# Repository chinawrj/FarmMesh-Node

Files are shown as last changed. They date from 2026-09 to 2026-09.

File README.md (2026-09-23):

# FarmMesh Node

**An integrated hardware and software solution for farm-wide Mesh networking**

English | [简体中文](README.zh-CN.md)

[Overview](#overview) · [Solution scope](#solution-scope-and-current-progress) · [A1 hardware](#a1-hardware-prototype) · [Features & targets](#key-features-and-performance-targets) · [Architecture](#architecture) · [Internal interface](#candidate-internal-interface) · [Wireless research](#wireless-research-status) · [Open decisions](#open-decisions) · [Roadmap](#roadmap) · [Contact](#contact-and-participation) · [References](#references)

## Overview

**FarmMesh Node is a hardware and software project for a complete farm wireless networking solution.** Its scope includes node electronics, embedded firmware, communication protocols, Mesh networking, client and sensor access, and system integration and field validation. Hardware and software are developed together toward the same farm-wide service goals; the A1 PCB is the current hardware milestone within that larger project.

FarmMesh Node aims to provide **farm-wide coverage using solar-powered infrastructure nodes that need no pre-installed power or network cabling**, combining on-demand high-speed client access with distributed access for hundreds to approximately 1,000 low-traffic sensors. Inter-node links are intended to be entirely wireless. Solar supply, storage and node power budgets remain to be designed; this is not a claim of all-weather energy autonomy, and a gateway/uplink may still be needed.

The client-access design target is **50 Mbps of effective throughput after connecting to a Mesh node**, available on demand wherever needed in the farm. The initial capacity assumption is **1–2 concurrent high-speed clients across the whole farm**, not per infrastructure node and not a limit on the number of Mesh nodes or total clients. This does not require every location to receive 50 Mbps simultaneously. Measurement endpoints, direction and test conditions remain TBD; there is no guarantee of 50 Mbps across multiple Mesh hops or to the Internet.

Infrastructure nodes are intended to provide **concurrent BLE or Wi-Fi access for several hundred to approximately 1,000 low-traffic, low-power sensors across the whole farm**, distributed among multiple Mesh nodes. This is an aggregate planning target requiring capacity validation, not 1,000 direct BLE connections per node or simultaneous packet transmission by every sensor. End-device energy requirements and the infrastructure's solar-power budget are separate concerns; neither implies that the forwarding infrastructure must sleep. Low Wi-Fi traffic alone does not establish low power consumption, and BLE/Wi-Fi coexistence requires validation.

Each infrastructure node contains **one RP2350B and three ESP32-C5 chips**, implemented in A1 with three official **ESP32-C5-WROOM-1U-N8R8 modules**. The RP2350B is intended to aggregate and forward data inside the node, with an independent internal link to each C5. The separate preliminary **50 Mbps per internal link** target is a hardware design input, not a demonstrated user throughput figure or proof that the access-service target can be met. Its directional and raw-rate/payload-rate definitions remain TBD.

Development is staged from the node hardware foundation through firmware and network software to full-system validation. The **A1 prototype has eight schematic sheets, a four-layer PCB and a manufacturing package released for controlled engineering prototypes**; its release record is [RELEASE.md](hardware/rev-a/RELEASE.md). Firmware and network software implementation remain pending. Coverage, user throughput, terminal capacity, power consumption and sustained internal-link performance have not been measured.

## Solution scope and current progress

| Area | Role in the complete solution | Current progress |
| --- | --- | --- |
| Node hardware | RP2350B and three ESP32-C5 modules, power, PCB, antennas and physical interfaces | A1 design and reviewed manufacturing package available; assembly and bring-up pending; deployment solar power remains to be designed |
| Embedded firmware | RP2350 PIO/DMA and C5 PARLIO drivers, framing, buffering, flow control and coordination across the three links | Hardware pin assignments frozen for A1; firmware and interface timing validation pending |
| Network software | Inter-node wireless transport, Mesh protocol and routing, Wi-Fi/BLE client and sensor access, configuration and diagnostics | Requirements and wireless research recorded; protocol selection and implementation pending |
| System integration | Hardware/firmware/network integration, power and RF coexistence, throughput, sensor capacity and farm deployment | Staged first-board test plan available; multi-node and field validation planned |

This repository currently contains the hardware release, system requirements and wireless research. Software will be developed as part of the same project; the table distinguishes the intended solution from what is already implemented.

## A1 hardware prototype

A1 contains a 100 × 100 mm four-layer PCB, protected single-cell nominal 3.7 V Li-ion input, 3.3 V buck-boost supply, RP2350B, three C5 modules, independent parallel interfaces, UART download headers and RP USB/SWD. USB data disconnects in hardware when VBUS is absent, including ROM BOOTSEL operation. USB does not power or charge the board. Solar charging and storage sizing remain separate design work.

| Artifact | Use and status |
| --- | --- |
| [Release status](hardware/rev-a/RELEASE.md) | Authoritative prototype fabrication gate and validation boundaries |
| [Manufacturing ZIP](hardware/rev-a/FarmMesh-Node-A1-manufacturing.zip) / [SHA-256](hardware/rev-a/FarmMesh-Node-A1-manufacturing.zip.sha256) | Released for controlled A1 prototypes: Gerber, drills, BOM, placements, drawings, editable source and review evidence |
| [KiCad project](hardware/rev-a/FarmMesh-Node.kicad_pro) / [PCB](hardware/rev-a/FarmMesh-Node.kicad_pcb) | Editable native sources; download the repository together with project-local libraries |
| [Eight-page schematic PDF](hardware/rev-a/review/FarmMesh-Node-A1.pdf) | A1 circuit review copy |
| [Manufacturing instructions](hardware/rev-a/FABRICATION.md) / [parts selection](hardware/rev-a/parts-selection.json) | Stackup, assembly requirements, 153 selected assembly parts and accessories |
| [First-board test plan](hardware/rev-a/FIRST-BOARD-TEST.md) | Staged power, debug, USB, thermal, load and RF checks; results are not yet measured |
| [Design notes](hardware/rev-a/DESIGN-NOTES.md) | Circuit and layout choices, sources and reproducibility |
| [Power review](hardware/rev-a/reports/a1-power-review.md) / [RF and digital review](hardware/rev-a/reports/a1-rf-digital-review.md) / [DFM and BOM review](hardware/rev-a/reports/a1-dfm-bom-review.md) | Independent engineering review records, with remaining bench-validation boundaries |

The C5 modules use external dual-band antennas. Their native USB pins are allocated to PARLIO; each C5 retains UART download and logging. **No wireless transport or Mesh protocol is selected by the hardware.** A fabrication-ready package does not establish RF, power or throughput performance.

## Key features and performance targets

**Targets below are planned requirements, not measured results.** TBD means to be determined. Chip resource facts and candidate allocations are identified separately.

| Item | Target or configuration | Status and boundaries |
| --- | --- | --- |
| Solar power and deployment | Solar-capable infrastructure nodes; no pre-installed power or network cables; wireless inter-node links | Design goal; solar sizing, storage and node power budget TBD; energy autonomy unverified; gateway/uplink architecture open |
| Farm-wide coverage | Wireless access throughout the farm | Product goal; area, terrain, range, node count and placement TBD |
| On-demand high-speed access | 50 Mbps effective client-access throughput after connecting to a Mesh node | Design goal; measurement endpoints, direction and conditions TBD; no multi-hop or Internet throughput guarantee |
| High-speed client concurrency | Initially 1–2 across the whole farm | Capacity assumption, unverified; not per Mesh node, a Mesh-node count limit or a total-client limit |
| Concurrent low-traffic access | Several hundred to approximately 1,000 sensors across the farm via BLE or Wi-Fi | Aggregate planning target, distributed across nodes; capacity has an upper bound and needs validation; not per-node BLE sessions or simultaneous packets from all sensors |
| Per-node BLE capacity | Bounded by C5 controller, host stack/configuration and radio scheduling | Connection-based versus advertising/scanning mode TBD; role and per-node limits unconfirmed; three C5 capacities cannot simply be added into a guarantee |
| End-device energy use | Support low-power terminal operation | Product goal; activity duty cycle, power budget and battery-life target TBD; solar infrastructure budget separately TBD |
| Node composition | 1 × RP2350B + 3 × ESP32-C5-WROOM-1U-N8R8 | Selected A1 architecture; physical validation pending |
| A1 hardware artifacts | Eight-sheet KiCad schematic, four-layer PCB and selected BOM; nominal 3.7 V single-cell Li-ion input | Fabrication gate in RELEASE.md; solar charging, firmware and physical validation remain separate |
| Independent internal links | Preliminary target: 50 Mbps per C5–RP2350 link, not shared across three links | Internal-interface target; direction, raw versus payload rate and required margin for the user-service target TBD; unverified |
| Internal interface | PARLIO ↔ PIO, separate 4-bit TX/RX buses; both clocks supplied by C5 | Candidate; 12 signals per link; A1 pin assignment drawn and reviewed; programs and timing unverified |
| RP2350B resources | 48 Bank0 GPIOs; 3 PIO blocks / 12 state machines; 32 shared instructions per block; 16 system DMA channels | Chip resource facts; preliminary interface allocation below is not implementation proof |
| Wireless roles and interconnection | Three C5 chips per node; Mesh protocol, radio roles/channels and gateway/uplink TBD | Architecture decisions pending; no guaranteed BLE/Wi-Fi coexistence performance or Internet throughput |

## Architecture

### Network concept

The diagram separates end-device access from the Mesh infrastructure. Dotted lines show intended service relationships and node membership, not physical radio links or packet paths. The service box is a logical grouping, not a central device. Inter-node topology, radio roles and Mesh protocol remain open; the measurement endpoint and gateway/uplink boundary are also TBD.

```mermaid
flowchart TB
    fast["High-speed clients / 高速客户端<br/>50 Mbps access target / 接入目标<br/>1–2 concurrent farm-wide / 全网并发目标"]
    low["Low-traffic sensors / 低流量传感器<br/>Hundreds to approx. 1,000 farm-wide / 全网数百至约千个<br/>Concurrent access goal / 并发接入目标"]
    mesh["FarmMesh infrastructure services / 基础设施服务层<br/>Logical grouping / 逻辑分组"]
    fast -.- mesh
    low -.-|"BLE or Wi-Fi / 计划接入"| mesh
    subgraph infra["Solar-capable Mesh nodes / 太阳能 Mesh 节点目标"]
        a["FarmMesh Node A"]
        b["FarmMesh Node B"]
        c["FarmMesh Node C"]
    end
    mesh -.- a
    mesh -.- b
    mesh -.- c
    deployment["No pre-installed power or network cables / 免预布电源线或网线<br/>Wireless inter-node links / 节点间纯无线目标"]
    deployment -.- mesh
    boundary["Measurement endpoint and gateway/uplink / 测速端点与网关或上联<br/>TBD / 待定"]
    mesh -.- boundary
```

### Inside one node

Each line represents an independent internal data link. Clock and VALID directions are defined separately in the interface table below; the arrows here do not specify clock sources.

```mermaid
flowchart LR
    subgraph node["One FarmMesh Node / 单个节点"]
        rp["RP2350B · PIO + system DMA<br/>Data aggregation and forwarding / 数据汇聚与转发"]
        ca["ESP32-C5 A · PARLIO"]
        cb["ESP32-C5 B · PARLIO"]
        cc["ESP32-C5 C · PARLIO"]
        rp <-->|"Link A / 链路 A"| ca
        rp <-->|"Link B / 链路 B"| cb
        rp <-->|"Link C / 链路 C"| cc
    end
```

The three ESP32-C5 chips' wireless roles, channels and connections to other nodes are not assigned by this diagram.

### Wireless coexistence boundary

Espressif documents shared RF resources with time-division and priority arbitration. Its current C5 coexistence table marks Wi-Fi SoftAP Connecting/Connected combined with BLE Scan/Advertising/Connected as C1 (supported, with unstable performance). This is a constraint to validate if a C5 is assigned both Wi-Fi AP and BLE roles; it does not establish that the three-chip node cannot meet its goals. Radio-role allocation and coexistence must be checked against the selected SDK and operating scenarios. Concurrent terminal service does not imply independent, simultaneous full-load radios on a single C5. See the [official RF coexistence guide](https://docs.espressif.com/projects/esp-idf/en/stable/esp32c5/api-guides/coexist.html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).

Per-node BLE capacity has an implementation-dependent limit, not one universal fixed connection count imposed by the BLE specification. The C5 controller and NimBLE host expose separate connection-limit settings in the [official configuration reference](https://docs.espressif.com/projects/esp-idf/en/stable/esp32c5/api-reference/kconfig-reference.html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). Connection-based access and connectionless advertising/scanning are different [BLE roles and topologies](https://docs.espressif.com/projects/esp-idf/en/stable/esp32c5/api-guides/ble/get-started/ble-introduction.html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); scanning advertisements must not be counted as persistent connections. Advertising/scanning terminal capacity needs its own validation. Select the access mode and three C5 roles before confirming per-node capacity; simply adding three chip-level limits does not establish node capacity.

## Candidate internal interface

The selected hardware interface is **ESP32-C5 PARLIO ↔ RP2350 PIO**, using separate 4-bit TX and RX data buses. A1 freezes the physical connections; firmware and timing for concurrent bidirectional operation remain unvalidated.

**Each C5 supplies both clocks. The RP2350 PIO follows an external clock in both directions**, including when the RP2350 sends data to the C5.

| Transfer direction | DATA | Clock | VALID |
| --- | --- | --- | --- |
| C5 → RP2350 | 4 signals, C5 → RP | C5 TX CLK → RP | C5 TX VALID → RP |
| RP2350 → C5 | 4 signals, RP → C5 | C5 RX CLK → RP | RP VALID → C5 |

This uses **12 signals per link**: 8 DATA, 2 CLK and 2 VALID. Three links use **36 signals**, plus a common ground reference. A1 freezes the prototype pin assignment in the schematics and [C5 pinmap](hardware/rev-a/c5-pinmap.json); firmware and hardware timing validation remain open.

PARLIO has separate TX and RX units. A shared-data, half-duplex alternative would require explicit output-enable, tri-state and direction-change handling. PARLIO must not be treated as an automatically reversing shared bus, and disabling TX does not by itself establish a high-impedance output.

### Preliminary resource budget

| RP2350B resource | Available | Initial three-link estimate |
| --- | --- | --- |
| Bank0 GPIO, QFN80 package | 48 | 36 interface signals; 12 remain before other allocations |
| PIO state machines | 12 across 3 PIO blocks | 6: one RX and one TX per link |
| System DMA channels | 16 | 6: one per direction per link |
| PIO instruction memory | 32 shared instructions per PIO block | Program size not yet established |

These estimates do not constitute an implemented PIO program or validated timing design. A1 assigns the three interfaces to RP2350B GPIO0–35. Each PIO has a 32-GPIO window selected by GPIOBASE 0 or 16; the PIO configuration and instruction use still need implementation checks. Dedicated QSPI storage pins, USB and SWD do not consume the 48 Bank0 GPIOs. Other board functions use part of the remaining GPIO budget. The 30-GPIO RP2350A cannot accommodate this 36-signal candidate.

### Processing responsibilities and timing boundary

- **CPU:** initialization, buffer preparation, transaction coordination and exception handling.
- **PIO:** beat-level sampling and output timing under the C5-provided clocks.
- **System DMA:** block transfers between PIO FIFOs and RP2350 SRAM, intended to avoid CPU byte-by-byte copying.

The C5 PARLIO RX documentation describes receive-clock output and VALID-based reception gating. C5 RX/GDMA transactions must be prepared before data arrives; VALID alone does not create a receive transaction. The RP must prepare the first beat and drive VALID correctly. Start/end behavior, sampling edges and gating timing still require a concrete design and validation.

Frame boundaries, DMA rearming and sustained operation also remain to be designed. A ring-address setting alone is not a guarantee of indefinite operation, and this draft does not claim CPU-free transfer management.

## Wireless research status

The [wireless link research notes](docs/wireless-link-research.md) record the **2026-09-22** review, official sources, version-specific binary observations and MTU/MSS constraints. **No wireless transport has been selected.** The client-access targets and internal hardware candidate above remain unchanged.

| Topic | Current finding | Status and boundary |
| --- | --- | --- |
| WDS / four-address bridge | Direct public C5 support not confirmed in the reviewed documentation/API | Does not establish a hardware impossibility |
| ESP-NOW and public raw TX | Different frame/payload limits; neither establishes this project's 50 Mbps effective throughput | Research candidates; no sustained-throughput validation |
| Rate and power controls | Public per-peer ESP-NOW rate configuration and per-C5 Wi-Fi maximum-power ceiling | Documented controls; no confirmed ready-to-enable ESP-NOW automatic-rate tool; custom adaptation remains future work |
| AP+STA + proxy ARP | Currently not pursued | Project direction, not a technical impossibility finding |

## Open decisions

1. Define the client-to-Mesh-node 50 Mbps access test: measurement endpoints, uplink/downlink direction and conditions. Start with 1–2 concurrent high-speed clients farm-wide; multi-hop and Internet throughput remain outside any established guarantee.
2. Define each internal link's 50 Mbps target separately: one direction, both directions combined, or each direction; raw rate versus effective payload rate; and the capacity margin needed to support the user-service goal.
3. Establish three-link PIO feasibility, clock/timing constraints, GPIO mapping, instruction budget and required CPU participation. Define first-beat readiness, VALID behavior, receive-transaction preparation, frame boundaries and DMA rearming.
4. Validate the farm-wide planning target of several hundred to approximately 1,000 low-traffic sensors. Select connection-based BLE versus advertising/scanning roles, establish per-node limits and define activity duty cycles, traffic, latency and end-device energy targets. Radio roles/channels and BLE/Wi-Fi coexistence remain to be validated.
5. Design the solar supply, storage and infrastructure power budget for deployment without pre-installed power or network cabling. Later, decide Mesh protocol and routing, antennas, coverage area/terrain and deployment, gateway/uplink, environmental protection and the full BOM.

These decisions guide the complete hardware and software solution. The current repository establishes the A1 hardware foundation and records the software design inputs; firmware, network protocols, routing and system optimization are the next development stages.

## Roadmap

| Phase | Scope | Status |
| --- | --- | --- |
| 1 | System requirements and hardware/software architecture | Service targets and A1 hardware allocation recorded; software architecture and protocols remain open |
| 2 | A1 schematics, PCB and manufacturing package | Released for controlled engineering prototypes; see RELEASE.md |
| 3 | Board bring-up, drivers and internal-link firmware | Awaiting assembled boards; firmware and timing validation pending |
| 4 | Network software, Mesh routing and client/sensor services | Planned; integrate with validated node hardware and firmware |
| 5 | Multi-node integration and farm deployment | Planned; validate coverage, throughput, sensor capacity, power and reliability |

## Contact and participation

Interested in FarmMesh Node? Use [GitHub Issues](https://github.com/chinawrj/FarmMesh-Node/issues) to discuss requirements, hardware, firmware, network software, system testing or ways to participate. You can also visit the project owner's [GitHub profile](https://github.com/chinawrj).

## References

Official sources for subsequent design checks:

- [RP2350 datasheet](https://datasheets.raspberrypi.com/rp2350/rp2350-datasheet.pdf) — GPIO, PIO and system DMA resources.
- [ESP32-C5 datasheet](https://documentation.espressif.com/esp32-c5_datasheet_en.html) and [technical reference manual](https://documentation.espressif.com/esp32-c5_technical_reference_manual_en.pdf) — device and peripheral details.
- [ESP32-C5 PARLIO RX driver](https://docs.espressif.com/projects/esp-idf/en/stable/esp32c5/api-reference/peripherals/parlio/parlio_rx.html) — receive clock, VALID and transaction setup.
- [ESP32-C5 PARLIO TX driver](https://docs.espressif.com/projects/esp-idf/en/stable/esp32c5/api-reference/peripherals/parlio/parlio_tx.html) — transmit configuration and operation.
- [ESP32-C5 RF coexistence](https://docs.espressif.com/projects/esp-idf/en/stable/esp32c5/api-guides/coexist.html) — supported role combinations and shared RF scheduling constraints.

Differences in maximum full-duplex width descriptions across C5 documentation still need reconciliation. This draft considers only the 4-bit-per-direction candidate and makes no claim about wider full-duplex configurations. The ESP-IDF `stable` links can change; record the selected SDK and document versions when the implementation baseline is set.

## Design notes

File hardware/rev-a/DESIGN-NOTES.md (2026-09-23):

# FarmMesh Node A1 硬件设计说明

日期：2026-09-23。A1 投样放行状态以 [RELEASE.md](RELEASE.md) 为准；尚无实物或性能验证。

The A1 eight-sheet KiCad 10 design and 100 × 100 mm four-layer PCB contain one RP2350B, three official ESP32-C5-WROOM-1U-N8R8 modules, a protected 1S Li-ion input and a 3.3 V buck-boost supply. ERC and static connectivity/pad checks do not establish power, RF or interface performance. The prototype release status is recorded in RELEASE.md. Charging/solar power and application firmware remain future work.

## 打开与文件

使用 KiCad **10.0.5 或兼容的 KiCad 10** 打开 [FarmMesh-Node.kicad_pro](FarmMesh-Node.kicad_pro)，再进入原理图编辑器。需安装 KiCad 标准符号及封装库；项目表使用 `KICAD10_SYMBOL_DIR` / `KICAD10_FOOTPRINT_DIR`，项目自建库通过 `${KIPRJMOD}` 引用。无需插件即可编辑。

| 文件 | 用途 |
| --- | --- |
| [八页 PDF](review/FarmMesh-Node-A1.pdf) | 索引、电源、RP2350B、三页 C5、USB、测试及机械 |
| [BOM.csv](BOM.csv) | 153 个已定料装配元件与 11 个 PCB 特征；下单用 manufacturing/assembly/BOM-assembly.csv |
| [gpio-pinmap.csv](gpio-pinmap.csv) | 全部 36 条链路信号，C5 GPIO/模组焊盘与 RP GPIO/封装焊盘 |
| [ERC](reports/erc.json) | KiCad 原始检查结果 |
| [网表及焊盘核对](reports/connectivity-and-footprints.json) | 实际导出网表与已加载封装的结构检查 |
| [电源审阅](reports/power-review.md)、[RP 审阅](reports/rp2350-review.md)、[C5 审阅](reports/c5-review.md) | 独立检查、官方依据及待验证边界 |

索引页的子图框使用全局网络标签连接，框本身没有层次端口。`TX` / `RX` 始终从 C5 视角命名。五个 PWR_FLAG 只是 ERC 驱动声明，不是物料；164 个板上对象之外另有这五个标记。

## 硬件决策

### 电池与 3.3 V 电源

- J1 接常规 **1S、标称 3.7 V、满充 4.20 V** 的锂离子电池包，pin1 正极、pin2 负极。必须使用带过充/过放/过流保护的电池包，连接器、导线与保护板需支持至少 5 A 峰值。不能接 2S、LiFePO4 或高压锂电池。
- F1 为 5 A Littelfuse 0451005.MRL；Q1 DMP2008UFG-7 实现反接保护，D 面向电池、S 面向负载。KiCad PowerDI3333-8 把物理 D 脚 5–8 及底部铜区合并为 pad5，符号因此也只用 D pad5。保险丝和本板 UVLO 不代替电芯保护。
- LTC3119IFE#PBF 使用官方 TA06 3.3 V / 500 kHz 电路为起点。4.7 µH XAL7070-472MEC，反馈 316 kΩ / 100 kΩ，输出标称 3.307 V。78.7 kΩ + 820 pF 补偿是起始值，附加模组电容后的环路稳定性尚未测量。
- MPPC 接 VCC 关闭该功能，本稿不是 MPPT；PWM/SYNC 接地允许 Burst。VCC 是内部辅助电源，不得直接短接到 3V3；D1 阳极 3V3、阴极 VCC。PGOOD 仅给 RP 检测，不直接拉三颗 C5 的 EN。
- RUN 174 kΩ / 100 kΩ：标称启动约 3.30 V、停止约 3.01 V，受器差和负载压降影响。电压低于启动点的电池可能不能冷启动。J2 短接将 RUN 拉低用于关机；仅触发 UVLO 不能等同于数据表的完整关断电流。
- C7 6SVPE220M 为 Panasonic C6 外形，使用 `CP_Elec_6.3x5.9`。C6 输入选 10SVPC120M（120 µF / 10 V）；各 C5 选 6SVPC100M（100 µF / 6.3 V），封装分别为 6.3 × 5.9 mm 和 5 × 5.9 mm。输出共有 520 µF 聚合物电容，分布电容对启动和环路的影响仍须实测。22 µF MLCC 的官方 25°C 直流偏压典型数据和重放记录见 parts-selection.json，不将典型值当全温最小保证。

| 预算项目 | 当前设计输入 |
| --- | --- |
| 三颗 C5 | 每颗供电能力至少 0.6 A，共 1.8 A；不是宣称连续耗电 0.6 A |
| RP、Flash、外围和余量 | 0.4 A 暂定预算 |
| 3V3 总预算 | 2.2 A；3 A 作为瞬态验证目标，不能当成全输入/温度范围连续额定值 |
| 电池端估计 | 在输入 3.0 V、假设效率 80% 时，2.2 A 输出约需 3.03 A；3 A 输出约需 4.13 A |

效率 80% 是预算假设，尚未测得；此计算未保证低温电池、保险丝、线缆及 Q1 压降后的性能。LTC3119 的开关/电感电流限制不是输出电流保证。电源和电池容量不能据此直接换算太阳能板尺寸或续航。

本版**没有充电器、太阳能输入、电池电量监测或 USB 供电路径**。电池 ADC 原方案已移除，避免 3V3 关闭时仍将电池分压施加到非 FT 的 ADC 脚；后续需要带关断隔离的采样电路。

### RP2350B 最小系统

RP2350B 的 QFN80 + EP81、外置 16 MB W25Q128JVSIQ、12 MHz ABM8-272-T3、USB、SWD、BOOTSEL 与 RESET 均已连接。IOVDD / USB_OTP_VDD / QSPI_IOVDD 等接 3.3 V，DVDD 接核心 1.1 V。

核心使用 **RP 内部 buck**，不是 LDO：VREG_LX 经 3.3 µH 到 CORE_1V1，再接 VREG_FB / DVDD。L101 使用官方 R4-S1 的带方向 Abracon 封装，**pad2=LX，pad1=1V1**；换电感时不能只比较电感量。VREG_AVDD 经 33 Ω、4.7 µF 滤波；核心输出及远端 pad32 各有 4.7 µF，并给各电源脚单独 100 nF。

GPIO0–35 分配三组接口，GPIO36 为 PGOOD，GPIO37（FT pad46）检测 USB VBUS，GPIO38–47 保留。A3/A4 硅片优先；为兼顾 A2 E9 漏电问题，VALID 接收端下拉用 4.7 kΩ，USB 检测下臂用 7.5 kΩ，均小于官方 8.2 kΩ 规避阈值。仍需在选定硅片上实测。

### 三个 ESP32-C5 模组

U201/U301/U401 均选官方 **ESP32-C5-WROOM-1U-N8R8**：8 MB Flash、8 MB PSRAM、外置天线接口。每颗需独立的 2.4/5 GHz 天线及适配 ANT1 的线缆，已选配套 MPN 见 parts-selection.json 的 accessories；默认不用模组 ANT2 pad31。此 1U 型号没有 PCB 天线，不应机械套用 PCB 天线版的 15 mm 天线区规则；仍须规划连接器空间、天线摆放及三射频之间隔离。

每模组 22 µF + 100 nF 近 pad2，100 µF 聚合物电容提供本地储能。EN 采用 10 kΩ / 1 µF，GPIO27 和 GPIO28 各 10 kΩ 上拉；BOOT 将 GPIO28 拉低，RESET 拉低 EN。按住 BOOT、脉冲 RESET 进入 UART 下载。

J201/J301/J401：1 GND，2 C5 TX，3 C5 RX，4 EN，5 BOOT，6 3V3 参考。使用 3.3 V 逻辑的 UART 适配器；pin6 是参考输出，不是另一电源入口。RP SWD J101：1 3V3 参考，2 SWDIO，3 GND，4 SWCLK，5 RUN。

### 候选 PARLIO ↔ PIO

| C5 侧信号 | C5 GPIO（模组 pad） | RP A / B / C GPIO | 驱动端 |
| --- | --- | --- | --- |
| TX_D0..3 | 0(6), 1(7), 13(13), 14(14) | 0–3 / 12–15 / 24–27 | C5 |
| TX_CLK | 4(17) | 4 / 16 / 28 | C5 |
| TX_VALID | 5(16) | 5 / 17 / 29 | C5 |
| RX_D0..3 | 6(8), 8(10), 9(11), 10(12) | 6–9 / 18–21 / 30–33 | RP |
| RX_CLK | 23(21) | 10 / 22 / 34 | **C5** |
| RX_VALID | 24(23) | 11 / 23 / 35 | RP |

所有接口避开启动绑带脚和内部 Flash/PSRAM 脚；C5 GPIO13/14 的 USB 功能被让给数据线，因此三颗 C5 通过 UART 下载。GPIO13/14 启动时可能出现 USB 状态变化，RP 必须保持输入，直到 C5 配置完成且 VALID 生效。

每条信号有初始 22 Ω 串联电阻，布板时放在**驱动端**，不能因它画在 C5 页就一律放在 C5 旁。TX_VALID 的 4.7 kΩ 下拉在 RP 端，RX_VALID 的下拉在 C5 端；任一芯片复位后均需重建收发状态、清理 FIFO / 事务。

PIO0 GPIOBASE=0 负责 A；PIO1 GPIOBASE=0 负责 B；PIO2 GPIOBASE=16 负责 C。C 路 GPIO28/34 在相应窗口中的 WAIT GPIO 索引为 12/18，不能把 34 直接塞入 5 位立即数。每路双向各一个状态机、DMA 共约六路仅是资源估算。PARLIO RX 要预先挂好接收事务，RX clock 输出不代表接收已准备好。实际 PIO 程序、指令预算、采样边沿、首拍时序、DMA 重装、持续全双工以及 50 Mbps 均未验证。

### USB 边界

J102 USB4105-GF-A 只用于 RP 数据；VBUS 不给板供电，也不充电，使用时仍需电池。CC1/CC2 各 5.1 kΩ，D± 经 USBLC6-2SC6、TS3USB30EDGSR 数据开关及靠 RP 的 27 Ω 串联电阻。USBLC6 的 I/O 是 1↔6 与 3↔4 直通对，VBUS 有 100 nF。

VBUS 通过 5.1 kΩ / 7.5 kΩ 接 GPIO37。按 1% 电阻及 4.4–5.5 V VBUS，检测电压约 2.598–3.300 V，低于 FT 脚 IOVDD=0 时的 3.63 V 上限；程序检测前应关闭 GPIO37 内部上下拉。A1 增加 TLV3011BIDBVR（必须 B 版本）与 237 kΩ / 100 kΩ 比较网络，在 VBUS 低于标称约 4.19 V 时将开关 /OE 拉高；10 kΩ 默认上拉使 USB 物理断开，不依赖应用程序或 ROM 读取 GPIO37。容差、失电、欠压及电源先后顺序仍须按首板指南测量；Ioff 规格不代表任意欠压条件。

## 布局与校验

A1 使用 100 × 100 mm、四层 1.6 mm 板；F.Cu / In1.GND / In2.GND / B.Cu。JLC04161H-3313 叠层、USB 90 Ω 主干几何和制造公差见 [FABRICATION.md](FABRICATION.md)。两内层保留为参考地，RP buck 的 LX 下方仅在相邻 In1.Cu 局部避空。三路 C5 电源主干为 1.5 mm，RP 支路为 1.0 mm；局部电源回路、QSPI、晶振和 USB 先行布线，再完成普通信号。

153 个装配元件均有明确 MPN，7 个裸铜测试点及 4 个安装孔为 PCB 特征。三颗 C5、RP 和 LTC 的接地过孔均置于实际 EP 锡膏窗口之外，采用普通 tenting；这不等同于树脂填孔或保证封孔。M3 螺钉头部区域禁布外层铜。

最终 ERC、DRC、未连接、原理图一致性以及逐焊盘几何校验以 reports 中绑定最终文件 SHA 的报告为准。三份 A1 独立审阅分别覆盖电源、RF/数字接口和定料/制造；原 A0 审阅记录仅保留为历史。

[首板验收指南](FIRST-BOARD-TEST.md) 给出分阶段限流上电、3V3/1V1、UVLO、UART/SWD/USB、环路/负载/温升及射频测试。2.2 A 总输出和 3 A 脉冲是验证目标，50 Mbps 板内链路、用户吞吐与无线共存尚未测得。投样文件通过静态检查不能代替这些实测。

## 重生成与来源

原理图可直接在 KiCad 编辑。`scripts/build_design.py` 是本稿生成源，**重新运行会覆盖全部原理图与项目自建符号库**；先保存手工改图，或将变更回写生成器。依赖 Python 3 和 `sexpdata`，通过环境变量 `KICAD_SHARE` 指向 KiCad `SharedSupport`；未设置时脚本使用本次 macOS 安装位置。验证器需要 KiCad 自带 `pcbnew` Python。

```sh
python3 scripts/build_design.py
for sheet in *.kicad_sch; do kicad-cli sch upgrade "$sheet"; done
kicad-cli sch export netlist --format kicadxml -o reports/netlist.xml FarmMesh-Node.kicad_sch
kicad-cli sch erc --format json --severity-all -o reports/erc.json FarmMesh-Node.kicad_sch
kicad-cli sch export pdf -o review/FarmMesh-Node-A1.pdf FarmMesh-Node.kicad_sch
# 用能 import pcbnew 的 Python 运行：
python3 scripts/verify_design.py
```

关键引用见三份审阅记录：[Espressif C5 模组 v1.3](https://www.espressif.com/sites/default/files/documentation/esp32-c5-wroom-1_wroom-1u_datasheet_en.pdf)、[RP2350 datasheet](https://datasheets.raspberrypi.com/rp2350/rp2350-datasheet.pdf)、[RP 硬件设计指南](https://pip-assets.raspberrypi.com/categories/1214-rp2350/documents/RP-008280-DS-2-hardware-design-with-rp2350.pdf)、[LTC3119 Rev B](https://www.analog.com/media/en/technical-documentation/data-sheets/3119fb.pdf)。链接内容可能更新，选型重新冻结时需复核版本。

L101 footprint 的几何和方向标记提取自 Raspberry Pi 官方 RP2350B Minimal R4-S1，去掉了原工程专属元数据和不可独立解析的内嵌 3D 引用；保留其 [MIT 许可](third-party/raspberry-pi-reference-LICENSE.txt)。[参考设计下载](https://pip-assets.raspberrypi.com/categories/1214-rp2350/documents/RP-010329-CA-1-RP2350B%20Minimal%20KiCAD.zip)。其余标准符号/封装依赖 KiCad 库，自建 C5 焊盘按官方尺寸绘制。本文件不为整个项目额外指定许可证。

`build_pcb.py` 只重建放置与关键走线底稿，**不会重现最终普通信号布线，不能覆盖发布板后直接下单**。最终原生 PCB 是完整布线的权威源；`verify_pcb.py` 为只读核查。`export_manufacturing.py` 与封包脚本在冻结源上生成并核验制造输出。

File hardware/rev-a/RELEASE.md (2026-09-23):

# FarmMesh Node A1 prototype release

**Status: GO FOR CONTROLLED A1 PROTOTYPE FABRICATION / 可受控工程原型投样。**

Release date: **2026-09-23**. KiCad **10.0.5**. The 100 × 100 mm, four-layer A1 board is fully routed and filled. This engineering release is bound to the following native PCB SHA-256:

```text
94b96a96ef75f9561a9c2552ea9e2db2f6d1eb0fe6a99cec8e6313b0ac1b4ab9
```

布线、铺铜、静态电气/制造检查、三项独立 AI 辅助工程会审及最终图纸目视核验已完成，未留有未处置的静态投样阻断。此状态只适用于所列哈希及一致的制造包；任何源文件、BOM 或几何修改都须重新核验和导出。

## Completed release gates / 已完成门槛

| Gate | Final evidence |
| --- | --- |
| Electrical rules | ERC **0** violations; `reports/erc.json` (package: `audit/erc.json`) |
| PCB rules and connectivity | DRC **0** violations, **0** unconnected items, **0** schematic-parity findings; `reports/drc.json` (package: `audit/drc.json`) |
| Independent geometry/connectivity checks | All **11** checks pass against the frozen PCB/netlist/library hashes; `reports/pcb-verification.json` (package: `audit/pcb-verification.json`) |
| Selected parts | **153** fitted components, including **147 SMD + 6 through-hole**; **11** bare-board test/mounting features excluded from assembly |
| Manufacturing outputs | **11 Gerber layers**, separate Excellon files containing **427 PTH holes/slots + 6 NPTH holes**, assembly BOM, accessory BOM, all/SMD placements and five review PDFs |
| Power review | [PASS on final native and actual Gerber/drill output](reports/a1-power-review.md) |
| RF/digital review | [GO for controlled engineering prototypes, with documented routing dispositions](reports/a1-rf-digital-review.md) |
| BOM/DFM review | [PASS on final native, actual fabrication data and source-hash closure](reports/a1-dfm-bom-review.md) |
| Visual review | Eight schematic pages, eleven layer pages, assembly drawing, two drill maps and actual Gerber/drill renderings inspected; `reports/a1-visual-review.md` (package: `review/evidence/reports/a1-visual-review.md`) |

The sealed archive is `FarmMesh-Node-A1-manufacturing.zip`, with external checksum `FarmMesh-Node-A1-manufacturing.zip.sha256`. Inside it, `manifest.json` records frozen-source and payload hashes; `SHA256SUMS` also hashes that manifest. `scripts/finalize_release.py --check-only` verifies the complete file set, individual bytes, ZIP CRC and external ZIP SHA-256. The archive hash is kept outside this document to avoid a circular hash dependency.

## Accepted prototype dispositions / 已接受的原型处置

- A_RX_D0 and A_RX_VALID have source-to-resistor detours; C_RX_D1 exceeds the review's placement attention threshold. Nine signal transitions have a nearest GND return farther than the 2 mm review heuristic. These are accepted for controlled bring-up with the specific waveform, clock-ramp and concurrent QSPI/radio tests in [FIRST-BOARD-TEST.md](FIRST-BOARD-TEST.md). They do not establish 50 Mbps timing.
- The ordinary double-sided via tenting process has three small positive hole-to-mask/paste margins of approximately 0.025, 0.028 and 0.040 mm. They have no nominal overlap but require targeted CAM and first-piece inspection. This release does not require or promise VIPPO, ink plugging or completely sealed holes. See [FABRICATION.md](FABRICATION.md) and the DFM review.
- Fabrication must preserve the specified JLC04161H-3313 construction, 1.6 mm thickness, ENIG, separate PTH/NPTH and USB 90 Ω differential ±10% requirement. Factory confirmation of actual stack-up, impedance, stencil and ordinary tenting is part of manufacturing execution. Unreviewed automatic CAM geometry changes are not covered by this release.

## Prototype boundary / 原型边界

Prototype-ready manufacturing means the design package is internally consistent and reviewed for first-board fabrication. It does not mean a physical board has been built or measured. Converter stability, thermal headroom, voltage droop, USB enumeration, PARLIO/PIO timing, RF isolation and sustained throughput require first-board testing. There is no on-board charger, PV input, USB power mode or battery ADC. No purchasing or manufacturing order is performed by this task.

可投样仅表示文件与设计审核完成；它不等于实物已验证。电源稳定性、温升、动态压降、USB、并行接口时序、射频隔离和持续吞吐量仍以首板实测为准。不包含充电、光伏输入、USB供电或电池ADC；本任务不采购、不下单。

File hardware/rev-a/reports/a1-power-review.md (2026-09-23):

# A1 independent power review

Date: 2026-09-23. **Final static prototype power review: PASS.** This review is bound to the actual frozen `hardware/rev-a/FarmMesh-Node.kicad_pcb`, SHA-256 **`94b96a96ef75f9561a9c2552ea9e2db2f6d1eb0fe6a99cec8e6313b0ac1b4ab9`**. Its bytes were checked before and after the read-only review. No identified power-related issue remains open that blocks prototype fabrication. This conclusion supersedes the earlier placement-only and temporary-board snapshots; it does not establish measured electrical stability, thermal performance or a production operating envelope. No simulation or hardware measurements have been performed.

## Final disposition and hardware validation

1. **USB hardware isolation is present and its static connectivity is closed; sample testing remains open.** In A0, battery-powered RP2350 can present its USB pull-up while D101's upper steering diode connects that data line to dead USB_VBUS. GPIO37 sensing only helps application firmware; it does not control ROM BOOTSEL. A rail-independent ESD replacement removes the D101 rail path but does not disconnect the RP PHY from an unpowered host. A1's U103/U104 pad-to-net assignments match the VBUS-qualified isolation circuit below, with ESD on the connector side. The actual 3V3/GND chains are connected, and the frozen board has zero unconnected items and zero schematic-parity issues. Physical USB power-sequence tests remain first-board work. See [ST USBLC6-2 circuit, p. 1](https://www.st.com/resource/en/datasheet/usblc6-2.pdf).
2. **Power capacitor MPN/footprint selections are now present; operating-envelope validation remains open.** A1 uses the exact Murata 22 µF MPN, 10SVPC120M input bulk, 6SVPC100M radio reservoirs and 6SVPE220M output bulk. Manufacturer bias data were retrieved for the 22 µF part, as detailed in the later integrated review. Do not equate its label with its capacitance in circuit or treat the retrieved typical curve as a guaranteed minimum.
3. **Final power copper and paste corrections are closed at the SHA above.** The converter loops, peripheral exposed-pad cooling, continuous inner GND, wide supply branches and both corrected via positions were rechecked on the frozen board. All four supply paths match the recorded geometry; the full-board actual pad-shape/drill test finds no paste/drill intersection. An ERC/DRC pass cannot establish current capacity, stability or junction temperature.

No wrong power pin, reversed PMOS, reversed bootstrap connection, feedback polarity error or charger connection remains identified in the reviewed A1 power implementation.

## USB correction implemented in the A1 generator

The USB block in `build_design.py` was edited under the implementation owner's explicit delegation. Its regenerated U103/U104 PCB pad numbers and named nets were subsequently checked on the routed candidate and agree with the connections below. This closes the earlier generator-only uncertainty; it does not replace final package verification or USB measurements.

U103 is **TS3USB30EDGSR**, DGS/VSSOP-10, powered from board 3V3, with C128 100 nF bypass. The selected stock `Package_SO:TSSOP-10_3x3mm_P0.5mm` has the required 3 × 3 mm body, 0.5 mm pitch and no exposed pad; its 1.45 × 0.30 mm pads at ±2.15 mm are compatible with the DGS lead envelope. The DGS pin mapping is:

| Pin | A1 connection |
| --- | --- |
| 1 S | GND; select port 1 |
| 2 D1+ / 8 D1− | RP side, through the existing 27 Ω resistors near RP2350 |
| 3 D2+ / 7 D2− | NC |
| 4 D+ / 6 D− | Connector-side ESD paths |
| 5 GND / 10 VCC | GND / 3V3 |
| 9 OE, active low | 10 kΩ pull-up to 3V3; comparator output below |

OE high disconnects both lines; S low and OE low select D1. The data sheet specifies power-off leakage with VCC = 0. Its recommended operating table requires VCC ≥ 3.0 V, despite the front-page 2.7 V wording; use the stricter table. Source: [TI TS3USB30E, Rev. G, pp. 3–5 and table 7-1](https://www.ti.com/lit/ds/symlink/ts3usb30e.pdf).

U104 is **TLV3011BIDBVR**, `Package_TO_SOT_SMD:SOT-23-6`, as a VBUS comparator: pin 6 to 3V3 with C129 100 nF bypass; pin 2 to GND; pin 5 REF to pin 3 IN+ with C130 1 nF REF-to-GND; pin 4 IN− to R114/R115, a 237 kΩ / 100 kΩ VBUS divider, both 0.1%; pin 1 open-drain OUT to switch OE, with R116 10 kΩ pull-up. The GPIO37 divider remains independent. VBUS above approximately `1.242 × (1 + 237/100) = 4.186 V` pulls OE low; absent VBUS leaves OE pulled high. The **B** suffix is required for fail-safe inputs and the high-impedance power-on-reset state. The non-B device is not an approved substitution. Source: [TI TLV3011B, pin table, section 6.9 and sections 9.4.4–9.4.5](https://www.ti.com/lit/ds/symlink/tlv3011.pdf).

A conservative engineering estimate combining reference spread, temperature drift, offset, full hysteresis and resistor tolerance gives roughly 4.02–4.36 V trip limits; this is not a characterized board limit. Avoid a large divider capacitor that delays disconnect. Check slow VBUS ramps, cable removal, battery removal, rail brownout, normal enumeration and ROM BOOTSEL. The switch adds series resistance/capacitance, so retain waveform/USB functional validation. This circuit does not establish USB compliance by itself.

## Converter implementation requirements

The [LTC3119 data sheet](https://www.analog.com/media/en/technical-documentation/data-sheets/3119fb.pdf) provides the FE layout in Figure 11, pp. 25–26, the TA06 starting circuit on p. 28, and compensation guidance on pp. 22–25. It requires short/wide high-current paths, close bypass capacitors, an uninterrupted ground plane, exposed-pad vias, and Kelvin small-signal returns. TA06 is a reference circuit, not a guarantee for the FarmMesh board.

The following are engineering placement/route requirements for this design:

- Place C3/C4 directly beside PVIN pins 22/23 and PGND20; place C8/C9 beside PVOUT6/7 and PGND9. Give each local capacitor a direct short ground connection. C6/C7 bulk capacitors must not displace these local ceramics. Route the battery and load trunks from the capacitor regions, avoiding a shared narrow neck in the bypass loops.
- Place L1 adjacent to SW1 pins 21/24 and SW2 pins 5/8. Keep SW copper compact but wide; do not route FB, RT, RUN, crystal, USB or radio signals beneath/through those switching-node regions. C1 joins BST1/26 to SW1 and C2 joins BST2/3 to SW2 with very short loops.
- Place C11 at VCC16 and keep D1 nearby. Group R2/R3 at FB12, R4/C10 at VC13 and R5 at RT17. Route their quiet ground back to SGND14/exposed-pad ground without sharing the input/output capacitor current path. Sense 3V3 separately from the local output-capacitor positive copper: A1 uses C9 at the C7 output-distribution region. A common GND net name alone does not create this geometry.
- Use an uninterrupted inner GND reference across the whole converter and preserve it beneath the bypass loops. Connect the entire exposed pad to ground copper with multiple thermal vias. Choose via drill, paste openings and tenting/plugging with the fabricator's assembly rules; avoid unfilled large holes that drain the solder joint. Extend heat-spreading copper beyond the IC and keep it connected through multiple vias.
- Route J1–F1–Q1–input capacitors and the common output trunk as pours/wide tracks sized for the low-battery current. Do not funnel these through one signal-width track, one ordinary via, or thin thermal spokes. If changing layers, use multiple vias and account for their aggregate resistance. Branch the three module supplies from the output distribution region and place each reservoir/ceramic pair at its module supply pins.
- Keep test access to VBAT_PROTECTED, 3V3, GND and PGOOD; provide a short-ground probing location at both the converter and farthest module. Leave R4/C10 accessible for compensation tuning. Do not add a large test stub to SW or FB.

The PMOS orientation is correct: fused battery to Q1 drain, converter to source, 100 kΩ gate pull-down. It protects reverse battery polarity, not reverse current from an externally driven 3V3 rail. Its low-voltage RDS(on) supports this application, subject to heating and copper. See [DMP2008UFG](https://www.diodes.com/datasheet/download/DMP2008UFG.pdf).

## Current, thermal and compensation assessment

The three C5 modules require supply capability of at least 0.6 A each, totaling 1.8 A before RP2350 and other circuitry. The **2.2 A output figure is a design budget**, not a measured load or guaranteed converter rating. The additional 0.4 A remains an allocation to confirm with the actual RP workload. The **3 A figure is a transient test target**, requiring a defined pulse duration/duty cycle. Source: [ESP32-C5-WROOM-1/1U data sheet, table 6-2](https://www.espressif.com/sites/default/files/documentation/esp32-c5-wroom-1_wroom-1u_datasheet_en.pdf).

Calculated using an explicitly assumed 80% efficiency and 3.3 V output:

| Operating point | Output power | Input current at 3.0 V | Total converter-stage loss |
| --- | ---: | ---: | ---: |
| 2.2 A budget | 7.26 W | 3.03 A | 1.82 W |
| 3.0 A transient target | 9.90 W | 4.13 A | 2.48 W |

`Iin = Vout × Iout / (Vin × efficiency)`; loss is `Pout × (1/efficiency − 1)`. These are estimates, not efficiency measurements. Loss is distributed between IC, inductor, MOSFET and other resistances; do not put all of it into an IC junction calculation. The selected cell/BMS, connector, fuse, wiring and copper must support the input current including cold-cell and contact resistance. Normal full-load operation stops near the UVLO threshold; 2.8 V is not a promised full-load condition.

L1's [XAL7070-472MEC data](https://www.coilcraft.com/getmedia/1ba55433-bcc8-4838-9b21-382f497e12e0/xal7070.pdf) gives 4.7 µH ±20%, about 14.3 mΩ maximum DCR and 15.2 A typical saturation current at 25°C, defined by 30% inductance loss. That is not a guaranteed hot saturation threshold. The converter's inductor-current limit must not be read as an output-current rating. With the 80% estimate, Q1 conduction loss at the 4.13 A input pulse is approximately 0.17 W using its 25°C 9.8 mΩ maximum figure; hot resistance is higher.

The existing 78.7 kΩ / 820 pF network has a calculated compensation zero near 2.47 kHz. Its output load includes C7's 220 µF, three 100 µF reservoirs and ceramics; nominal bulk alone totals 520 µF. This differs from TA06 and includes trace resistance/inductance. A1 selects C6 = Panasonic 10SVPC120M (120 µF input) and C203/C303/C403 = 6SVPC100M (100 µF each, 30 mΩ specified ESR). These polymer selections must be included in the model; lower ESR is not by itself evidence of stable operation. For illustration, the simplified boost RHP-zero equation gives about 41.9 kHz at 3.0 V / 2.2 A and 30.7 kHz at 3.0 V / 3 A with 4.7 µH. These calculations identify validation cases; they do not prove phase margin. Retain the TA06 compensation as the prototype starting point, model the selected capacitor network, and confirm with load-step tests before asserting the operating envelope.

C7 is correctly polarized and dimensioned. [Panasonic 6SVPE220M](https://industrial.panasonic.com/sa/products/pt/os-con/models/6SVPE220M) uses the 6.3 mm diameter, 5.9 mm case; [case dimensions](https://industrial.panasonic.com/cdbs/www-data/pdf/AAB8000/AAB8000C179.pdf) and [recommended lands](https://industrial.panasonic.com/cdbs/www-data/pdf/AAB8000/AAB8000COL10.pdf) support the chosen footprint. Its 220 µF is nominal with tolerance, not minimum capacitance.

## Required sample measurements and release boundary

- Sweep converter input from 4.2 V down to just above actual UVLO, then through shutdown/restart. Include startup with the full capacitor bank and realistic protected-cell/cable resistance. UVLO stopping switching is not zero battery drain; use the specified external protected pack and measure standby/off current.
- At 2.2 A and simultaneous radio operation, measure converter and all three module supply pins, ripple/overshoot, efficiency and component temperature after thermal equilibrium. Test the defined 3 A pulse separately. Stay within each module's 3.0–3.6 V supply range, including transients. Do not use thermal shutdown as the normal junction-temperature limit.
- Check light-load/Burst behavior, repeated load steps and buck/boost transition near 3.3 V. Investigate sustained ringing or supply dips before radio/RF testing. A voltage probe with a long ground lead is insufficient evidence for switching ripple.
- Verify reversed battery, pack protection behavior and fuse coordination with a current-limited test setup. No board charger, raw PV input, battery ADC or USB-powered board operation is introduced by this review.
- The USB hardware change is statically closed against the final PCB/netlist. Test every power-order combination on the sample, including ROM BOOTSEL; that functional validation remains unperformed.

## Power placement implementation and local audit

Under the implementation owner's later delegation, this reviewer added `scripts/power_placement.py`. It loads no project board and saves none: `placements()` supplies the component coordinates, and `route(board, footprints, nets)` draws the converter cell after the caller loads the real footprints and assigns nets. The script rejects moved component coordinates rather than drawing stale routes. L1 is rotated 180 degrees so SW1 and SW2 face their matching U1 sides. C3/C4/C8 bridge the lower switch branch through the gap between their pads, following the FE reference arrangement. High-current trunks use 1.0–1.5 mm copper, with narrower local pin escapes and 0.6 mm sections beneath those ceramic bodies.

An isolated four-layer test board was built in `/tmp` using the actual final power footprints and net assignments, including C6 = 10SVPC120M. With continuous inner GND planes and the project's 0.15 mm clearance / 0.45 mm via / 0.20 mm drill constraints, its KiCad DRC reported **zero copper/clearance/courtyard/hole conflicts and zero unconnected power items**. Remaining scratch-board findings were 20 default-reference/value silkscreen overlaps; the full-board build manages these labels. This local result does not replace full-board DRC or final copper inspection.

The script returns the B.Cu 3V3 distribution anchor `(68.0, 28.7)` and three 0.6 mm / 0.3 mm output-bulk vias. The feedback sense is routed separately from C9's positive pad at this output-distribution region. The builder must preserve both continuous inner ground planes and join the system supply branches at the specified distribution copper.

For ordinary prototype assembly, **no thermal drill remains inside U1's exposed-pad solder-mask/paste area**. Nine 0.6 mm / 0.3 mm GND vias lie beyond the exposed pad, at x = 79/80/81 mm and y = 22.1/31.9/32.7 mm. Three 0.8 mm copper strips at each end join these vias to the exposed-pad copper. This avoids relying on filled/capped via-in-pad assembly; it increases thermal-path resistance compared with the data-sheet board using vias beneath the exposed pad. Therefore data-sheet thermal resistance cannot be assigned to A1, and 2.2 A operation remains subject to actual temperature measurement. Ordinary tented capacitor-adjacent vias are separate from their pads; the 0.35 mm spacing advice for reliable solder-mask **filling** was not treated as a universal tenting rule.

## Integrated power-distribution review

Actual routed-candidate inspection: 2026-09-23. The loaded power footprint positions match `power_placement.placements()`. Every segment of all four paths in `reports/power-distribution.json` exists on B.Cu and 3V3: A/B/C are 1.5 mm, and the RP feed is 1.0 mm. The earlier C7/R104 and TP2/R6 courtyard conflicts are closed: R104 is at `(63,13)` and TP2 at `(66,26)`, and the candidate DRC reports no courtyard violations. The actual LTC3119 board uses the nine **peripheral** EP vias described above; the superseded in-pad EP arrangement is absent. These findings replace the initial integration snapshot.

Using nominal 35 µm outer copper and copper resistivity at 20°C, the branch estimates are internally consistent:

| Branch | Actual route length | Width | Estimated copper resistance | Calculated drop at 0.6 A |
| --- | ---: | ---: | ---: | ---: |
| A | 65.409 mm | 1.5 mm | 21.43 mΩ | 12.86 mV |
| B | 80.982 mm | 1.5 mm | 26.53 mΩ | 15.92 mV |
| C | 50.229 mm | 1.5 mm | 16.46 mΩ | 9.88 mV |

The RP feed is 13.853 mm long and 1.0 mm wide, approximately 6.81 mΩ by the same model. Its 0.4 A allocation would give about 2.72 mV of copper drop; this is an allocation calculation, not a measured RP current.

These are conductor estimates, excluding vias, pads, the common feed, ground return, copper-thickness tolerance and temperature rise. At 0.6 A the longest branch dissipates about 9.6 mW. The common 1.0 mm-wide, 6.7 mm-long copper segment before the star point is approximately 3.29 mΩ under the same assumptions, or 7.24 mV at 2.2 A. Those values support the prototype layout choice; they are not measured current or temperature ratings. The 0.6 A number is a module supply-capability requirement, not a cap on each module's instantaneous draw.

The specified stackup places In2 GND about 0.0994 mm from B.Cu. On the frozen board, both In1 and In2 contain one connected filled GND outline; all 1,540 routed tracks are on F.Cu/B.Cu, so signal traces have not divided the inner reference planes. Sampling each actual branch centerline at intervals no larger than 0.25 mm gives 298/341/280/65 sample positions for A/B/C/RP. GND is present beneath the trunks; the only misses are local positive-supply-via antipads at module/RP entry. The RP LX keepout is confined to its intended In1 region, away from the LTC3119 cell. Thus the inspected board provides nearby plane returns without a long reference-plane split beneath these supply paths. Further routing/zone changes require repeating this check. Local reservoirs and their ground vias handle high-frequency pulse current; a long 3V3 trace alone is not the decoupling network.

### Copper corrections and final frozen-board closure

The Specctra session import had omitted all fixed seed tracks/vias. `merge_seed_routing.py` restores their 825 unique geometries with destination-board net mapping; the source seed contained 827 objects including two duplicate geometries. Before the two deliberate paste fixes below, every unique seed copper geometry was present in this candidate. The high-current battery paths, PVIN/PVOUT bypass connections, bootstrap loops, FB/VC/RT routes and power footprints consequently retained the independently reviewed local arrangement. The nine EP ground vias are actually present at x = 79/80/81 mm and y = 22.1/31.9/32.7 mm, with 0.6 mm copper/0.3 mm drills and the 0.8 mm copper bridges. Their external placement avoids EP solder drain, but the thermal penalty relative to an in-pad reference board still requires measurement.

`finish_power_access.py` closes nine disconnected GND chains and three low-current 3V3 tails with 12 added tracks and nine ordinary tented 0.6/0.3 mm vias. It checks connection to a filled inner GND zone rather than assuming that an existing track reaches ground. The added vias are outside all pad/paste windows. USB control/switch supply and the debug/reference branches join existing distribution copper through 0.3 mm B.Cu tails; those tails do not carry the three-radio load. Repeated invocation adds no further copper.

An actual paste-shape/drill intersection check found two defects that ordinary electrical DRC did not report: the original C5.2 GND via at `(88.0,30.6)` and R7.2 REG_RUN via at `(88.3,35.5)` each intruded about 0.025 mm into its adjacent paste opening. `fix_power_paste_clearance.patch(board)` moves them to `(88.0,30.85)` and `(88.3,35.75)`. The REG_RUN B.Cu diagonals retain their former meeting point, with one 0.25 mm stub to the new via, preserving clearance to C11's GND via. The same coordinates/stub are now in `power_placement.py` to prevent regeneration of the defect. The patched temporary candidate has **zero actual drill/paste intersections**. A C5.1 bounding-box overlap with another via was checked against its rounded pad shape and is not a physical intersection.

The intermediate temporary board had three remaining connections outside the power-tail work. Those are now closed on the frozen main PCB. The final read-only review confirmed:

| Static check | Result at the frozen PCB SHA-256 |
| --- | --- |
| Final DRC / unconnected / schematic parity | 0 / 0 / 0 in `reports/drc.json` |
| ERC | 0 sheet violations in `reports/erc.json` |
| Actual board via count | 396, including the final ground-access fallback vias |
| Converter component positions and rotations | Match `power_placement.placements()` |
| Reviewed local converter copper | Preserved after final unrelated reroutes |
| A/B/C/RP distribution paths | Every recorded segment, net and width present |
| LTC3119 exposed-pad ground vias | All nine peripheral vias and copper bridges present |
| C5 and R7 paste corrections | New via positions present; old positions absent |
| J2 ground-via mask clearance | Via at (98.25, 26.54); 0.25 mm nominal hole-edge to pad-mask-opening gap |
| Full-board actual paste-shape/drill collision check | 0 intersections |
| In1/In2 GND continuity and branch return sampling | Rechecked and unchanged, as described above |

**No unclosed power-related prototype-fabrication blocker was identified for PCB SHA-256 `94b96a96ef75f9561a9c2552ea9e2db2f6d1eb0fe6a99cec8e6313b0ac1b4ab9`.** This is static power-review sign-off for making and testing the prototype. It does not authorize substitutions or apply to later copper changes. Electrical stability, sustained 2.2 A temperature, the defined 3 A transient test and USB power-order behavior remain first-board measurements; the stated current figures are design/test targets, not demonstrated ratings.

### Actual manufacturing-layer review

The final exported manufacturing files were independently inspected through `review/gerber/F_Cu.png`, `B_Cu.png`, `In1_Cu.png`, `In2_Cu.png` and `paste-drill-overlay.png`, rendered directly from Gerber/Excellon bytes with gerbonara 1.6.3. Local converter enlargements were also inspected. This review uses the manufacturing layers themselves, not only KiCad's native display. All 11 Gerber and two Excellon input hashes, plus the inspected image hashes, match `review/gerber/render-manifest.json`, SHA-256 **`321257ff7851ca2e0f5fdc9abaaaf83bd13e512c23543d28fce0b9004fea47b3`**. The export manifest binds these outputs to the final PCB SHA above.

Parsed Gerber coordinates/apertures confirm every A/B/C 1.5 mm and RP 1.0 mm supply segment. U1's exported GND heatsink pad is 3.05 × 7.56 mm, with all six 0.8 mm copper bridges and nine 0.3 mm peripheral drill hits present. The two corrected C5/R7 holes occur at their new positions only. The final DFM improvement moves the J2 GND via from `(98.0,26.54)` to `(98.25,26.54)`; the actual F.Mask circle is 1.7 mm diameter at `(97.0,26.54)` and Excellon drill diameter is 0.3 mm, giving **0.25 mm nominal hole-edge-to-mask-opening clearance**. The original tangent hole is absent.

Both inner Gerbers have one continuous main filled region. Visual inspection and polygon point checks confirm ground around the LTC3119 cell; the RP LX body and neck are cleared on In1 while In2 retains ground there. No missing supply copper, severed EP bridge, unexpected ground-plane split, or power-related export discrepancy was identified. **Final manufacturing-layer power review: PASS for prototype fabrication**, with the unmeasured operating limits and first-board tests below unchanged.

### Capacitor model and first-board tests

The official [Murata SimSurfing](https://ds.murata.com/simsurfing/mlcc.html?lcid=en-us) response for GRM21BZ71A226ME15 is preserved in `parts-selection.json` under `capacitor_validation.GRM21BZ71A226ME15L`, including request parameters, the full 201-point response and SHA-256 `662e4209ee2470dc889907910592f94f6a3ba756e7fa337bd67166ccd6e7feca`. The curve gives 14.288852 µF at 3.3 V and 11.788160 µF at 4.2 V per part. Its conditions are 25°C, 0.5 Vrms, 120 Hz, consistent with [Murata's measurement conditions, pp. 7–8](https://ds.murata.com/simsurfing_data/pdf/en-us/mlcc/sim_mlcc_measuringcond_e.pdf).

Accordingly, a nominal model at 4.2 V uses about **23.5763 µF for C3+C4**, plus the 120 µF input polymer, rather than 44 µF of input ceramic. On the output, the 220 µF central polymer and three 100 µF polymers total **520 µF nominal**; C8 and the three radio 22 µF ceramics add about **57.1554 µF** under the retrieved 3.3 V curve. This gives approximately 577.2 µF before the other decouplers and device-internal capacitance. It is a distributed network with branch resistance/inductance and distinct ESRs, not a single ideal capacitor at U1. C7's specified ESR is 10 mΩ; the radio polymers are 30 mΩ each and the input polymer is 27 mΩ.

No verified full-temperature or low-ripple bias curve was obtained. Do not convert these typical points into guaranteed capacitance minima or derive them from the X7R label. Model component tolerances and distributed impedance, then measure startup/inrush, no-load-to-load and reverse load steps, three-radio simultaneous bursts, 3.3 V buck/boost transition, UVLO recovery and output overshoot. Record voltage at U1 and at every module; measure ripple with short-ground probing. Sweep input and relevant ambient temperatures and allow thermal equilibrium at 2.2 A. Define the 3 A pulse width/duty cycle before testing it. **Electrical stability, sustained-load temperature and actual radio-load performance remain unmeasured; this is prototype review evidence, not a production operating guarantee.**

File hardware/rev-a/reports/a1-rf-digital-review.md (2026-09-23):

# A1 RF / digital review — final routed prototype

Review date: **2026-09-23**. Independent AI-assisted engineering review of the actual routed, filled A1 PCB, manifest/netlist, library pads and official device/reference-board documents. Reviewed PCB SHA-256:

`94b96a96ef75f9561a9c2552ea9e2db2f6d1eb0fe6a99cec8e6313b0ac1b4ab9`

This final snapshot includes the J2 GND via move from (98.00,26.54) to (98.25,26.54) mm to separate its drill from the adjacent connector's mask opening. Signal routing and the reviewed inner-plane return topology are unchanged. Fresh DRC and all 11 automatic checks pass for the hash above.

**Disposition: GO for controlled A1 engineering prototypes.** No unresolved RF/digital layout blocker is identified for this snapshot. The source-route and return-via deviations below are explicitly accepted for prototype investigation. This is not approval of 50 Mbps timing, RF throughput, production yield or regulatory compliance. Firmware, SI measurements, reset behavior, RF coexistence and thermal performance remain unvalidated. Manufacturing/assembly acceptance is also governed by [FABRICATION.md](../FABRICATION.md), [the DFM review](a1-dfm-bom-review.md) and [the power review](a1-power-review.md).

This report supersedes the earlier pre-layout recommendations: **In1.Cu and In2.Cu are both GND; the C5 EP gap vias were removed; the complete routed PCB is now reviewed.** The former In2 power/signal proposal and internal EP gap-via proposal are historical, not manufacturing instructions.

## Evidence and automatic checks

`pcb-verification.json` (package: `audit/pcb-verification.json`) records the exact PCB/manifest/XML/library hashes and passes all 11 automated checks. The verifier does not alter or refill its input board. `drc.json` (package: `audit/drc.json`) reports 0 violations, 0 unconnected items and 0 schematic-parity findings; `erc.json` (package: `audit/erc.json`) reports 0 violations. These are design-tool results, not assembled-board tests.

| Check on final copper | Result and interpretation |
| --- | --- |
| Inventory, electrical assignments and library geometry | 164 front-side footprints; 640 pad regions across 27 library types. Local position, angle, size, shape, drill, layers and pad overrides match the assigned libraries, including PowerDI3333 custom-pad geometry. All 566 unique numbered pads / 609 numbered physical lands match the XML and manifest topology; 44 no-connect nodes remain isolated. |
| Paste / exposed pads | All **396 via drills** checked against **597 F/B paste apertures**: no collision. The RP, LTC3119 and three C5 EP bounding envelopes also contain no holes. Component PTH/NPTH drills are excluded from the global via-in-paste check. |
| Ground reference layers | No tracks/arcs on In1.Cu or In2.Cu. Each saved GND fill has one connected polygon; areas are 9664.725 and 9672.906 mm², respectively (97.8175% / 97.9003% of their 9880.36 mm² outline). Local clearance holes and the intentional LX cutout remain. Polygon connectivity alone does not prove every return-path neck or RF behavior. |
| RP LX exception | Full F.Cu LX copper, including U101 pad 63 and its neck, projects **0 mm²** onto actual In1 copper. This uses Boolean geometry of zones, tracks, vias and pads, not only keepout bounds. |
| USB straight coupled trunk | F.Cu x=50.000 / 50.358 mm, common y=25.950–40.048 mm: **W=0.158 mm, edge gap=0.200 mm, common length=14.098 mm**. Its complete rectangular projection has no missing GND below it on either inner layer. Connector, ESD, switch, crossover and resistor escapes are not claimed to have that same impedance. |
| Link source resistors | All 36 × 22 Ω resistors are on their intended driver side. All C5-driven source tails have 0 signal vias; C5 clock/control tails are approximately 2.03–2.12 mm of copper. The longer RP-driven tails are listed below. |

## RP core, flash and crystal

The core buck uses the RP internal regulator, the selected direction-marked Abracon inductor and 0402 R101/C101–C103. The local input, output, LX and high-current ground copper is adapted from the official **RP2350B Minimal R4 / schematic S1** reference. The source front-layer central 1V1 distribution was changed to a small B.Cu distribution region so the target EP retains solid top GND; this is an adaptation, not a claim of an identical reference PCB.

The high-current ground has adjacent 0.60/0.25 mm vias at (54.1,43.25) and (54.1,43.85). CFILT/C101 has its own short ground return. The RP EP connects to top GND and eight perimeter vias outside its paste/EP envelope; the reference's nine internal plated pads are not treated as a mandatory via count. The final In1 LX cutout includes the neck through y=45.65 mm. Its predecessor stopped at y=43.2 and left 0.427187 mm² of GND under LX; that finding is closed in the reviewed board.

These choices follow [RP2350 datasheet §6.3.8, printed pp.454–455 / Fig.24](https://datasheets.raspberrypi.com/rp2350/rp2350-datasheet.pdf#page=456): compact switching loops, adjacent high-current ground vias, a separate filtered-supply return and clearance immediately below LX on multilayer boards. The [RP hardware guide, pp.5–8](https://pip-assets.raspberrypi.com/categories/1214-rp2350/documents/RP-008280-DS-2-hardware-design-with-rp2350.pdf) explains the component/orientation sensitivity. Actual regulator transient/thermal behavior is still a first-board gate.

**QSPI:** all six nets use F.Cu and zero vias. There are no optional bottom-flash branches, and CS is connected across the absent reference 0 Ω selection position. Total copper lengths are IO0 7.158, CLK 8.920, IO3 10.432, IO2 13.186 and IO1 17.338 mm. CS totals 30.295 mm including its pull-up/BOOTSEL branches, so that figure is not a single end-to-end flight length. The broader flash/escape corridor contains unrelated A-link routing, including a short passage under U102's body; it does not cross the QSPI copper electrically. This is accepted for the prototype with concurrent flash/link stress tests, not as crosstalk qualification.

**Crystal:** XIN, XOUT and XTAL_OUT remain F.Cu-only, with no signal vias (total copper 11.324 / 2.928 / 5.449 mm). Actual ordinary-routing inspection found no unrelated signal crossing beneath the Y101 resonator body. C_TX_D2 passes the upper/right edge of the broader local crystal-ground area and B_RX_VALID_C5 its upper/left edge. C_TX_D0/1/2 run partly on B.Cu near the load-capacitor/escape area; the two internal GND planes separate them from the top crystal circuit. This is a prototype compromise, not an assertion of an entirely empty crystal region. Verify startup/restart and USB operation while all links and radios are active. In a subsequent revision, reserve this wider quiet region before global autorouting.

The [official RP2350B Minimal KiCad reference](https://pip-assets.raspberrypi.com/categories/1214-rp2350/documents/RP-010329-CA-1-RP2350B%20Minimal%20KiCAD.zip) and [hardware guide pp.10–15](https://pip-assets.raspberrypi.com/categories/1214-rp2350/documents/RP-008280-DS-2-hardware-design-with-rp2350.pdf) are the source for the flash, crystal and USB layout intent. Reusing geometry does not replace timing, oscillator or USB measurements.

## Accepted source-route deviations and measurement gates

Lengths below are total track lengths on the source-to-resistor net; vias are counted separately. Straight placement distance alone hid the A-link routing detours.

| Signal | Source → series source pad → receiver | Source copper / signal vias | Disposition |
| --- | --- | ---: | --- |
| A_RX_D0 | U101.3 → R216.2; R216.1 → U201.8 | **17.185 mm / 4**; direct pad distance 5.044 mm | Accepted for A1 bring-up. Highest-priority source/receiver ringing and setup/hold capture; reroute this source tail first in the next PCB revision. |
| A_RX_VALID | U101.9 → R221.2; R221.1 → U201.23 | **12.302 mm / 2**; direct 5.671 mm | Capture both resistor sides and the receiving C5 VALID input; reject false/late VALID transitions. |
| C_RX_D1 | U101.39 → R417.2; R417.1 → U401.10 | **11.778 mm / 0**; direct **10.338 mm** | Exceeds this review's 10 mm RP placement attention threshold. Validate timing against C_RX_CLK; move the termination closer to the RP in the next revision. |

These are not presently open fabrication blockers. They remain functional acceptance gates. Start with one link and a low clock, then increase rate only after receiver timing and waveforms pass; reduced clock frequency does not itself slow edges or eliminate ringing. Record driver settings, probe loading, source and receiver levels, overshoot/undershoot, settling and setup/hold. Repeat with all links/radios active while stressing QSPI/XIP and checking CRC/readback. Do not infer a validated 50 Mbps operating point from DRC or raw `4×fCLK` arithmetic. Concrete probe points are in [FIRST-BOARD-TEST.md](../FIRST-BOARD-TEST.md).

## Return transitions: nine accepted heuristic exceptions

The final board contains 396 vias. The stitching audit `ground-stitching.json` (package: `review/evidence/reports/ground-stitching.json`) checks 141 signal through-vias; 132 have a GND plated via/pad within 2 mm centre distance. Two fabrication-compatible 0.45/0.20 mm GND vias were added for SWDIO and B_TX_VALID after the 0.60/0.30 mm search. All new holes remain outside pads, paste and EP envelopes and passed final DRC. The remaining nine positions could not fit another candidate without violating the conservative geometry constraints:

| Signal | Signal-via position, mm | Nearest plated GND centre distance, mm | A1 disposition |
| --- | --- | ---: | --- |
| A_RX_D0 | (46.0030,43.5463) | 3.424662 | Accepted; highest-priority source-tail/data waveform and A-link timing test. |
| A_RX_D3 | (43.1146,48.5897) | 2.629674 | Accepted; include in A-link receiver timing captures. |
| B_RX_D0 | (45.8286,52.7901) | 2.673413 | Accepted; include in B-link data/clock margin sweep. |
| B_RX_D1 | (45.5199,54.3042) | 2.827745 | Accepted; include in B-link data/clock margin sweep. |
| B_RX_D3 | (45.4390,55.5881) | 2.154122 | Accepted; include in B-link data/clock margin sweep. |
| B_RX_VALID | (47.8951,56.5079) | 3.195144 | Accepted; capture C5 VALID threshold and timing during startup and steady traffic. |
| B_TX_CLK | (45.8325,52.1474) | 2.317672 | Accepted; priority clock-edge capture at RP U101.16 against the source at U301.17/R314. |
| C_RX_D2 | (54.5296,54.9281) | 2.541838 | Accepted; include in C-link receiver timing captures. |
| C_TX_D2 | (48.6210,55.9071) | 2.583730 | Accepted; include in C-link and crystal/concurrent-traffic stress. |

**2 mm is this project's review heuristic, not a manufacturer-mandated limit.** The two inner GND planes remain connected, and the nearest physical return connection is 2.154–3.425 mm away for these exceptions. This supports accepting a controlled prototype; it does not establish transition impedance or timing margin. For the next layout, reserve ground-transition space and fix RP source-to-series routes before autorouting the remaining nets. First-board failures require correcting routing/termination/drive settings before increasing the claimed operating rate.

## C5 module land pattern and RF assembly

U201/U301/U401 remain ESP32-C5-WROOM-1U-N8R8 at (20,20)/90°, (20,80)/180° and (80,80)/270°. UART, EN and BOOT support is retained; GPIO13/14 are parallel-interface pins, so native C5 USB is intentionally unavailable. Both link clocks are C5 outputs. All six receiver VALID pull-downs remain 4.7 kΩ; verify actual reset/high-impedance/startup behavior in firmware and on hardware.

The [C5 module datasheet v1.3, Fig.11-2 / inspected PDF p.55](https://www.espressif.com/sites/default/files/documentation/esp32-c5-wroom-1_wroom-1u_datasheet_en.pdf) supports 32 pad numbers / 40 copper lands, including nine 1.3 × 1.3 mm EP29 lands with 0.4 mm gaps. Each module has 15.21 mm² paste over a 4.7 × 4.7 mm envelope (68.9%). The **complete envelope is hole-free**. Local solid top GND joins these lands to eight perimeter EP vias and peripheral ground-pad accesses. The four former internal gap vias are absent. Ordinary double-sided tenting is used; no filled/capped via process or reliable ink-plugging capability is assumed. Tenting, solder-mask webs, voiding and thermal performance remain manufacturing/assembly verification items.

ANT1 is the on-module connector. Approximate board centres are A (11.78,14.00), B (14.00,88.22), C (88.22,86.00) mm. ANT2/pad31 has no host RF trace. The [module datasheet Figs.10-2/10-3, inspected PDF pp.51–52](https://www.espressif.com/sites/default/files/documentation/esp32-c5-wroom-1_wroom-1u_datasheet_en.pdf) gives module/connector dimensions and the compatible U.FL / MHF I / AMC families. This external-connector variant does not require the PCB-antenna 15 mm carrier void, but the plug/coax/enclosure assembly must be checked physically.

The provisional 8 × 8 mm connector-access square, 3 mm cable corridor and 7 mm unobstructed height are planning allowances, not vendor-certified minimums. Verify the selected dual-band 50 Ω antenna, exact mating plug, coax bend radius, strain relief and final enclosure. Keep cables clear of switching inductors and exposed headers; measure isolation/coexistence with one, two and three radios active. Follow the module's handling/reflow requirements (inspected PDF p.56). The [Espressif C5 PCB guidance](https://docs.espressif.com/projects/esp-hardware-design-guidelines/en/latest/esp32c5/pcb-layout-design.html) informs return/decoupling practice; its bare-chip via-count rules are not misrepresented as a mandatory WROOM carrier count.

The review approves the stated **prototype** snapshot with the documented deviations and test gates. It supplies no fabricated-board result and no certification of link speed, three-radio performance, antenna placement or production readiness.

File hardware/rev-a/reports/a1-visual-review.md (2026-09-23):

# A1 final visual and artifact review

Date: **2026-09-23**. **PASS for controlled A1 prototype fabrication.** This record covers the frozen native PCB and the final export batch, after the last J2 GND via correction. It is an AI-assisted drawing review supported by independent numeric comparison, not a claim of manufactured-board inspection.

PCB SHA-256: `94b96a96ef75f9561a9c2552ea9e2db2f6d1eb0fe6a99cec8e6313b0ac1b4ab9`.

## Inspected drawings and actual fabrication layers

- **Eight schematic pages:** hierarchy, power, RP2350, radios A/B/C, USB and test/mechanical. Reviewed full pages and dense circuit crops. USB C126/title-block interference and U104 field/body interference were corrected before the frozen export. A1 revision, page borders, pin/net labels and component fields remain legible; no clipping or new overlap was identified in the final drawings.
- **Eleven native-layer PDF pages:** F.Cu, In1.Cu, In2.Cu, B.Cu, F.Mask, B.Mask, F.Silkscreen, B.Silkscreen, F.Paste, B.Paste and Edge.Cuts. The two internal GND planes, intentional LX void, supply branches, signal routing, module ground, EP apertures and mechanical outline agree with the reviewed PCB. The layer PDF uses 1:1 placement on A4 landscape; surrounding white space is intentional.
- **Assembly top PDF:** black-on-white F.Fab, F.CrtYd and outline at 2:1. Reference text, pin-1 chamfers, capacitor polarity and connector outlines were inspected. Pad-number overlays and black drill marks that obscured references were removed from this drawing. Use the placement CSV for machine coordinates; this drawing is not a placement-coordinate conversion.
- **Separate PTH and NPTH map PDFs:** map legends, tool diameters, hole symbols, USB shell slots and four mounting holes inspected. PTH map records 155×0.20, 8×0.25, 233×0.30, 25×1.00, 2×1.70 mm circular holes plus four 0.60 mm slots (427 objects). NPTH map records two 0.65 mm USB locating holes and four 3.20 mm mounting holes (6 objects). Map/table layout is unclipped and readable.
- **Actual fabrication data:** all 11 Gerbers and both Excellon files parsed and rendered independently using gerbonara 1.6.3 / PyMuPDF 1.28.2. Individual layers, a whole-board paste/drill overlay and power/USB/EP crops were inspected. B.Paste and B.Silkscreen Gerbers are intentionally empty because all components and legend are on top; native-layer PDFs may still show hole marks. Edge.Cuts centre lines form 100.00×100.00 mm; the 100.05 mm plotted stroke bounding box is not a change of board size.

The power reviewer independently checked final copper, EP bridges, peripheral holes and both GND planes in actual Gerbers. The BOM/DFM reviewer compared every drill/slot and all placement rows against native geometry and checked actual aperture-to-hole distances. Their signed reports bind the same PCB SHA. The J2 corrected hole has 0.25 mm clearance from its adjacent mask opening; no old hole remains. The small positive C9/C5/J1 mask/paste margins remain documented process inspection points, not unreported nominal collisions.

## Byte-level binding

`a1-visual-review.json` records the five PDF hashes and their **22 pages**. The following PDF files are relative to the manufacturing directory:

| PDF | Pages | SHA-256 |
| --- | ---: | --- |
| `assembly/assembly-top.pdf` | 1 | `c04a042f8e78a04d16a9fdb229817e2fee73d63460d02b508e442c02c7551f56` |
| `drill/FarmMesh-Node-NPTH-drl_map.pdf` | 1 | `84eeb3dbee1d99c60d84002b8f43f89835599fa3b3fe27506ed15eb28a09816a` |
| `drill/FarmMesh-Node-PTH-drl_map.pdf` | 1 | `eeb676f8588073c070e1b07bb4f59805782da8d83d67bdb93ceb01ecc86a312c` |
| `review/FarmMesh-Node-A1-layers.pdf` | 11 | `bd471e7db77bc61a662f03485c131455b3cad9d35ada366ee70ad5fe4c25d258` |
| `review/FarmMesh-Node-A1.pdf` | 8 | `bcd6535ca11eea474bb898c9616155a8a5e4b6c48af0084b56e28cb095b480f8` |

`review/gerber/render-manifest.json` SHA-256: `321257ff7851ca2e0f5fdc9abaaaf83bd13e512c23543d28fce0b9004fea47b3`. Every listed input Gerber/drill hash and every generated PNG/SVG hash was rechecked against the final files. The manifest's renderer-only status means images require inspection; this signed review records that inspection without changing the renderer's original output. The package includes the render manifest and rendered evidence under `review/evidence/`.

## Rule-check scope

The zero ERC/DRC counts apply to the recorded project rule severities. The exported JSON retains the disabled categories: ERC `single_global_label`, `four_way_junction`, `simulation_model_issue`, `footprint_filter`; DRC `missing_courtyard`, `track_not_centered_on_via`, `tuning_profile_track_geometries`, `footprint_filters_mismatch`, `footprint_type_mismatch`. There are no per-item DRC exclusions. Electrical connectivity, copper/holes/clearances, courtyard overlap and silkscreen checks remain active; pad geometry, selected package identity and assembly type are additionally covered by the independent verifier and DFM review. A zero count is not a claim that disabled advisory categories were run.

## Disposition and limits

No unresolved visual/artifact mismatch blocks this controlled prototype. Final sealing must preserve the frozen native sources, refresh the final release/review documents, and pass `finalize_release.py --check-only` before distribution. The authoritative status is RELEASE.md; archive hashes remain external to avoid self-reference. Converter loop/thermal behavior, USB power sequencing, signal timing, RF operation and assembly yield remain first-board work. No purchase or manufacturing order was placed.

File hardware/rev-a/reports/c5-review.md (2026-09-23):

# Rev A — ESP32-C5 module review

**Review date: 2026-09-23 · schematic and footprint review · no hardware measurements**

Scope: [`design-manifest.json`](../design-manifest.json), [`c5-pinmap.json`](../c5-pinmap.json) and [`ESP32-C5-WROOM-1U.kicad_mod`](../FarmMesh.pretty/ESP32-C5-WROOM-1U.kicad_mod). This review covers the three radio modules and their connections to RP2350B. It does not replace the project ERC report, power-converter review or PCB review.

## Result

No unresolved C5 pin-mapping or module-footprint error was found in the inspected design. The previously identified missing VALID idle bias has been corrected and verified below. This is a review of the design data, not confirmation that the interfaces operate on hardware.

This record covers the final reviewed connection set, including the six 4.7 kΩ VALID pull-downs. Later changes require checking the affected connections again.

## Interface and support-circuit checks

- Exactly three `ESP32-C5-WROOM-1U-N8R8` modules are present: U201, U301 and U401. Each uses the reviewed 32-pad footprint.
- All 36 interface signals pass through their own 22 Ω series resistor to the intended RP2350B GPIO0–35, with no cross-connection between modules. Signal names use the C5 perspective. C5 supplies **both** TX_CLK and RX_CLK; RP drives only RX_D0–D3 and RX_VALID.
- The 12 interface GPIOs match the pinmap: TX data GPIO0/1/13/14, TX clock GPIO4, TX VALID GPIO5; RX data GPIO6/8/9/10, RX clock GPIO23, RX VALID GPIO24. No boot strap or internal flash/PSRAM pin is used for PARLIO.
- C5 USB GPIO13/14 are assigned to the C5-to-RP data direction. They are not connected to a USB connector. UART0 remains on module pad24/GPIO12 (RX) and pad25/GPIO11 (TX). Each UART header has GND, TX, RX, EN, BOOT and a 3.3 V reference; that reference is labelled as **not a power input**.
- Each module has its EN pull-up/RC and RESET button, GPIO28 pull-up/BOOT button, and GPIO27 pull-up. GPIO26 is unused. The documented download sequence holds GPIO28 low with GPIO27 high while resetting.
- Every module 3V3 pad is on `+3V3`; ground pads 1/28/29/30/32 are on GND. Local 22 µF, 100 nF and 100 µF capacitors are present for each module. Pad19, NC pads20/22 and the default-disabled ANT2 pad31 are unconnected.

The physical pad mapping, reset/download conditions and reference supply/EN circuits were checked against the [official module datasheet v1.3](https://www.espressif.com/sites/default/files/documentation/esp32-c5-wroom-1_wroom-1u_datasheet_en.pdf), tables 3-2 and 4-3, and figure 9-2 (PDF pages 14–15, 18 and 50 in the inspected 62-page document).

## Corrected finding: VALID idle bias

The initial design did not explicitly hold either direction's VALID signal inactive when its driving pin was released. In particular, GPIO5/MTDO does not have a default pull-up or pull-down in the [C5 SoC datasheet, table 2-1](https://documentation.espressif.com/esp32-c5_datasheet_en.html). Relying on software alone would leave reset and reconfiguration behavior dependent on initialization order and configured internal pulls.

The following six **4.7 kΩ pull-downs to GND** are now present on the receiving side of the corresponding series resistor:

| Radio | C5 → RP VALID, RP receiver | RP → C5 VALID, C5 receiver |
| --- | --- | --- |
| A | R204: `A_TX_VALID` | R205: `A_RX_VALID_C5` |
| B | R304: `B_TX_VALID` | R305: `B_RX_VALID_C5` |
| C | R404: `C_TX_VALID` | R405: `C_RX_VALID_C5` |

The initial 47 kΩ choice was reduced to 4.7 kΩ to accommodate RP2350 A2 silicon: [RP2350 erratum E9](https://datasheets.raspberrypi.com/rp2350/rp2350-datasheet.pdf) documents Bank 0 input leakage and an external pull-down workaround of 8.2 kΩ or less (printed pages 1366–1368; fixed in A3). This requirement applies to the RP receiver side; the C5 receiver side uses the same 4.7 kΩ value for consistency. At a nominal 3.3 V high level, each pull-down draws approximately 0.70 mA.

All six values and net endpoints were checked directly in the final manifest. This closes the hardware-bias finding; it does not implement reset recovery or transaction resynchronization.

## Footprint checks

The footprint has 32 unique pad numbers and 40 copper lands: 31 peripheral lands plus nine lands sharing EPAD number29. Pad numbering matches the module pin table. Checks against the official module datasheet figure 11-2 (PDF page55) confirmed the 18 × 21.2 mm body, 1.27 mm side pitch, 17.5 mm side-pad center spacing, 1.5 × 0.9 mm side lands, 0.9 × 1.5 mm top lands and 3 × 3 EPAD array of 1.3 mm squares with 0.4 mm gaps. All pads fit inside the footprint courtyard.

ANT1 is the module-mounted external-antenna connector; it is not another host-board solder pad. The footprint identifies ANT1 and the need for an external 2.4/5 GHz antenna. ANT2 remains disabled for the selected standard module. A PCB-antenna keepout has not been incorrectly applied beneath this external-connector module; cable clearance and actual antenna placement remain PCB/enclosure work. See module datasheet figures 10-2/10-3 and the [official module-layout guidance](https://docs.espressif.com/projects/esp-hardware-design-guidelines/en/latest/esp32c5/pcb-layout-design.html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).

## Boundaries and required validation

1. **Driver and timing:** No PIO/PARLIO driver has been implemented or tested. The reviewed [ESP-IDF v5.5 C5 capability definitions](https://github.com/espressif/esp-idf/blob/v5.5/components/soc/esp32c5/include/soc/soc_caps.h) support independent TX/RX units and RX-clock output. The [RX driver](https://github.com/espressif/esp-idf/blob/v5.5/components/esp_driver_parlio/src/parlio_rx.c) maps VALID through the GPIO matrix; `valid_sig_line_id = 4` denotes an internal RX lane for the 4-bit bus, not physical GPIO4. RX buffers/transactions must be prepared before accepting VALID. First-beat setup, sampling edges, frame end and restart behavior remain to be designed and measured.
2. **Reset and USB multiplexing:** RP must keep C5 TX-data and both clock nets as inputs. C5 firmware must reconfigure GPIO13/14 from USB before starting PARLIO; the [official hardware guidance](https://docs.espressif.com/projects/esp-hardware-design-guidelines/en/latest/esp32c5/schematic-checklist.html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) notes USB D+ startup transitions. Test power-up, each C5's independent reset, RP reset and UART download while the other devices remain powered. Receivers must discard startup data and recover partial transactions.
3. **Signal integrity:** The 22 Ω values are initial damping choices. Place each series resistor at its actual driver, including the C5 source for RX_CLK. Validate interconnect delay, ringing and setup/hold margins after PCB routing. No 50 Mbps interface or client-access performance has been demonstrated by this review.
4. **Power:** The [official supply guidance](https://docs.espressif.com/projects/esp-hardware-design-guidelines/en/latest/esp32c5/schematic-checklist.html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) calls for 3.3 V with at least 600 mA supply capability per C5. This is not a measured continuous load. Board-level regulation, simultaneous radio transients, capacitor DC-bias derating and local placement still require validation; the source is a regulated rail, not a direct 3.7 V cell connection.
5. **External antennas:** Three external antennas and their cable/enclosure arrangement remain to be selected and validated. The connector footprint alone does not establish coverage, antenna isolation, coexistence or throughput. No RF measurements or finished PCB layout are included in this review.

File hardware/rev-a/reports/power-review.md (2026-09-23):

# Independent power review — A0 draft

Date: 2026-09-23. Scope: `design-manifest.json`, the power section and power-related connections in `scripts/build_design.py`, and the assigned KiCad footprints. This is a static schematic review; no PCB, simulation, or hardware measurements were performed.

The corrections below are present in both the generator and regenerated manifest. No remaining static connection errors were found within this review scope. Component selection and bench validation remain open as listed below.

## Verified connections and corrections

- **LTC3119IFE#PBF:** FE pin mapping, all power/ground pins, exposed pad, 4.7 µH SW1–SW2 inductor, and both 100 nF bootstrap capacitors match the official reference. The assigned TSSOP-28 footprint has the required 3.05 × 7.56 mm exposed pad. See the [LTC3119 datasheet](https://www.analog.com/media/en/technical-documentation/data-sheets/3119fb.pdf), pp. 2, 12, 28 and 34.
- **Control network:** 316 kΩ/100 kΩ feedback gives 3.307 V nominal; 162 kΩ RT gives approximately 500 kHz; VC has 78.7 kΩ and 820 pF in series to ground. MPPC/SVCC connect to VCC, VCC has 4.7 µF bypass, and PWM/SYNC is grounded. These use TA06 as the starting circuit. PGOOD has a 100 kΩ pull-up and connects only to RP2350 GPIO36. The [PMEG2010EA](https://assets.nexperia.com/documents/data-sheet/PMEG2010EA.pdf) has pin 2/anode at 3V3 and pin 1/cathode at VCC.
- **Reverse battery protection:** the fused battery connects to Q1 drain; source connects to the converter; gate has 100 kΩ to ground. The Q1 symbol now uses pad 5 for physical drain pins 5–8 and exposed drain, matching the stock footprint's merged copper pad. See [DMP2008UFG](https://www.diodes.com/datasheet/download/DMP2008UFG.pdf). This circuit does not provide reverse-current isolation from an externally powered 3V3 rail.
- **UVLO:** 174 kΩ/100 kΩ and 470 pF give nominal 3.30 V start and 3.01 V stop thresholds; tolerance and input sag apply. The OFF jumper grounds RUN. UVLO stopping switching does not guarantee full shutdown: the LTC3119 requires RUN below 0.3 V for its minimum shutdown-current state. An external protected cell/pack remains necessary; no charger or raw PV input is implemented.
- **C7 footprint and polarity corrected:** 6SVPE220M is Panasonic case C6, diameter 6.3 mm and nominal height 5.9 mm. `CP_Elec_6.3x5.9` matches the manufacturer's land pattern: 2.1 mm inner gap, 9.1 mm overall length, 1.6 mm pad width. C6/C7/C203/C303/C403 now use polarized symbols with pin 1 positive and pin 2 grounded. Sources: [6SVPE220M specifications](https://industrial.panasonic.com/sa/products/pt/os-con/models/6SVPE220M), [SVPE dimensions](https://industrial.panasonic.com/cdbs/www-data/pdf/AAB8000/AAB8000C179.pdf), [recommended lands](https://industrial.panasonic.com/cdbs/www-data/pdf/AAB8000/AAB8000COL10.pdf).
- **Unpowered ADC backfeed paths removed:** R106/R107/C125 battery monitoring is deferred and GPIO40 is NC. USB VBUS sensing was moved from ADC GPIO41 to fault-tolerant GPIO37, retaining the divider. The divided USB voltage stays below the FT pin's 3.63 V unpowered limit for normal USB VBUS. ADC-capable pins are not covered by that FT allowance. See [RP2350 datasheet](https://datasheets.raspberrypi.com/rp2350/rp2350-datasheet.pdf), sections 12.4, 14.8.2 and 14.9.1.

## Budget and remaining validation

The 2.2 A rail budget includes the three modules' combined minimum 1.8 A supply capability plus RP2350 and margin; it is not a measured consumption figure. The module requirement is in [ESP32-C5-WROOM-1/1U datasheet](https://www.espressif.com/sites/default/files/documentation/esp32-c5-wroom-1_wroom-1u_datasheet_en.pdf), v1.3, table 6-2. The 3 A figure is a transient validation target, not a guaranteed continuous rating.

Using an explicitly assumed 80% efficiency, `Iin ≈ 3.3 × Iout / (Vin × 0.80)` gives about 3.03 A input for 2.2 A output, or 4.13 A for 3 A output, at 3.0 V at the converter. Cell/BMS, fuse, connector and wiring drops must be included. Converter loss under this assumption is about 1.82 W at 2.2 A output; this is a thermal budget, not an efficiency measurement.

- Confirm 2.2 A operation and the intended 3 A pulse profile across 3.0–4.2 V, temperature, startup and simultaneous radio activity. Measure module-pin voltage, ripple, overshoot, input sag, fuse behavior, and IC/inductor/MOSFET temperature.
- Verify compensation and transient response with the actual output capacitors, including all three local 100 µF reservoirs. TA06 compensation alone does not validate the larger distributed capacitance. C7 is 220 µF nominal ±20%, not a guaranteed 220 µF minimum.
- Complete exact MPN, capacitance under DC bias, ESR/ripple-current and footprint selection for the provisional bulk and ceramic capacitors. Only C7's specific polymer MPN/footprint was closed by this review.
- [XAL7070-472MEC](https://www.coilcraft.com/getmedia/1ba55433-bcc8-4838-9b21-382f497e12e0/xal7070.pdf) is 4.7 µH ±20%, DCR about 14.3 mΩ maximum, with 15.2 A saturation current defined at 25°C and a typical 30% inductance drop. Check hot inductance and temperature rise. LTC3119 average-inductor and peak current limits are not output-current ratings.
- Validate UVLO threshold spread, restart hysteresis and residual battery drain. Verify the selected protected pack's cutoff, current capability and fault behavior. Keep externally powered debugger/UART supply outputs disconnected from the reference-only 3V3 headers.
- PCB hot loops, ground returns, exposed-pad cooling, RF interference and production assembly are outside this schematic-only review.

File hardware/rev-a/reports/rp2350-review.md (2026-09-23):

# RP2350B / USB 独立电气审阅

审阅日期：2026-09-23。范围为 `scripts/build_design.py`、`design-manifest.json`、RP2350B 官方符号及本地 AOTA 电感封装。结论限于原理图连接、器件选择依据和封装引脚对应；没有进行实物上电、USB 枚举、ESD、时序或 PCB 电源完整性验证。本文件不是投板放行记录。

## 已处理的真实问题

初稿将电池分压和 USB VBUS 分压接到 GPIO40/41 的标准 ADC 引脚。RP 掉电时，这些外部电压会高于标准 IO 的 `IOVDD + 0.5V` 绝对最大值；串联大电阻不能单独证明符合电压规格。本版已移除电池采样 R106/R107/C125，GPIO40/41 留空；USB 检测移至 GPIO37（QFN80 pad 46，FT 类型）。电池 ADC 延至下一版，届时需重新设计并验证关断隔离采样。[RP2350 datasheet，Table 1427、1433](https://datasheets.raspberrypi.com/rp2350/rp2350-datasheet.pdf#page=1337)

### USB VBUS 检测的最终值

`USB_VBUS → R112 5.1kΩ ±1% → USB_VBUS_SENSE → R113 7.5kΩ ±1% → GND`，C126 为 10nF，检测点接 GPIO37。

按本版 VBUS 4.4–5.5V 的设计范围，`Vsense = VBUS × R113 / (R112 + R113)`：

| 检查项 | 计算结果 |
| --- | --- |
| 4.4V、上臂 +1%、下臂 −1% | 2.5978V |
| 5.5V、上臂 −1%、下臂 +1% | 3.3003V |
| 标称 Thevenin 电阻 / RC 时间常数 | 3.036kΩ / 30.36µs |
| 5.5V 标称分压电流 | 0.437mA |
| 下臂最大电阻 | 7.575kΩ |

Table 1436 在 IOVDD=3.3V 时给 FT 的 VIH 最小值为 **2.0V**；不应将 2.31V 写成该表规定值。按表中的 1µA 输入漏电估算，电压偏差约 3.1mV，仍有裕量。Table 1433 给 FT 在 IOVDD=0V 时的电压上限为 **3.63V**，上述掉电输入电压低于该值；这不是直接输入 5V 在掉电时也安全的依据。[RP2350 datasheet，§14.9.1、§14.9.4](https://datasheets.raspberrypi.com/rp2350/rp2350-datasheet.pdf#page=1340)

固件必须先将 GPIO37 配置为输入并**关闭内部上拉和下拉**，再判断 VBUS；不得将其设为输出。需要考虑 C126 稳定时间及连接/断开去抖，具体时序尚未验证。VBUS 检测是存在性判断，不是精确的电压监测。

RP2350 A2 的 E9 会在输入经过不确定区时产生额外源电流，导致高阻下拉读低失败。最终 7.5kΩ 下臂（含容差）满足官方外部下拉 ≤8.2kΩ 的规避条件；六个 VALID 接收端下拉也已改为 4.7kΩ。仍建议优先采购 A3/A4；这项硬件规避不代表全部硅片勘误均已审阅。[RP2350 datasheet，RP2350-E9，pp.1366–1368](https://datasheets.raspberrypi.com/rp2350/rp2350-datasheet.pdf#page=1367)

## 最小系统连接核对

| 项目 | 本版实现及核对结果 |
| --- | --- |
| MCU 符号 | 使用 `MCU_RaspberryPi:RP2350B`；81 个引脚（80 个外引脚及 EP81）与官方 QFN80 参考一致，EP 接 GND。 |
| 电源域 | IOVDD、QSPI_IOVDD、ADC_AVDD、USB_OTP_VDD、VREG_VIN 接 3.3V；三个 DVDD 接 CORE_1V1。VREG_PGND 接 GND，VREG_FB 接 CORE_1V1。 |
| 内置 buck | R101 33Ω 与 C101 4.7µF 滤波 VREG_AVDD；C102 为输入旁路，L101 3.3µH，C103 为输出电容；C124 为远端 DVDD 补充 4.7µF。拓扑符合参考。 |
| 去耦 | 电源引脚有对应 100nF；本版还将 USB_OTP_VDD 和 QSPI_IOVDD 分别去耦。位置、回流与选定电容的有效容量尚待 PCB/BOM 核验。 |
| Flash | W25Q128JVSIQ，16MB，`W25Q128JVS` 符号与 5.3×5.3mm SOIC-8 封装；pin 1/2/3/4/5/6/7/8 对应 CS/IO1/IO2/GND/IO0/CLK/IO3/3V3。C104 100nF。 |
| BOOTSEL | QSPI CS 上拉 10kΩ，按钮经 1kΩ 接地。与官方参考方式一致。 |
| 晶振 | ABM8-272-T3 12MHz，XOUT 串 1kΩ，两侧各 15pF C0G，外壳 pads 2/4 接地。实际负载电容包含走线寄生，需短线布局。 |
| RUN / SWD | RUN 使用内部上拉，按钮经 1kΩ 拉低；J101 提供 3V3 参考、SWDIO、GND、SWCLK、RUN。该 5 针顺序为项目自定义接口，调试线须按原理图配接。 |

依据：[Hardware design with RP2350，§2–5](https://pip-assets.raspberrypi.com/categories/1214-rp2350/documents/RP-008280-DS-2-hardware-design-with-rp2350.pdf)，[官方 RP2350B Minimal R4-S1 KiCad 设计](https://pip-assets.raspberrypi.com/categories/1214-rp2350/documents/RP-010329-CA-1-RP2350B%20Minimal%20KiCAD.zip)。Flash、晶振、BOOTSEL 和 RUN 均按该参考核对；这不等于固件启动配置已测试。

### AOTA 本地封装方向

`FarmMesh.pretty/AOTA-B201610S3R3-101-T.kicad_mod` 与官方 R4-S1 PCB 的 L1 逐项比较：

| 几何项 | 两者相同的局部坐标 / 尺寸（mm） |
| --- | --- |
| pad 1 | 中心 (−0.7, 0)，尺寸 0.7×1.7 |
| pad 2 | 中心 (+0.7, 0)，尺寸 0.7×1.7 |
| 丝印方向点 | 中心 (−1.4, +0.7)，半径 0.15 |
| Fab 方向点 | 中心 (−0.7, +0.55)，半径 0.10 |

焊盘层均为 F.Cu/F.Mask/F.Paste；除板级 net/UUID 属性外，相关焊盘几何一致。官方 L1 和本版 L101 均为 **pad 1 → 1V1，pad 2 → VREG_LX**，没有反向。电感无电气正负极，但此指定器件的绕组方向会影响紧凑 buck 布局；必须保留方向点，并继续遵循官方输出电容相对位置与回流布局。仅复制封装方向不足以证明整个 buck 稳定。[官方参考 KiCad](https://pip-assets.raspberrypi.com/categories/1214-rp2350/documents/RP-010329-CA-1-RP2350B%20Minimal%20KiCAD.zip)，[硬件指南 §2.1](https://pip-assets.raspberrypi.com/categories/1214-rp2350/documents/RP-008280-DS-2-hardware-design-with-rp2350.pdf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)

## USB 接口核对与边界

D101 `USBLC6-2SC6` 的 1↔6 为同一 I/O1 通路，3↔4 为同一 I/O2 通路；本版分别连接 D+ 与 D−，pin 2 接 GND，pin 5 接 USB_VBUS，方向和通道没有交叉错误。C127 100nF/16V 应放在 D101 的 VBUS 与 GND 附近，参考 ST Figure 17；这颗电容不应被当作板上任意位置的公共旁路。[ST USBLC6-2 datasheet Rev 7，功能图及 Figure 17](https://www.st.com/resource/en/datasheet/usblc6-2.pdf)

R110/R111 为 RP 侧 27Ω 串联电阻；A6/B6 同接 D+、A7/B7 同接 D−；CC1、CC2 各自使用 5.1kΩ 下拉，SBU 留空。USB4105-GF-A 对应 KiCad 的 `USB_C_Receptacle_GCT_USB4105-xx-A_16P_TopMnt_Horizontal`，库内适用型号标注明确包含该 MPN；信号 pad 名与 16 接点连接器一致。此轮核对了型号、接点与安装类型，未完成制造图机械公差逐项复核，应在 PCB 放行前核验板边、定位孔及壳体焊脚。[GCT USB4105 官方页面](https://gct.co/connector/usb4105)

本板必须由电池供电，USB VBUS 只用于检测和 ESD 保护，不能单独给系统供电或给电池充电。应用固件需要随 VBUS 控制 USB attach；**不能据此推定 ROM BOOTSEL 也会读取自定义 GPIO37**。带电 BOOTSEL、拔线、主机掉电时的数据线状态及 USBLC6 向 VBUS 的钳位电流仍需验证。当前没有硬件数据线隔离，因此不能宣称已经完成自供电 USB 合规验证。

后续 PCB 必须核验 buck 回路、选定 4.7µF 电容的 ESR/ESL/有效容量、晶振寄生、USB 90Ω 差分与 ESD 回流路径；当前原理图与封装审阅不能覆盖这些布局结果。电池 ADC 本版无采样功能，USB/PIO/PARLIO 的实测结果也尚不存在。

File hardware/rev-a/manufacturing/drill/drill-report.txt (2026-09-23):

Drill report for FarmMesh-Node.kicad_pcb
Created on 2026-09-23T15:55:58

Copper Layer Stackup:
    =============================================================
    L1 :  F.Cu                      front
    L2 :  In1.Cu                    in1
    L3 :  In2.Cu                    in2
    L4 :  B.Cu                      back

Drill file 'FarmMesh-Node-PTH.drl' contains
    plated through holes:
    =============================================================
    T1  0.200mm  0.0079"  (155 holes))
    T2  0.250mm  0.0098"  (8 holes))
    T3  0.300mm  0.0118"  (233 holes))
    T4  0.600mm  0.0236"  (4 holes)  (with 4 slots)
    T5  1.000mm  0.0394"  (25 holes))
    T6  1.700mm  0.0669"  (2 holes))

    Total plated holes count 427

Drill file 'FarmMesh-Node-NPTH.drl' contains
    unplated through holes:
    =============================================================
    T1  0.650mm  0.0256"  (2 holes))
    T2  3.200mm  0.1260"  (4 holes))

    Total unplated holes count 6

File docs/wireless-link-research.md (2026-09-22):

# Wireless link research

**Draft research notes · 2026-09-22 · no wireless route selected**

English | [简体中文](wireless-link-research.zh-CN.md) | [Project overview](../README.md)

These notes record the public interfaces and implementation evidence reviewed for the RP2350B + three ESP32-C5 architecture. ESP-NOW remains a candidate for investigation, not the selected Mesh transport. AP+STA with proxy ARP is not being pursued at present. The project's solar deployment, client-access and sensor-capacity goals remain as stated in the README; this research adds no measured performance claims or firmware implementation.

## Evidence and version scope

| Evidence | Scope | Interpretation |
| --- | --- | --- |
| Official API documentation and headers | ESP-IDF `v5.5`; C5 `stable` documentation and Espressif FAQ accessed for this review | Documented interfaces, not FarmMesh measurements; `stable` and `latest` can change |
| Current header snapshot | ESP-IDF `master` at `422c4f5925d9a2408d5ddcc5bb1a95cc46da1e3d` | Source declarations only; not a selected or tested release |
| C5 binary inspection | `esp32-wifi-lib` commit `8a1b7bbc00e895d040c5c9a6fb9d1db2bbfc7958`, referenced by the ESP-IDF `v5.5` gitlink | Static symbol/relocation evidence for this archive only |
| MTU calculations and future adaptation | Derived constraints and possible future software work | Neither implemented nor validated on this project |

The [v5.5 C5 ESP-NOW page](https://docs.espressif.com/projects/esp-idf/en/v5.5/esp32c5/api-reference/network/esp_now.html) warns that some content has not yet been updated for C5. Packet-format statements are cross-checked with the [official FAQ](https://docs.espressif.com/projects/esp-faq/en/latest/application-solution/esp-now.html) and [v5.5 ESP-NOW header](https://github.com/espressif/esp-idf/blob/v5.5/components/esp_wifi/include/esp_now.h). Freeze the actual SDK and verify target-specific behavior before implementation.

## Capability and constraint summary

| Topic | Finding | Evidence / status |
| --- | --- | --- |
| WDS / four-address transparent bridging | No directly enabled public C5 mode confirmed in the reviewed ESP-IDF documentation/API | Public support unconfirmed; not proof of silicon impossibility |
| ESP-NOW transport | Vendor-specific 802.11 Action frames; no IP/UDP envelope required | Officially documented; candidate only |
| ESP-NOW application payload | v1: up to 250 B; v2: up to 1470 B | Officially documented; receiver must support the transmitted version and payload size |
| Public raw transmission | `esp_wifi_80211_tx()` accepts a 24–1500 B raw buffer, including the 802.11 MAC header | API limit, not application payload or IP MTU |
| Rate configuration | `esp_now_set_peer_rate_config()` exposes per-peer PHY/rate configuration | Public interface; configured PHY rate is not effective throughput |
| Automatic rate adaptation | No ready-to-enable public ESP-NOW switch or official ready-made tool confirmed in this review | A custom adaptation policy would be future software work |
| Transmit power | `esp_wifi_set_max_tx_power()` sets a Wi-Fi power ceiling on each C5 | Device-wide limit, not independent per-peer/per-packet power |
| Sustained ESP-NOW / public raw throughput on C5 | Maximum effective throughput has not been established here | No project benchmark; no evidence of this route meeting the 50 Mbps access goal |
| AP+STA + proxy ARP | Considered briefly; currently not pursued | Project preference, not a finding of technical impossibility |

## Transparent bridging and public raw transmission

The [C5 Wi-Fi driver guide](https://docs.espressif.com/projects/esp-idf/en/v5.5/esp32c5/api-guides/wifi.html) and reviewed public headers do not establish a supported, directly enabled WDS/four-address transparent bridge. Ordinary AP+STA operation does not automatically preserve downstream clients' MAC addresses through a transparent Layer 2 bridge. Raw frame injection alone does not provide a complete four-address encrypted bridging implementation.

The [v5.5 raw-send API contract](https://github.com/espressif/esp-idf/blob/v5.5/components/esp_wifi/include/esp_wifi.h#L1178-L1203) specifies a buffer length of 24–1500 B. That buffer includes the 802.11 MAC header; it is not a 1500 B application payload or IP MTU. The [C5 packet-send documentation](https://docs.espressif.com/projects/esp-idf/en/stable/esp32c5/api-guides/wifi-driver/wifi-vendor-features.html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) lists beacon, probe request/response, Action and non-QoS data frames, and excludes encrypted and QoS frames on this public raw path. These limits do not describe every internal driver transmission path.

AP+STA with proxy ARP remains outside the current route. For completeness, IPv4 proxy ARP would still need actual IP forwarding and return-path routing; ARP replies alone do not create transparent Layer 2 forwarding. DHCP, broadcast handling and IPv6 would require separate treatment. [RFC 1027](https://datatracker.ietf.org/doc/html/rfc1027) is background, not an adopted FarmMesh design.

## ESP-NOW framing and versioned implementation evidence

ESP-NOW carries application data in vendor-specific 802.11 Action frames without requiring IP or UDP. Its v2 format chains multiple vendor-specific information elements within an Action frame to carry up to 1470 B; this is not fragmentation into independent v1 packets. v1 supports up to 250 B. Mixed-version reception is conditional, so both endpoints' version and payload-receive capabilities must be checked. See the [official ESP-NOW FAQ](https://docs.espressif.com/projects/esp-faq/en/latest/application-solution/esp-now.html).

The 1470 B ESP-NOW v2 application limit and 1500 B public raw-buffer limit measure different layers. Comparing them directly does not compare usable application payloads or throughput.

Static inspection of the [C5 `libespnow.a` archive](https://github.com/espressif/esp32-wifi-lib/blob/8a1b7bbc00e895d040c5c9a6fb9d1db2bbfc7958/esp32c5/libespnow.a), selected by the [ESP-IDF v5.5 Wi-Fi library gitlink](https://github.com/espressif/esp-idf/tree/v5.5/components/esp_wifi), found this direct call chain:

```text
esp_now_send -> mt_send -> ieee80211_send_action_vendor_spec
```

| Object / section | Relocation offset | Call target |
| --- | --- | --- |
| `espnow.o` / `.text.esp_now_send` | `0xe8`, `0x15e` | `mt_send` |
| `manatick.o` / `.text.mt_send` | `0xf8` | `ieee80211_send_action_vendor_spec` |

The inspected archive is 63,178 B, Git blob SHA `1bf0d49f4b910475577058a291c50ac83cb86392`. Its symbol table has no reference to `esp_wifi_80211_tx`. Thus the observed call segment does not go through that public API. These internal symbols are not stable interfaces, and this observation does not rule out shared code deeper in the driver or in other versions. It is not a runtime or throughput test.

With this exact archive and an ESP RISC-V toolchain, the relevant inspection can be repeated with:

```sh
git hash-object libespnow.a
riscv32-esp-elf-objdump -r -j .text.esp_now_send -j .text.mt_send libespnow.a
riscv32-esp-elf-nm -A libespnow.a | rg 'esp_now_send|mt_send|ieee80211_send_action_vendor_spec|esp_wifi_80211_tx'
```

## MTU, TCP MSS and UDP boundaries

If a custom link puts one IP packet in one ESP-NOW v2 payload without link fragmentation/reassembly, its maximum IP MTU is **M = 1470 − H bytes**. Here **H** is all custom encapsulation outside the IP packet, including any retained Ethernet header or tags. A chosen operating MTU can be smaller, and the rest of the path may impose a smaller limit. This is a size budget, not a selected encapsulation or throughput prediction.

| Quantity | Budget from effective MTU M | Assumptions |
| --- | --- | --- |
| IPv4 TCP MSS | M − 40 | Fixed 20 B IPv4 and 20 B TCP headers |
| IPv6 TCP MSS | M − 60 | Fixed 40 B IPv6 and 20 B TCP headers |
| IPv4 UDP application payload | M − 28 | No IPv4 options; 8 B UDP header |
| IPv6 UDP application payload | M − 48 | No IPv6 extension headers; 8 B UDP header |

TCP's advertised MSS calculation uses fixed headers; the sender must further reduce actual TCP data to accommodate options or extension headers. [RFC 6691](https://www.rfc-editor.org/rfc/rfc6691.html) explains this distinction. UDP has no MSS: clamping TCP MSS does not solve oversized UDP datagrams, and changing an intermediate node's MTU alone does not ensure that a terminal reduces its UDP messages. Packet sizing/path-MTU handling still matters. [RFC 8085, section 3.2](https://www.rfc-editor.org/rfc/rfc8085.html#section-3.2)

A custom link fragmentation/reassembly layer could preserve a larger upper-layer MTU, but no such scheme is selected or implemented. Any eventual IPv6 link design must also respect the 1280 B minimum link MTU and provide adaptation below IPv6 if necessary. [RFC 8200, section 5](https://www.rfc-editor.org/rfc/rfc8200.html#section-5)

## Rate, power and possible future adaptation

The reviewed [`esp_now_set_peer_rate_config()` declaration](https://github.com/espressif/esp-idf/blob/422c4f5925d9a2408d5ddcc5bb1a95cc46da1e3d/components/esp_wifi/include/esp_now.h) accepts per-peer rate settings. Its [`wifi_tx_rate_config_t` definition](https://github.com/espressif/esp-idf/blob/422c4f5925d9a2408d5ddcc5bb1a95cc46da1e3d/components/esp_wifi/include/esp_wifi_types_generic.h) contains `phymode`, `rate`, `ersu` and `dcm`. Target, peer and SDK support must be checked; configuring a PHY rate is not a guarantee of payload throughput. Neither advertised chip PHY rates nor ordinary Wi-Fi TCP benchmarks establish sustained ESP-NOW or public raw-path performance.

The [Wi-Fi power API](https://github.com/espressif/esp-idf/blob/v5.5/components/esp_wifi/include/esp_wifi.h) sets a maximum transmit-power ceiling per C5, not per peer or per packet. Each of the three C5 chips can have its own ceiling. Its 0.25 dBm argument unit does not imply continuously available 0.25 dB hardware steps, nor that every transmitted frame uses that power. This review does not infer exact C5 maxima across bands from a generic header.

In the reviewed official documentation, FAQ and public headers, no ready-to-enable ESP-NOW automatic rate-adaptation switch or ready-made official tool was confirmed. The per-peer setter supplies control, not an automatic selection algorithm. This does not prove that all internal adaptation logic is absent. If the project later needs custom adaptation, a possible software policy would track per-peer success and transmission time, probe higher rates and reduce rates after failures, using RSSI as supporting information. This is unimplemented, unvalidated future work, not a chosen algorithm or a current capability.

## Hardware continuity and remaining decisions

The internal interface candidate remains unchanged: three independent PARLIO ↔ PIO links, separate 4-bit TX/RX buses, and both clocks supplied by each corresponding C5. Each direction uses 4 DATA + CLK + VALID: 12 signals per link, 36 total against RP2350B's 48 Bank0 GPIOs. That is a resource estimate, not firmware or timing validation. Sharing a half-duplex data bus would require explicit output-enable, tri-state and direction-change control. See the [internal-interface draft](../README.md#candidate-internal-interface).

Wireless route selection, the SDK baseline, encapsulation/fragmentation choices, required rate-control behavior and actual effective throughput remain open. This record supports hardware discussion; it does not start firmware implementation or alter the existing product targets.

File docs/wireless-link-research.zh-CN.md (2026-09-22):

# 无线链路研究

**研究草案 · 2026-09-22 · 尚未选定无线技术路线**

[English](wireless-link-research.md) | 简体中文 | [项目概览](../README.zh-CN.md)

本文记录针对 RP2350B + 三颗 ESP32-C5 架构所核查的公开接口及实现证据。ESP-NOW 仍是待研究的候选，并非已选定的 Mesh 传输方案。当前不推进 AP+STA 配合 proxy ARP 的路线。项目的太阳能部署、客户端接入和传感器容量目标仍以 README 为准；本次研究不新增实测性能结论或固件实现。

## 证据与版本范围

| 证据 | 范围 | 解读边界 |
| --- | --- | --- |
| 官方 API 文档与头文件 | ESP-IDF `v5.5`；本次核查访问的 C5 `stable` 文档及 Espressif FAQ | 已文档化接口，不是 FarmMesh 实测结果；`stable` 与 `latest` 内容可能变化 |
| 当前头文件快照 | ESP-IDF `master`，提交 `422c4f5925d9a2408d5ddcc5bb1a95cc46da1e3d` | 仅为源码声明；不是项目已选定或测试过的发布版本 |
| C5 二进制检查 | ESP-IDF `v5.5` gitlink 引用的 `esp32-wifi-lib` 提交 `8a1b7bbc00e895d040c5c9a6fb9d1db2bbfc7958` | 仅针对该静态库的符号与重定位证据 |
| MTU 计算与后续自适应 | 推导约束及可能的后续软件工作 | 本项目均尚未实现或验证 |

[v5.5 C5 ESP-NOW 页面](https://docs.espressif.com/projects/esp-idf/en/v5.5/esp32c5/api-reference/network/esp_now.html)提示，部分内容尚未针对 C5 更新。帧格式结论已与[官方 FAQ](https://docs.espressif.com/projects/esp-faq/en/latest/application-solution/esp-now.html)和 [v5.5 ESP-NOW 头文件](https://github.com/espressif/esp-idf/blob/v5.5/components/esp_wifi/include/esp_now.h)交叉核对。实施前仍需冻结实际 SDK 版本并确认目标芯片的具体行为。

## 能力与约束概览

| 项目 | 核查结果 | 证据 / 状态 |
| --- | --- | --- |
| WDS / 四地址透明桥接 | 在已核查的 ESP-IDF 文档/API 中，未确认 C5 有可直接启用的公开模式 | 公开支持尚未确认；不能据此断言芯片不可能实现 |
| ESP-NOW 传输 | 使用厂商特定的 802.11 Action 帧；无需 IP/UDP 封装 | 官方已文档化；仅为候选 |
| ESP-NOW 应用载荷 | v1：最多 250 B；v2：最多 1470 B | 官方已文档化；接收端需支持所发送的版本与载荷长度 |
| 公开 raw 发送接口 | `esp_wifi_80211_tx()` 接受 24–1500 B 的原始缓冲区，包含 802.11 MAC 头 | API 长度限制，不是应用载荷或 IP MTU |
| 速率配置 | `esp_now_set_peer_rate_config()` 提供按 peer 配置 PHY/速率的接口 | 公开接口；配置的 PHY 速率不等于有效吞吐 |
| 自动速率自适应 | 本次核查未确认 ESP-NOW 有可直接启用的公开开关或现成官方工具 | 自定义自适应策略属于后续软件工作 |
| 发射功率 | `esp_wifi_set_max_tx_power()` 设置每颗 C5 的 Wi-Fi 功率上限 | 设备级上限，不是按 peer/按包独立设置功率 |
| C5 的 ESP-NOW / 公开 raw 路径持续吞吐 | 本次尚未确定其最大有效吞吐 | 本项目无基准测试；没有证据表明该路线已达到 50 Mbps 接入目标 |
| AP+STA + proxy ARP | 曾短暂考虑；当前不推进 | 项目路线偏好，并非认定技术上不可行 |

## 透明桥接与公开 raw 发送接口

[C5 Wi-Fi 驱动指南](https://docs.espressif.com/projects/esp-idf/en/v5.5/esp32c5/api-guides/wifi.html)及已核查的公开头文件，尚不能确认存在受支持、可直接启用的 WDS/四地址透明桥接模式。普通 AP+STA 运行方式不会自动通过透明二层桥接保留下游客户端的 MAC 地址。仅有原始帧注入能力，也不等于具备完整的四地址加密桥接实现。

[v5.5 raw 发送 API 约定](https://github.com/espressif/esp-idf/blob/v5.5/components/esp_wifi/include/esp_wifi.h#L1178-L1203)规定缓冲区长度为 24–1500 B。该缓冲区包含 802.11 MAC 头，并非 1500 B 的应用载荷或 IP MTU。[C5 帧发送文档](https://docs.espressif.com/projects/esp-idf/en/stable/esp32c5/api-guides/wifi-driver/wifi-vendor-features.html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)列出 beacon、probe request/response、Action 和非 QoS data 帧，并说明这条公开 raw 路径不支持加密帧及 QoS 帧。这些限制不代表驱动内部所有发送路径的能力。

AP+STA 配合 proxy ARP 不属于当前推进的路线。为完整记录，IPv4 proxy ARP 仍需配合实际 IP 转发和回程路由；仅回复 ARP 并不能形成透明二层转发。DHCP、广播处理及 IPv6 还需分别处理。[RFC 1027](https://datatracker.ietf.org/doc/html/rfc1027)仅作为背景资料，并非已采用的 FarmMesh 设计。

## ESP-NOW 帧格式与特定版本实现证据

ESP-NOW 通过厂商特定的 802.11 Action 帧承载应用数据，无需 IP 或 UDP。v2 格式在一个 Action 帧内串联多个厂商特定信息元素，承载最多 1470 B；这不等同于分片为多个独立的 v1 包。v1 最多支持 250 B。混合版本的接收存在条件限制，因此需核对两端版本和载荷接收能力。参见[官方 ESP-NOW FAQ](https://docs.espressif.com/projects/esp-faq/en/latest/application-solution/esp-now.html)。

ESP-NOW v2 的 1470 B 应用载荷上限与公开 raw 接口的 1500 B 缓冲区上限，计量的是不同层级。直接比较两者不能得出可用应用载荷或吞吐的比较结果。

对 [ESP-IDF v5.5 Wi-Fi 库 gitlink](https://github.com/espressif/esp-idf/tree/v5.5/components/esp_wifi)所选定的 [C5 `libespnow.a` 静态库](https://github.com/espressif/esp32-wifi-lib/blob/8a1b7bbc00e895d040c5c9a6fb9d1db2bbfc7958/esp32c5/libespnow.a)进行静态检查，发现以下直接调用链：

```text
esp_now_send -> mt_send -> ieee80211_send_action_vendor_spec
```

| 目标文件 / 节 | 重定位偏移 | 调用目标 |
| --- | --- | --- |
| `espnow.o` / `.text.esp_now_send` | `0xe8`、`0x15e` | `mt_send` |
| `manatick.o` / `.text.mt_send` | `0xf8` | `ieee80211_send_action_vendor_spec` |

被检查静态库的大小为 63,178 B，Git blob SHA 为 `1bf0d49f4b910475577058a291c50ac83cb86392`。其符号表没有对 `esp_wifi_80211_tx` 的引用，因此观察到的这一段调用路径不经过该公开 API。这些内部符号不是稳定接口；该观察也不排除驱动更深层或其他版本共用代码的可能性。这不是运行时测试或吞吐测试。

使用上述确切版本的静态库及 ESP RISC-V 工具链，可通过以下命令复核相关证据：

```sh
git hash-object libespnow.a
riscv32-esp-elf-objdump -r -j .text.esp_now_send -j .text.mt_send libespnow.a
riscv32-esp-elf-nm -A libespnow.a | rg 'esp_now_send|mt_send|ieee80211_send_action_vendor_spec|esp_wifi_80211_tx'
```

## MTU、TCP MSS 与 UDP 边界

若自定义链路将一个 IP 包放入一个 ESP-NOW v2 载荷，且不进行链路分片/重组，则其最大 IP MTU 为 **M = 1470 − H 字节**。其中 **H** 是 IP 包之外的全部自定义封装开销，包括任何保留的 Ethernet 头或标签。实际选用的 MTU 可以更小，路径上其他环节也可能施加更小的限制。这是长度预算，并非已选定的封装方案或吞吐预测。

| 项目 | 基于有效 MTU M 的预算 | 前提 |
| --- | --- | --- |
| IPv4 TCP MSS | M − 40 | 固定 20 B IPv4 头和 20 B TCP 头 |
| IPv6 TCP MSS | M − 60 | 固定 40 B IPv6 头和 20 B TCP 头 |
| IPv4 UDP 应用载荷 | M − 28 | 无 IPv4 options；UDP 头为 8 B |
| IPv6 UDP 应用载荷 | M − 48 | 无 IPv6 扩展头；UDP 头为 8 B |

TCP 通告的 MSS 按固定头部计算；发送方仍需进一步减少实际 TCP 数据长度，为 options 或扩展头留出空间。[RFC 6691](https://www.rfc-editor.org/rfc/rfc6691.html)说明了这一区别。UDP 没有 MSS：限制 TCP MSS 不能解决过大的 UDP 数据报，而仅修改中间节点的 MTU，也不能保证终端自动减小其 UDP 报文。仍需处理报文长度及路径 MTU。[RFC 8085 第 3.2 节](https://www.rfc-editor.org/rfc/rfc8085.html#section-3.2)

自定义链路分片/重组层可以保留较大的上层 MTU，但目前尚未选定或实现此类方案。未来若设计 IPv6 链路，还必须满足 1280 B 的最小链路 MTU 要求，并在必要时于 IPv6 之下提供适配。[RFC 8200 第 5 节](https://www.rfc-editor.org/rfc/rfc8200.html#section-5)

## 速率、功率与可能的后续自适应

已核查的 [`esp_now_set_peer_rate_config()` 声明](https://github.com/espressif/esp-idf/blob/422c4f5925d9a2408d5ddcc5bb1a95cc46da1e3d/components/esp_wifi/include/esp_now.h)接受按 peer 设置的速率配置，其 [`wifi_tx_rate_config_t` 定义](https://github.com/espressif/esp-idf/blob/422c4f5925d9a2408d5ddcc5bb1a95cc46da1e3d/components/esp_wifi/include/esp_wifi_types_generic.h)包含 `phymode`、`rate`、`ersu` 和 `dcm`。仍需确认目标芯片、对端和 SDK 的支持情况；设置 PHY 速率不保证应用载荷吞吐。芯片标称 PHY 速率和普通 Wi-Fi TCP 基准测试，都不能证明 ESP-NOW 或公开 raw 路径的持续性能。

[Wi-Fi 功率 API](https://github.com/espressif/esp-idf/blob/v5.5/components/esp_wifi/include/esp_wifi.h)设置每颗 C5 的最大发射功率上限，并非按 peer 或按包设置。三颗 C5 可以各自设置上限。参数单位为 0.25 dBm，并不意味着硬件具有连续可用的 0.25 dB 档位，也不意味着每帧都以该功率发射。本次核查不根据通用头文件推断 C5 在各频段的精确最大功率。

在已核查的官方文档、FAQ 和公开头文件中，尚未确认存在可直接启用的 ESP-NOW 自动速率自适应开关或现成官方工具。按 peer 的设置接口提供控制能力，并不等于自动选择算法。这也不能证明所有内部自适应逻辑均不存在。若项目后续需要自定义自适应，一种可能的软件策略是跟踪每个 peer 的发送成功率与耗时、探测更高速率并在失败后降速，同时以 RSSI 作为辅助信息。这属于尚未实现、尚未验证的后续工作，并非已选算法或当前能力。

## 硬件方案延续与待决事项

内部接口候选保持不变：三条独立的 PARLIO ↔ PIO 链路，TX/RX 各使用独立的 4 位数据总线，两个方向的时钟均由对应 C5 提供。每个方向使用 4 DATA + CLK + VALID，即每条链路 12 根信号、三条共 36 根，对照 RP2350B 的 48 个 Bank0 GPIO。这只是资源估算，并非固件或时序验证。共享半双工数据总线需要明确的输出使能、三态及换向控制。参见[内部接口草案](../README.zh-CN.md#候选内部接口)。

无线技术路线、SDK 基线、封装/分片选择、所需速率控制行为及实际有效吞吐仍待确定。本记录用于支持硬件讨论，不启动固件实现，也不改变已有产品目标。

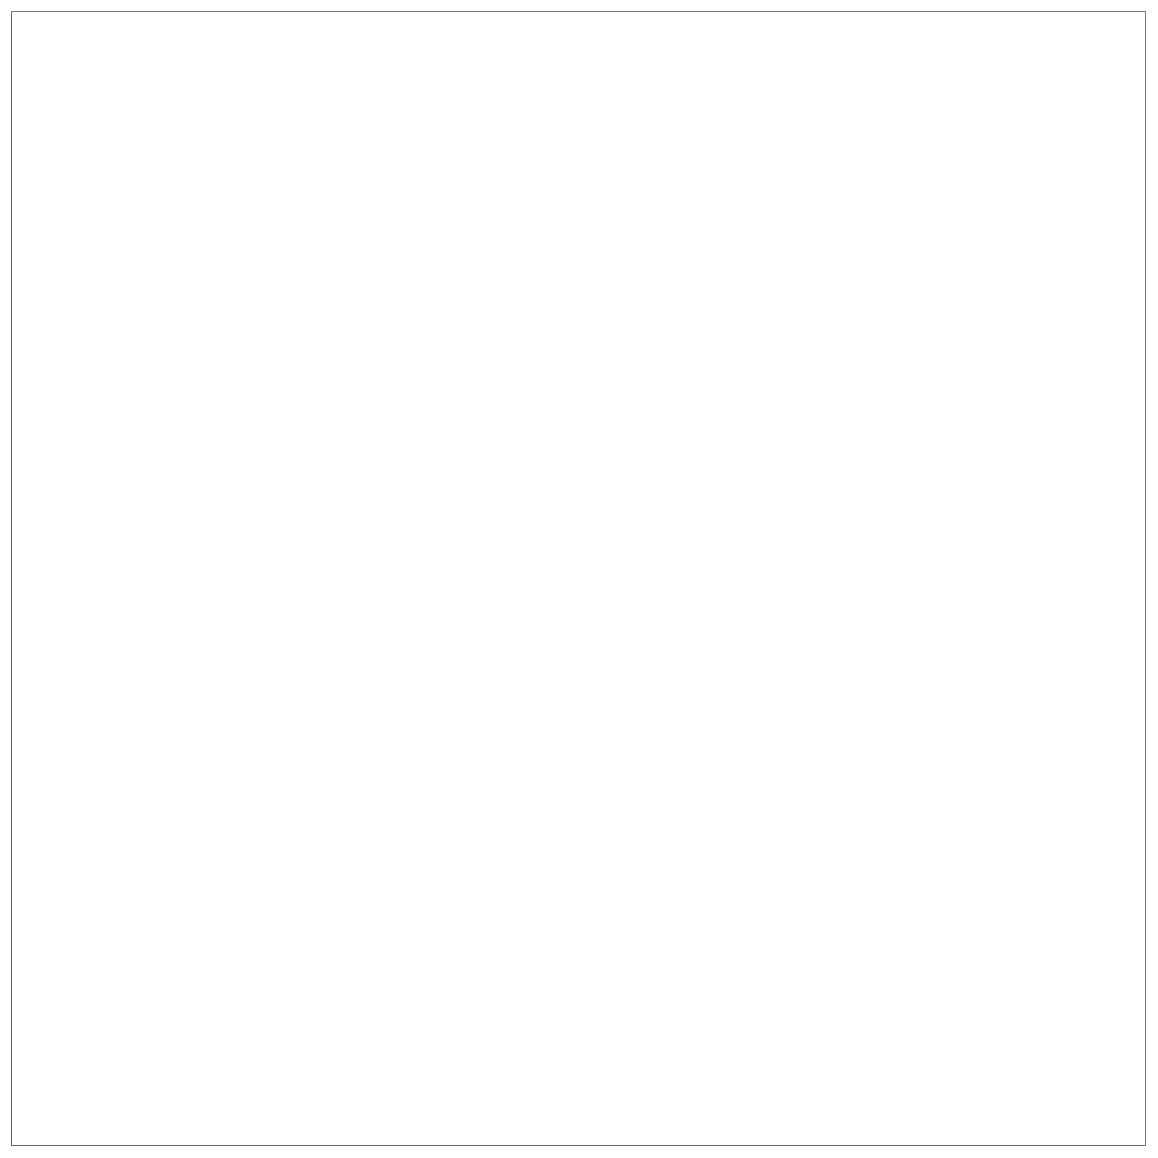
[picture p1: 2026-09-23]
hardware/rev-a/review/gerber/Edge_Cuts.png

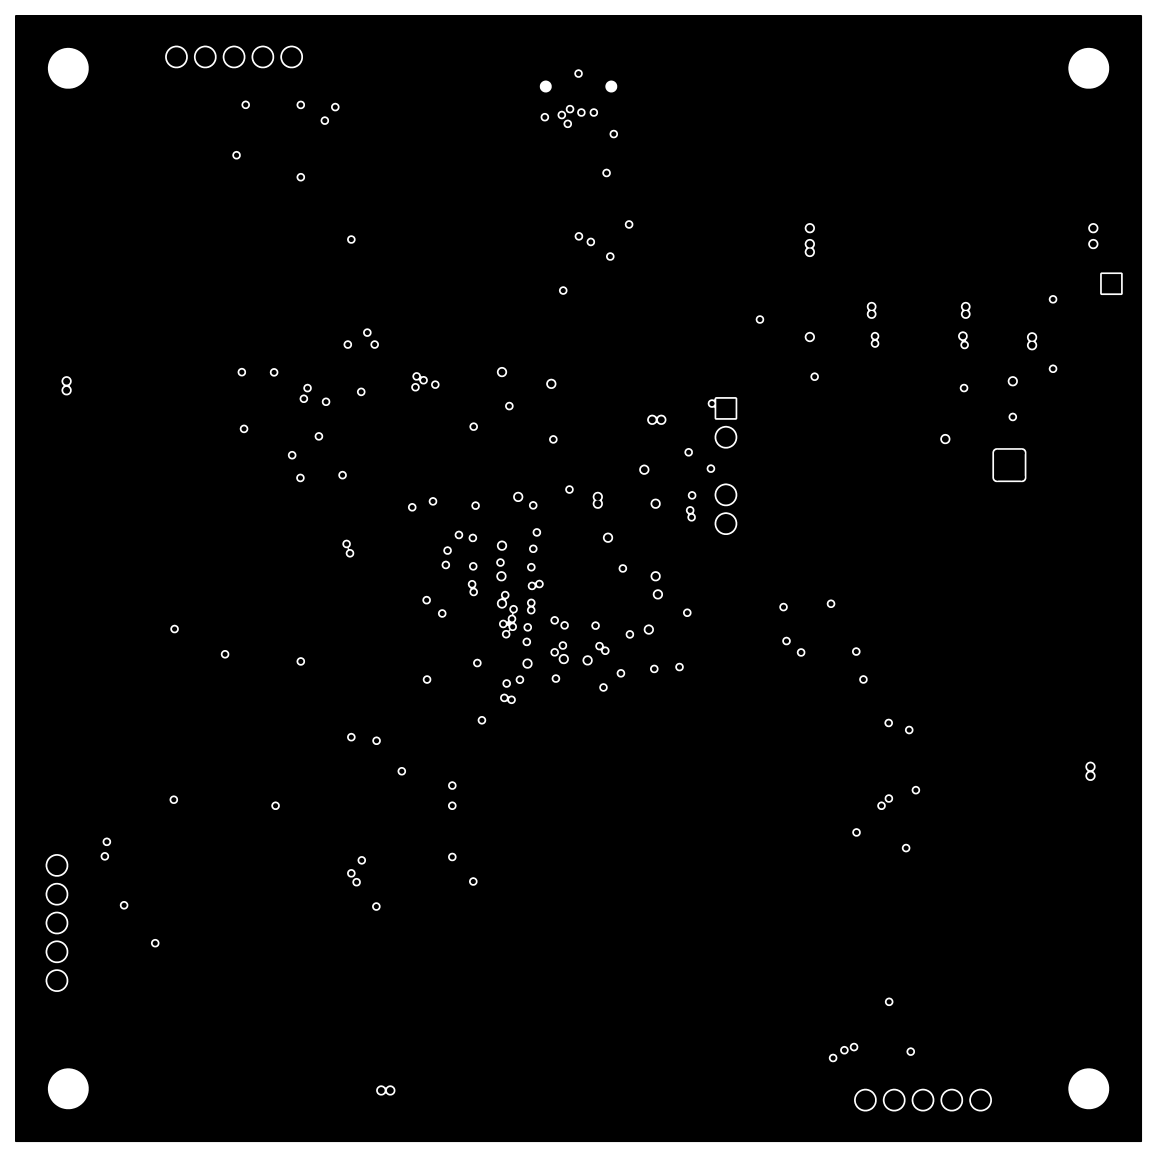
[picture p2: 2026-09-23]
hardware/rev-a/review/gerber/In2_Cu.png

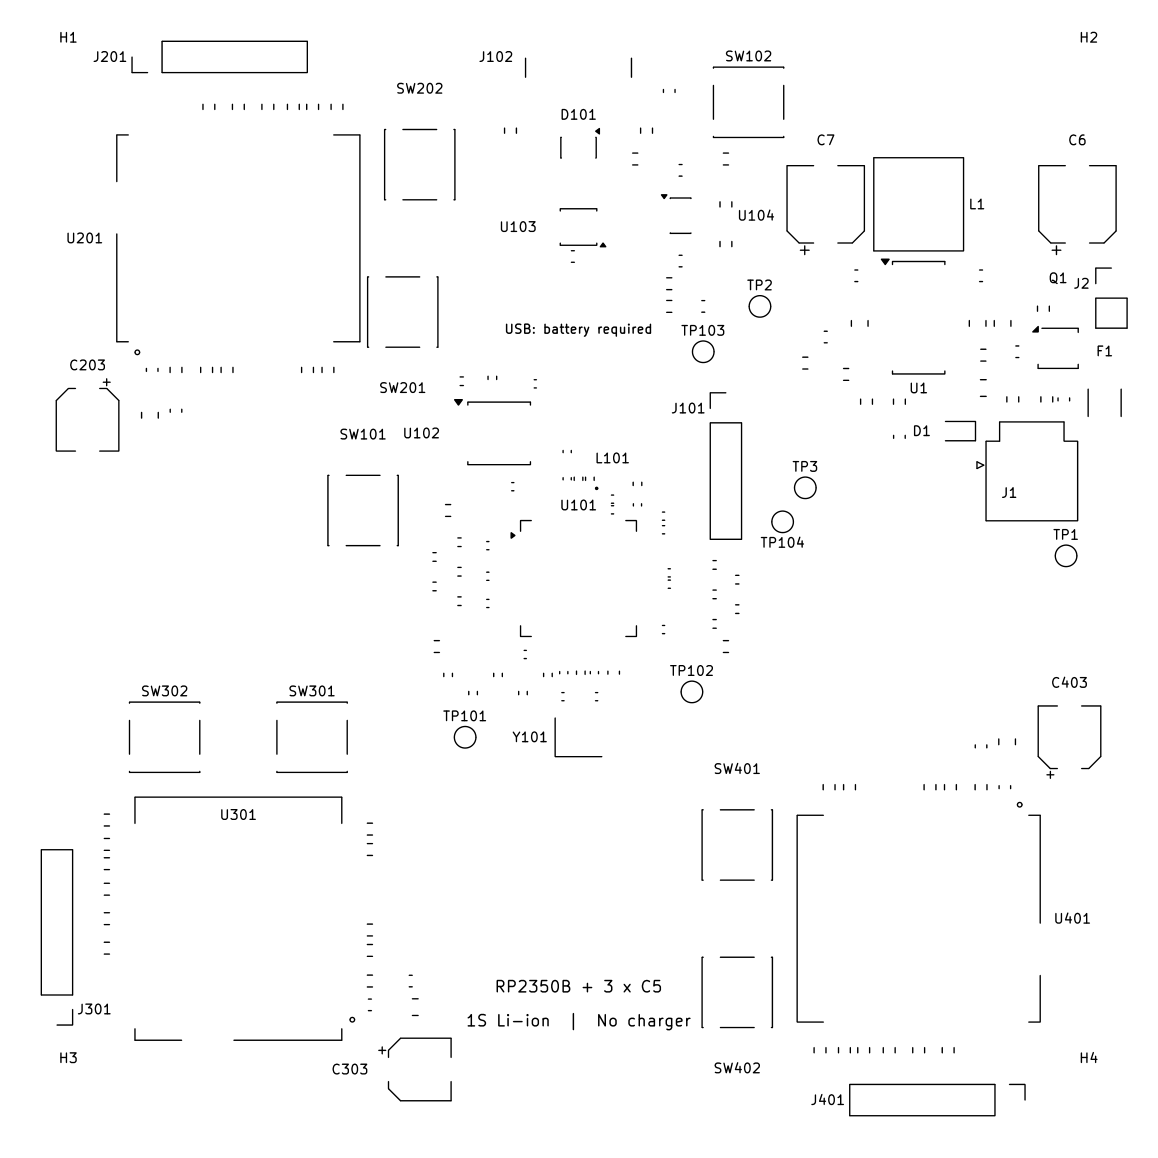
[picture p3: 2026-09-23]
hardware/rev-a/review/gerber/F_Silkscreen.png

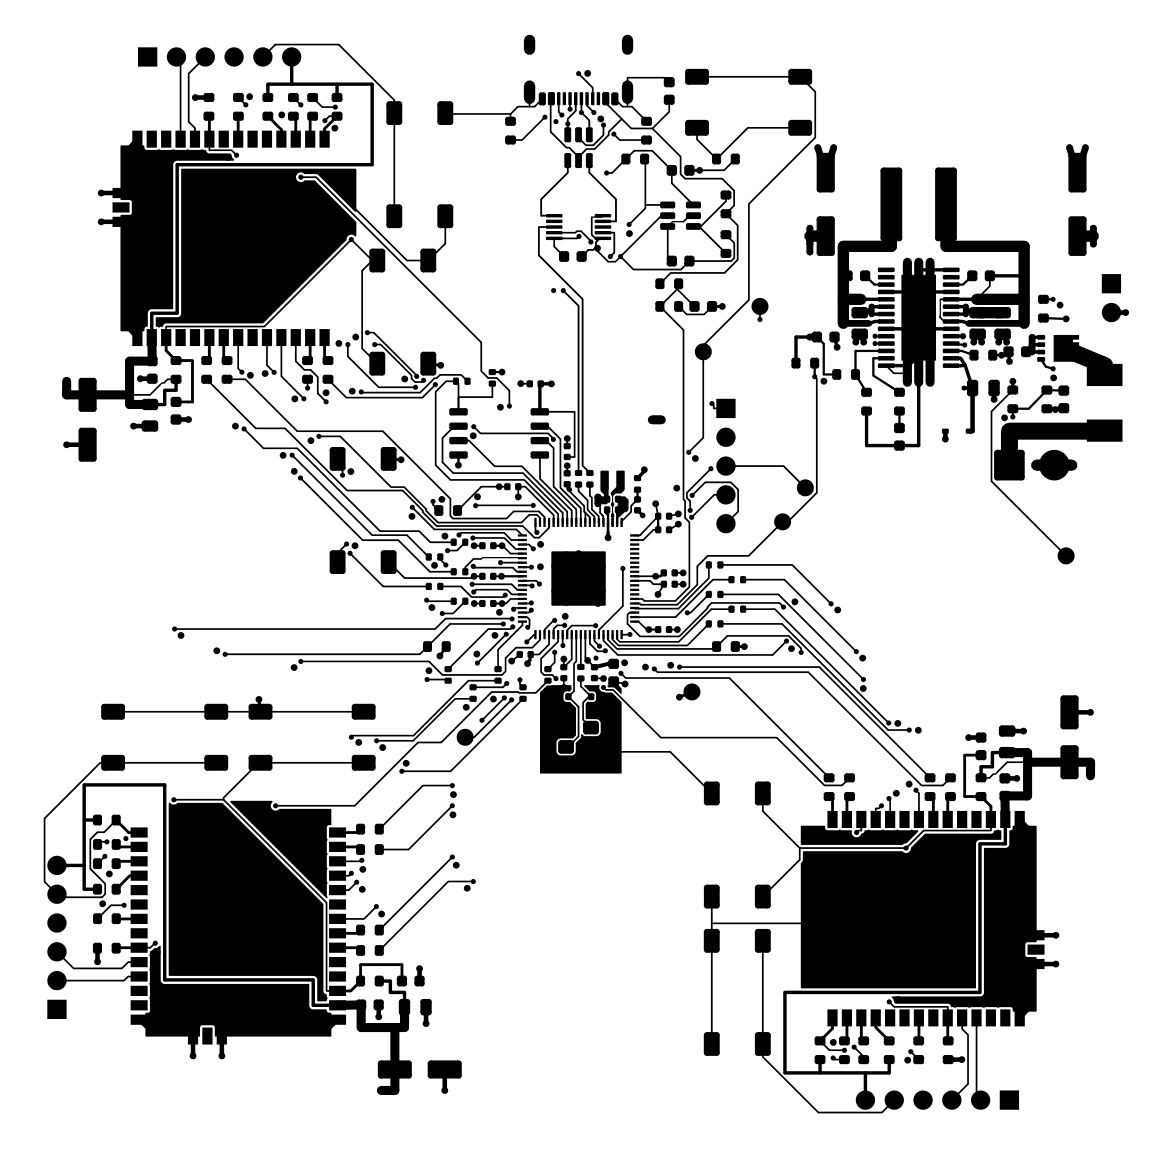
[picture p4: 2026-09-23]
hardware/rev-a/review/gerber/F_Cu.png

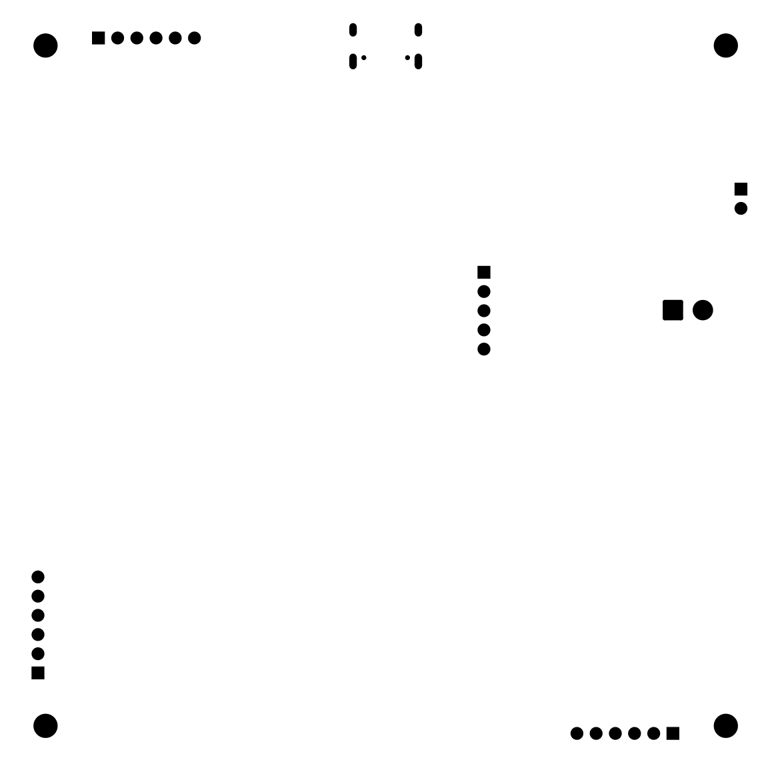
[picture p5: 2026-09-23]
hardware/rev-a/review/gerber/B_Mask.png

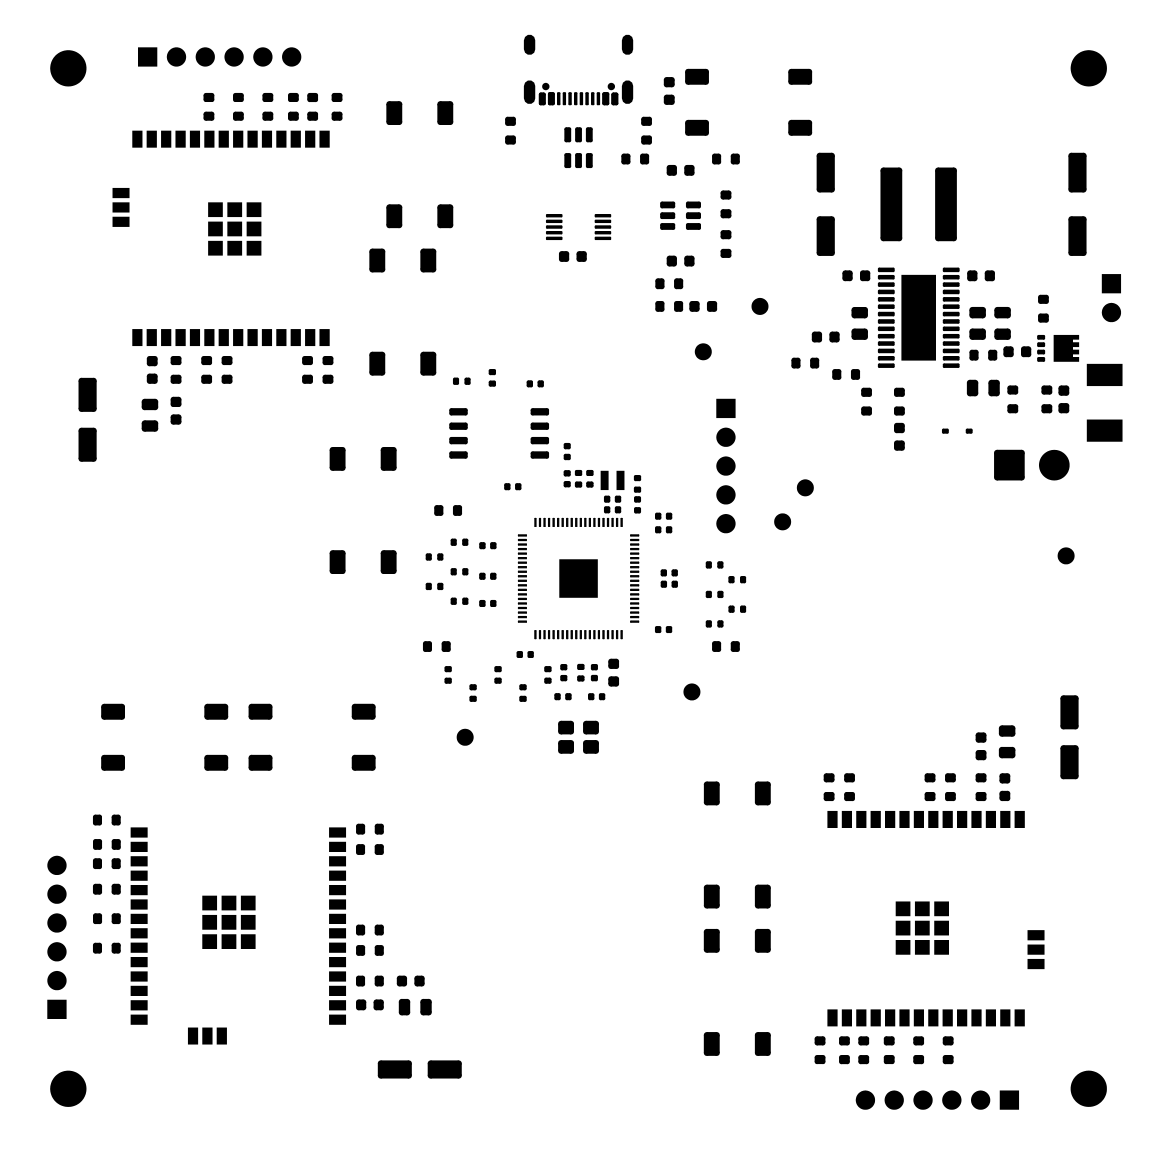
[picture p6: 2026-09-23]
hardware/rev-a/review/gerber/F_Mask.png

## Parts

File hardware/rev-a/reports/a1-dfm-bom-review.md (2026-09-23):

# A1 BOM 与 DFM 独立审阅

日期：2026-09-23。**最终 BOM / DFM 静态审阅：PASS，可受控工程原型投样。** 范围包括确切选料、官方器件资料、JLCPCB 工艺基线、最终原生板和实际导出的 Gerber、钻孔、BOM、坐标及源文件哈希闭包。结论绑定 PCB SHA256 `94b96a96ef75f9561a9c2552ea9e2db2f6d1eb0fe6a99cec8e6313b0ac1b4ab9`；后续原生源或制造几何变化须重新核验。本报告不把静态审阅或 ERC/DRC 通过等同于电源、USB、无线性能或装配良率实测。

## 已落实的选料

`parts-selection.json` 覆盖 **153 个装配器件**（原 145 个加 USB 隔离电路 8 个）以及 **11 个裸板制造特征**；每个位号都有 MPN、厂商、封装、来源和说明。5 个电源标志不属于实物。TP1/2/3/101/102/103/104 和 H1–H4 使用 `PCB_FEATURE_NOT_PURCHASED`、`purchasable=false`，不是待定采购件。所有指定封装都在本地 KiCad 库或 FarmMesh.pretty 中存在。

RP2350 buck 的 C101/102/103、R101，晶振 C105/106，以及 100 nF 的 C104/C110–C123 采用 [Raspberry Pi RP2350B R4-S1 官方参考 BOM](https://pip-assets.raspberrypi.com/categories/1214-rp2350/documents/RP-010329-CA-1-RP2350B%20Minimal%20KiCAD.zip) 的具体 0402 料号。R102/103/105、两只 USB 27 Ω 和 RP2350 源端的 15 只 22 Ω 也改为 0402；各 C5 源端 7 只串阻仍为 0603。这是布线尺寸变化，不改变电阻值。

新增 U103=`TS3USB30EDGSR`、U104=`TLV3011BIDBVR`，以及 C128/129/130、R114/115/116 已定料；两只阈值分压电阻为 Yageo RT 0.1%、25 ppm/°C。U104 的 **B** 版本不可换为老 TLV3011。普通 0603 100 nF/10 nF 改用有当前官方单件规格页的 KEMET `C0603C104K5RACTU` / `C0603C103K5RACTU`；RP 官方 0402 电容保持 Murata 原选型。[TI comparator datasheet](https://www.ti.com/lit/ds/symlink/tlv3011.pdf)、[Yageo 100 kΩ 单件规格](https://www.yageogroup.com/component-documentation/download/specsheet/RT0603BRD07100KL)、[KEMET 100 nF](https://search.kemet.com/component-documentation/download/specsheet/C0603C104K5RACTU)。

## 电容选型与有效容量边界

| 位号 | 确切选型 | 关键额定值与封装 | 结论 |
| --- | --- | --- | --- |
| C6 | Panasonic 10SVPC120M | 120 µF ±20%，10 V，聚合物；27 mΩ；2.32 Arms；φ6.3 × 5.9 mm | 原 100 µF 改为 120 µF，值及 footprint 必须同步 |
| C7 | Panasonic 6SVPE220M | 220 µF ±20%，6.3 V，聚合物；10 mΩ；3.90 Arms；φ6.3 × 5.9 mm | 保留；注意不能套用其他 SVP/SVPC 系列 ESR |
| C203/303/403 | Panasonic 6SVPC100M | 100 µF ±20%，6.3 V，聚合物；30 mΩ；1.97 Arms；φ5.0 × 5.9 mm | 原泛用 φ6.3 footprint 改为 CP_Elec_5x5.9 |
| C3/4/8/201/301/401 | Murata GRM21BZ71A226ME15L | 22 µF ±20%，10 V，X7R(MURATA) Z7，0805 | 官方典型：3.3 V 时 14.29 µF、4.2 V 时 11.79 µF；条件和边界见下 |
| C11 | Murata GRM21BR71A475KA73L | 4.7 µF ±10%，10 V，X7R，0805 | LTC3119 VCC 陶瓷旁路；须短回路 |
| C101/102/103 | Murata GRM155R60J475ME47D | 4.7 µF ±20%，6.3 V，X5R，0402 | 精确复用 RP 官方 buck 选型和局部布局 |
| C124 | Murata GRM188R60J475KE19D | 4.7 µF ±10%，6.3 V，X5R，0603 | CORE 额外局部储能，不替代 C103 |
| C204/304/404 | Murata GRM188R71C105KA12D | 1 µF ±10%，16 V，X7R，0603 | EN 延时名义 10 ms，启动波形仍须测量 |
| C10/C12/C130 | KEMET C0603C821/471/102J5GACTU | 分别 820 pF/470 pF/1 nF，±5%，50 V，C0G，0603 | 补偿及参考旁路使用稳定介质 |

聚合物 ESR 表中数值为厂家 100 kHz 指标，纹波电流为 100 kHz、105°C 额定条件，不能直接视为任意频率、任何 PCB 散热条件下的能力。来源：[10SVPC120M](https://industrial.panasonic.com/ww/products/pt/os-con/models/10SVPC120M)、[6SVPE220M](https://industrial.panasonic.com/ww/products/pt/os-con/models/6SVPE220M)、[6SVPC100M](https://industrial.panasonic.com/ww/products/pt/os-con/models/6SVPC100M)。初始名义容量仅计 −20% 公差时，C6 为 96 µF，C7 为 176 µF，每只无线储能为 80 µF；这些数字不是全温、寿命后的系统有效电容保证。

已取得 [Murata 官方 SimSurfing](https://ds.murata.com/simsurfing/mlcc.html?lcid=en-us) 对精确电气料号 `GRM21BZ71A226ME15`（末尾 L 为包装代码）的典型曲线。条件为 **25°C、0.5 Vrms、120 Hz**，偏压施加 60 s；频率和施加时间依据 [厂家测量条件 pp.7–8](https://ds.murata.com/simsurfing_data/pdf/en-us/mlcc/sim_mlcc_measuringcond_e.pdf) 及该料号官方数据行 `Condition=120Hz / 0.5Vrms`。

| DC bias | 典型 C / µF | 数据处理 |
| ---: | ---: | --- |
| 0 V | 21.481700 | 原始数据点 |
| 3.3 V | 14.288852 | 原始 0.05 V 网格点，无插值 |
| 4.2 V | 11.788160 | 原始 0.05 V 网格点，无插值 |
| 5.0 V | 9.963983 | 原始数据点 |

完整官方 HTTP 请求、原始响应、SHA256 和摘要位于 JSON 的 `capacitor_validation.GRM21BZ71A226ME15L`。可以直接复核：

```sh
python3 - <<'PYCODE'
import json, urllib.parse, urllib.request
p = json.load(open('hardware/rev-a/parts-selection.json'))['capacitor_validation']['GRM21BZ71A226ME15L']
u = p['request_endpoint'] + '?' + urllib.parse.urlencode(p['request_params'])
r = json.load(urllib.request.urlopen(u))
c = r['JsonCharaData'][0]['charadata'][0]
assert not c['error'] and c['tc'] == '25' and c['ac'] == '0.5'
for x, y in c['data']:
    if any(abs(x[0]-v) < 1e-9 for v in (3.3, 4.2)):
        print(x[0], 'V:', y[0], c['y_subunit'] + c['y_unit'])
PYCODE
```

**这些是典型曲线值，不是全温、负公差和老化后的保证最小值。** 官方 API `GetAcChoices4Cdcb` 只返回 0.5 Vrms；10 mVrms 请求明确报条件不支持。请求 −20°C / 85°C 时，`WorkInfo` 会回显请求温度，但实际 `charadata.tc` 仍为 25，不能将它当成三温验证。[22 µF 规格书](https://search.murata.co.jp/Ceramy/image/img/A01X/G101/ENG/GRM21BZ71A226ME15-01A.pdf) 中 Z7 的“50% 额定电压下温度变化 ±15%”也不是“5 V 偏压后保留 85% 标称电容”。

建议保留该确切 22 µF/10 V/0805 料号：现在有可追溯曲线，无须仅为获得数据而换料或改封装。C3/C4 两只在 4.2 V 下的典型合计约 23.576 µF；3.3 V 各支路的陶瓷按约 14.29 µF 典型值纳入电源评估。小纹波工作条件、初始公差、全温、寿命和动态负载仍须在模型/首件验证中留余量，不能由这张曲线直接宣布已满足全部供电边界。

[LTC3119 数据手册 pp.12、18–20、22–25](https://www.analog.com/media/en/technical-documentation/data-sheets/3119fb.pdf) 要求低阻抗输入旁路，并给出 4.7 µF VCC 旁路及输出电容/补偿指导。所选聚合物总输出标称储能为 520 µF，分布电阻、电感及上述实际 ESR 都应纳入环路。选料可用于限流供电的工程样板；满负载、冷启动和无线突发负载的电压包络不能先行宣称通过。详见同目录 `a1-power-review.md`。

## USB 新增器件封装、脚位及失电复核

**U103 的 stock footprint 可用于 TS3USB30EDGSR，但不是 TI 示例坐标的逐字复制。** [TI DGS0010A 图 4221984/A，pp.1–3](https://www.ti.com/lit/pdf/mpds035) 规定无 EP 的 10-pin VSSOP、3.0 × 3.0 mm body、0.5 mm pitch、4.75–5.05 mm 总焊尾跨度。KiCad `Package_SO:TSSOP-10_3x3mm_P0.5mm` 自身 tags 明确包含 `Texas_DGS0010A` 和 `Texas_VSSOP-10`；名称 TSSOP 不表示这里选成另一种脚距。

| DGS land 几何 | TI example | 当前 KiCad stock |
| --- | ---: | ---: |
| pad 长 × 宽 | 1.45 × 0.30 mm | 1.45 × 0.30 mm |
| 同排 pitch | 0.50 mm | 0.50 mm |
| 两排中心距 | 4.40 mm | 4.30 mm |
| 单侧 pad 外缘 | 2.925 mm | 2.875 mm |
| 最大 lead-tip 半跨度 | 2.525 mm | 同一实际器件 |

KiCad 每排向内移 0.05 mm，外缘仍较最大 lead tip 多 0.35 mm，pin 1 与逆时针编号正确；这是一种几何兼容的替代 land pattern，不能声称 TI 已批准其钢网或焊接工艺。保留当前封装，首件看焊趾/焊跟润湿和桥连。

按 [TS3USB30E Rev. G，pp.3–5、12](https://www.ti.com/lit/ds/symlink/ts3usb30e.pdf) 再核对当前 manifest：1=S→GND，2=D1+→USB_DP_SW，3=D2+→NC，4=D+→USB_DP_ESD，5=GND，6=D−→USB_DM_ESD，7=D2−→NC，8=D1−→USB_DM_SW，9=OE→USB_DISCONNECT，10=VCC→3V3。S=0/OE=0 选 D1，OE=1 断开。使用 DGS pin map，不能误套 RSW/UQFN pin map。VCC=0、VO=0–4.3 V 等规定条件下 Ioff 最大 ±2 µA；推荐工作 VCC=3.0–4.3 V。失电漏电规格不是数学零，也不保证 0–3.0 V 欠压区间的完整行为。

U104=`TLV3011BIDBVR` 的 DBV 是 SOT-23-6、0.95 mm pitch，无 EP；当前 stock `SOT-23-6` 编号正确。TI DBV0006A 的示例焊盘为 1.10×0.60 mm、两排距 2.60 mm，KiCad 为 1.325×0.60 mm、两排距 2.275 mm；stock 外缘 ±1.80 mm，覆盖该器件最大总焊尾跨度 3.00 mm（±1.50），属于兼容的通用 land，亦非 TI 逐点复制。[TLV3011 Rev. C，pp.37–39](https://www.ti.com/lit/ds/symlink/tlv3011.pdf)。

实际脚位再核：1=OUT→USB_DISCONNECT，2=V−→GND，3=IN+→USB_REF，4=IN−→USB_VBUS_CMP，5=REF→USB_REF，6=V+→3V3。该 **B** 版本输入在 V+=0 或上下电时对 0–5.5 V 保持 fail-safe 高阻；本分压在 VBUS=5.5 V 时名义仅 1.632 V。POR 时 TLV3011B 开漏输出为 Hi-Z，R116 在 3V3 存在时把 OE 拉高；完全断电时不能说 R116 仍输出高电平，隔离依靠开关 Ioff。非 B 的 TLV3011 及推挽 TLV3012B 均不接受替代。保持 C130=1 nF，未超过参考输出 10 nF 条件。[TI sections 9.4.1、9.4.3–9.4.5](https://www.ti.com/lit/ds/symlink/tlv3011.pdf)。

静态脚位/几何没有新增阻断项；慢电源坡、VBUS 门限、欠压、ROM BOOTSEL 和线缆拔除仍须按 `FIRST-BOARD-TEST.md` 验证。本次未修改 PCB 或原理图，未执行硬件测量。

## USB4105 本地派生封装

原 KiCad 10 库 `USB_C_Receptacle_GCT_USB4105-xx-A_16P_TopMnt_Horizontal` 的外侧 GND 焊盘至定位 NPTH 约 0.1944 mm。JLC 官方 NPTH 至走线要求 0.2 mm；不能靠降低 DRC 规则忽略。

新 `FarmMesh:USB_C_GCT_USB4105_A1` **仅修改 A1/A12/B1/B12 四个同位地焊盘**：原 0.60 × 1.15 mm、Y=−3.68，改为 0.60 × 1.11 mm、Y=−3.70。只切去靠孔侧 0.04 mm，远孔端不变；所有 NPTH/PTH 的孔径、坐标、槽孔及其余焊盘均经文本比较确认原样保留。按圆角几何算得最近铜距约 **0.233308 mm**，最终以主板 DRC 复核为准。

[GCT USB4105 官方 B4 图（2023-12-18），p.1](https://gct.co/files/drawings/usb4105.pdf) 的推荐焊盘长度为 1.15 mm、PCB 图公差 ±0.05 mm；1.11 mm 位于该区间内。横向仍为 0.60 mm，覆盖图示 0.45 mm GND 焊尾。焊尾覆盖关系和连接器机械孔位保持，仍需首件焊接检查。铜、阻焊和钢网采用同一个缩短后的圆角图形，开口面积较 stock 约减少 3.58%；重复 A/B 编号的同位图形应在 Gerber 中合并为同一开口。

来源和修改 SHA256 存于 JSON 的 `dfm.usb_connector_footprint`，随附 `FarmMesh.pretty/LICENSE-KiCad.txt`。派生数据保留 KiCad 社区归属及 [CC-BY-SA-4.0 + KiCad exception](https://gitlab.com/kicad/libraries/kicad-footprints/-/blob/master/LICENSE.md)。这不是 GCT 对自定义钢网或装配工艺的批准。

## 四层 1.6 mm 制造基线与 USB 阻抗

选用 **JLC04161H-3313**，外层 1 oz、内层 0.5 oz；由上至下名义铜/介质厚度为 `0.035 / 0.0994 / 0.0152 / 1.265 / 0.0152 / 0.0994 / 0.035 mm`。L2 作连续地参考，3313 的计算 Dk=4.1；核心 Dk 在静态表与当前计算接口有差异（4.6/4.42），此处外层 USB 模型只使用邻近 3313。来源：[JLC 层叠](https://jlcpcb.com/impedance)、[官方计算器](https://jlcpcb.com/pcb-impedance-calculator)。订单须指定该层叠，不接受任意“4 层 1.6 mm”等效替换。

常规信号采用 0.15/0.15 mm，RP2350 局部采用 0.10 mm 线距；过孔 0.45/0.20 mm。NPTH 至铜至少 0.20 mm，机械通孔焊盘和内层孔距另按规则检查；选择 1 oz 外铜、绿色阻焊和 ENIG。上述基线留有常规制造余量，仍需 CAM 检查细间距阻焊、通孔环宽、钢网和板边。来源：[JLCPCB 当前能力表](https://jlcpcb.com/capabilities/Capab)。不因连接器库数据存在而自动豁免孔铜间距。

USB 采用 **0.158 mm 线宽、0.200 mm 线间隙**。官方公开计算接口于审阅日期返回 **89.9522758704 Ω differential**，有效状态 `dResultValid=1`。JSON 中保存完整请求和响应，模型为 `DiffEdgeCoupledCoatedMicrostrip1B`，`dCalculateMode=3`，L1 对 L2 coated microstrip。

| 计算参数 | 数值 |
| --- | --- |
| H1 / Er1 | 0.0994 mm / 4.1 |
| W1（底宽） / W2（顶宽） | 0.158 / 0.1453 mm，即 W2=W1−0.5 mil |
| S1 | 0.200 mm |
| T1 | 1.6 mil，计算器成品导体模型 |
| C1/C2/C3 / CEr | 1.0/0.6/1.0 mil，3.8 |

模型不含近旁同层地铜；相邻其他顶层铜至少退让 0.5 mm。保持 L2 连续地，避免分割、跨电源岛或信号参考层空洞。芯片/ESD/mux 焊盘局部展宽和连接器引脚不由这一均匀传输线值代表。下单应要求 **90 Ω differential ±10%** 受控阻抗及厂家确认；该值是模型结果，不是已制造板的测试结果。

重算路径：打开 JLC 计算器，选该层叠及 L1/L2，选 coated differential microstrip，填上表；其接口 POST `https://jlcpcb.com/api/jlcTools/impedance/calc`，结果通过同一 UUID 的 `wss://tools.jlc.com/jlcTools/webSocket/<uuid>` 返回。JSON 保存了完整参数而非只留下截图。`dCalculateMode=1` 给的是奇模约 44.976 Ω，不能误报为差分值。

## 外购附件和采购边界

完整附件 MPN/数量/来源位于 JSON `accessories`。每板三条 Taoglas **FXP830.07.0100C**，每条包含 100 mm 同轴及 MHF I/U.FL 插头，不另买 MHF4 尾线；与 [C5 模组规定的第一代外接天线接口](https://documentation.espressif.com/esp32-c5-wroom-1_wroom-1u_datasheet_en.html) 对应。该 [Taoglas 天线](https://www.taoglas.com/product/freedom-fxp830-2-44-9-6-0ghz-flex-pcb-antenna-ipex-mhfi-2/) 用于样板 RF 试验，安装环境、三天线隔离和增益差异仍须评价；没有宣称复用模组原有认证的天线测试结果。

USB 线为 StarTech **USB2AC1M**；电池插头采用 JST **VHR-2N + 2×SVH-21T-P1.1**，18 AWG 短线按项目极性制作；J2 配 Samtec **SNT-100-BK-G**。SWD/UART 线束板端采用 Harwin **M20-1060500 / M20-1060600 + M20-1180042**，与 0.64 mm 方针匹配。它们是定料的线束元件，不是声称现成通用线缆能直接匹配本板针序；按实际原理图逐针制作，3V3 仅作参考，禁止调试器电源反供。[JST VH](https://www.jst-mfg.com/product/pdf/eng/eVH.pdf)、[Harwin 5-pin](https://www.harwin.com/products/M20-1060500)、[Harwin 6-pin](https://www.harwin.com/products/M20-1060600)、[StarTech](https://www.startech.com/en-at/cables/usb2ac1m)。

关键 IC 均有精确订货型号和官方/分销商目录证据；JSON `procurement_check` 保留来源。RP2350B、C5-N8R8、LTC3119IFE、W25Q128JVSIQ、TS3USB30EDGSR 与 TLV3011BIDBVR 检索到产品/库存指示；**没有预订库存或承诺交期**。Abracon 定向电感为 Active，官方直销仓不可用，但审阅时 [DigiKey 精确型号](https://www.digikey.com.au/en/products/detail/abracon-llc/AOTA-B201610S3R3-101-T/25621527) 有库存指示；装配前须落实原型号，不能用普通无标记 3.3 µH 电感替换。TI 两器件的匿名直销页显示不可用，不等于分销渠道不存在现货。[Abracon 定向电感](https://abracon.com/parametric/inductors/AOTA-B201610S3R3-101-T)、[USB mux 分销记录](https://www.digikey.com/en/products/detail/texas-instruments/TS3USB30EDGSR/2193086)、[B 版比较器分销记录](https://www.mouser.com/ProductDetail/Texas-Instruments/TLV3011BIDBVR?qs=3Rah4i%252BhyCEbcRLZ4CMXdw%3D%3D)。

## 最终原生设计核验

只读核验对象为 `FarmMesh-Node.kicad_pcb`，SHA256：

```text
94b96a96ef75f9561a9c2552ea9e2db2f6d1eb0fe6a99cec8e6313b0ac1b4ab9
```

加载前后原文件哈希不变。实际 164 个 footprint 与 manifest、工程 BOM 及 `parts-selection.json` 一致：153 个实装件、147 个 SMD、6 个通孔件、11 个非采购裸板特征。逐位号检查值、MPN、厂商、footprint 和装配排除属性；无缺失 MPN 或 TBD。C6=120 µF、C203/303/403 的 φ5.0 mm 罐体封装、RP 全部已指定 0402 元件及 J102 派生封装均已落实。27 种库封装、640 个 pad region 的实际板内几何核验通过；没有仅改封装名而保留旧 pad 几何的问题。USB 派生库文件 SHA256 为 `6b5a19aa0bc9462f0afe56b61d3cd2b0560e5659198d3ff32dcae09e6b7866ef`，与选料记录一致。

最终 `audit/erc.json` 为 0 个违规；`audit/drc.json` 为 **0 违规 / 0 未连接 / 0 schematic-parity**。`audit/pcb-verification.json` 的 11 项自动检查全部通过，且输入 PCB、manifest、XML netlist 和 footprint 库哈希与当前来源一致。这里引用的是最终导出树中的实际证据，不是中间候选板的结果。

### 过孔盖油与钢网

最终板有 **396 个过孔**：193 个显式双面 TENTED，203 个继承板级双面盖油；KiCad 10.0.5 的实际 `IsTented(F_Cu/B_Cu)` 对全部过孔均为真。最大过孔钻径为 0.30 mm。所有过孔均无自身 F/B.Mask 或 F/B.Paste 开口；板级/footprint 的额外 mask/paste 图形以及轨线开窗也已检查。

对实际 Gerber 开口进行另一轮独立几何解析后，全部过孔孔边与 F/B.Mask、F/B.Paste 开口均无相切或相交，采用 1 µm 保守几何容差。早期候选中 J2 地过孔 `(98.00, 26.54)` 与 J2 pad 2 的 1.70 mm 阻焊开口相切；最终孔已移至 **`(98.25, 26.54)`**，实际 PTH 文件旧孔位置不存在，双面孔边净距均为 **0.25 mm**。C5 和 R7 的两处原有 paste/drill 交叠也已经修正，最终文件没有重新带入。

下列是仍然较小、但为正值的实际工艺余量；它们不是尚未关闭的 paste/孔交叠：

| 过孔位置，KiCad 板坐标 mm | 最近开口 | 孔边至开口净距 |
| --- | --- | ---: |
| (70.40, 28.70) | C9 F.Mask / F.Paste | 0.0250 mm |
| (87.30, 30.30) | C5 F.Mask / F.Paste | 约 0.0281 mm |
| (93.50, 40.00) | J1 F.Mask / B.Mask | 0.0400 mm |

它们按本板已选的普通 tenting 基线接受，用于受控样板；不宣称在任何阻焊对位公差下均完全封闭。CAM 和首件须重点检查这些位置是否露铜、露孔或发生吸锡，必要的工艺调整不得擅自扩大钢网或阻焊开口侵入孔口。依据 [JLCPCB via finishes](https://jlcpcb.com/blog/five-via-finishes) 及 [via covering guidance](https://jlcpcb.com/help/article/pcb-via-covering)，**普通 tenting 与 solder-mask ink plugging 不同**：0.35 mm 相邻开口距离条件不能直接外推为普通 tenting 的统一最小间距；普通盖油也不是树脂填孔、铜帽/VIPPO 或密封孔保证。本版未要求这些填孔工艺。

三个 C5 模组各有 9 个 1.30×1.30 mm EP 钢网开口，实际 F.Paste 已逐模组核对，孔完全在 EP/paste 区域之外；RP 和 LTC3119 也不存在 EP 钢网区域内的孔。外围接地过孔的散热效果、阻焊成膜及焊膏转移仍需首件验证，不能沿用参考板的已测热阻。

## 实际制造输出核验

核验最终 `manufacturing/manifest.json` 所记导出批次 `2026-09-23T07:56:01.530010+00:00`，并重新检查文件集合和 SHA256 闭包。所有 `frozen_source_sha256` 项与工作区原生源及包内 `native/` 快照一致；已复制自动审阅证据的哈希一致。没有混入旧 A0 制造文件，也没有把 11 个测试点/安装孔特征变成采购或贴装件。

| 输出 | 实际检查结果 |
| --- | --- |
| Gerber | 11 层全部由 gerbonara 1.6.3 成功解析；4 铜层顺序 F.Cu / In1.Cu / In2.Cu / B.Cu，另含双面 mask、paste、silk 和 Edge.Cuts |
| 层叠和表面 | gbrjob 明确 4 层、1.6 mm、ENIG、受控阻抗；铜/介质厚度依次 0.035 / 0.0994 / 0.0152 / 1.265 / 0.0152 / 0.0994 / 0.035 mm，与 JLC04161H-3313 基线一致 |
| 板框 | 实际 Edge.Cuts 四条线中心组成 100.00×100.00 mm 闭合矩形；gbrjob 的 100.05×100.05 mm 是含 0.05 mm 画线宽度的包围盒，不是另一个成品板尺寸 |
| PTH | 共 427 个孔/槽：155×Ø0.20、8×Ø0.25、233×Ø0.30、25×Ø1.00、2×Ø1.70，另有 4 个 0.60 mm 宽 USB 壳脚槽 |
| NPTH | 共 6 个：2×Ø0.65 USB 定位孔、4×Ø3.20 M3 安装孔；与 PTH 分钻 |
| 钻孔坐标 | 全部孔中心、孔径、槽中心/宽度/长度逐项对应原生板；最大圆心差约 0.707 µm，来自 Excellon 0.001 mm 坐标量化；NPTH 中心完全相符 |
| 钢网/阻焊 | 实际 F.Paste 597 个 flash 对象、B.Paste 空；F.Mask 615、B.Mask 37 个 flash 对象。它们不是唯一几何开口数量：USB 同位 A/B pad 会产生重合 flash |
| USB 修订焊盘 | 实际 F.Paste/F.Mask 的 A1/A12/B1/B12 仍为 0.60×1.11 mm，同位图形重合，不生成额外或错位开口；所有定位孔和壳脚槽保留 |
| 装配 BOM | 74 个分组行，展开后恰为 153 个不同位号；数量、值、MPN、厂商和封装逐位号与选料/原生板一致 |
| 坐标文件 | all=153、SMD=147；全部 X/Y、旋转角（模 360°）、值、封装逐条对应原生 footprint，容差 1.1 µm / 1.1 µdeg；全部 top，USB 混合 SMD/PTH 插座 J102 保留 |
| 附件 BOM | 8 行与 `parts-selection.json.accessories` 的数量、MPN、厂商、用途、说明和来源逐字段一致 |

坐标采用 Gerber/钻孔共同的绝对原点 `(0,0)`，X 向右、Y 向上；本板位于 KiCad 原点下方，因此装配 CSV 的负 Y 正确。表中位置是 footprint 原点，不保证等于器件本体重心；装配厂仍须按 `placement-schema.json` 核对导入坐标系、极性和旋转库。该工程 CSV 没有被误标为已匹配 LCSC 物料库的一键贴片文件。

Gerbonara 对两个 Excellon 文件发出 `G90 header statement found after end of header` 警告；该 KiCad 文件仍明确使用 G90 绝对坐标和 METRIC 十进制单位。没有隐藏警告，也没有仅凭解析成功忽略它：上述 427+6 个孔/槽与原生坐标的逐项比对独立确认了解析原点、单位及数值没有偏移。

可从项目根目录只读重验当前包内闭包和冻结源：

```sh
python3 - <<'PYCODE'
from pathlib import Path
import sys
sys.path.insert(0, str(Path('hardware/rev-a/scripts').resolve()))
import export_manufacturing as e
m = e.verify_closure(e.OUT)
e.require_same_sources(m['frozen_source_sha256'])
e.verify_prior_reports()
print(m['board_sha256'], m['assembly_count'], m['smd_count'])
PYCODE
```

独立几何核验使用 KiCad `pcbnew` 只读提取孔/footprint 位置，gerbonara 解析实际文件，Shapely 合并各 Gerber aperture 的正极性图元并计算孔边距离；圆弧多边形化误差纳入 1 µm 保守容差。最终 ZIP 的文件集合、每项 SHA、CRC 及外部 ZIP SHA 由 `finalize_release.py` 封包后再以 `--check-only` 检查；本报告不把尚未运行的封包步骤冒称完成。文档状态统一由 `RELEASE.md` 记录，最终封包会同步本报告和制造要求文本。

## 受控投样结论与实物边界

**在上述精确 PCB 和制造输出范围内，BOM / 封装 / DFM 审阅通过，没有尚未关闭的静态制造阻断，可进入受控工程原型制造与装配。** 该结论不需要追加未约定的人工批准流程，也不代表已经下单、已经制造或通过量产工艺认证。成品依已指定层叠、普通盖油、独立 PTH/NPTH、ENIG 和受控阻抗要求生产；工厂 CAM 对层叠、阻抗、窄余量盖油与钢网的实际工艺确认仍是制造执行的一部分。

装配前核对连接器/电池极性、极性罐体、IC pin 1、L101 定向电感及天线 MHF I/U.FL 配套。首件按 `FIRST-BOARD-TEST.md` 分阶段限流上电，并检查盖油窄余量、EP 焊接、USB 连接器润湿及桥连。环路稳定性、持续 2.2 A 温升、已定义脉宽的 3 A 瞬态、冷启动/UVLO、ROM BOOTSEL/无 VBUS 断连、USB 枚举和三无线并发仍未实测；PIO/PARLIO 时序与吞吐仍是无固件验证的目标。电池 ADC 本版已延期。没有将这些性能边界写成已完成的试验结果。

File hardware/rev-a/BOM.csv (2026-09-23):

References | Quantity | Value | Manufacturer part number | Footprint | Selection status
R1, R6 | 2 | 100k |  | Resistor_SMD:R_0603_1608Metric | MPN TBD; footprint provisional
R3, R8 | 2 | 100k 1% |  | Resistor_SMD:R_0603_1608Metric | MPN TBD; footprint provisional
C104 | 1 | 100n |  | Capacitor_SMD:C_0603_1608Metric | MPN TBD; footprint provisional
C202, C302, C402, C5, C9 | 5 | 100n / 10V |  | Capacitor_SMD:C_0603_1608Metric | MPN TBD; footprint provisional
C1, C127, C2 | 3 | 100n / 16V |  | Capacitor_SMD:C_0603_1608Metric | MPN TBD; footprint provisional
C121 | 1 | 100n pin10 |  | Capacitor_SMD:C_0603_1608Metric | MPN TBD; footprint provisional
C111 | 1 | 100n pin15 |  | Capacitor_SMD:C_0603_1608Metric | MPN TBD; footprint provisional
C112 | 1 | 100n pin24 |  | Capacitor_SMD:C_0603_1608Metric | MPN TBD; footprint provisional
C113 | 1 | 100n pin29 |  | Capacitor_SMD:C_0603_1608Metric | MPN TBD; footprint provisional
C122 | 1 | 100n pin32 |  | Capacitor_SMD:C_0603_1608Metric | MPN TBD; footprint provisional
C114 | 1 | 100n pin41 |  | Capacitor_SMD:C_0603_1608Metric | MPN TBD; footprint provisional
C110 | 1 | 100n pin5 |  | Capacitor_SMD:C_0603_1608Metric | MPN TBD; footprint provisional
C115 | 1 | 100n pin50 |  | Capacitor_SMD:C_0603_1608Metric | MPN TBD; footprint provisional
C123 | 1 | 100n pin51 |  | Capacitor_SMD:C_0603_1608Metric | MPN TBD; footprint provisional
C118 | 1 | 100n pin59 |  | Capacitor_SMD:C_0603_1608Metric | MPN TBD; footprint provisional
C116 | 1 | 100n pin60 |  | Capacitor_SMD:C_0603_1608Metric | MPN TBD; footprint provisional
C119 | 1 | 100n pin68 |  | Capacitor_SMD:C_0603_1608Metric | MPN TBD; footprint provisional
C120 | 1 | 100n pin69 |  | Capacitor_SMD:C_0603_1608Metric | MPN TBD; footprint provisional
C117 | 1 | 100n pin76 |  | Capacitor_SMD:C_0603_1608Metric | MPN TBD; footprint provisional
C6 | 1 | 100u / 10V bulk |  | Capacitor_SMD:CP_Elec_6.3x5.8 | MPN TBD; footprint provisional
C203, C303, C403 | 3 | 100u / 6.3V bulk |  | Capacitor_SMD:CP_Elec_6.3x5.8 | MPN TBD; footprint provisional
R102, R201, R202, R203, R301, R302, R303, R401, R402, R403 | 10 | 10k |  | Resistor_SMD:R_0603_1608Metric | MPN TBD; footprint provisional
C126 | 1 | 10n |  | Capacitor_SMD:C_0603_1608Metric | MPN TBD; footprint provisional
Y101 | 1 | 12MHz ABM8-272-T3 | ABM8-272-T3 | Crystal:Crystal_SMD_3225-4Pin_3.2x2.5mm | Draft selected; no stock check
C105, C106 | 2 | 15p C0G |  | Capacitor_SMD:C_0603_1608Metric | MPN TBD; footprint provisional
R5 | 1 | 162k 1% |  | Resistor_SMD:R_0603_1608Metric | MPN TBD; footprint provisional
R7 | 1 | 174k 1% |  | Resistor_SMD:R_0603_1608Metric | MPN TBD; footprint provisional
J1 | 1 | 1S Li-ion pack | B2P-VH(LF)(SN) | Connector_JST:JST_VH_B2P-VH_1x02_P3.96mm_Vertical | Draft selected; no stock check
R103, R104, R105 | 3 | 1k |  | Resistor_SMD:R_0603_1608Metric | MPN TBD; footprint provisional
C204, C304, C404 | 3 | 1u / 10V |  | Capacitor_SMD:C_0603_1608Metric | MPN TBD; footprint provisional
C7 | 1 | 220u / 6.3V polymer | 6SVPE220M | Capacitor_SMD:CP_Elec_6.3x5.9 | Draft selected; no stock check
R210, R211, R212, R213, R214, R215, R216, R217, R218, R219, R220, R221, R310, R311, R312, R313, R314, R315, R316, R317, R318, R319, R320, R321, R410, R411, R412, R413, R414, R415, R416, R417, R418, R419, R420, R421 | 36 | 22R |  | Resistor_SMD:R_0603_1608Metric | MPN TBD; footprint provisional
C201, C3, C301, C4, C401, C8 | 6 | 22u / 10V X7R |  | Capacitor_SMD:C_0805_2012Metric | MPN TBD; footprint provisional
R110, R111 | 2 | 27R at RP |  | Resistor_SMD:R_0603_1608Metric | MPN TBD; footprint provisional
L101 | 1 | 3.3uH - oriented | AOTA-B201610S3R3-101-T | FarmMesh:AOTA-B201610S3R3-101-T | Draft selected; no stock check
R2 | 1 | 316k 1% |  | Resistor_SMD:R_0603_1608Metric | MPN TBD; footprint provisional
R101 | 1 | 33R |  | Resistor_SMD:R_0603_1608Metric | MPN TBD; footprint provisional
R204, R205, R304, R305, R404, R405 | 6 | 4.7k VALID idle low |  | Resistor_SMD:R_0603_1608Metric | MPN TBD; footprint provisional
C11 | 1 | 4.7u / 10V |  | Capacitor_SMD:C_0805_2012Metric | MPN TBD; footprint provisional
C101, C102, C103 | 3 | 4.7u X5R 20% |  | Capacitor_SMD:C_0603_1608Metric | MPN TBD; footprint provisional
C124 | 1 | 4.7u at pad32 |  | Capacitor_SMD:C_0603_1608Metric | MPN TBD; footprint provisional
L1 | 1 | 4.7uH | XAL7070-472MEC | Inductor_SMD:L_Coilcraft_XAL7070-XXX | Draft selected; no stock check
C12 | 1 | 470p C0G |  | Capacitor_SMD:C_0603_1608Metric | MPN TBD; footprint provisional
R108, R109, R112 | 3 | 5.1k 1% |  | Resistor_SMD:R_0603_1608Metric | MPN TBD; footprint provisional
F1 | 1 | 5A fuse | 0451005.MRL | Fuse:Fuse_Littelfuse-NANO2-451_453 | Draft selected; no stock check
R113 | 1 | 7.5k 1% |  | Resistor_SMD:R_0603_1608Metric | MPN TBD; footprint provisional
R4 | 1 | 78.7k 1% |  | Resistor_SMD:R_0603_1608Metric | MPN TBD; footprint provisional
C10 | 1 | 820p C0G |  | Capacitor_SMD:C_0603_1608Metric | MPN TBD; footprint provisional
SW202, SW302, SW402 | 3 | BOOT |  | Button_Switch_SMD:SW_Push_1P1T_NO_E-Switch_TL3301NxxxxxG | MPN TBD; footprint provisional
SW101 | 1 | BOOTSEL |  | Button_Switch_SMD:SW_Push_1P1T_NO_E-Switch_TL3301NxxxxxG | MPN TBD; footprint provisional
Q1 | 1 | DMP2008UFG-7 | DMP2008UFG-7 | Package_SON:Diodes_PowerDI3333-8 | Draft selected; no stock check
U201, U301, U401 | 3 | ESP32-C5-WROOM-1U-N8R8 | ESP32-C5-WROOM-1U-N8R8 | FarmMesh:ESP32-C5-WROOM-1U | Draft selected; no stock check
U1 | 1 | LTC3119IFE#PBF | LTC3119IFE#PBF | Package_SO:TSSOP-28-1EP_4.4x9.7mm_P0.65mm_EP3.05x7.56mm | Draft selected; no stock check
J2 | 1 | OFF jumper |  | Connector_PinHeader_2.54mm:PinHeader_1x02_P2.54mm_Vertical | MPN TBD; footprint provisional
D1 | 1 | PMEG2010EA | PMEG2010EA,115 | Diode_SMD:D_SOD-323 | Draft selected; no stock check
SW102, SW201, SW301, SW401 | 4 | RESET |  | Button_Switch_SMD:SW_Push_1P1T_NO_E-Switch_TL3301NxxxxxG | MPN TBD; footprint provisional
U101 | 1 | RP2350B | RP2350B | Package_DFN_QFN:QFN-80-1EP_10x10mm_P0.4mm_EP3.4x3.4mm | Draft selected; no stock check
J101 | 1 | SWD / 3V3 ref only |  | Connector_PinHeader_2.54mm:PinHeader_1x05_P2.54mm_Vertical | MPN TBD; footprint provisional
J201, J301, J401 | 3 | UART / 3V3 reference only |  | Connector_PinHeader_2.54mm:PinHeader_1x06_P2.54mm_Vertical | MPN TBD; footprint provisional
J102 | 1 | USB4105-GF-A | USB4105-GF-A | Connector_USB:USB_C_Receptacle_GCT_USB4105-xx-A_16P_TopMnt_Horizontal | Draft selected; no stock check
D101 | 1 | USBLC6-2SC6 | USBLC6-2SC6 | Package_TO_SOT_SMD:SOT-23-6 | Draft selected; no stock check
U102 | 1 | W25Q128JVSIQ | W25Q128JVSIQ | Package_SO:SOIC-8_5.3x5.3mm_P1.27mm | Draft selected; no stock check

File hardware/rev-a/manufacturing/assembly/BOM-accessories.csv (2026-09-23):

Quantity | Manufacturer | MPN | Purpose | Notes | Source
3 | Taoglas | FXP830.07.0100C | One external 50Ω dual-band antenna per ESP32-C5-WROOM-1U | MHF I/U.FL-compatible plug and 100mm 1.37mm coax are integral; no extra RF pigtail required. Prototype RF test antenna, not certified-system approval. Keep radiators outside board/battery metal and test mutual coupling; do not substitute MHF4. Antenna gain/type differ from Espressif certification antenna, so certification reuse is not established. | https://www.taoglas.com/product/freedom-fxp830-2-44-9-6-0ghz-flex-pcb-antenna-ipex-mhfi-2/
1 | StarTech.com | USB2AC1M | 1m USB-A to USB-C data cable for RP2350 USB/BOOTSEL | USB2.0 data cable; board still requires battery or regulated bench input. Not a charging path. | https://www.startech.com/en-at/cables/usb2ac1m
1 | JST | VHR-2N | J1 mating battery cable housing | Project harness pin1 BAT_PLUS, pin2 GND; verify polarity before inserting a pack. | https://www.jst-mfg.com/product/pdf/eng/eVH.pdf
2 | JST | SVH-21T-P1.1 | J1 mating crimp contacts | Use 18–22AWG wire and the specified JST crimp process; select 18AWG short battery leads for prototype high-current tests. | https://www.jst-mfg.com/product/pdf/eng/eVH.pdf
1 | Samtec | SNT-100-BK-G | J2 OFF jumper shunt | 2.54mm 2-position, 0.64mm square-post mating; populated shunt holds converter OFF. | https://www.samtec.com/products/snt-100-bk-g
1 | Harwin | M20-1060500 | J101 five-way SWD cable housing | 0.64mm square-post compatible; custom wire mapping required, not a standard keyed SWD cable. | https://www.harwin.com/products/M20-1060500
3 | Harwin | M20-1060600 | J201/J301/J401 six-way UART/debug housings | Custom wire mapping required. Only 3.3V logic; 3V3 pin is reference, not external power input. | https://www.harwin.com/products/M20-1060600
23 | Harwin | M20-1180042 | Loose female gold crimp contacts for four debug harness housings | Use 22–30AWG wire with correct crimp tooling; quantity is all 5+3×6 positions, omit a physical contact where external power injection must be prevented. | https://cdn.harwin.com/pdfs/IS-15.pdf

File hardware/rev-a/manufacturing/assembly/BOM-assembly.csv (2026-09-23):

References | Quantity | Value | Manufacturer | MPN | Footprint | Notes
F1 | 1 | 5A fuse | Littelfuse | 0451005.MRL | Fuse:Fuse_Littelfuse-NANO2-451_453 | 5A fast-acting NANO2 451; 125V rated; verify battery short-circuit protection and wiring coordination separately.
C6 | 1 | 120u / 10V polymer | Panasonic | 10SVPC120M | Capacitor_SMD:CP_Elec_6.3x5.9 | 120uF ±20%, 10V polymer, ESR max 27mΩ at 100kHz, rated ripple 2.32Arms at 100kHz/105°C. Replaces original 100u nominal; input ripple and inrush require bench verification.
C203, C303, C403 | 3 | 100u / 6.3V polymer | Panasonic | 6SVPC100M | Capacitor_SMD:CP_Elec_5x5.9 | 100uF ±20%, 6.3V polymer, ESR max 30mΩ at 100kHz, rated ripple 1.97Arms at 100kHz/105°C. B6 case 5.0mm diameter, not original 6.3mm generic can. Distributed rail capacitance changes loop response.
C7 | 1 | 220u / 6.3V polymer | Panasonic | 6SVPE220M | Capacitor_SMD:CP_Elec_6.3x5.9 | 220uF ±20%, 6.3V conductive-polymer OS-CON; maximum ESR 10mΩ at 100kHz; rated ripple 3.90Arms at 100kHz/105°C; polarity required. LTC3119 compensation/ripple must be measured with all three radio reservoirs present.
Y101 | 1 | 12MHz ABM8-272-T3 | Abracon | ABM8-272-T3 | Crystal:Crystal_SMD_3225-4Pin_3.2x2.5mm | 12MHz, CL10pF, 3.2x2.5mm four-pad crystal; official RP2350 reference with 15pF external load caps, pin2/4 GND.
L101 | 1 | 3.3uH - oriented | Abracon | AOTA-B201610S3R3-101-T | FarmMesh:AOTA-B201610S3R3-101-T | 3.3uH oriented RP2350 buck inductor, exact official reference choice. Local footprint pad1/mark=CORE_1V1; pad2=LX, matches official RP2350B layout.
J1 | 1 | 1S Li-ion pack | JST | B2P-VH(LF)(SN) | Connector_JST:JST_VH_B2P-VH_1x02_P3.96mm_Vertical | 2-position 3.96mm VH vertical board header. Mates VHR-2N housing with SVH-21T-P1.1 contacts; polarity is project-specific BAT_PLUS pin1/GND pin2.
C130 | 1 | 1n C0G REF | KEMET | C0603C102J5GACTU | Capacitor_SMD:C_0603_1608Metric | 1nF ±5%, 50V C0G/NP0 0603; stable dielectric for compensation/reference filtering.
C126 | 1 | 10n | KEMET | C0603C103K5RACTU | Capacitor_SMD:C_0603_1608Metric | 10nF ±10%, 50V X7R 0603; GPIO37 VBUS sense filter.
C5, C9, C202, C302, C402 | 5 | 100n / 10V | KEMET | C0603C104K5RACTU | Capacitor_SMD:C_0603_1608Metric | 100nF ±10%, 50V X7R 0603; voltage rating exceeds original 10/16V requirement.
C1, C2 | 2 | 100n / 16V | KEMET | C0603C104K5RACTU | Capacitor_SMD:C_0603_1608Metric | 100nF ±10%, 50V X7R 0603; voltage rating exceeds original 10/16V requirement.
C127 | 1 | 100n / 16V at D101 | KEMET | C0603C104K5RACTU | Capacitor_SMD:C_0603_1608Metric | 100nF ±10%, 50V X7R 0603; voltage rating exceeds original 10/16V requirement.
C128 | 1 | 100n / 16V at U103 | KEMET | C0603C104K5RACTU | Capacitor_SMD:C_0603_1608Metric | 100nF ±10%, 50V X7R 0603; voltage rating exceeds original 10/16V requirement.
C129 | 1 | 100n / 16V at U104 | KEMET | C0603C104K5RACTU | Capacitor_SMD:C_0603_1608Metric | 100nF ±10%, 50V X7R 0603; voltage rating exceeds original 10/16V requirement.
C12 | 1 | 470p C0G | KEMET | C0603C471J5GACTU | Capacitor_SMD:C_0603_1608Metric | 470pF ±5%, 50V C0G/NP0 0603; stable dielectric for compensation/reference filtering.
C10 | 1 | 820p C0G | KEMET | C0603C821J5GACTU | Capacitor_SMD:C_0603_1608Metric | 820pF ±5%, 50V C0G/NP0 0603; stable dielectric for compensation/reference filtering.
Q1 | 1 | DMP2008UFG-7 | Diodes Incorporated | DMP2008UFG-7 | Package_SON:Diodes_PowerDI3333-8 | P-channel -20V MOSFET in PowerDI3333-8; reverse-polarity stage, not a lithium-cell protection controller.
U201, U301, U401 | 3 | ESP32-C5-WROOM-1U-N8R8 | Espressif Systems | ESP32-C5-WROOM-1U-N8R8 | FarmMesh:ESP32-C5-WROOM-1U | External-antenna module; 8MB flash + 8MB PSRAM exact suffix. Three 50Ω external dual-band antennas required; custom footprint checked against official land pattern.
C105, C106 | 2 | 15p C0G | Murata | GRM1555C1H150JA01D | Capacitor_SMD:C_0402_1005Metric | 15pF ±5%, 50V C0G; exact reference crystal loading part.
C101, C102, C103 | 3 | 4.7u X5R 20% | Murata | GRM155R60J475ME47D | Capacitor_SMD:C_0402_1005Metric | 4.7uF ±20%, 6.3V X5R; exact RP2350B R4-S1 reference BOM C6/C7/C9. Preserve reference buck layout; not 4.7uF guaranteed after bias/tolerance.
C104 | 1 | 100n | Murata | GRM155R71E104KE14D | Capacitor_SMD:C_0402_1005Metric | 100nF ±10%, 25V X7R; reference BOM decoupler, close to assigned supply pin.
C121 | 1 | 100n pin10 | Murata | GRM155R71E104KE14D | Capacitor_SMD:C_0402_1005Metric | 100nF ±10%, 25V X7R; reference BOM decoupler, close to assigned supply pin.
C111 | 1 | 100n pin15 | Murata | GRM155R71E104KE14D | Capacitor_SMD:C_0402_1005Metric | 100nF ±10%, 25V X7R; reference BOM decoupler, close to assigned supply pin.
C112 | 1 | 100n pin24 | Murata | GRM155R71E104KE14D | Capacitor_SMD:C_0402_1005Metric | 100nF ±10%, 25V X7R; reference BOM decoupler, close to assigned supply pin.
C113 | 1 | 100n pin29 | Murata | GRM155R71E104KE14D | Capacitor_SMD:C_0402_1005Metric | 100nF ±10%, 25V X7R; reference BOM decoupler, close to assigned supply pin.
C122 | 1 | 100n pin32 | Murata | GRM155R71E104KE14D | Capacitor_SMD:C_0402_1005Metric | 100nF ±10%, 25V X7R; reference BOM decoupler, close to assigned supply pin.
C114 | 1 | 100n pin41 | Murata | GRM155R71E104KE14D | Capacitor_SMD:C_0402_1005Metric | 100nF ±10%, 25V X7R; reference BOM decoupler, close to assigned supply pin.
C110 | 1 | 100n pin5 | Murata | GRM155R71E104KE14D | Capacitor_SMD:C_0402_1005Metric | 100nF ±10%, 25V X7R; reference BOM decoupler, close to assigned supply pin.
C115 | 1 | 100n pin50 | Murata | GRM155R71E104KE14D | Capacitor_SMD:C_0402_1005Metric | 100nF ±10%, 25V X7R; reference BOM decoupler, close to assigned supply pin.
C123 | 1 | 100n pin51 | Murata | GRM155R71E104KE14D | Capacitor_SMD:C_0402_1005Metric | 100nF ±10%, 25V X7R; reference BOM decoupler, close to assigned supply pin.
C118 | 1 | 100n pin59 | Murata | GRM155R71E104KE14D | Capacitor_SMD:C_0402_1005Metric | 100nF ±10%, 25V X7R; reference BOM decoupler, close to assigned supply pin.
C116 | 1 | 100n pin60 | Murata | GRM155R71E104KE14D | Capacitor_SMD:C_0402_1005Metric | 100nF ±10%, 25V X7R; reference BOM decoupler, close to assigned supply pin.
C119 | 1 | 100n pin68 | Murata | GRM155R71E104KE14D | Capacitor_SMD:C_0402_1005Metric | 100nF ±10%, 25V X7R; reference BOM decoupler, close to assigned supply pin.
C120 | 1 | 100n pin69 | Murata | GRM155R71E104KE14D | Capacitor_SMD:C_0402_1005Metric | 100nF ±10%, 25V X7R; reference BOM decoupler, close to assigned supply pin.
C117 | 1 | 100n pin76 | Murata | GRM155R71E104KE14D | Capacitor_SMD:C_0402_1005Metric | 100nF ±10%, 25V X7R; reference BOM decoupler, close to assigned supply pin.
C124 | 1 | 4.7u at pad32 | Murata | GRM188R60J475KE19D | Capacitor_SMD:C_0603_1608Metric | 4.7uF ±10%, 6.3V X5R 0603; added local CORE_1V1 bulk, not a replacement for official buck C103.
C204, C304, C404 | 3 | 1u / 10V | Murata | GRM188R71C105KA12D | Capacitor_SMD:C_0603_1608Metric | 1uF ±10%, 16V X7R 0603; ESP32-C5 EN reset RC; nominal RC with 10k is 10ms, actual startup timing remains bias/tolerance dependent.
C11 | 1 | 4.7u / 10V | Murata | GRM21BR71A475KA73L | Capacitor_SMD:C_0805_2012Metric | 4.7uF ±10%, 10V X7R 0805; LTC3119 VCC bypass. Verify biased capacitance and VCC behavior during initial power tests.
C3, C4, C8, C201, C301, C401 | 6 | 22u / 10V X7R | Murata | GRM21BZ71A226ME15L | Capacitor_SMD:C_0805_2012Metric | 22uF ±20%, 10V, X7R(MURATA) Z7, 0805. Official SimSurfing typical at 25C/0.5Vrms/120Hz: 14.288852uF at 3.3V, 11.788160uF at 4.2V; not a guaranteed full-temperature/small-ripple minimum. See capacitor_validation. Local polymer supplements transient reservoir; retain short HF return.
U1 | 1 | LTC3119IFE#PBF | Analog Devices | LTC3119IFE#PBF | Package_SO:TSSOP-28-1EP_4.4x9.7mm_P0.65mm_EP3.05x7.56mm | Industrial-grade 28-lead FE exposed-pad TSSOP; exposed pad GND, layout/thermal and low-VIN full-load validation required.
D1 | 1 | PMEG2010EA | Nexperia | PMEG2010EA,115 | Diode_SMD:D_SOD-323 | 20V 1A Schottky in SOD323; orientation per VCC bypass network.
R102 | 1 | 10k | Yageo | RC0402FR-0710KL | Resistor_SMD:R_0402_1005Metric | 0402 ±1%, 1/16W; downsize for RP2350 reference layout/fanout.
R103, R105 | 2 | 1k | Yageo | RC0402FR-071KL | Resistor_SMD:R_0402_1005Metric | 0402 ±1%, 1/16W; downsize for RP2350 reference layout/fanout.
R216, R217, R218, R219, R221, R316, R317, R318, R319, R321, R416, R417, R418, R419, R421 | 15 | 22R | Yageo | RC0402FR-0722RL | Resistor_SMD:R_0402_1005Metric | 0402 ±1%, 1/16W; downsize for RP2350 reference layout/fanout.
R110, R111 | 2 | 27R at RP | Yageo | RC0402FR-0727RL | Resistor_SMD:R_0402_1005Metric | 0402 ±1%, 1/16W; downsize for RP2350 reference layout/fanout.
R101 | 1 | 33R | Yageo | RC0402FR-0733RL | Resistor_SMD:R_0402_1005Metric | 33Ω ±1%, 0402, 1/16W; exact reference VREG_AVDD filter resistor.
R1, R6 | 2 | 100k | Yageo | RC0603FR-07100KL | Resistor_SMD:R_0603_1608Metric | 0603 thick-film, ±1%, 0.1W.
R3, R8 | 2 | 100k 1% | Yageo | RC0603FR-07100KL | Resistor_SMD:R_0603_1608Metric | 0603 thick-film, ±1%, 0.1W.
R201, R202, R203, R301, R302, R303, R401, R402, R403 | 9 | 10k | Yageo | RC0603FR-0710KL | Resistor_SMD:R_0603_1608Metric | 0603 thick-film, ±1%, 0.1W.
R116 | 1 | 10k OE pull-up | Yageo | RC0603FR-0710KL | Resistor_SMD:R_0603_1608Metric | 0603 thick-film, ±1%, 0.1W.
R5 | 1 | 162k 1% | Yageo | RC0603FR-07162KL | Resistor_SMD:R_0603_1608Metric | 0603 thick-film, ±1%, 0.1W.
R7 | 1 | 174k 1% | Yageo | RC0603FR-07174KL | Resistor_SMD:R_0603_1608Metric | 0603 thick-film, ±1%, 0.1W.
R104 | 1 | 1k | Yageo | RC0603FR-071KL | Resistor_SMD:R_0603_1608Metric | 0603 thick-film, ±1%, 0.1W.
R210, R211, R212, R213, R214, R215, R220, R310, R311, R312, R313, R314, R315, R320, R410, R411, R412, R413, R414, R415, R420 | 21 | 22R | Yageo | RC0603FR-0722RL | Resistor_SMD:R_0603_1608Metric | 0603 thick-film, ±1%, 0.1W.
R2 | 1 | 316k 1% | Yageo | RC0603FR-07316KL | Resistor_SMD:R_0603_1608Metric | 0603 thick-film, ±1%, 0.1W.
R204, R205, R304, R305, R404, R405 | 6 | 4.7k VALID idle low | Yageo | RC0603FR-074K7L | Resistor_SMD:R_0603_1608Metric | 0603 thick-film, ±1%, 0.1W. VALID default-low pull-down selected ≤8.2kΩ for RP2350 A2 E9 compatibility.
R108, R109, R112 | 3 | 5.1k 1% | Yageo | RC0603FR-075K1L | Resistor_SMD:R_0603_1608Metric | 0603 thick-film, ±1%, 0.1W.
R4 | 1 | 78.7k 1% | Yageo | RC0603FR-0778K7L | Resistor_SMD:R_0603_1608Metric | 0603 thick-film, ±1%, 0.1W.
R113 | 1 | 7.5k 1% | Yageo | RC0603FR-077K5L | Resistor_SMD:R_0603_1608Metric | 0603 thick-film, ±1%, 0.1W.
U101 | 1 | RP2350B | Raspberry Pi | RP2350B | Package_DFN_QFN:QFN-80-1EP_10x10mm_P0.4mm_EP3.4x3.4mm | QFN80 10x10mm pitch0.4mm; exposed pad81 GND. Prefer A3/A4 silicon; design retains A2 E9-compatible external pull-downs.
R115 | 1 | 100k 0.1% | Yageo | RT0603BRD07100KL | Resistor_SMD:R_0603_1608Metric | 100kΩ ±0.1%, 25ppm/°C, 0.1W thin-film 0603; USB VBUS hardware threshold divider, do not replace by 1%.
R114 | 1 | 237k 0.1% | Yageo | RT0603BRD07237KL | Resistor_SMD:R_0603_1608Metric | 237kΩ ±0.1%, 25ppm/°C, 0.1W thin-film 0603; USB VBUS hardware threshold divider, do not replace by 1%.
SW202, SW302, SW402 | 3 | BOOT | E-Switch | TL3301NF160QG | Button_Switch_SMD:SW_Push_1P1T_NO_E-Switch_TL3301NxxxxxG | 6x6mm SMT gullwing normally-open tactile; 4.3mm actuator, 160gf, silver contacts; current P010515 drawing.
SW101 | 1 | BOOTSEL | E-Switch | TL3301NF160QG | Button_Switch_SMD:SW_Push_1P1T_NO_E-Switch_TL3301NxxxxxG | 6x6mm SMT gullwing normally-open tactile; 4.3mm actuator, 160gf, silver contacts; current P010515 drawing.
SW102, SW201, SW301, SW401 | 4 | RESET | E-Switch | TL3301NF160QG | Button_Switch_SMD:SW_Push_1P1T_NO_E-Switch_TL3301NxxxxxG | 6x6mm SMT gullwing normally-open tactile; 4.3mm actuator, 160gf, silver contacts; current P010515 drawing.
U104 | 1 | TLV3011BIDBVR | Texas Instruments | TLV3011BIDBVR | Package_TO_SOT_SMD:SOT-23-6 | B-version fail-safe input comparator with reference/POR, SOT23-6 DBV. Do not substitute legacy TLV3011. VBUS threshold ~4.19V nominal; actual tolerance/hysteresis per power review.
U103 | 1 | TS3USB30EDGSR | Texas Instruments | TS3USB30EDGSR | Package_SO:TSSOP-10_3x3mm_P0.5mm | DGS VSSOP10 3x3mm pitch0.5mm USB2.0 mux with Ioff; active-low OE hardware-gated from VBUS comparator; unselected port NC.
J2 | 1 | OFF jumper | Samtec | TSW-102-07-G-S | Connector_PinHeader_2.54mm:PinHeader_1x02_P2.54mm_Vertical | Single-row 2.54mm pitch 0.635mm square post through-hole header, -07 standard tail. J101/Jx01 3V3 is reference only, do not power externally through debugger.
J101 | 1 | SWD / 3V3 ref only | Samtec | TSW-105-07-G-S | Connector_PinHeader_2.54mm:PinHeader_1x05_P2.54mm_Vertical | Single-row 2.54mm pitch 0.635mm square post through-hole header, -07 standard tail. J101/Jx01 3V3 is reference only, do not power externally through debugger.
J201, J301, J401 | 3 | UART / 3V3 reference only | Samtec | TSW-106-07-G-S | Connector_PinHeader_2.54mm:PinHeader_1x06_P2.54mm_Vertical | Single-row 2.54mm pitch 0.635mm square post through-hole header, -07 standard tail. J101/Jx01 3V3 is reference only, do not power externally through debugger.
J102 | 1 | USB4105-GF-A | GCT | USB4105-GF-A | FarmMesh:USB_C_GCT_USB4105_A1 | USB-C USB2.0 16-signal top-mount receptacle; use exact xx-A footprint, GCT drawing and slot/drill checks; no battery charging via VBUS. A1 derived land pattern shortens only four co-located outer GND pads 0.04mm on hole-facing edge (Y length1.11mm; centerY-3.70mm), within GCT 1.15±0.05mm recommended PCB land tolerance. Geometric NPTH-to-pad clearance≈0.2333mm. Paste follows shortened copper; all holes and other pads unchanged.
D101 | 1 | USBLC6-2SC6 | STMicroelectronics | USBLC6-2SC6 | Package_TO_SOT_SMD:SOT-23-6 | SOT23-6 USB ESD array, pin5 connector VBUS bypassed by C127, pin2 GND. Kept connector-side of U103; not power-off isolation by itself.
U102 | 1 | W25Q128JVSIQ | Winbond | W25Q128JVSIQ | Package_SO:SOIC-8_5.3x5.3mm_P1.27mm | 128Mbit 2.7–3.6V QSPI NOR; SI=208mil SOIC8 5.3x5.3mm, not 150mil SOIC. Q=QE bit factory setting. Verify marking and ROM flash boot.
L1 | 1 | 4.7uH | Coilcraft | XAL7070-472MEC | Inductor_SMD:L_Coilcraft_XAL7070-XXX | 4.7uH ±20% shielded power inductor; use exact XAL7070 footprint and confirm saturation/temperature under low-battery peak input current.

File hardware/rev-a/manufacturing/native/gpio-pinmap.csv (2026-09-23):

Link | Signal (C5 perspective) | Direction | C5 GPIO | C5 module pad | RP GPIO | RP package pad | Candidate PIO | PIO GPIOBASE
A | TX_D0 | C5 -> RP | GPIO0 | 6 | 0 | 77 | 0 | 0
A | TX_D1 | C5 -> RP | GPIO1 | 7 | 1 | 78 | 0 | 0
A | TX_D2 | C5 -> RP | GPIO13 | 13 | 2 | 79 | 0 | 0
A | TX_D3 | C5 -> RP | GPIO14 | 14 | 3 | 80 | 0 | 0
A | TX_CLK | C5 -> RP | GPIO4 | 17 | 4 | 1 | 0 | 0
A | TX_VALID | C5 -> RP | GPIO5 | 16 | 5 | 2 | 0 | 0
A | RX_D0 | RP -> C5 | GPIO6 | 8 | 6 | 3 | 0 | 0
A | RX_D1 | RP -> C5 | GPIO8 | 10 | 7 | 4 | 0 | 0
A | RX_D2 | RP -> C5 | GPIO9 | 11 | 8 | 6 | 0 | 0
A | RX_D3 | RP -> C5 | GPIO10 | 12 | 9 | 7 | 0 | 0
A | RX_CLK | C5 -> RP | GPIO23 | 21 | 10 | 8 | 0 | 0
A | RX_VALID | RP -> C5 | GPIO24 | 23 | 11 | 9 | 0 | 0
B | TX_D0 | C5 -> RP | GPIO0 | 6 | 12 | 11 | 1 | 0
B | TX_D1 | C5 -> RP | GPIO1 | 7 | 13 | 12 | 1 | 0
B | TX_D2 | C5 -> RP | GPIO13 | 13 | 14 | 13 | 1 | 0
B | TX_D3 | C5 -> RP | GPIO14 | 14 | 15 | 14 | 1 | 0
B | TX_CLK | C5 -> RP | GPIO4 | 17 | 16 | 16 | 1 | 0
B | TX_VALID | C5 -> RP | GPIO5 | 16 | 17 | 17 | 1 | 0
B | RX_D0 | RP -> C5 | GPIO6 | 8 | 18 | 18 | 1 | 0
B | RX_D1 | RP -> C5 | GPIO8 | 10 | 19 | 19 | 1 | 0
B | RX_D2 | RP -> C5 | GPIO9 | 11 | 20 | 20 | 1 | 0
B | RX_D3 | RP -> C5 | GPIO10 | 12 | 21 | 21 | 1 | 0
B | RX_CLK | C5 -> RP | GPIO23 | 21 | 22 | 22 | 1 | 0
B | RX_VALID | RP -> C5 | GPIO24 | 23 | 23 | 23 | 1 | 0
C | TX_D0 | C5 -> RP | GPIO0 | 6 | 24 | 25 | 2 | 16
C | TX_D1 | C5 -> RP | GPIO1 | 7 | 25 | 26 | 2 | 16
C | TX_D2 | C5 -> RP | GPIO13 | 13 | 26 | 27 | 2 | 16
C | TX_D3 | C5 -> RP | GPIO14 | 14 | 27 | 28 | 2 | 16
C | TX_CLK | C5 -> RP | GPIO4 | 17 | 28 | 36 | 2 | 16
C | TX_VALID | C5 -> RP | GPIO5 | 16 | 29 | 37 | 2 | 16
C | RX_D0 | RP -> C5 | GPIO6 | 8 | 30 | 38 | 2 | 16
C | RX_D1 | RP -> C5 | GPIO8 | 10 | 31 | 39 | 2 | 16
C | RX_D2 | RP -> C5 | GPIO9 | 11 | 32 | 40 | 2 | 16
C | RX_D3 | RP -> C5 | GPIO10 | 12 | 33 | 42 | 2 | 16
C | RX_CLK | C5 -> RP | GPIO23 | 21 | 34 | 43 | 2 | 16
C | RX_VALID | RP -> C5 | GPIO24 | 23 | 35 | 44 | 2 | 16

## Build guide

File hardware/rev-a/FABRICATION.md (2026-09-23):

# FarmMesh Node A1 — 制造与装配要求 / Fabrication and assembly requirements

**状态 / Status: GO FOR CONTROLLED A1 PROTOTYPE FABRICATION / 可受控工程原型投样。**

日期 / Date: 2026-09-23。完整布线及铺铜、最终 ERC/DRC、独立电气/DFM 会审和实际制造文件一致性已通过；统一放行依据为 [RELEASE.md](RELEASE.md)。本文件绑定原生 PCB SHA256 `94b96a96ef75f9561a9c2552ea9e2db2f6d1eb0fe6a99cec8e6313b0ac1b4ab9`，适用于受控工程样板。实物电气性能及量产工艺尚未验证。

The frozen board and actual manufacturing outputs have passed the release gates recorded in RELEASE.md. Fabricate and assemble the exact released snapshot under the requirements below. Physical performance and production process qualification remain open; execute the first-board plan after assembly.

## PCB 配置 / PCB construction

| 项目 / Item | 要求 / Requirement |
| --- | --- |
| 层数及材料 / Layers and material | 4-layer FR-4，JLCPCB **JLC04161H-3313** |
| 板厚 / Finished thickness | 1.6 mm nominal；按下单层叠和制造公差 / per confirmed fabrication stack-up |
| 外形 / Outline | 当前设计 100 × 100 mm，连续闭合 Edge.Cuts；最终以发布 Gerber 为准 / current design 100 × 100 mm; released outline governs |
| 铜厚 / Copper | Outer 1 oz，inner 0.5 oz；不可无复核改 2 oz / no unreviewed change to 2 oz |
| 表面 / Finish | ENIG |
| 阻焊 / Solder mask | 双面绿色 / green, both sides |
| 丝印 / Legend | 元件位号、pin 1、电容正极、电池极性清晰；不压焊盘 / legible references, pin 1 and polarity marks, clear of solderable pads |
| 安装孔 / Mounting holes | H1–H4：φ3.2 mm NPTH，中心为 (5,5)、(95,5)、(5,95)、(95,95) mm；以当前 PCB 左上角为原点 / from current PCB top-left |
| 测试点 / Test pads | TP1/2/3/101/102/103/104 为裸铜焊盘，无贴装件 / exposed PCB pads, no purchased components |

层序 / Layer order: **F.Cu → In1.Cu → In2.Cu → B.Cu**。In1.Cu 和 In2.Cu 均为 GND；In1.Cu 为顶层主要参考，RP2350 buck LX 下方按设计保留局部铜禁区。保持完整发布层序；CAM 不得自行删改地平面和电源铜。

In1.Cu is the principal ground reference, with the intentional local RP2350 buck LX copper keepout. Preserve the released layer order and copper clearances. Do not modify plane connectivity during CAM processing without engineering review.

[JLC 层叠 / Stack-up](https://jlcpcb.com/impedance)：外铜/介质/内铜/core/内铜/介质/外铜名义为 `0.035 / 0.0994 / 0.0152 / 1.265 / 0.0152 / 0.0994 / 0.035 mm`。厂商必须确认该层叠，不能只按“四层 1.6 mm”换任意芯板 / Confirm this exact construction rather than substituting any four-layer 1.6 mm stack.

## 几何及钻孔 / Geometry and drilling

- 常规信号线宽/间距 0.15/0.15 mm；RP2350 QFN 逃线局部 0.10 mm 线宽/间距。大电流电源铜按发布 PCB 保留，不统一缩为信号线宽。
- Normal signals use 0.15/0.15 mm trace/space; local RP2350 fanout uses 0.10 mm rules. Preserve the released power-copper widths.
- 常规通孔 via 0.45 mm 焊盘 / 0.20 mm 钻孔；另有较大接地、散热和电源 via。PTH 与 NPTH 必须分开钻孔输出，USB 插座槽孔不得改圆孔。
- Standard through vias use 0.45 mm land / 0.20 mm drill, with larger ground, thermal and power vias where specified. Keep plated and non-plated drills separate; preserve USB shell slots.
- NPTH 至铜至少 0.20 mm；检查内部铜至孔、元件 PTH 环宽和板边间距，不能用全局降低 DRC 限值掩盖违规。
- Maintain at least 0.20 mm NPTH-to-copper clearance and verify inner-layer hole clearances, component-hole annular rings and board-edge clearance.

这些是本项目基线，制造方以 [JLC 工艺能力表](https://jlcpcb.com/capabilities/Capab) 和最终 CAM 复核确认。存在任何与本规格不一致的自动修改，应先返回工程确认 / Report any required CAM changes before fabrication.

## USB 受控阻抗和插座焊盘 / USB impedance and connector lands

USB D+/D− 主线按顶层对 In1.Cu 参考的差分微带设计：**0.158 mm 宽、0.200 mm 线间隙、90 Ω differential ±10%**。同层其他铜通常至少退让 0.5 mm，局部器件焊盘例外由工程审阅。所列宽距只适用于指定层叠；未经复核不允许换层叠或改变阻抗线宽。

The USB pair uses top-layer coated microstrip referenced to In1.Cu: **0.158 mm width, 0.200 mm edge gap, 90 Ω differential ±10%**. Keep other top copper generally 0.5 mm away. These dimensions are specific to the selected stack-up. Confirm controlled impedance with the fabricator; the nominal calculator result is 89.9523 Ω, not a measurement of a manufactured board.

J102 使用 **FarmMesh:USB_C_GCT_USB4105_A1**，不是未修订 stock footprint。仅 A1/A12/B1/B12 的同位 GND 焊盘靠定位孔边缩短 0.04 mm：0.60 × 1.11 mm、局部 Y=−3.70 mm；孔径、孔位、槽孔及其他焊盘不变。阻焊/钢网开口随该铜形状；重叠 A/B 编号不得重复叠加锡膏厚度。计算孔铜净距约 0.2333 mm，最终 Gerber 须复查。

J102 uses the local revised land pattern. Only the four coincident outer ground pads are shortened on the locating-hole side. Preserve all drill geometry and remaining lands. Coincident A/B pad definitions represent one physical aperture, not two paste deposits. The nominal revised length is within the 1.15 ±0.05 mm recommended-land dimension in the [GCT B4 drawing](https://gct.co/files/drawings/usb4105.pdf); inspect the first assembled connector for wetting and alignment.

## Via、裸露焊盘与钢网 / Vias, exposed pads and stencil

普通信号/接地 via 默认双面 tenting，不开钢网。**Tenting 不是树脂塞孔加电镀盖帽（VIPPO），也不是保证完全填满孔。** 本样板目标为普通非 VIPPO 工艺；不得在裸露焊盘钢网开口内自动添加未填充开孔。

Ordinary signal/ground vias are tented on both sides and absent from paste. Tenting is not VIPPO and does not guarantee a filled hole. This prototype targets a conventional non-VIPPO process; do not add open unfilled holes inside exposed-pad paste apertures.

C5 模组 EP29 保留 3 × 3 个 1.3 × 1.3 mm 钢网窗口，间隙 0.4 mm，包络 4.7 × 4.7 mm；窗口面积总计 15.21 mm²，约为包络 68.9%。顶层实心 GND 铜连接九块 EP 铜焊盘；**EP 包络内部无孔**，使用八个外围接地 via 和模组边缘 GND 焊盘附近的 via 接入内层。不得恢复已取消的四个内部间隙 via，不得合并钢网窗口。

The C5 EP29 retains nine 1.3 mm square paste windows within a 4.7 mm square envelope, approximately 68.9% aperture coverage. Solid top-layer ground copper joins the nine EP lands. **No holes are permitted inside the EP envelope**; eight perimeter ground vias and additional vias near the module edge ground pads connect to the internal planes. Do not restore the removed four interior gap vias or merge the paste windows.

[JLC 普通 tenting 与塞孔说明](https://jlcpcb.com/blog/five-via-finishes) 的 0.35 mm 开口距离限制属于**油墨塞孔**，不是普通 tenting 的统一规则；普通 tenting 建议孔径不超过 0.4 mm。最终 Gerber 必须检查 via 在双面 mask 上没有开窗，孔不在钢网开口内，并保留足够 mask web。RP2350 外围孔到 EP 铜边约 0.25 mm 的名义距离本身不触犯该塞孔条件，因为本板不要求塞孔；仍须根据实际 mask expansion 检查。普通 tenting 可能存在局部透光或不完全密封，不可宣称达到填孔效果。[JLC Via Covering](https://jlcpcb.com/help/article/pcb-via-covering)。

JLC's 0.35 mm exclusion from adjacent openings applies to **solder-mask ink plugging**, not a universal tenting clearance. Ordinary tenting is recommended for holes no larger than 0.4 mm. Inspect the final mask and paste data: no via mask openings, no holes in paste apertures, and adequate mask web. The RP2350 perimeter hole-to-EP copper clearance of approximately 0.25 mm is not automatically disqualified by an ink-plugging rule; review its actual mask expansion. Ordinary tenting does not promise fully sealed holes.

最终实际 Gerber/钻孔中 396 个 via 的最大孔径为 0.30 mm，全部有效双面 tenting；没有孔与钢网或阻焊开口的名义相交。以下位置余量较小，**CAM 及首件重点检查**：KiCad 坐标 (70.40,28.70) 的 C9 邻孔净距 0.0250 mm，(87.30,30.30) 的 C5 邻孔约 0.0281 mm，(93.50,40.00) 的 J1 邻孔 0.0400 mm。避免对位偏差造成露孔或吸锡；工艺无法满足时返回工程处理，不自行扩大开窗。J2 地孔现为 (98.25,26.54)，孔边到其相邻双面 mask 开口 0.25 mm，旧相切位置已移除。详见 [最终 DFM 审阅](reports/a1-dfm-bom-review.md)。

All 396 vias are effectively tented on both sides with drills no larger than 0.30 mm. The three small positive margins above are accepted for prototype CAM/first-piece inspection, not a guarantee of sealed holes under all process tolerances. Verify mask registration and solder wicking at these locations before accepting assembled samples.

U101、U1 和三个模组的 EP 必须焊接到 GND，不能作为“可不焊”处理。RP2350 EP 外围散热孔不应被钢网开窗覆盖。钢网厚度以装配方兼顾 0402、0.4 mm QFN 和模组窗口的工艺审查为准；0.10 mm 可作为试制讨论起点，不是已验证参数。

Solder the exposed pads of U101, U1 and all three modules to ground. Keep the RP2350 perimeter thermal vias outside paste openings. The assembler must select stencil thickness and paste process for 0402 parts, 0.4 mm QFN and the module windows; 0.10 mm is an engineering starting point, not a qualified process.

建议整板受控回流焊并检查隐藏 EP 焊点；返修 C5 时使用底部预热、适配风嘴和热电偶，按 [Espressif 模组回流/处理规定](https://www.espressif.com/sites/default/files/documentation/esp32-c5-wroom-1_wroom-1u_datasheet_en.pdf) 设定实际温度曲线。不要仅凭热风枪设定温度判断焊点峰温，也不要在同轴插头连接时强行移动模组。

Prefer controlled whole-board reflow and inspection of hidden EP joints. For module rework, use bottom preheat, a suitable nozzle and thermocouple monitoring against the module manufacturer's processing profile. Hot-air station setpoint alone is not solder-joint temperature. Disconnect coax cables before rework.

## BOM、方向和附件 / BOM, orientation and accessories

装配依据最终发布 BOM 与 `parts-selection.json`，共 153 个实装件；11 个 TP/H 裸板特征不采购、不贴装。不得静默用“同容量/同封装”替代关键电容、定向电感或 USB B 版比较器。C6 实际为 **120 µF/10 V**；C203/303/403 为 **φ5 × 5.9 mm**。C7 的厂家极性标记须与 PCB 正极匹配。

Use the released BOM and parts-selection mapping: 153 fitted components; 11 bare-board TP/H features are not purchased or placed. Substitutions require engineering review. C6 is 120 µF/10 V, and the three radio bulk capacitors use 5 mm diameter cans. Verify all polymer-capacitor polarity marks.

L101=`AOTA-B201610S3R3-101-T` 的厂家定位标记须对应本地 footprint pad1 / CORE_1V1，pad2 / LX；它是定向电感，不能按普通对称 3.3 µH 件任意旋转。核查 RP2350、Flash、LTC3119、USB mux/comparator、各 C5 的 pin 1。[Abracon 图纸](https://abracon.com/datasheets/AOTA-B201610S3R3-101-T.pdf)。

Place the marked inductor in its specified orientation: pad 1 to CORE_1V1, pad 2 to LX. Verify pin 1 orientation for every IC and module.

| 附件 / Accessory | 数量 / Qty | 料号 / MPN | 接线与使用 / Wiring and use |
| --- | ---: | --- | --- |
| 双频天线含同轴 / Dual-band antenna with coax | 3 | Taoglas FXP830.07.0100C | 100 mm cable, MHF I/U.FL；每模组一条 / one per module; not MHF4 |
| USB 数据线 / USB data cable | 1 | StarTech USB2AC1M | USB-A ↔ USB-C；不为电池充电 / no battery charging path |
| 电池插头壳 / Battery housing | 1 | JST VHR-2N | J1 pin1 BAT_PLUS，pin2 GND |
| 电池端子 / Battery contacts | 2 | JST SVH-21T-P1.1 | 建议 18 AWG 短线，极性逐线检查 / short 18 AWG leads; verify polarity |
| OFF 短路帽 / OFF shunt | 1 | Samtec SNT-100-BK-G | 装到 J2 则 OFF / fitted on J2 disables converter |
| SWD 线壳 / SWD housing | 1 | Harwin M20-1060500 | 按板上针序制作 / custom pin mapping |
| UART 线壳 / UART housings | 3 | Harwin M20-1060600 | 按板上针序制作 / custom pin mapping |
| 调试线端子 / Debug contacts | 23 | Harwin M20-1180042 | 5+3×6 positions；3V3 为参考，不外部供电 / 3V3 reference only |

天线保持远离板铜、电池和金属外壳，留同轴弯曲余量与插拔空间。该天线组合用于样板验证，三无线互扰和装入外壳后的效率需实测。电池需为合适的受保护 1S 锂电源；本板无充电器，首件先使用限流台式电源验证。USB 或调试口不得用来反向给 3V3 母线供电。

Keep antenna radiators clear of board copper, battery and enclosure metal, with cable strain relief and mating access. Validate three-radio coexistence and enclosure effects on the samples. The board requires a suitable protected 1S source and contains no charger. Use a current-limited bench supply for first power-up; never back-power 3V3 through a debugger or USB connection.

## 发布前交付核对 / Pre-release deliverable review

最终包包含一致版本的四层铜、双面阻焊/丝印/钢网、板框、PTH/NPTH 钻孔、BOM、坐标及装配图，均由冻结源统一导出并记录 SHA256。导入装配系统时核对极性、单位、原点、顶/底视图和重复同位焊盘。位号以 F.Fab 装配图及坐标为完整依据；密集 0402 区域未把所有位号强行挤入丝印。

The release package contains matching copper, mask, legend, outline, separate plated/non-plated drills, stencil, BOM, placement and assembly views, exported from the frozen source with SHA256 records. Verify units, origins, polarity and coincident pads when importing it. Use the complete F.Fab assembly drawing and placement references in dense areas where all 0402 references cannot fit on silkscreen.

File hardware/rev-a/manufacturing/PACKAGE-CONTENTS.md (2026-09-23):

# FarmMesh Node A1 package

Release authority/status: `documentation/RELEASE.md`. Sealing hashes does not approve fabrication.

- `gerber/`: 11 copper/mask/legend/paste/outline layers, with Gerber job file when emitted.
- `drill/`: separate PTH/NPTH Excellon files, drill report and two PDF drill maps.
- `assembly/BOM-assembly.csv`: 153 fitted components only. `placements-all.csv` has the same 153 references; `placements-smd.csv` contains 147 SMD components, including the hybrid USB connector. Read `placement-schema.json` before machine import.
- `assembly/BOM-accessories.csv`: eight separately selected antenna, cable and mating-harness part types with per-board quantities; these are not PCB placement rows.
- `review/`: PDFs generated from the frozen sources; explicit review evidence may be added during final sealing.
- `native/`: editable KiCad project, all eight schematics, local symbols/footprints/licenses, selected parts, engineering BOM, scripts and verification inputs. The engineering `native/BOM.csv` also lists 11 bare-board features; do not use it as the fitted assembly BOM.
- `audit/`: fresh ERC/DRC, prior independent verification bound to native hashes, and exact export commands.
- `documentation/`: manufacturing/first-board instructions and final review/status documents, mirrored into the native workspace for reproducibility.
- `manifest.json`: every payload SHA256 plus frozen source hashes. `SHA256SUMS` additionally hashes the manifest. The final ZIP checksum is external, avoiding self-referential hashes.

Reproduce with KiCad 10.0.5 (or re-review tool changes), the same library geometry and Python. In `native/`, regenerate `reports/netlist.xml`, run `scripts/verify_design.py` and `scripts/verify_pcb.py` using KiCad Python, then run `python3 scripts/export_manufacturing.py`. Review the new outputs, document authorized status separately, then run `python3 scripts/finalize_release.py` and `python3 scripts/finalize_release.py --check-only`. A changed native/BOM/parts/script hash requires a new export. CAD-generated timestamps can change a fresh export; sealing an unchanged payload produces a deterministic ZIP.

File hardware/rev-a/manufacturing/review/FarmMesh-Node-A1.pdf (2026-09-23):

1 | 2 | 3 | 4 | 5 | 6 | 7 | 8

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
Size: A3 | Rev: A1 | F Date: 2026-09-23
KiCad E.D.A. 10.0.5 | Id: 1/8

# Title: FarmMesh Node - schematic review index

# File: FarmMesh-Node.kicad_sch

# Sheet: /

# FarmMesh Node

# Prototype engineering - release status in RELEASE.md

# 1S Li-ion battery input; no on-board charger

1S battery input and 3.3V buck-boost File: 01-power.kicad_sch RP2350B aggregation, memory and debug

File: 02-rp2350.kicad_sch | C5-C module and independent link C

File: 05-radio-c.kicad_sch

## Test access and mechanical features

File: 07-test-mechanical.kicad_sch | C5-A module and independent link A

# File: 03-radio-a.kicad_sch RP USB boot / self-powered USB-C

File: 06-usb.kicad_sch

## C5-B module and independent link B

File: 04-radio-b.kicad_sch

# INTERFACE CONVENTION

TX / RX are named from the C5 perspective.
Both TX_CLK and RX_CLK originate at that C5.
RP drives only RX_D[0..3] and RX_VALID.
Global net labels make the electrical sheet connections. No wireless protocol is selected by this schematic.

# 1 x RP2350B + 3 x ESP32-C5-WROOM-1U-N8R8 1S protected Li-ion input; 3.3V regulated rail Native KiCad 10 schematic + four-layer prototype PCB

# FarmMesh Node / Revision A1 - PROTOTYPE

Battery: conventional 4.20V-max Li-ion, NOT LiFePO4 or HV Li-ion. Normal loaded operation about 3.0-4.2V; cold start about 3.3V. External protected pack required. No on-board charger or PV input. PCB release status: see RELEASE.md and final review reports. RF isolation, converter stability and throughput require first-board validation. REVIEW BOUNDARIES

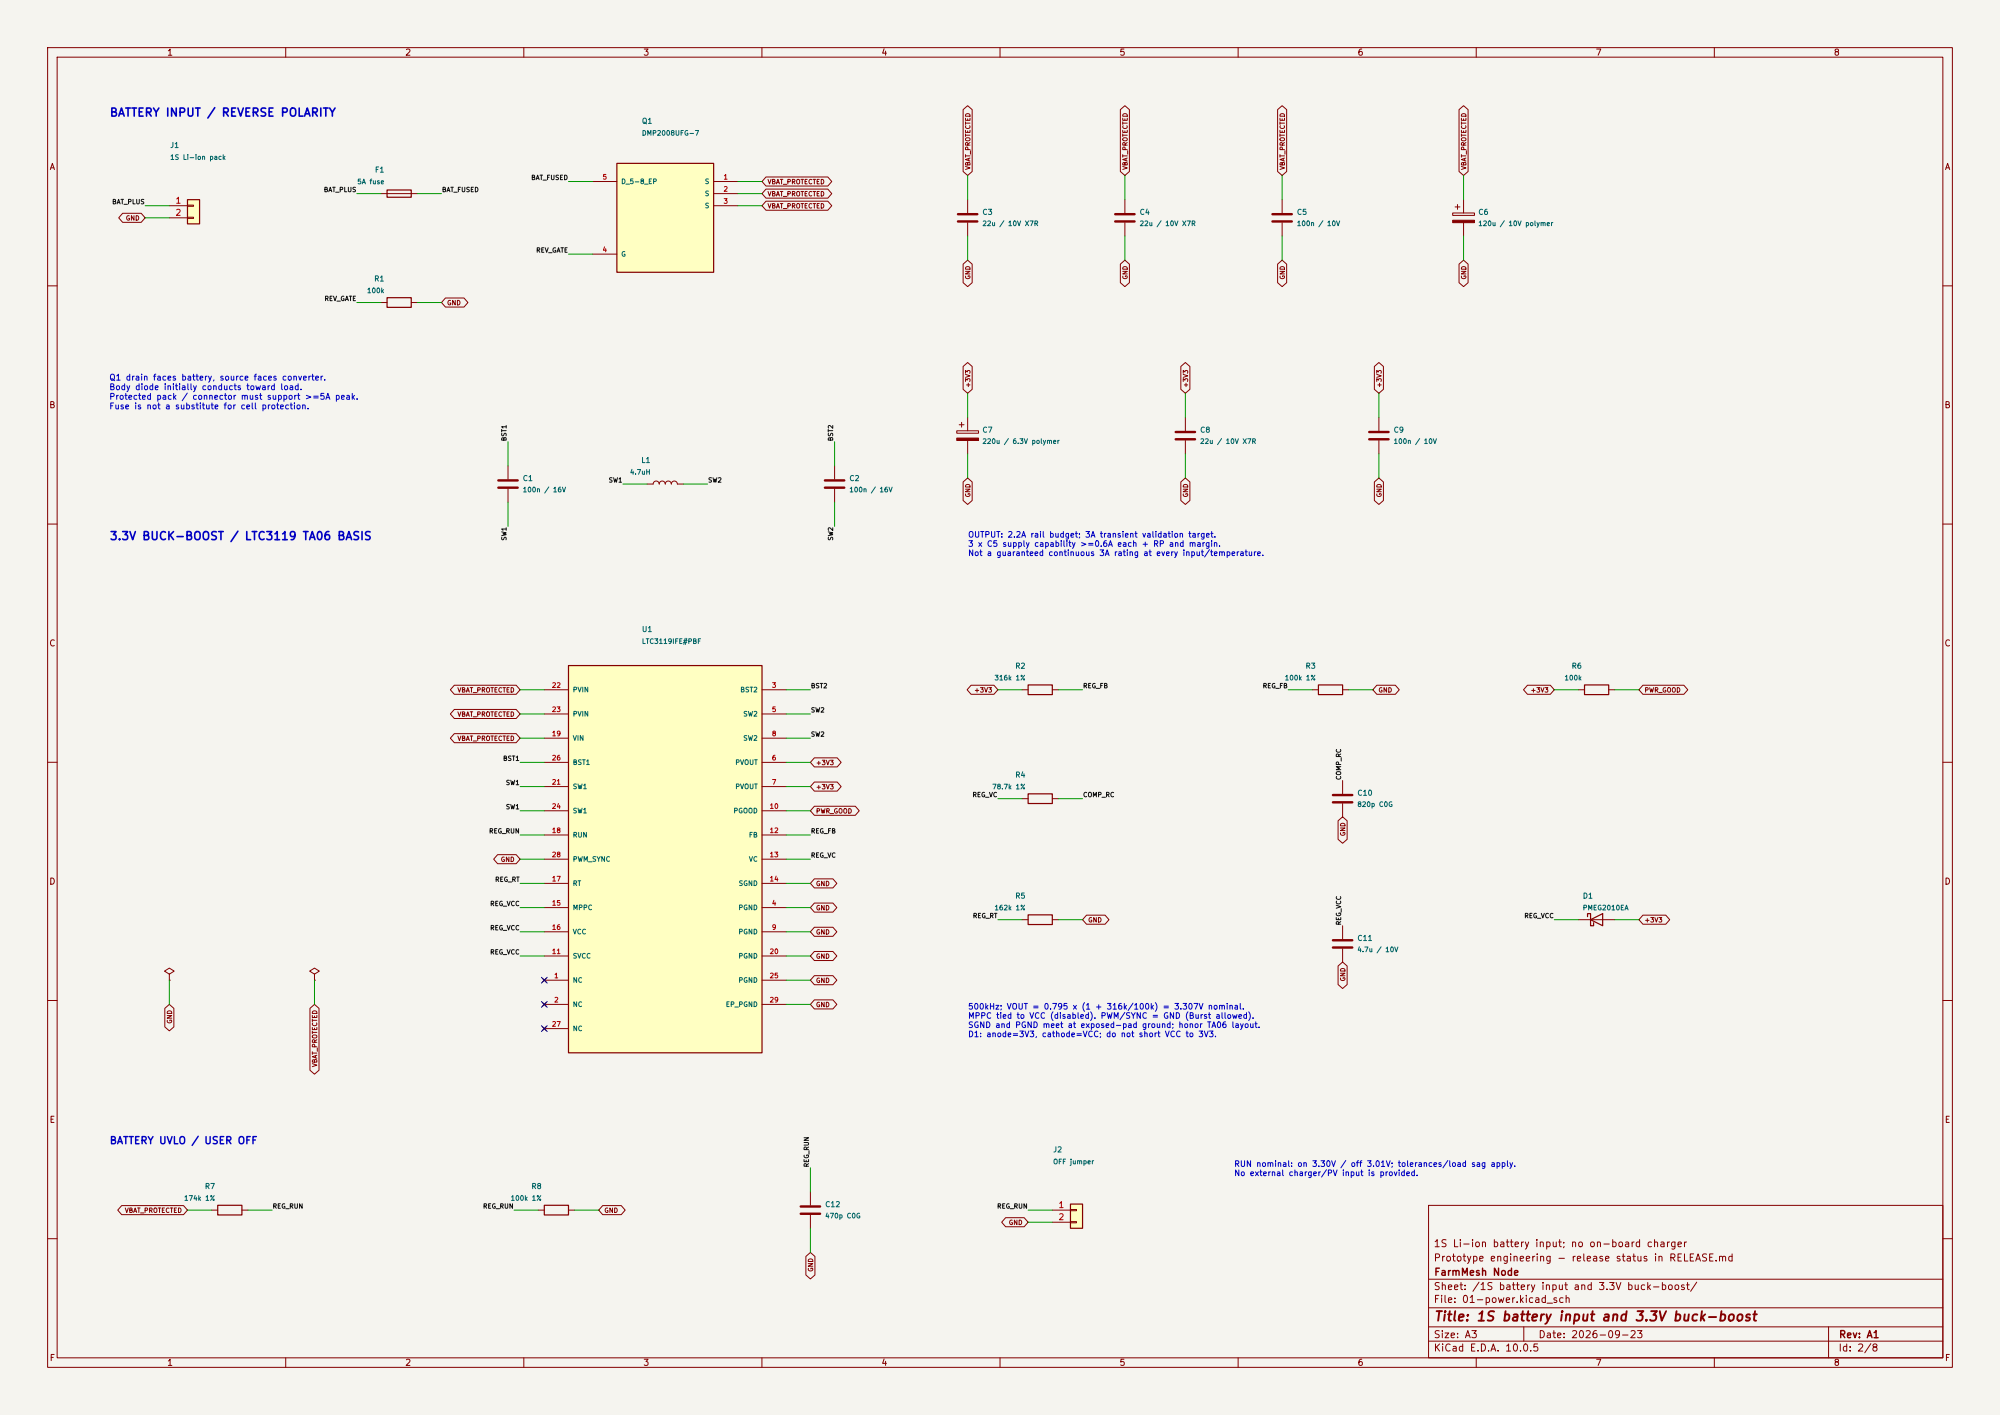
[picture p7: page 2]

BATTERY INPUT / REVERSE POLARITY
REV_GATE BAT_FUSED

Q1 drain faces battery, source faces converter. Body diode initially conducts toward load. Protected pack / connector must support >=5A peak. Fuse is not a substitute for cell protection.

OUTPUT: 2.2A rail budget; 3A transient validation target. 3 x C5 supply capability >=0.6A each + RP and margin. Not a guaranteed continuous 3A rating at every input/temperature.

BATTERY UVLO / USER OFF

1S Li-ion battery input; no on-board charger R7

Prototype engineering - release status in RELEASE.md
FarmMesh Node
Sheet: /1S battery input and 3.3V buck-boost/
File: 01-power.kicad_sch
Title: 1S battery input and 3.3V buck-boost

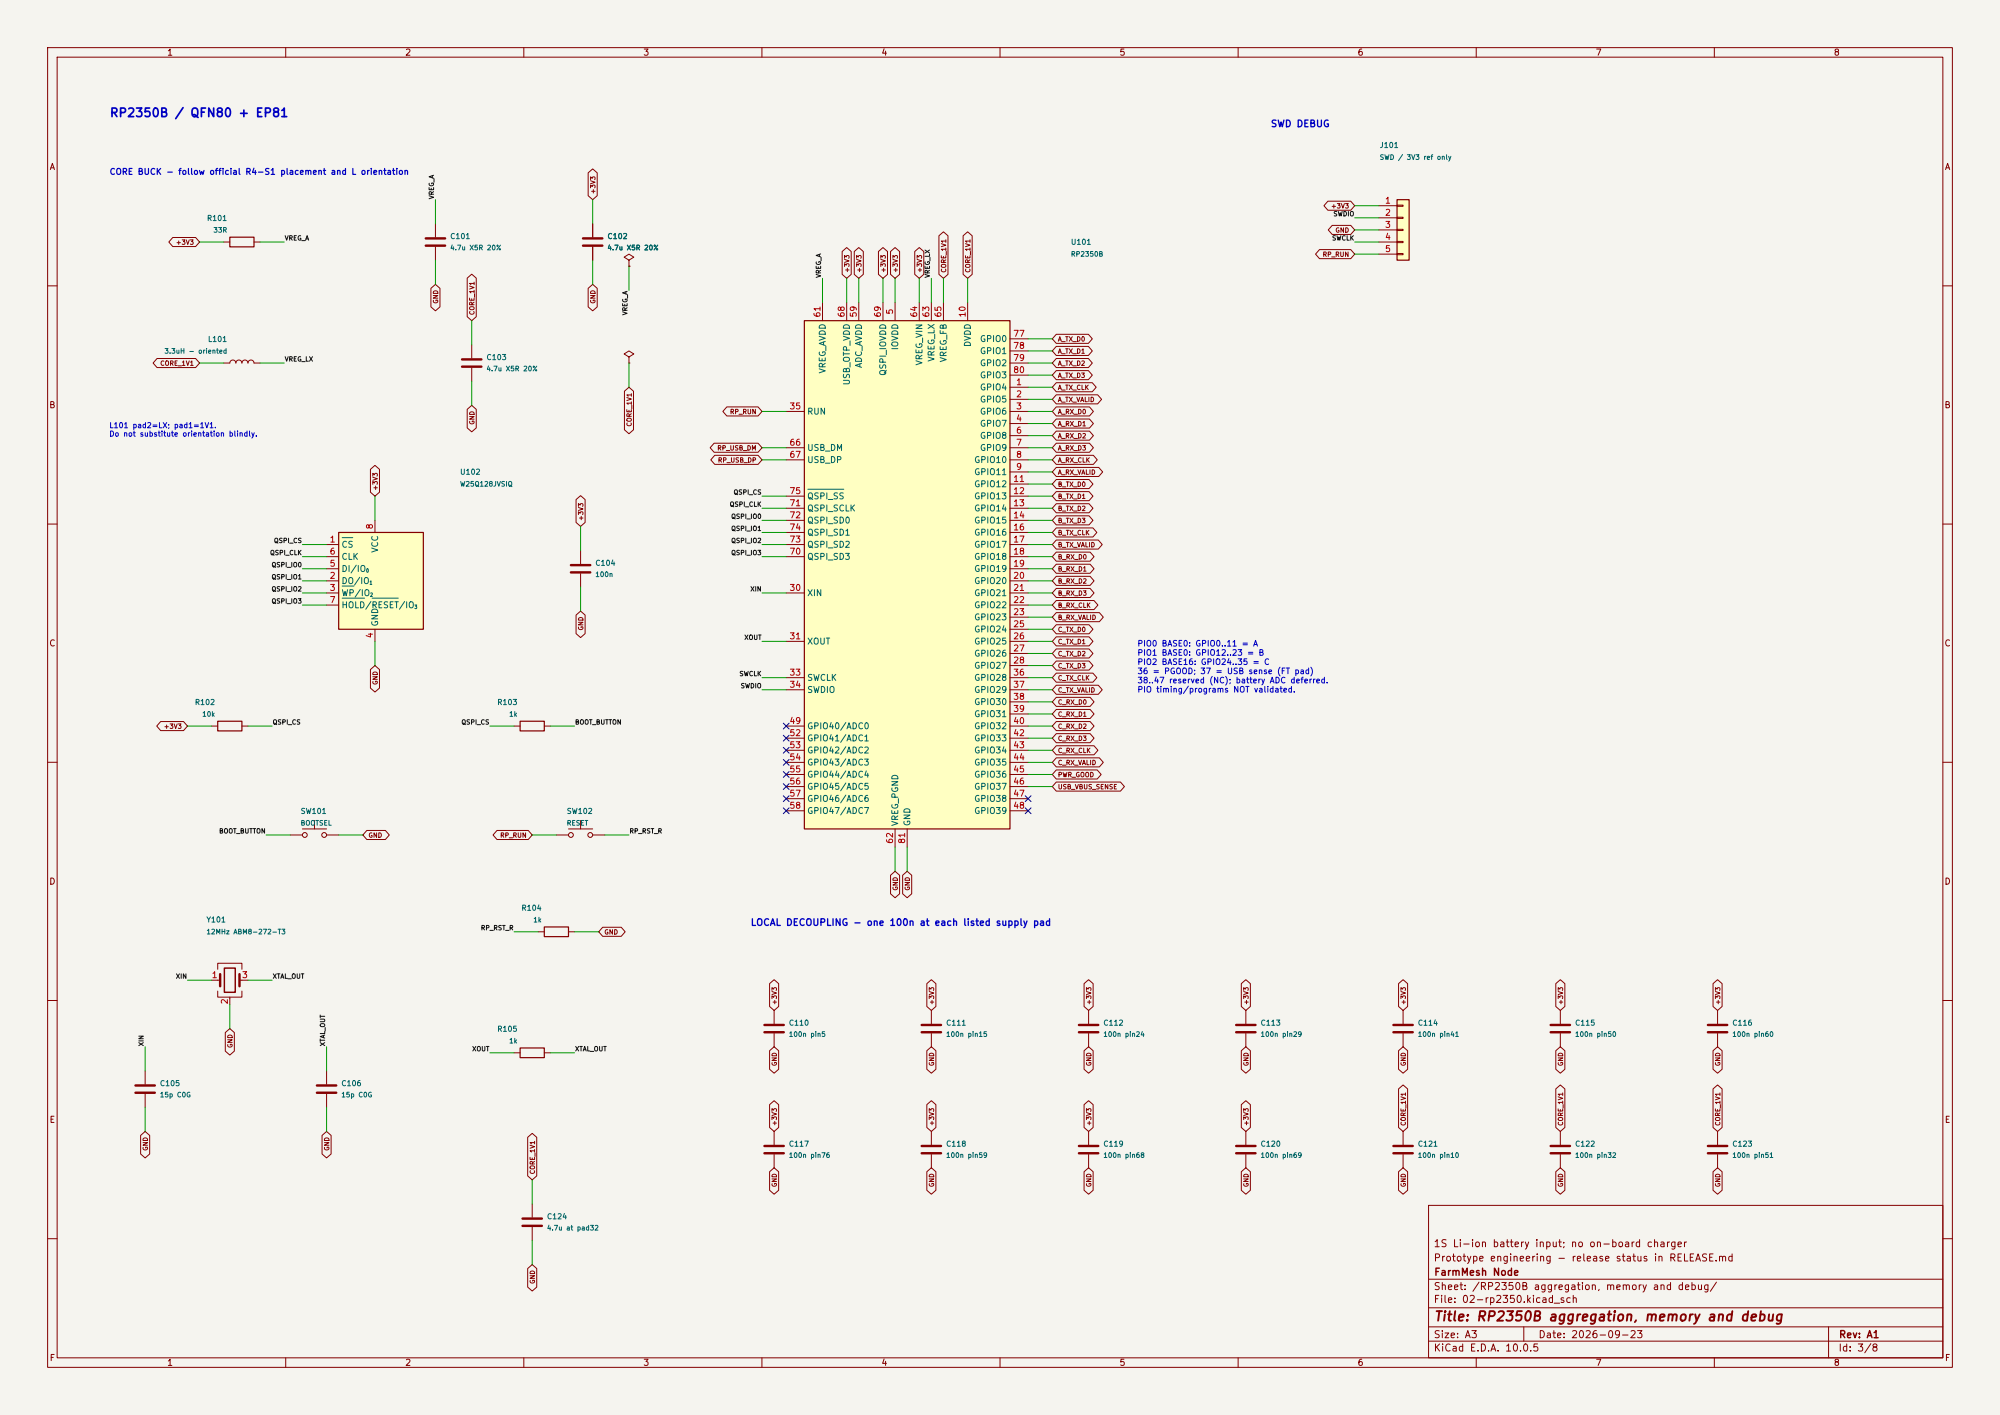
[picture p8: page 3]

CORE BUCK - follow official R4-S1 placement and L orientation

L101 pad2=LX; pad1=1V1. Do not substitute orientation blindly.

4 DI/IO0 5 CLK 6 HOLD/RESET/IO3 7 VCC

PIO2 BASE16: GPIO24..35 = C
36 = PGOOD; 37 = USB sense (FT pad) 38..47 reserved (NC); battery ADC deferred. PIO timing/programs NOT validated.

LOCAL DECOUPLING - one 100n at each listed supply pad

1S Li-ion battery input; no on-board charger
Prototype engineering - release status in RELEASE.md
FarmMesh Node
Sheet: /RP2350B aggregation, memory and debug/
File: 02-rp2350.kicad_sch
Title: RP2350B aggregation, memory and debug

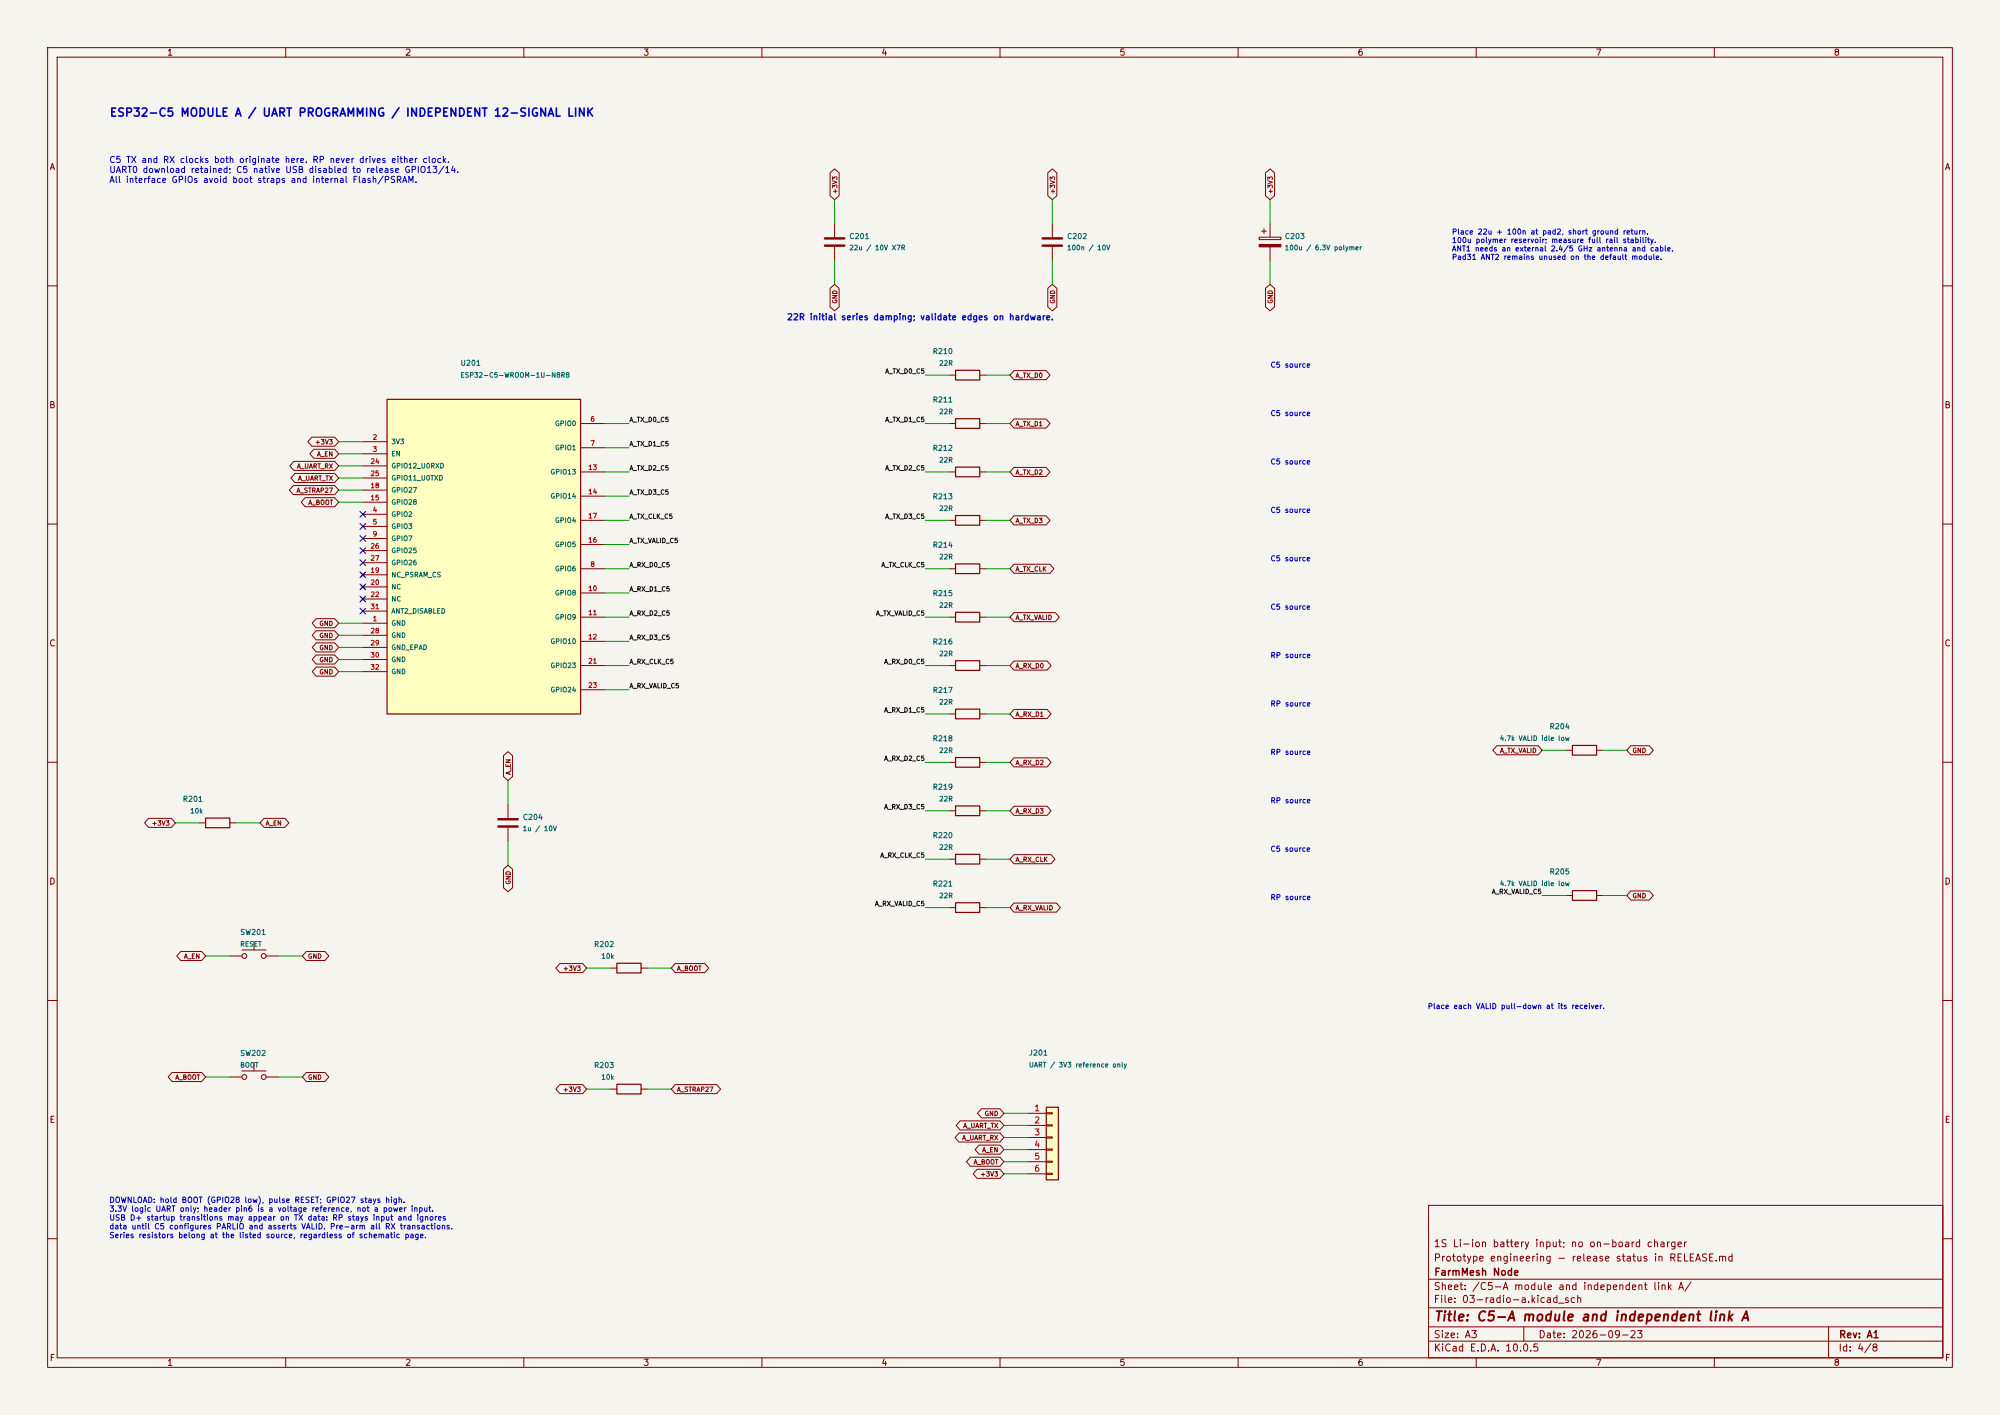
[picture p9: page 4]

ESP32-C5 MODULE A / UART PROGRAMMING / INDEPENDENT 12-SIGNAL LINK

DOWNLOAD: hold BOOT (GPIO28 low), pulse RESET; GPIO27 stays high. 3.3V logic UART only; header pin6 is a voltage reference, not a power input. USB D+ startup transitions may appear on TX data: RP stays input and ignores data until C5 configures PARLIO and asserts VALID. Pre-arm all RX transactions. Series resistors belong at the listed source, regardless of schematic page.

1S Li-ion battery input; no on-board charger
Prototype engineering - release status in RELEASE.md
FarmMesh Node
Sheet: /C5-A module and independent link A/
File: 03-radio-a.kicad_sch
Title: C5-A module and independent link A

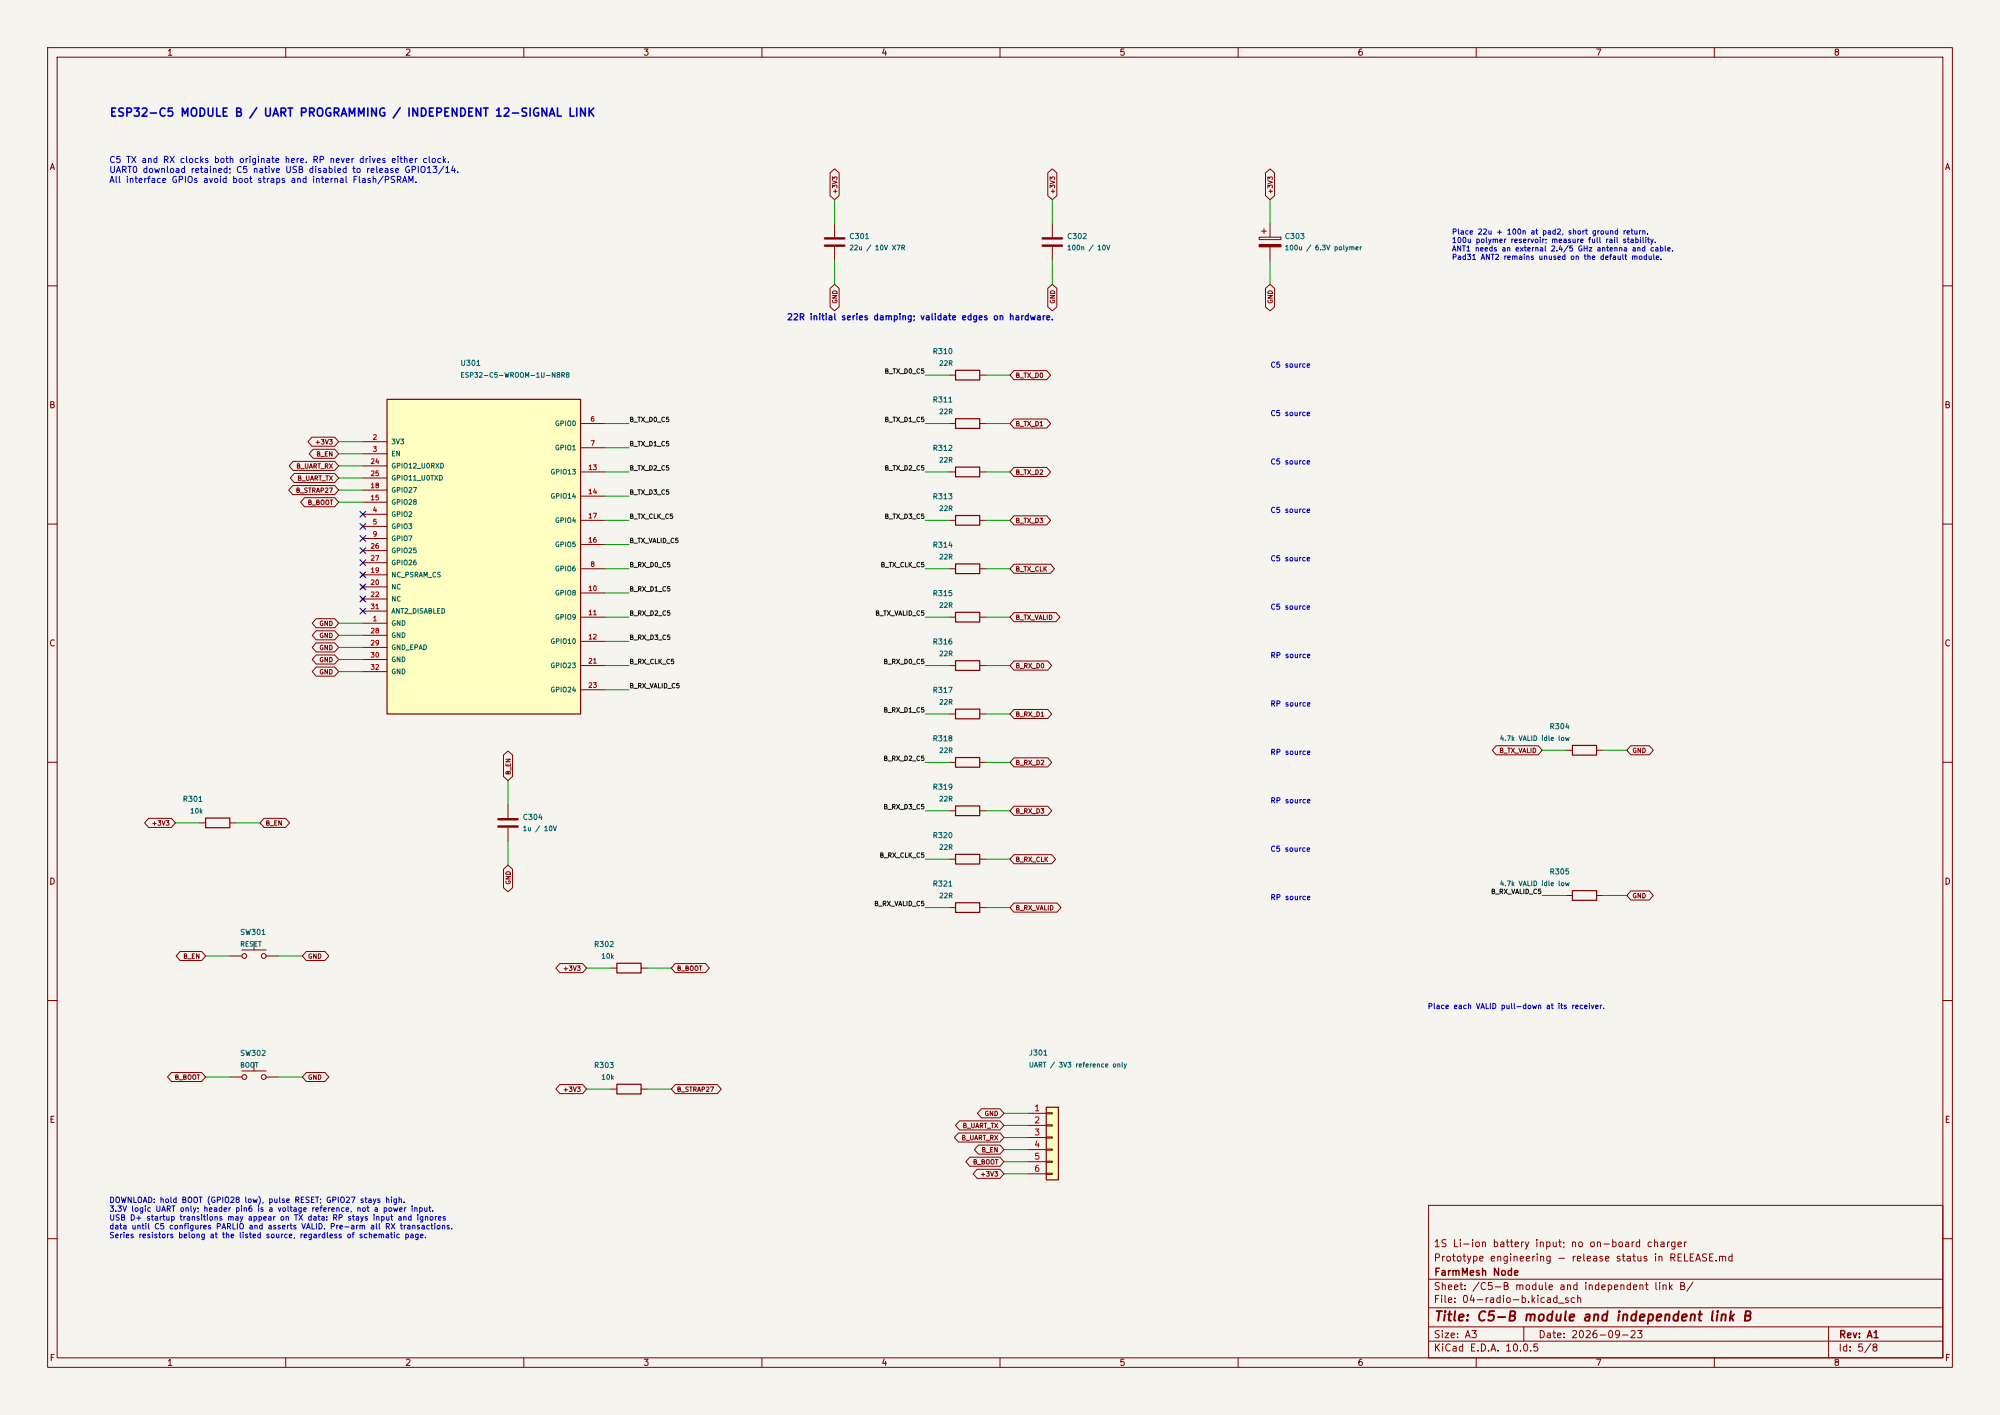
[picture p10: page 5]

ESP32-C5 MODULE B / UART PROGRAMMING / INDEPENDENT 12-SIGNAL LINK

RP source RP source 22R initial series damping; validate edges on hardware.

1S Li-ion battery input; no on-board charger
Prototype engineering - release status in RELEASE.md
FarmMesh Node
Sheet: /C5-B module and independent link B/
File: 04-radio-b.kicad_sch
Title: C5-B module and independent link B

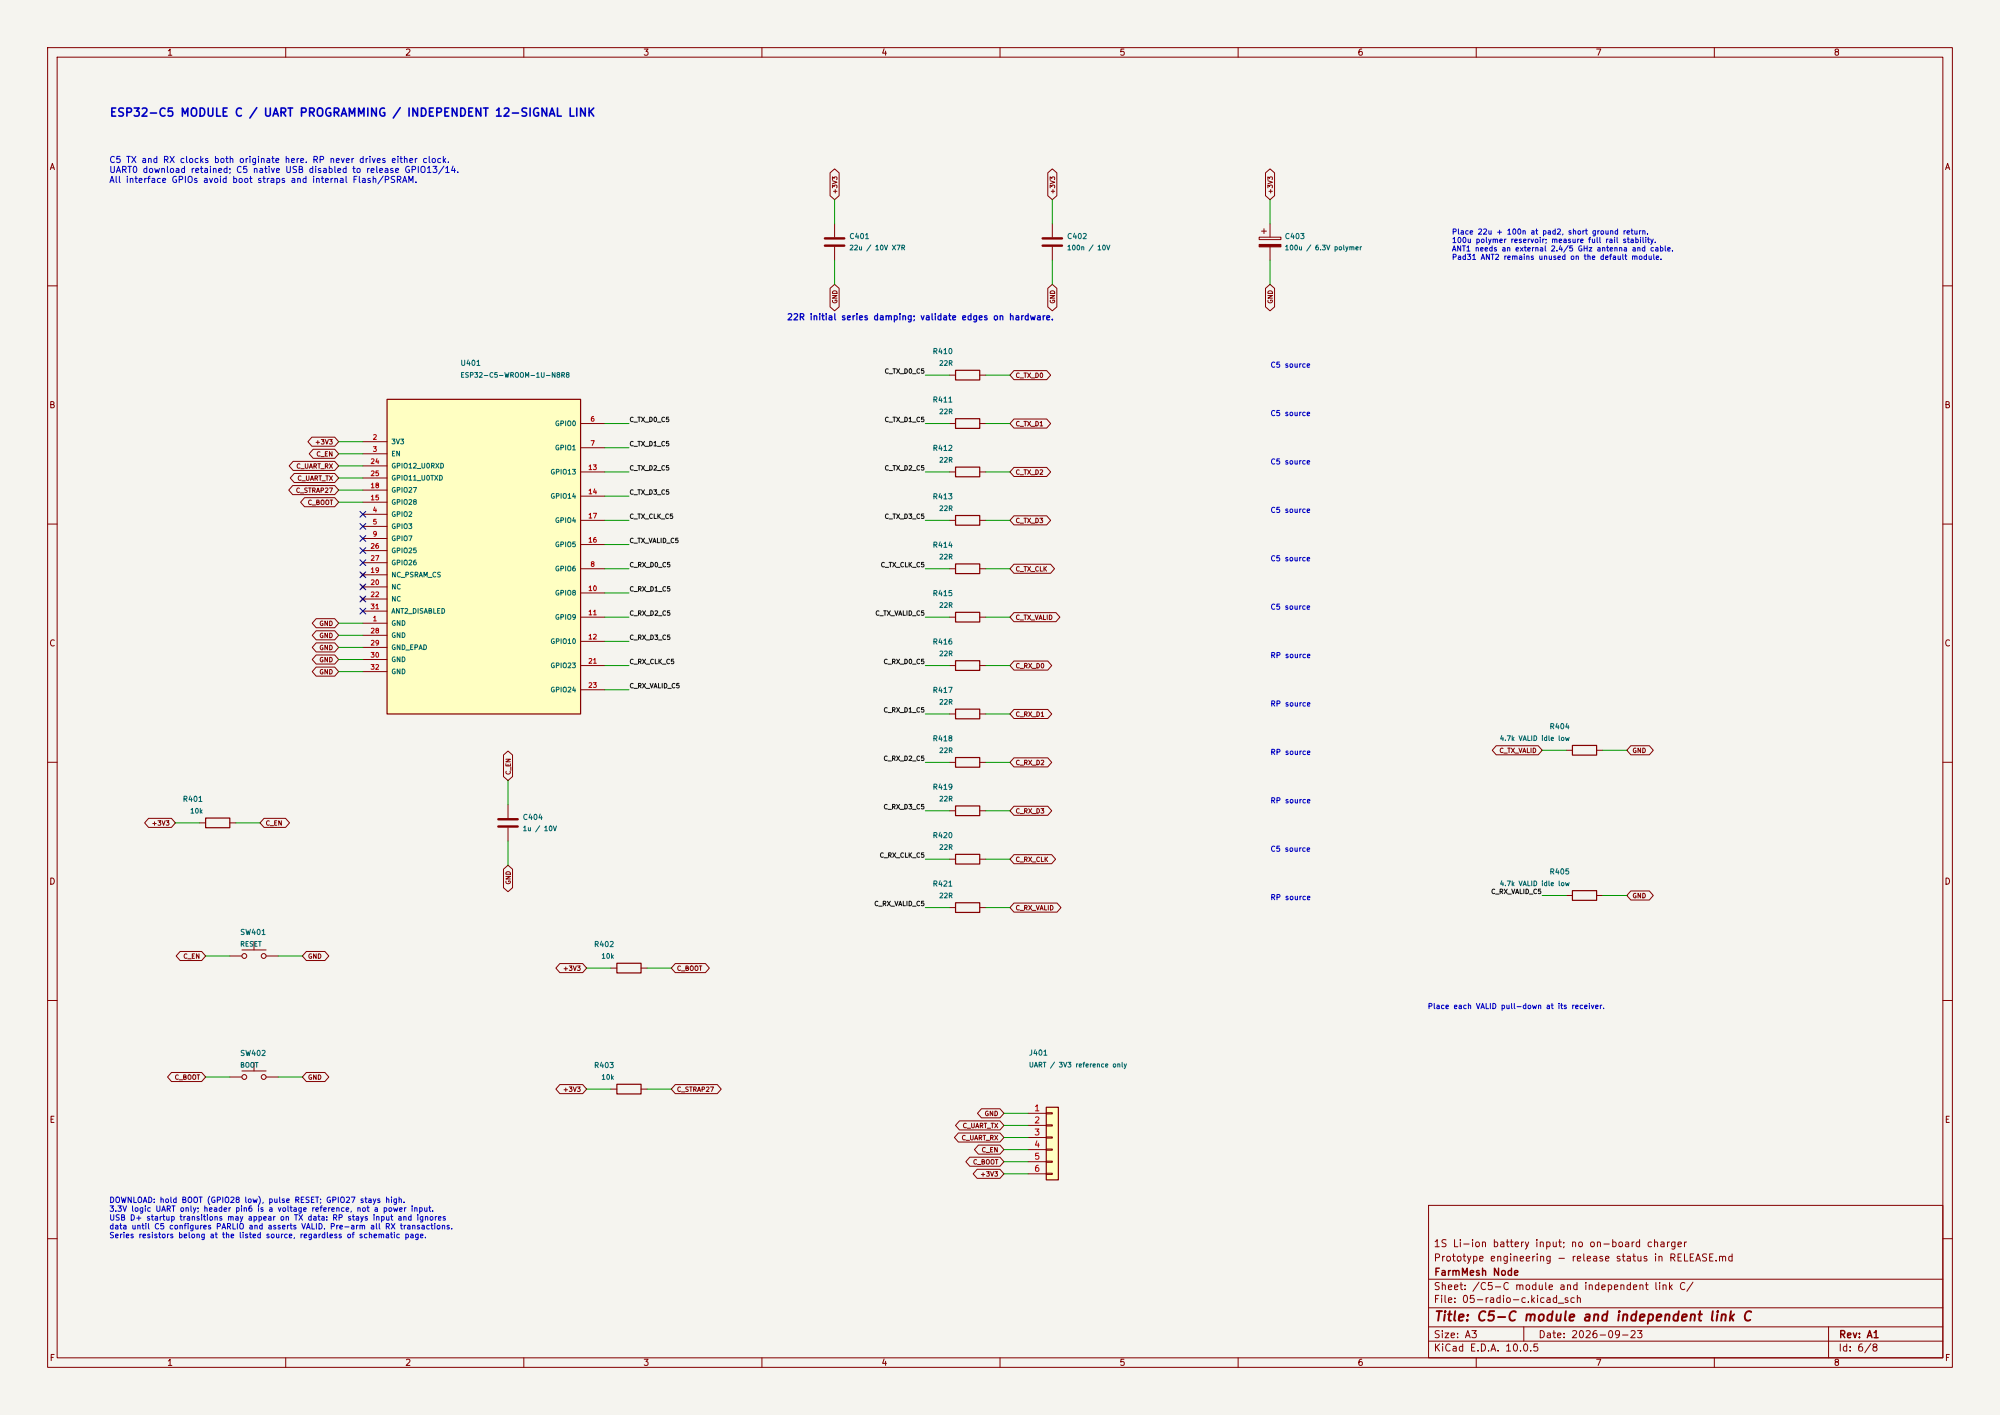
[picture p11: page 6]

C5 source C5 source C5 source ESP32-C5 MODULE C / UART PROGRAMMING / INDEPENDENT 12-SIGNAL LINK

C5 source RP source C5 source RP source RP source RP source

DOWNLOAD: hold BOOT (GPIO28 low), pulse RESET; GPIO27 stays high. 3.3V logic UART only; header pin6 is a voltage reference, not a power input. USB D+ startup transitions may appear on TX data: RP stays input and ignores data until C5 configures PARLIO and asserts VALID. Pre-arm all RX transactions. Series resistors belong at the listed source, regardless of schematic page.

1S Li-ion battery input; no on-board charger
Prototype engineering - release status in RELEASE.md
FarmMesh Node
Sheet: /C5-C module and independent link C/
File: 05-radio-c.kicad_sch
Title: C5-C module and independent link C

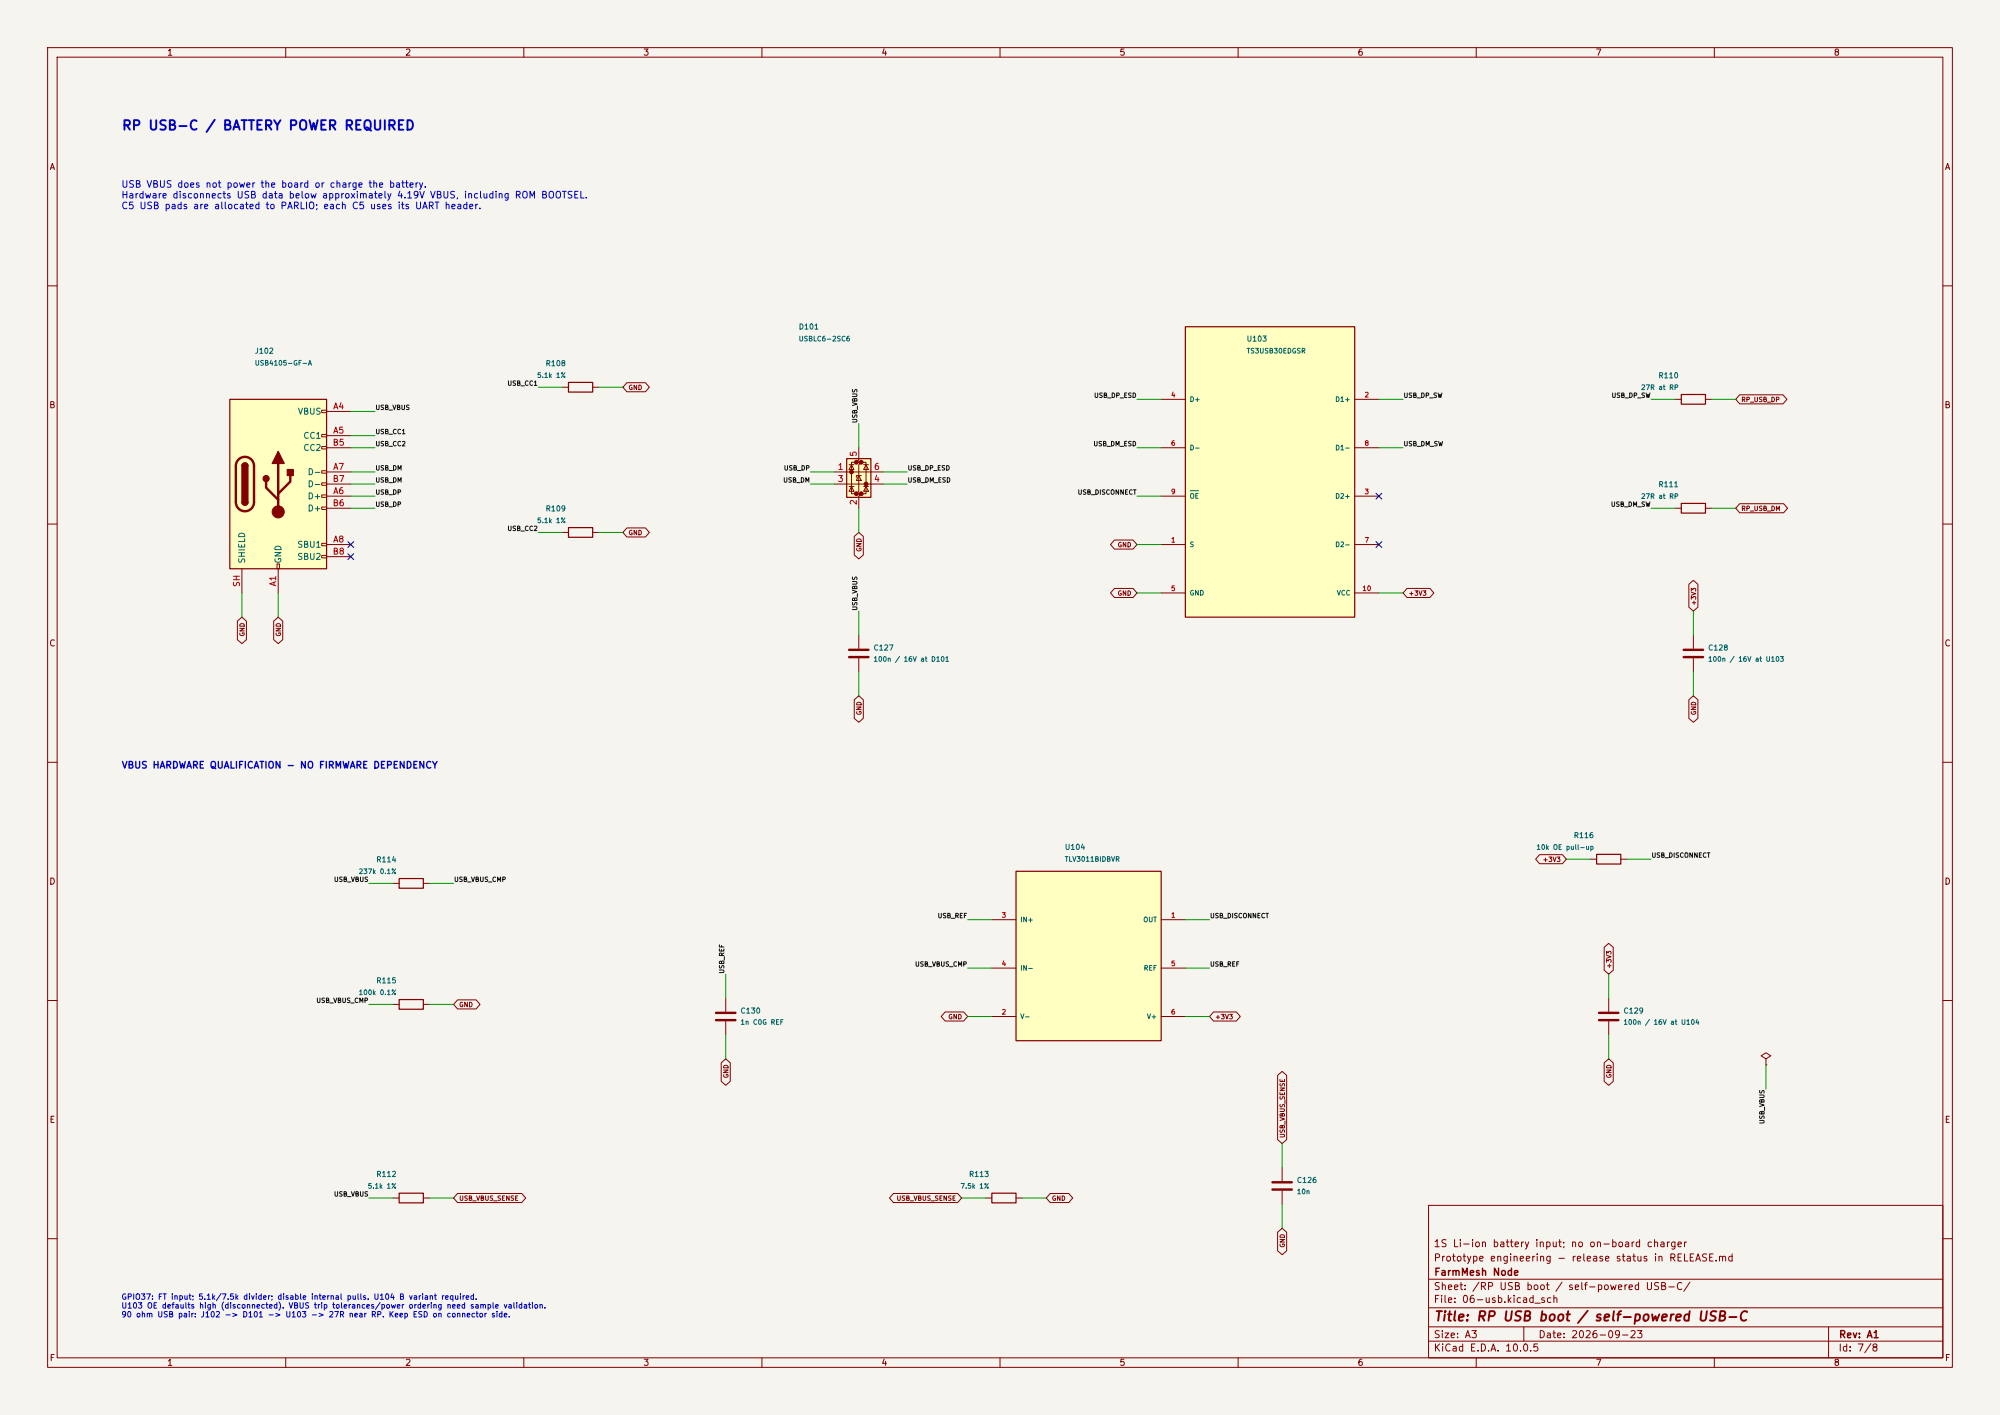
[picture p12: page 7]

RP USB-C / BATTERY POWER REQUIRED

USB VBUS does not power the board or charge the battery. Hardware disconnects USB data below approximately 4.19V VBUS, including ROM BOOTSEL. C5 USB pads are allocated to PARLIO; each C5 uses its UART header. VBUS HARDWARE QUALIFICATION - NO FIRMWARE DEPENDENCY

1S Li-ion battery input; no on-board charger C130

Prototype engineering - release status in RELEASE.md
FarmMesh Node
Sheet: /RP USB boot / self-powered USB-C/
File: 06-usb.kicad_sch
Title: RP USB boot / self-powered USB-C

GPIO37: FT input; 5.1k/7.5k divider; disable internal pulls. U104 B variant required. U103 OE defaults high (disconnected). VBUS trip tolerances/power ordering need sample validation. 90 ohm USB pair: J102 -> D101 -> U103 -> 27R near RP. Keep ESD on connector side.

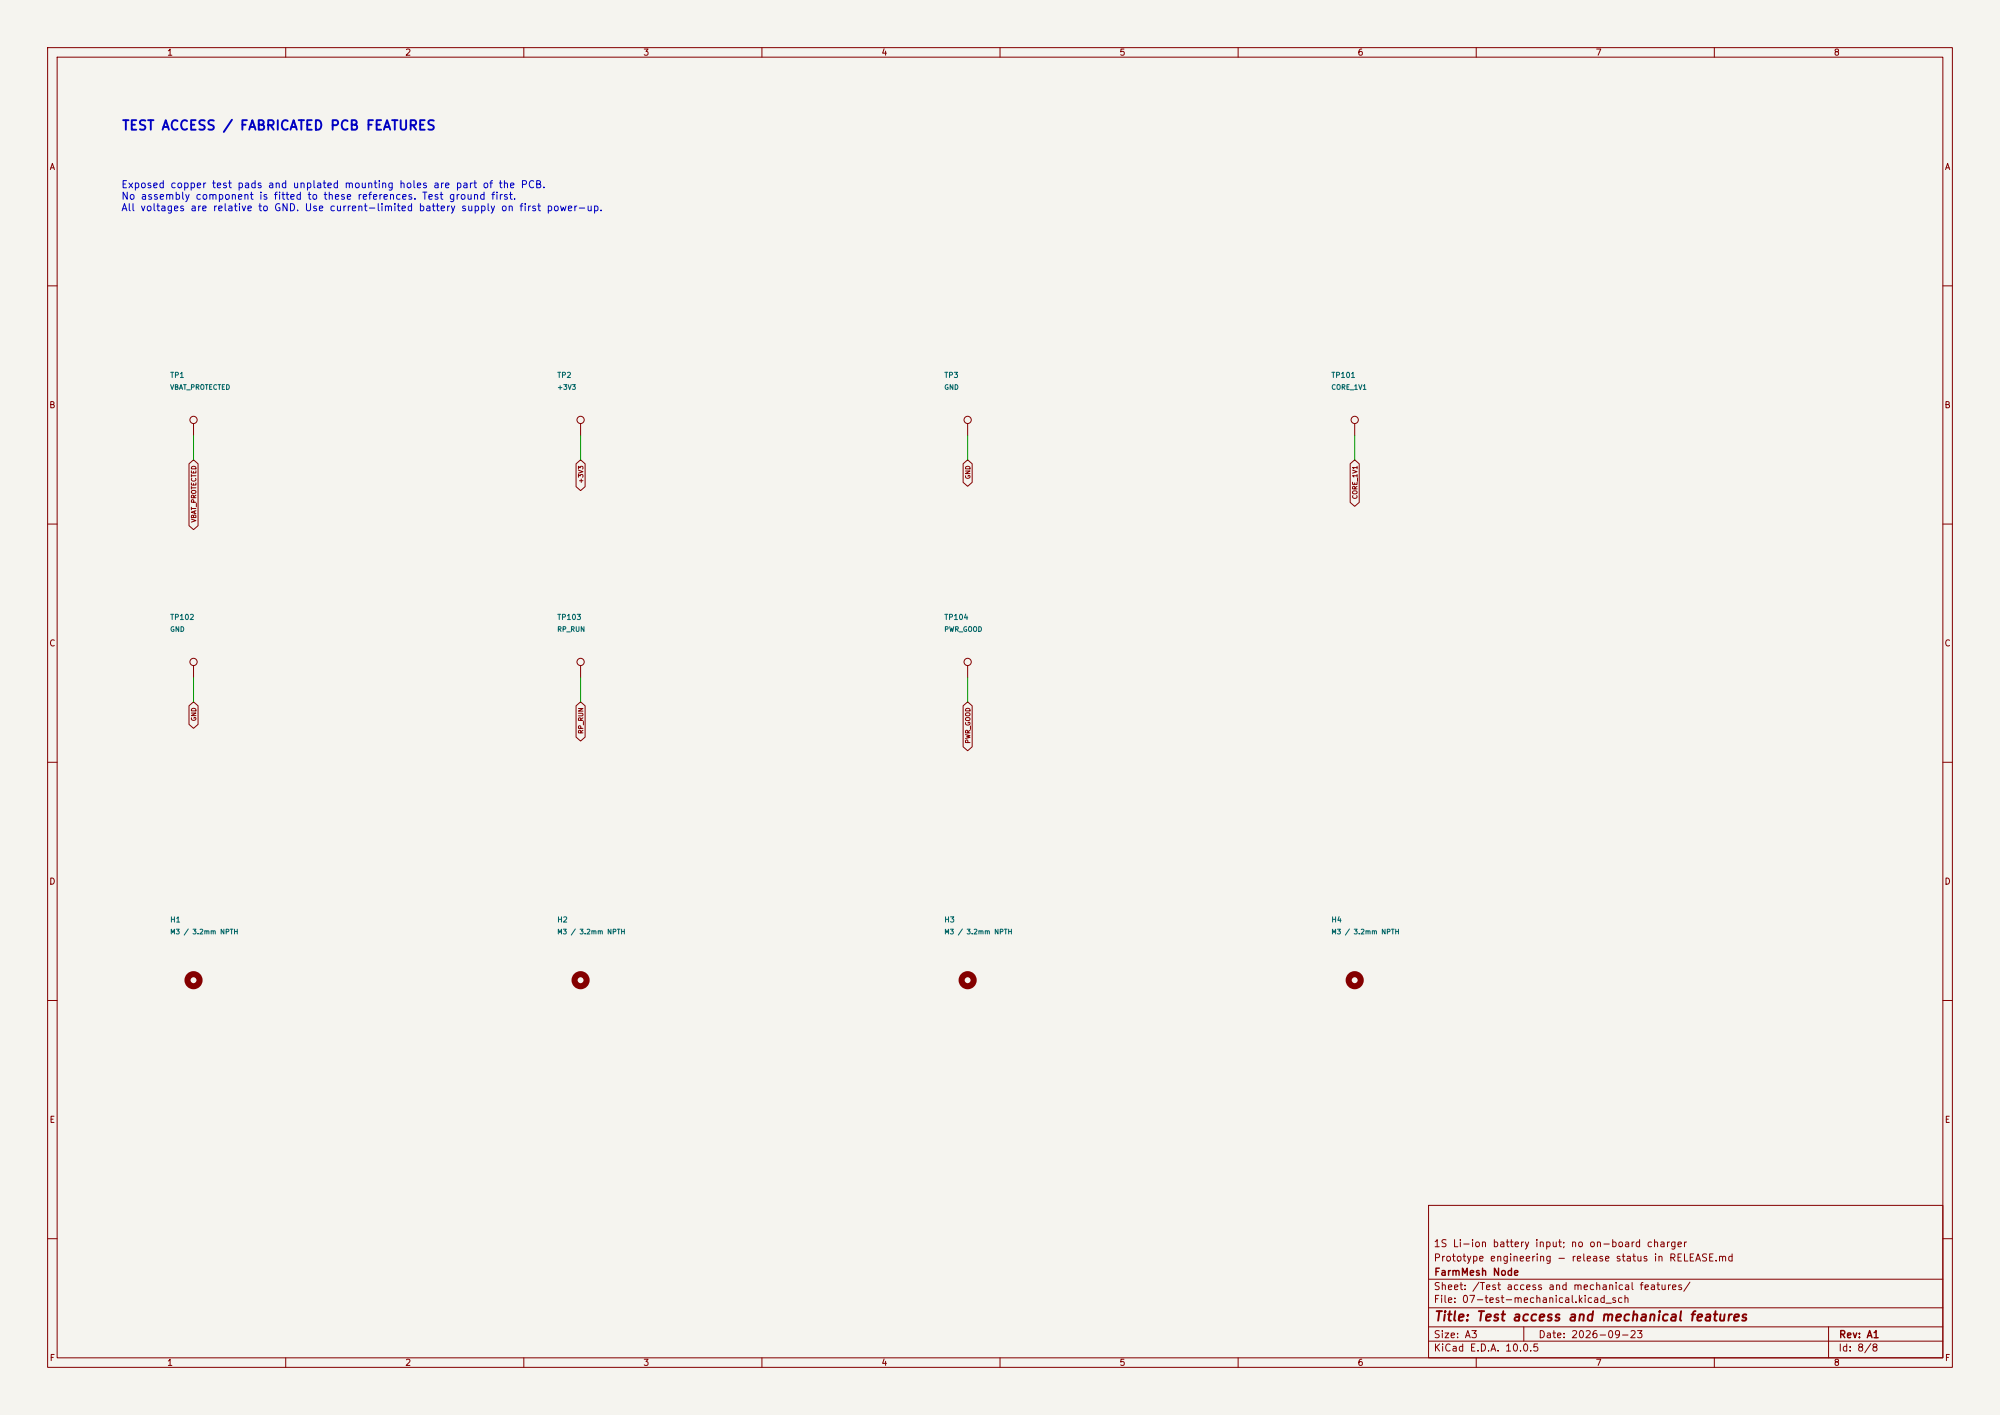
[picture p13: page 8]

TEST ACCESS / FABRICATED PCB FEATURES

Exposed copper test pads and unplated mounting holes are part of the PCB.
No assembly component is fitted to these references. Test ground first.
All voltages are relative to GND. Use current-limited battery supply on first power-up.

1S Li-ion battery input; no on-board charger
Prototype engineering - release status in RELEASE.md
FarmMesh Node
Sheet: /Test access and mechanical features/
File: 07-test-mechanical.kicad_sch
Title: Test access and mechanical features

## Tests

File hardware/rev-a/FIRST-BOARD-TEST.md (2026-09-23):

# FarmMesh Node A1 — 首板分阶段验收 / First-board staged acceptance

**状态 / Status: TEST PLAN — NOT EXECUTED / 验收计划，尚未执行。**

日期 / Date: 2026-09-23。本文不包含实测结果，也不保证 2.2 A、3 A、USB 或无线吞吐已经达到。记录板号、制造包版本/哈希、BOM 替代料、RP2350 silicon revision、固件与工具版本、仪器/探头、环境温度、输入线长、负载设置及波形文件。每阶段通过后再进入下一阶段；失败时保留证据并断电排查，不靠提高限流掩盖异常。

This is an unexecuted test plan, not a performance certificate. Record board/release identifiers, substitutions, silicon revision, firmware/tool versions, instruments, ambient temperature, input wiring, load settings and waveform files. Resolve failures before advancing. Use the final schematic, [manufacturing specification](FABRICATION.md) and [power review](reports/a1-power-review.md) together with this plan.

## 1. 上电前 / Before power

- 用显微镜检查 QFN/USB/0402 桥连、虚焊、移位；核对所有 IC pin 1、D1/Q1、聚合物电容正极和 L101 定向标记。L101 pad1=CORE_1V1、pad2=LX。核对 ENIG 表面无污染/露铜异常、板厚、USB 机械孔与外侧地焊盘、四个 φ3.2 mm NPTH。隐藏 EP 的装配质量需合适的检查方法；外观看不见不等于焊接合格。
- Microscope-inspect bridges, opens and alignment; check IC pin 1, diode/MOSFET orientation, capacitor polarity and the marked inductor. Check ENIG condition and mechanical fit; inspect hidden exposed-pad joints appropriately.
- 完全断开电池、USB、SWD、UART 与电子负载电源。检查 BAT_PLUS→GND、TP1→GND、TP2→GND、TP101→GND，以及 3V3↔CORE 是否存在持续硬短路。等待电容充电读数稳定、交换表笔观察半导体路径，记录欧姆/二极管档结果；没有适用于所有节点的统一“低于某欧姆即短路”阈值。不要用高压绝缘测试仪测芯片。
- Disconnect every power/data source. Record rail-to-ground and 3V3-to-core resistance/diode readings after charging transients settle. Semiconductor paths make a universal resistance threshold inappropriate; investigate persistent near-zero resistance.
- J1 pin1=BAT_PLUS、pin2=GND，使用合适受保护的常规 1S、4.20 V 最高锂电源。首测使用台式电源。释放任何可能运行发射固件的 C5 之前先接好相应天线。本板没有充电器，USB VBUS 只用于检测/ESD；**USB、SWD 和 UART 的 3V3 参考脚都不是供电入口**。
- J1 is the sole normal power input. USB does not power the board or charge a cell. Debug 3V3 pins are references only. Keep all adapters disconnected during initial rail tests. Attach the antenna before releasing any C5 that may run transmitting firmware.

## 2. 限流上电 / Current-limited bring-up

以下电流均为**台式电源的输入限流**，不是 3V3 输出负载。数值是逐级诊断建议，不是已测空载电流规格。初始设 3.8 V（首测范围 3.6–4.2 V），短粗线接 J1，电源关闭时接线。

These are **input current limits**, not output-current ratings. They are diagnostic starting settings. Start at 3.8 V within the 3.6–4.2 V initial range, using short adequately sized leads connected with the supply disabled.

| 阶段 / Stage | 建议输入限流 / Suggested limit | 操作及通过条件 / Action and gate |
| --- | ---: | --- |
| 转换器关闭 / Converter off | 20 mA | J2 装 OFF 帽；上电检查 TP1 接近输入、3V3 不应被外部供电、无异常发热或持续限流。暂态充电后记录关机电流 / fit J2, check input rail, no back-power or heating; record settled off current |
| 电源及复位 / Rails, reset held | 100 mA；必要时经排查升至 300 mA / then 300 mA after inspection | 断电后将三 C5 EN 拉低并让 RP_RUN 保持低；移除 J2 再上电。检查 3V3、core 和启动波形。充电期间限流不立即等于短路；持续打嗝则先查波形和焊接 / hold resets, remove J2 and inspect rails/startup before increasing limit |
| RP 单独运行 / RP only | 300 mA | 仅释放 RP_RUN，其余 C5 保持复位；读取 SWD/ROM，记录输入电流和温度 / release RP only, verify SWD/ROM |
| 单个 C5 / One C5 | 先 1.0 A，确认后最多 1.5 A / 1.0 A then up to 1.5 A | 每次只释放一个模组，先 UART ROM/无 RF 固件，再受控 RF；确认电流变化与活动一致 / enable one module at a time, ROM/no-RF first |
| 系统及负载 / System and load | 依据实测功耗逐步升至 3.5 A；低压 3 A 输出脉冲试验可需 4.5 A / up to 3.5 A, or 4.5 A for validated low-input pulses | 只在前级通过后进行；不能超过线束、连接器、电源和保护路径能力 / only after previous stages pass and test path supports the current |

临时复位夹具只接指定 EN/RUN 与 GND，避免误碰 3V3；RP 可用 J101 pin5 或 SW102，C5 可用对应 UART pin4 或 RESET。记录夹具接法。RUN 拉低不是 RP buck 断电，core 仍应检查。出现输出过压、持续限流、冒烟/异味或温度快速上升即断电；不要长时间让芯片在反复 brownout 中运行。

Connect reset fixtures only to the identified reset nets and ground, and document them. RP RUN reset does not disable its switching regulator. Stop for unexpected overvoltage, persistent current limiting or rapid heating. Do not use repeated brownout as normal operation.

## 3. 测点和启动预期 / Test points and expected nominal behavior

| 测量 / Measurement | 位置 / Access | 名义预期及限制 / Nominal expectation and limit |
| --- | --- | --- |
| 输入 / Protected input | TP1 对 TP3 / TP1 to TP3 | 接近 J1 输入减去 F1/Q1/线损；记录启动和加载压降 / near input minus protection/wiring loss |
| 主轨 / Main rail | TP2 对 TP3；再测 C201/C301/C401 正端与就近地 / then each module local supply | `0.795×(1+316/100)=3.3072 V` nominal；每个 C5 端包括瞬态维持 3.0–3.6 V；最终稳定目标应比此工作极限留余量 / retain margin inside the operating range |
| RP core | TP101 对 TP102 / TP101 to TP102 | 默认约 1.1 V；记录纹波/启动，不擅自提高 core 或超频 / approximately 1.1 V default; no initial overclocking |
| RP reset | TP103 或 J101 pin5 / TP103 or J101 pin5 | 释放时接近 3V3，按 SW102 应变低并触发复位 / high when released, low on reset |
| PGOOD | TP104 | 稳压后由 R6 拉至 3V3；输出欠压应变低；不能代替高速示波器抓取短毛刺 / high when regulated; not a substitute for ripple captures |
| 转换器 RUN / Converter RUN | J2 pin1，参考 J2 pin2 GND / J2 pin1 to pin2 | J2 开路约 `VIN/2.74`，含小滞回电流修正；短接 J2 接近 0 V，停止转换 / divider level when open, low with OFF shunt |
| UVLO | 同时记录 TP1、J2 pin1、TP2、TP104 / capture together | 输入上升启动约 3.30 V、下降停止约 3.01 V；受器件/阻值公差及输入压降影响 / nominal only |
| USB reference / OE | U104 pin5、U103 pin9 / use fine probes | 有 3V3 时 REF≈1.242 V；无 VBUS 时 OE≈3V3、断连；有效 VBUS 时 OE 低 / reference and disconnected/enabled states |

电源输出、RUN 阈值和 PGOOD 依据 [LTC3119 电气表及应用说明](https://www.analog.com/media/en/technical-documentation/data-sheets/3119fb.pdf)；core/reset/ROM 依据 [RP2350 datasheet](https://datasheets.raspberrypi.com/rp2350/rp2350-datasheet.pdf)。C5 供电范围依据 [模组 datasheet](https://www.espressif.com/sites/default/files/documentation/esp32-c5-wroom-1_wroom-1u_datasheet_en.pdf)。所有名义值均待实测，电池 ADC 本版没有安装，不能用软件读取代替这些测量。

Nominal targets follow the cited device documents and actual resistor values. There is no battery ADC circuit in this revision; software cannot replace the input-voltage measurements.

## 4. RP2350 SWD、Flash 和 USB ROM / RP debug and ROM

J101 针序 / pinout: **1=3V3 reference, 2=SWDIO, 3=GND, 4=SWCLK, 5=RUN**。使用支持 RP2350 的探针/软件，先低速 SWD 连接、读芯片和复位状态，再运行 RAM 小程序、测试外部 W25Q128JVSIQ（标称 16 MB）读写。记录工具与二进制哈希。初始不编程 OTP/security bits；读取 silicon revision，优先验证 A3/A4，但不能因偏好批次忽略 A2 的输入泄漏约束。

Use an RP2350-capable probe at a conservative SWD clock. Identify silicon, test a RAM program, then validate the external flash. Do not program irreversible OTP/security settings during bring-up. Keep the three C5 devices reset for these initial tests.

USB BOOTSEL：板由 J1 独立供电；保持 SW101 BOOTSEL，按下/释放 SW102 RESET，复位采样后释放 BOOTSEL。连接带数据线芯的 USB 线，确认 ROM USB/UF2/PICOBOOT 可枚举并完成已知测试镜像传输/校验。重复拔插和复位；本步检验晶振、PHY、mux、ESD 与主机路径，不代表 USB 电气认证。RP 固件必须禁用 GPIO37 内部上下拉。

With J1 power present, hold BOOTSEL while pulsing RESET, then release BOOTSEL after reset sampling. Verify ROM enumeration and a known test-image transfer/checksum. Repeat cable and reset cycles. Disable internal pulls on GPIO37 in application firmware.

## 5. USB 断连和电源顺序 / USB disconnect and power sequencing

使用可观测 VBUS 的 USB breakout，不向计算机端口反送外部电源。先无主机做受控 VBUS 扫描，再接真实主机测功能。记录 USB_VBUS、USB_DISCONNECT/OE、板端和连接器端 D+/D−、3V3。连接器端电平应在明确的主机端负载下判断，浮空探头读数不能证明隔离。

Use a breakout without back-feeding a host. Characterize VBUS switching without a host first, then test real enumeration. Capture VBUS, OE, both sides of the data path and 3V3; judge connector-side levels with a defined host-side termination.

| 电源组合 / Power case | 必须验证 / Required observation |
| --- | --- |
| J1 有电，VBUS=0 / Battery on, VBUS absent | OE 高；包括 ROM BOOTSEL 在内，连接器端不得被 RP 上拉造成假连接，也不得抬高 VBUS / disconnect even while ROM drives its internal pull-up |
| J1 有电，VBUS 正常 / Both present | 门限名义约 4.186 V 后允许连接，正常枚举 / qualify VBUS then enumerate |
| J1 无电，VBUS 正常 / Board off, VBUS present | 3V3/core 不应经 USB 被有效反供；测实际泄漏，不声称数学零 / no meaningful back-power; measure leakage |
| 任一电源先上/先下 / Every power order | 快/慢坡、掉电、重复插拔及阈值附近均无持续误连接/反灌 / no sustained false attach or back-power |

对无 VBUS 的 ROM 模式，**硬件必须断开**，不能依赖 GPIO37 应用固件。TLV3011B 的 POR/fail-safe 与 TS3USB30E 的 Ioff 支持该方案；U103 VCC 推荐工作下限为 3.0 V，0–3.0 V 的欠压过程还需实测，不能把 VCC=0 的 Ioff 指标当整个慢降过程的保证。门限容差估计和器件出处见 [DFM 审阅](reports/a1-dfm-bom-review.md) 与 [电源审阅](reports/a1-power-review.md)。

Hardware must disconnect the connector when VBUS is absent, including ROM operation. Measure brownout behavior as well as fully powered/off states; an Ioff specification at zero supply does not qualify every intermediate voltage.

## 6. 三个 C5 UART 下载 / Three C5 UART programming ports

| 模组 / Module | UART | RESET | BOOT |
| --- | --- | --- | --- |
| A / U201 | J201 | SW201 | SW202 |
| B / U301 | J301 | SW301 | SW302 |
| C / U401 | J401 | SW401 | SW402 |

三个 UART 针序相同 / common pinout: **1=GND, 2=C5 TX → adapter RX, 3=C5 RX ← adapter TX, 4=EN, 5=BOOT/GPIO28, 6=3V3 reference**。适配器只用 3.3 V 逻辑，共地；手动下载通常只接 pin1/2/3，pin6 默认不接。普通 USB-UART 的 3V3/VCC 常是电源输出，不可当 VTref 接入；不接 5 V/供电脚，不假设 DTR/RTS 已具有自动下载电路。

Use 3.3 V UART logic and a common ground. Cross TX/RX as shown. Manual download normally uses pins 1/2/3 only; leave pin6 open unless the instrument has a genuine voltage-reference input. A USB-UART 3V3/VCC output is not VTref. Do not connect adapter power or assume automatic-reset circuitry exists.

逐个模组操作：先维持 RP 接口高阻/复位，其他 C5 复位。按住 BOOT，将 RESET 拉低至少 10 ms 后释放，继续保持 BOOT 约 100 ms 再释放；确认 GPIO27 高。先用支持 ESP32-C5 的 esptool 读取芯片与 flash ID，再烧录明确为 N8R8 配置的最小 UART/无 RF 测试固件并校验；记录 flash/PSRAM 检测结果。正常运行时释放 BOOT 后再次 RESET。[Espressif C5 boot-mode documentation](https://docs.espressif.com/projects/esptool/en/latest/esp32c5/advanced-topics/boot-mode-selection.html)。

Test one module at a time with RP pins high impedance and the others reset. Hold BOOT, pulse RESET low for at least 10 ms, then retain BOOT for about 100 ms after reset release. Verify GPIO27 high. Read identification before flashing a known N8R8 test image; test both flash and PSRAM. Release BOOT and reset for normal execution. These manual timing suggestions are intentionally slow, not throughput requirements.

C5 原生 USB 引脚用于并行总线；本板 C5 不通过 J102 下载。开机 USB D+ 默认行为可能出现在数据引脚上：RP 在 C5 配置完成并有效断言 VALID 之前不得解释这些电平为业务数据。

The C5 native USB pins serve the parallel interface. J102 programs the RP, not the radios. Ignore startup transitions until the interface is configured and VALID is asserted.

## 7. 电流、低压、温升与环路 / Current, undervoltage, thermal and loop tests

先禁用 RF，以已知电子负载检验电源，再加入真实芯片活动。电子负载**吸收**电流，不能把外部电源接到 3V3。TP 只是探测焊盘；大电流负载使用确认能承载电流的电源/地焊接引线或夹具，不让测试点、细探针或单个普通 via 承担 3 A。

Use a sinking electronic load before adding real RF traffic. Do not drive 3V3 from an external source. Attach high-current fixtures to suitable supply/ground copper; tiny test pads and probe leads are measurement access, not a 3 A connector.

1. 从轻载开始，按 **0.2 → 0.6 → 1.2 → 1.8 → 2.2 A 总 3V3 负载**分级。总数包括芯片自身电流，不能在已耗 2.2 A 的板上再加 2.2 A 电子负载。每级记录输入功率、各支路电压、效率与温度。
2. 在 4.2、3.8、3.3 V 以及**实测 UVLO 以上**的低压点重复；低压测试先在 3.8 V 启动后降压。慢扫通过 UVLO 验证关断/恢复滞回、输入线压降和电池/BMS模拟串阻。不宣称 2.8 V 满载工作。
3. **2.2 A 连续是设计验收目标**：保持至热稳定，建议至少 15–30 min，且连续 5 min 温变小于约 1°C；记录环境、风速/外壳、U1/L1/Q1/F1/J1 和三个模组温度。没有经验证的封装热模型时不把表面温度直接等同结温。初测可用 80°C 外壳/器件表面作保守中止点，它不是器件额定值；提高温度/环境范围须另评估。
4. **3 A 是总输出脉冲目标**：先 2.2↔3.0 A、100 µs、约 1% 占空比，波形正常后扩展至 1 ms/10 ms、最高 10% 占空比的明确定义场景；记录实际上升/下降时间和重复率。之后按真实无线包络调整。不能由短脉冲通过推断 3 A 连续额定。
5. 做轻载↔中载、0.6↔1.8 A、1.8↔2.2 A 与上述 3 A 步进；同时观察转换器端及最远模组端。短地弹簧或同轴/差分探头测纹波，记录带宽限制（例如 20 MHz）、另留全带宽异常检查。记录最小/最大电压、振铃衰减、恢复时间；任何持续振荡、反复复位、模块端越出 3.0–3.6 V 均须停测排查。
6. 输出网络包括 220 µF + 3×100 µF 聚合物，以及已查得偏压衰减的陶瓷；保留补偿/负载模型。负载步进正常不能直接宣称相位裕度合格，需要时做正式环路增益测量。Buck/boost 交界、Burst 轻载和低输入都是必测点。

Step through **total** 3V3 loads of 0.2, 0.6, 1.2, 1.8 and 2.2 A, including the board's own current. Repeat at the stated inputs and sweep actual UVLO after starting above its threshold. Characterize 2.2 A until thermal equilibrium; document environmental conditions and surface temperatures without claiming junction temperature. Begin 3 A pulses at 100 µs/1% duty and extend only after clean waveforms, recording duration, duty and slew rate. Measure regulator and remote-module rails using short-ground probes. Stop for sustained oscillation, repeated reset or supply excursions outside the module range. Load-step testing is not a direct phase-margin measurement.

假设效率 80% 时 `Iin=3.3×Iout/(VIN×0.8)`：3.0 V 输入、2.2 A 输出约 3.03 A 输入；3 A 输出约 4.13 A。这是限流/线束规划估计，不是测得效率；不要把输出限流与输入限流混用。

At an assumed 80% efficiency, 3.0 V input requires about 3.03 A for 2.2 A output and 4.13 A for a 3 A pulse. Replace this planning estimate with measured efficiency and current.

## 8. RF、并行链路及结果记录 / RF, parallel links and records

发射前给三个模组分别接好选定 **2.4/5 GHz、50 Ω 天线及 MHF I 同轴**，核对插头完全扣合、线缆应力和天线位置。先单模组、再双模组、最后三模组并发；分别记录 2.4/5 GHz 的信道、带宽、发射功率、距离、环境、丢包/重试/吞吐和电源波形。天线安装、互扰与认证适用范围须独立评价；没有这些条件的“速率数字”不可比较。

Connect the selected dual-band 50 Ω antennas before transmitting. Test one, two, then three radios, documenting RF settings, antenna placement, environment, retries/loss, throughput and rail waveforms. This test does not establish regulatory certification.

本仓库当前硬件不等于已有业务固件。PIO/PARLIO 先以低时钟、单链路、已知计数/CRC 图样测试，再逐级升频；两方向时钟均由该 C5 输出，RP 只驱动 RX_D[3:0]/RX_VALID。接收事务预先排队，验证 VALID 空闲低、复位高阻、启动毛刺屏蔽、丢帧恢复、DMA/FIFO 饥饿，以及每条线在**接收端**的 setup/hold 和阈值。PIO 分组为 BASE0/0/16；WAIT pin 窗口、同步器延迟和每样本指令数由实际程序验证。

There is no validated application firmware yet. Begin with low-clock single-link counter/CRC traffic, then increase rate. Each C5 supplies both clocks; RP drives only its RX data/VALID outputs. Pre-arm receive transactions and verify startup/reset behavior, underrun/overflow handling and timing at each receiver. Verify PIO window/WAIT mapping and actual instruction/synchronizer timing in the implemented programs.

### A1 冻结走线的重点波形 / Priority waveform captures for the frozen A1 routing

本项是 **NOT RUN**。依据 [最终 RF/digital 审阅](reports/a1-rf-digital-review.md)，A1 已接受以下源端绕行和九处回流距离偏差用于受控原型；这不放行额定 50 Mbps 时序。使用低电容探头、短接地弹簧或合适差分探头，记录探头负载；细间距脚采用可靠的探测夹具，避免短接相邻脚。先单链路低时钟，逐级升频，并记录驱动设置。降低时钟频率不等于降低边沿速度，仍须观察过冲、欠冲和振铃。

These are unexecuted acceptance gates for the approved prototype deviations, not a speed qualification. Use low-capacitance probes and short ground connections, document loading/driver settings, and capture source and receiver waveforms before each clock-rate increase. A lower repetition rate does not itself remove fast-edge ringing.

| 重点信号 / Signal | 具体测量位置 / Probe points | 必须记录 / Required evidence |
| --- | --- | --- |
| A_RX_D0：源端 17.185 mm、4 vias | U101.3（RP 源端）；R216.2（电阻源端侧）、R216.1（负载侧）；U201.8（C5 接收端） | 与 A_RX_CLK 同时捕获，比较电阻两侧和接收端过冲、振铃、稳定时间及 setup/hold；此为最高优先级 / highest-priority source-tail and receiver-timing capture |
| A_RX_VALID：12.302 mm、2 vias | U101.9；R221.2 / R221.1；U201.23 | 启动、空闲、稳态和丢帧恢复时的电平、阈值、边沿及 VALID 采样窗口；不得有假断言 / no false or late VALID assertion |
| C_RX_D1：11.778 mm、0 vias；源端直距10.338 mm | U101.39；R417.2 / R417.1；U401.10 | 与 C_RX_CLK 对照的接收端数据眼/阈值及 setup/hold；不要仅凭发送端波形判定 / receiver-side margin, not only source appearance |
| B_TX_CLK：一处换层孔离最近 plated GND 2.318 mm | U301.17；R314.1（源端侧）/R314.2；U101.16（RP 接收端） | 源/收时钟振铃、阈值重复穿越、占空比、相关数据/VALID 的相位与裕量 / clock integrity and related-data timing |
| B_RX_VALID：一处回流邻孔距离3.195 mm | U101.23；R321.2 / R321.1；U301.23 | 接收端 VALID 的稳态及复位恢复时序 / steady-state and reset-recovery VALID timing |

九个超过 **2 mm 项目启发阈值**的网是 A_RX_D0、A_RX_D3、B_RX_D0、B_RX_D1、B_RX_D3、B_RX_VALID、B_TX_CLK、C_RX_D2、C_TX_D2；准确过孔坐标和 2.154–3.425 mm 距离见审阅表。2 mm 不是器件厂商硬限。除了上表重点，完整覆盖这些数据线的接收端时序；多无线并发和低输入电压下复测。下一版优先缩短 RP 到源端电阻的绕行，并在全局布线前保留换层接地空间。

The nine exceptions are accepted only for this controlled prototype. Include every listed receiver in the timing sweep and repeat under concurrent radio activity and low-input conditions. The next layout should shorten RP-to-series tails and reserve return-via access before routing other nets.

每级并行链路时钟测试须同时运行 QSPI/Flash 读写校验或已知数据 CRC/XIP 压力，并由单 C5 扩展至三 C5 并发；记录存储器错误、复位、USB 枚举/传输失败、FIFO/DMA 错误与电源波形。QSPI 区有普通 A 链路走线，晶振负载电容附近有 B.Cu 普通信号经过，故只做独立 Flash 或独立链路测试不足以关闭耦合风险。反复冷启动、热复位、USB ROM 和满活动切换也须通过。不要用高电容普通探头直接加载晶体脚后把异常归因于板子；采用合适的低负载方法或经验证的时钟输出诊断。

At each rate, stress flash/QSPI readback or known-data CRC/XIP while progressing from one to three active radios. Log memory errors, resets, USB failures, DMA/FIFO events and rail waveforms. Repeat cold/warm starts and activity transitions. Unrelated routes exist in the broader flash/crystal area, so isolated subsystem tests are insufficient. Avoid loading the crystal with an unsuitable probe.

若出现接收端阈值重复穿越、采样窗口不足、CRC/Flash 错误或活动相关复位，保留波形并停止升频，先修正路由/终端/驱动/采样策略；不得用提高目标速率或忽略异常关闭验收。功能及有效吞吐只有在这些门槛通过后才能记录为实测。

Stop increasing rate if ringing creates repeated threshold crossings, timing margin is insufficient, data/memory errors occur, or resets correlate with activity. Preserve evidence and correct routing, termination, drive or sampling before claiming measured performance.

每方向四位每时钟的 `4×fCLK` 只是原始位率；有效吞吐还受 VALID 占空比、帧头、CRC、DMA、调度与无线协议开销影响。任何频率、链路或三无线总吞吐数字在测试完成前均为目标。

`4×fCLK` is raw bitrate per direction, not payload throughput. Account for framing, VALID duty, CRC, DMA, scheduling and radio overhead. Frequency and aggregate-throughput figures remain targets until measured.

结果表留空，由测试人员填写 / Complete after testing:

| 阶段 / Stage | 板号、条件和证据 / Board, conditions and evidence | PASS / FAIL / NOT RUN | 负责人、日期 / Owner, date |
| --- | --- | --- | --- |
| 静态/装配 / Static and assembly | | NOT RUN | |
| 启动/电压/UVLO / Power and UVLO | | NOT RUN | |
| RP SWD/Flash/ROM USB | | NOT RUN | |
| USB 电源顺序/断连 / Power order and disconnect | | NOT RUN | |
| C5 A/B/C UART/存储器 / UART and memory | | NOT RUN | |
| 2.2 A 连续/3 A 脉冲/环路 / Load and loop | | NOT RUN | |
| 单/多无线与 PIO/PARLIO / RF and parallel links | | NOT RUN | |

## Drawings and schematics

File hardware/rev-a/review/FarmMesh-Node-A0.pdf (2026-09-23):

1 | 2 | 3 | 4 | 5 | 6 | 7 | 8

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
Size: A3 | Rev: A0 DRAFT | F Date: 2026-09-23
KiCad E.D.A. 10.0.5 | Id: 1/7

# Title: FarmMesh Node - schematic review index

## File: FarmMesh-Node.kicad_sch

## Sheet: /

## FarmMesh Node

## Engineering review only - NOT FOR FABRICATION

## 1S Li-ion battery input; no on-board charger

1S battery input and 3.3V buck-boost File: 01-power.kicad_sch RP2350B aggregation, memory and debug

File: 02-rp2350.kicad_sch | C5-C module and independent link C

File: 05-radio-c.kicad_sch

### C5-A module and independent link A

# File: 03-radio-a.kicad_sch RP USB boot / self-powered USB-C

File: 06-usb.kicad_sch

### C5-B module and independent link B

File: 04-radio-b.kicad_sch Battery: conventional 4.20V-max Li-ion, NOT LiFePO4 or HV Li-ion. Normal loaded operation about 3.0-4.2V; cold start about 3.3V. External protected pack required. No on-board charger or PV input. PCB placement, RF isolation, converter stability and throughput unvalidated. See DESIGN-NOTES.md and reports/erc.json before any layout or procurement.

## INTERFACE CONVENTION

## 1 x RP2350B + 3 x ESP32-C5-WROOM-1U-N8R8 1S protected Li-ion input; 3.3V regulated rail Native KiCad 10 schematic - engineering review only

# FarmMesh Node / Revision A0 - DRAFT

TX / RX are named from the C5 perspective.
Both TX_CLK and RX_CLK originate at that C5.
RP drives only RX_D[0..3] and RX_VALID.
Global net labels make the electrical sheet connections. No wireless protocol is selected by this schematic.

## REVIEW BOUNDARIES

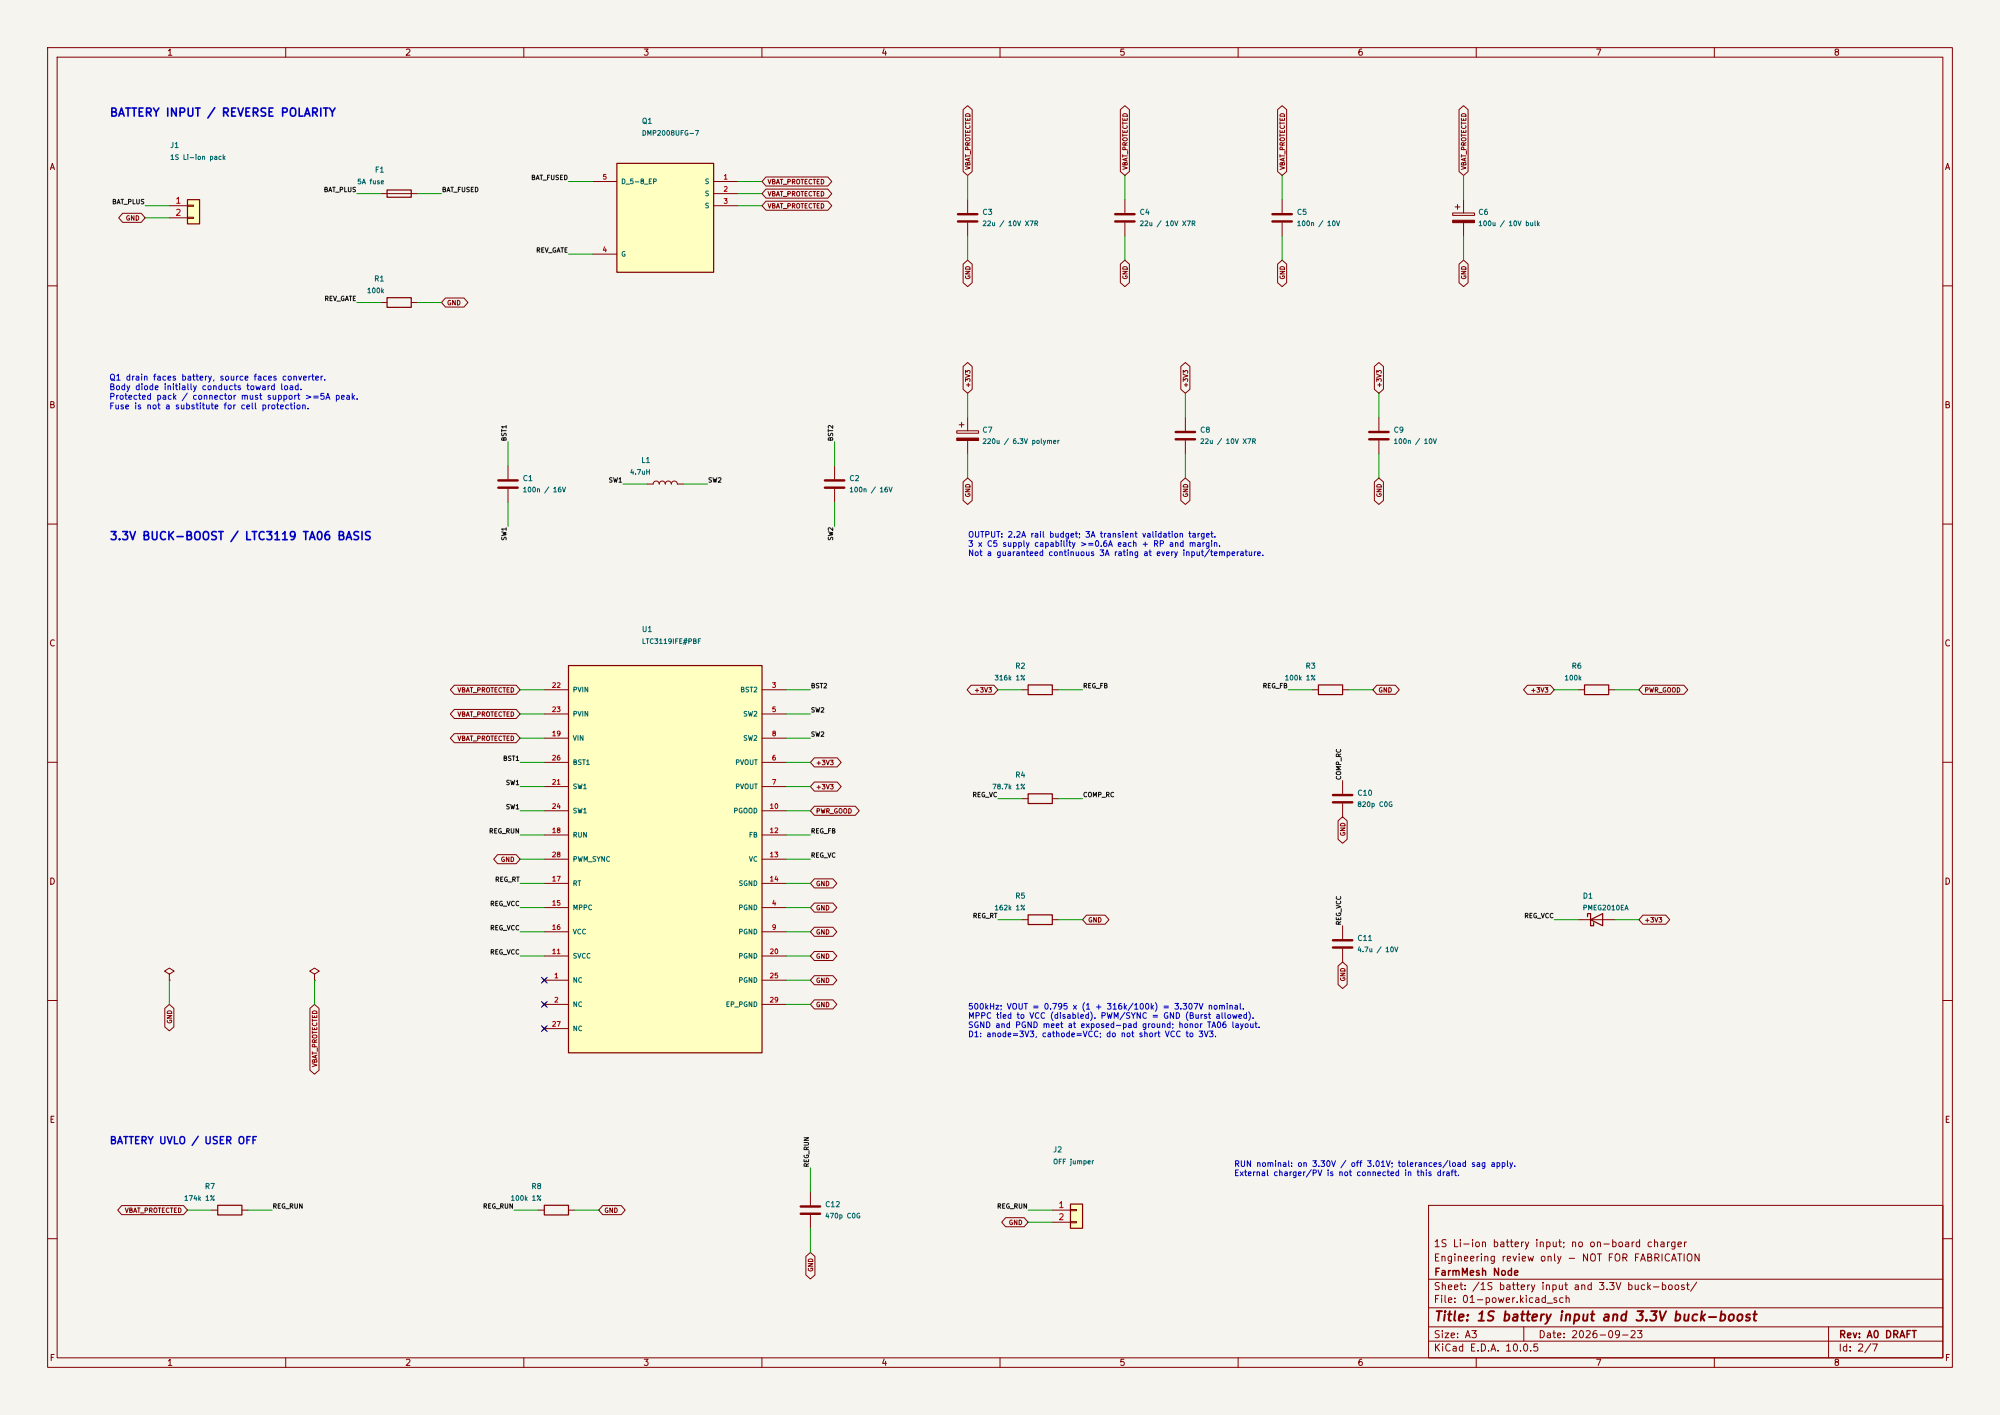
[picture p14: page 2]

BATTERY INPUT / REVERSE POLARITY
REV_GATE BAT_FUSED

Q1 drain faces battery, source faces converter. Body diode initially conducts toward load. Protected pack / connector must support >=5A peak. Fuse is not a substitute for cell protection.

OUTPUT: 2.2A rail budget; 3A transient validation target. 3 x C5 supply capability >=0.6A each + RP and margin. Not a guaranteed continuous 3A rating at every input/temperature.

1S Li-ion battery input; no on-board charger R7

Engineering review only - NOT FOR FABRICATION
FarmMesh Node
Sheet: /1S battery input and 3.3V buck-boost/
File: 01-power.kicad_sch
Title: 1S battery input and 3.3V buck-boost

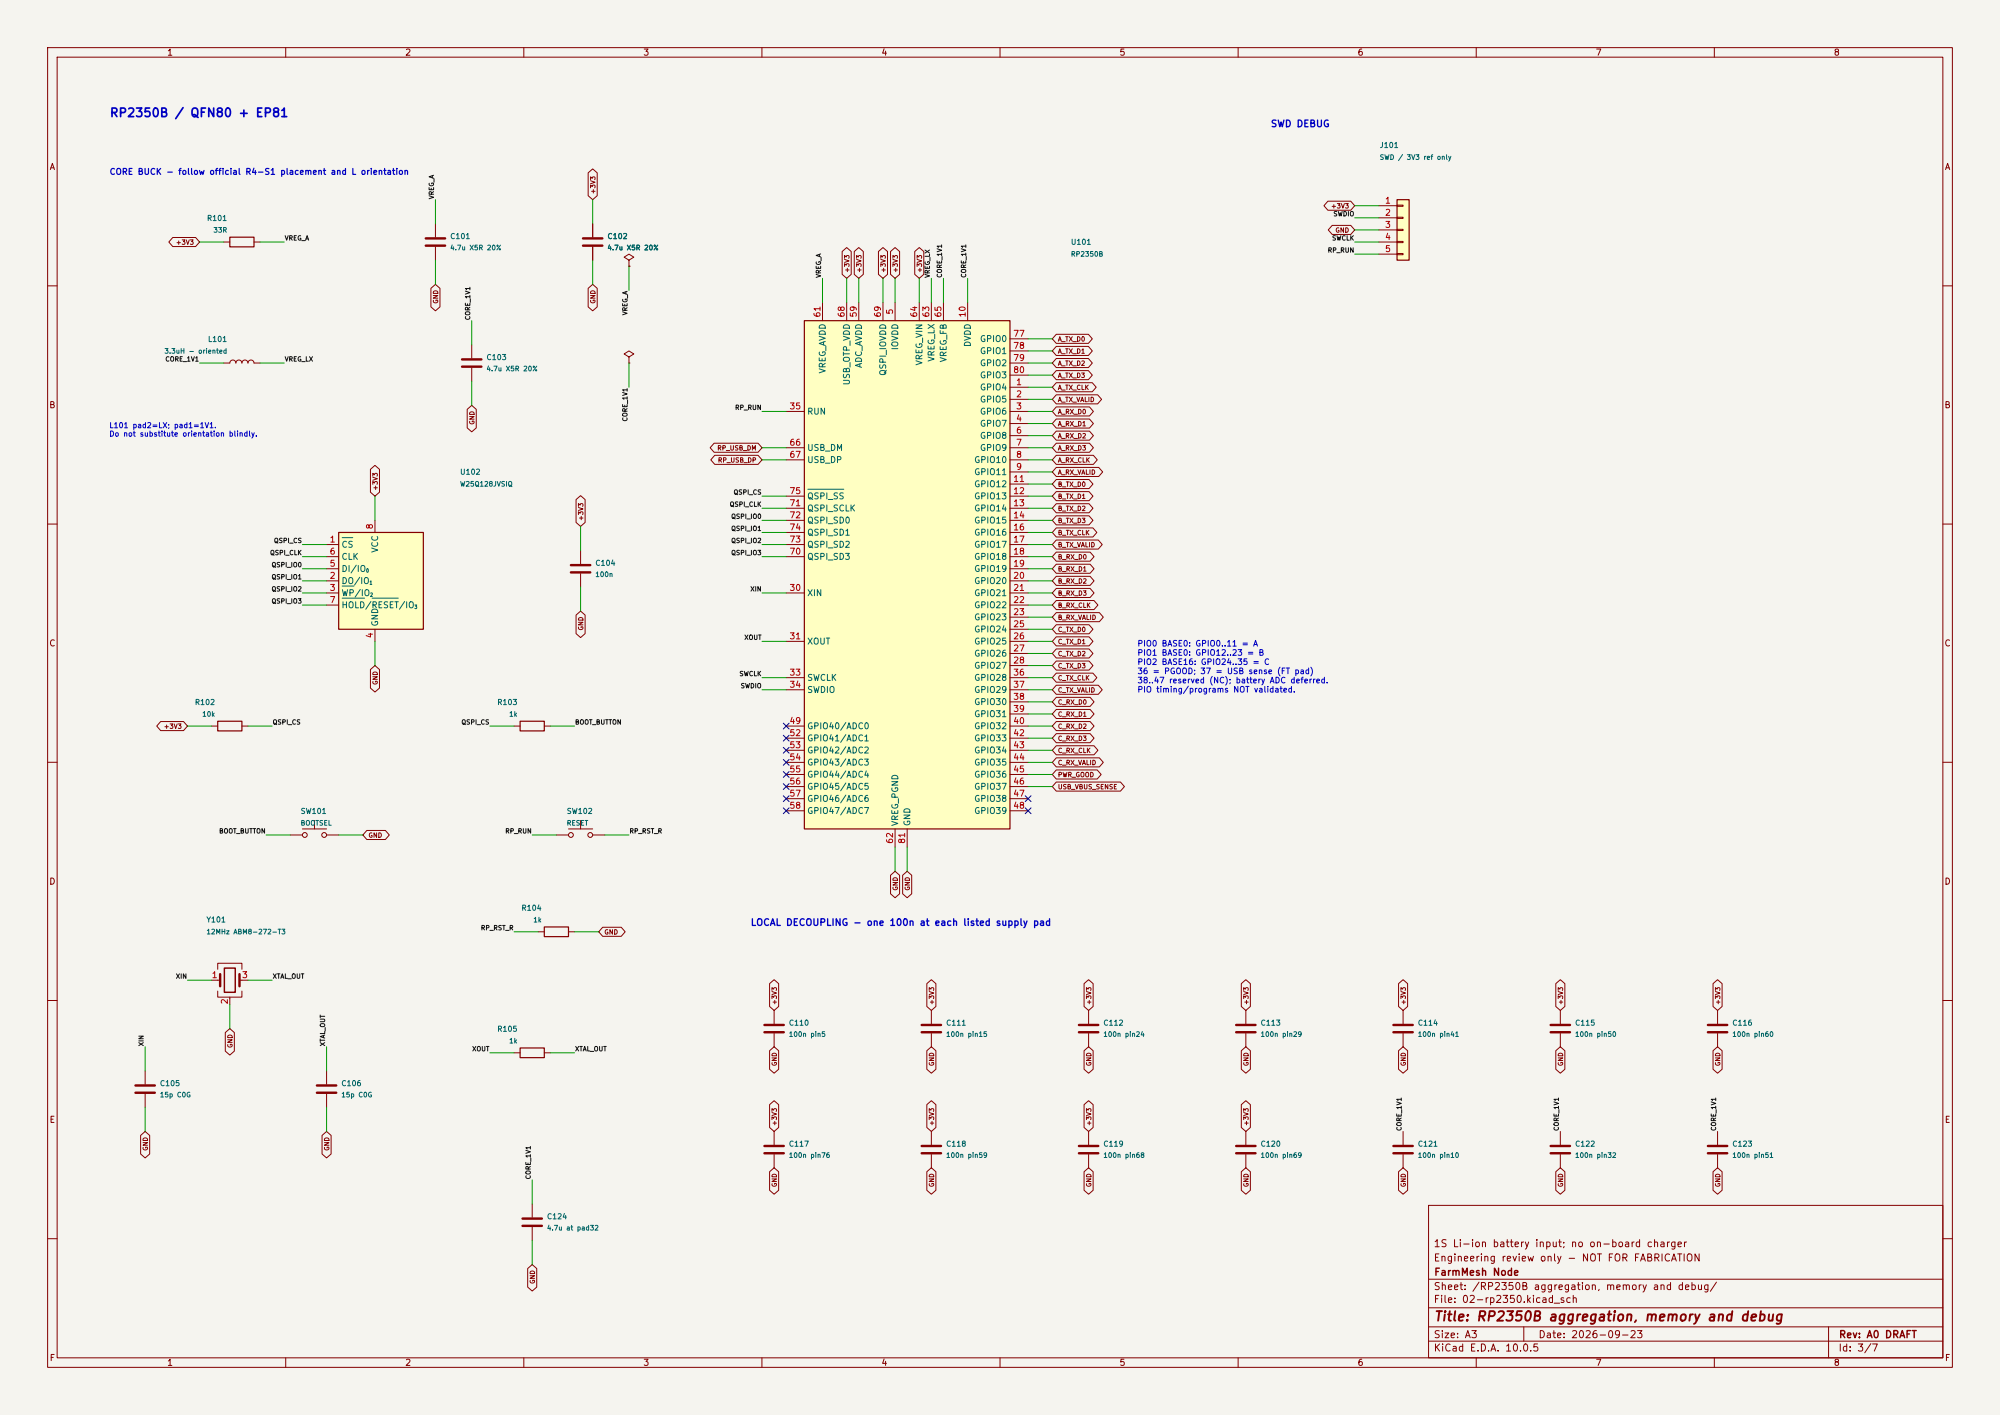
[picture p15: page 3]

CORE BUCK - follow official R4-S1 placement and L orientation

4 DI/IO0 5 CLK 6 HOLD/RESET/IO3 7 VCC

36 = PGOOD; 37 = USB sense (FT pad) 38..47 reserved (NC); battery ADC deferred. PIO timing/programs NOT validated. LOCAL DECOUPLING - one 100n at each listed supply pad
SWCLK

1S Li-ion battery input; no on-board charger C119

Engineering review only - NOT FOR FABRICATION
FarmMesh Node
Sheet: /RP2350B aggregation, memory and debug/
File: 02-rp2350.kicad_sch
Title: RP2350B aggregation, memory and debug

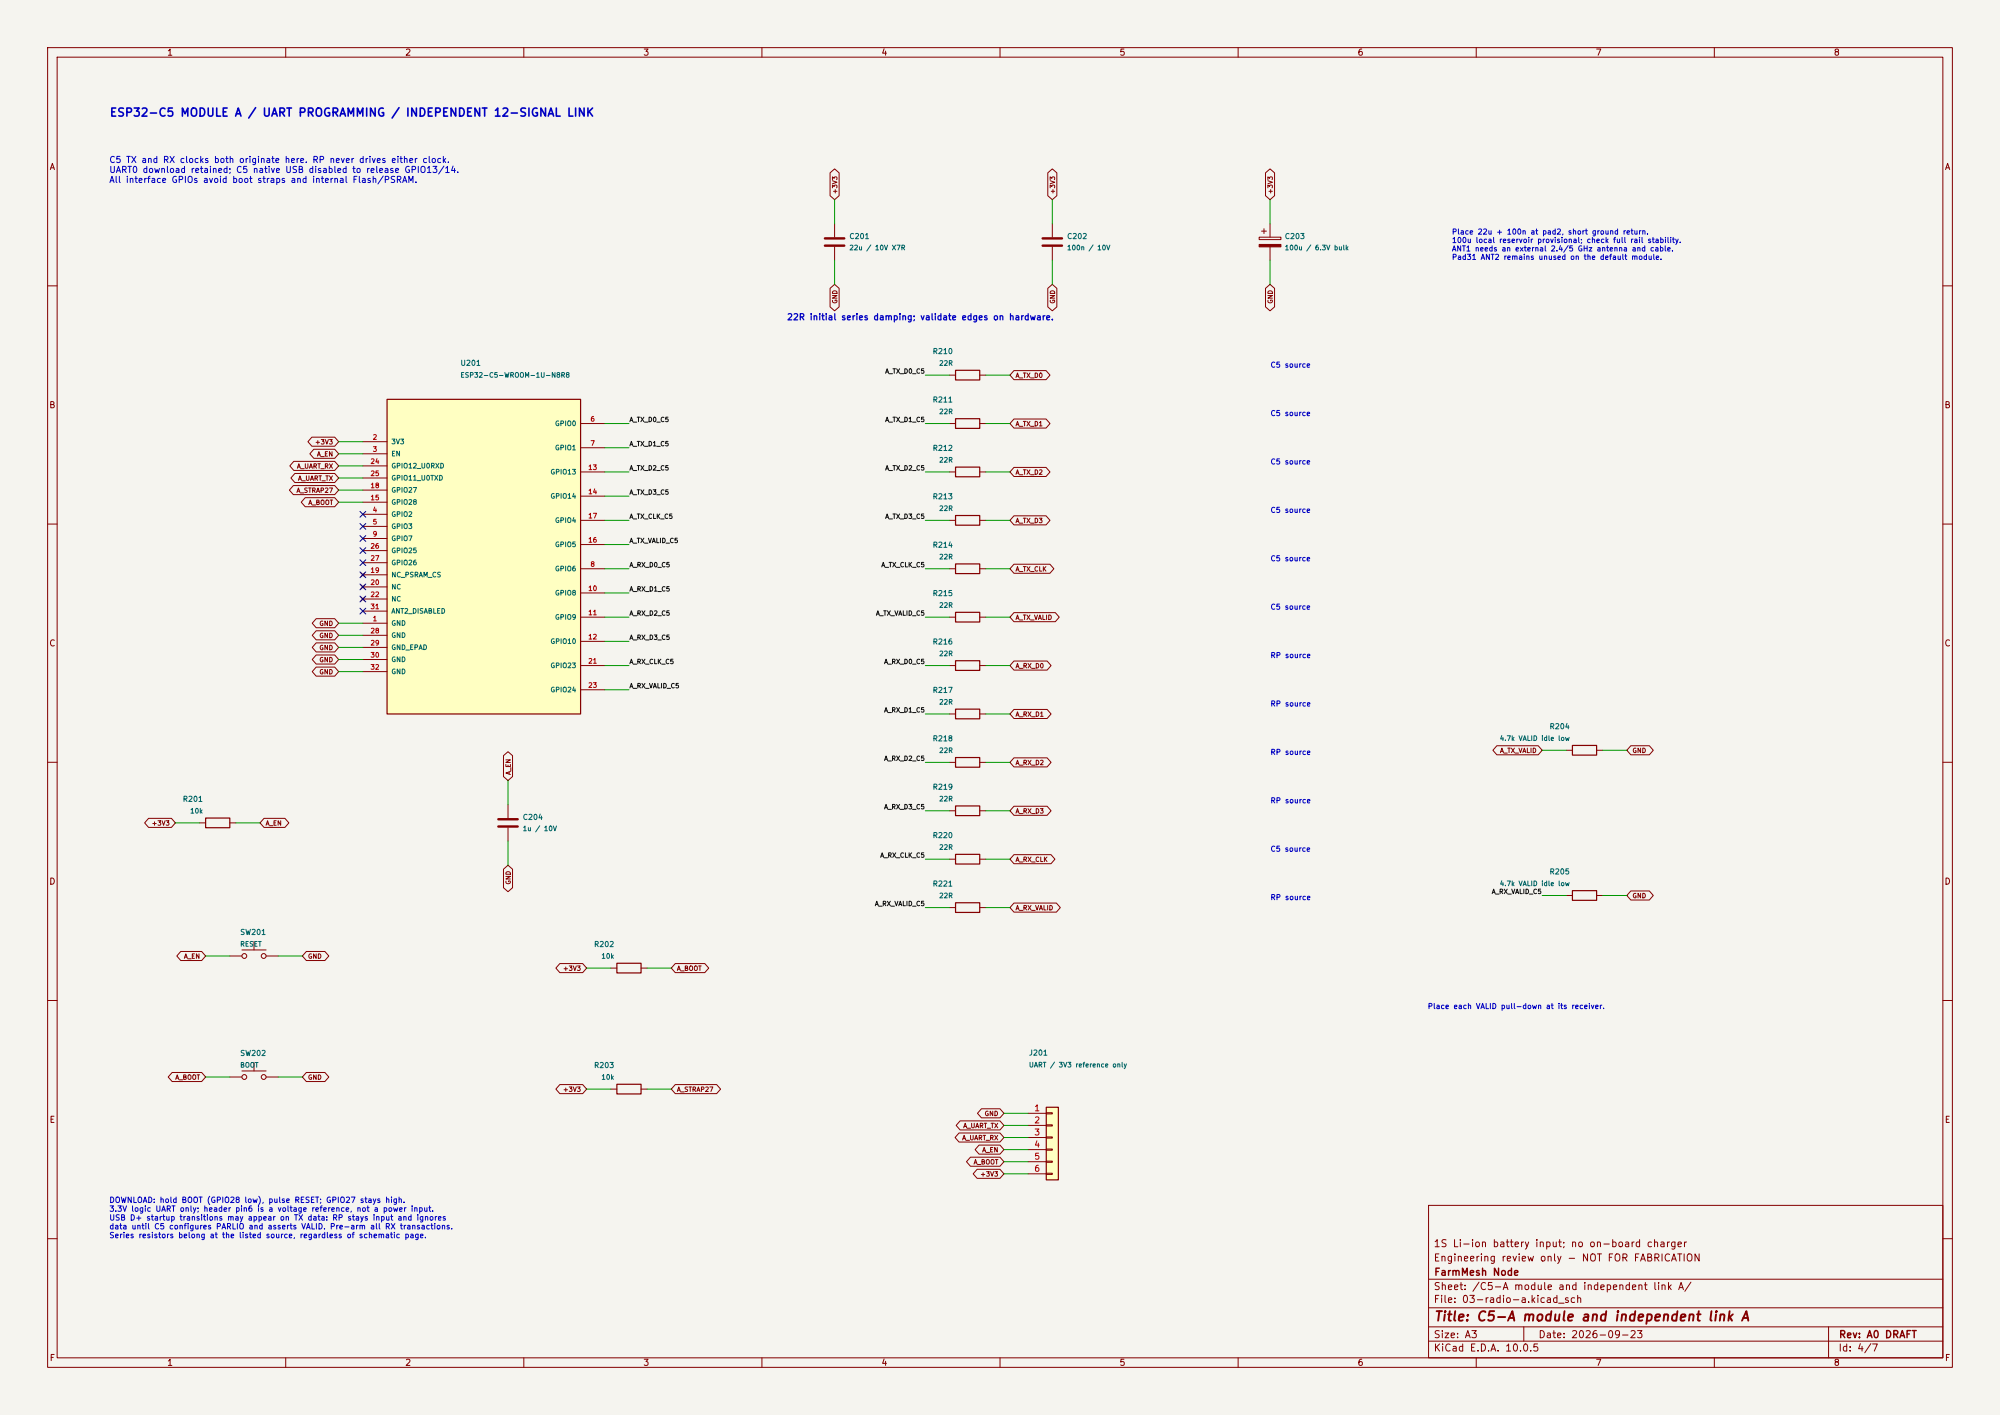
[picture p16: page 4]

ESP32-C5 MODULE A / UART PROGRAMMING / INDEPENDENT 12-SIGNAL LINK

DOWNLOAD: hold BOOT (GPIO28 low), pulse RESET; GPIO27 stays high. 3.3V logic UART only; header pin6 is a voltage reference, not a power input. USB D+ startup transitions may appear on TX data: RP stays input and ignores data until C5 configures PARLIO and asserts VALID. Pre-arm all RX transactions. Series resistors belong at the listed source, regardless of schematic page.

1S Li-ion battery input; no on-board charger
Engineering review only - NOT FOR FABRICATION
FarmMesh Node
Sheet: /C5-A module and independent link A/
File: 03-radio-a.kicad_sch
Title: C5-A module and independent link A

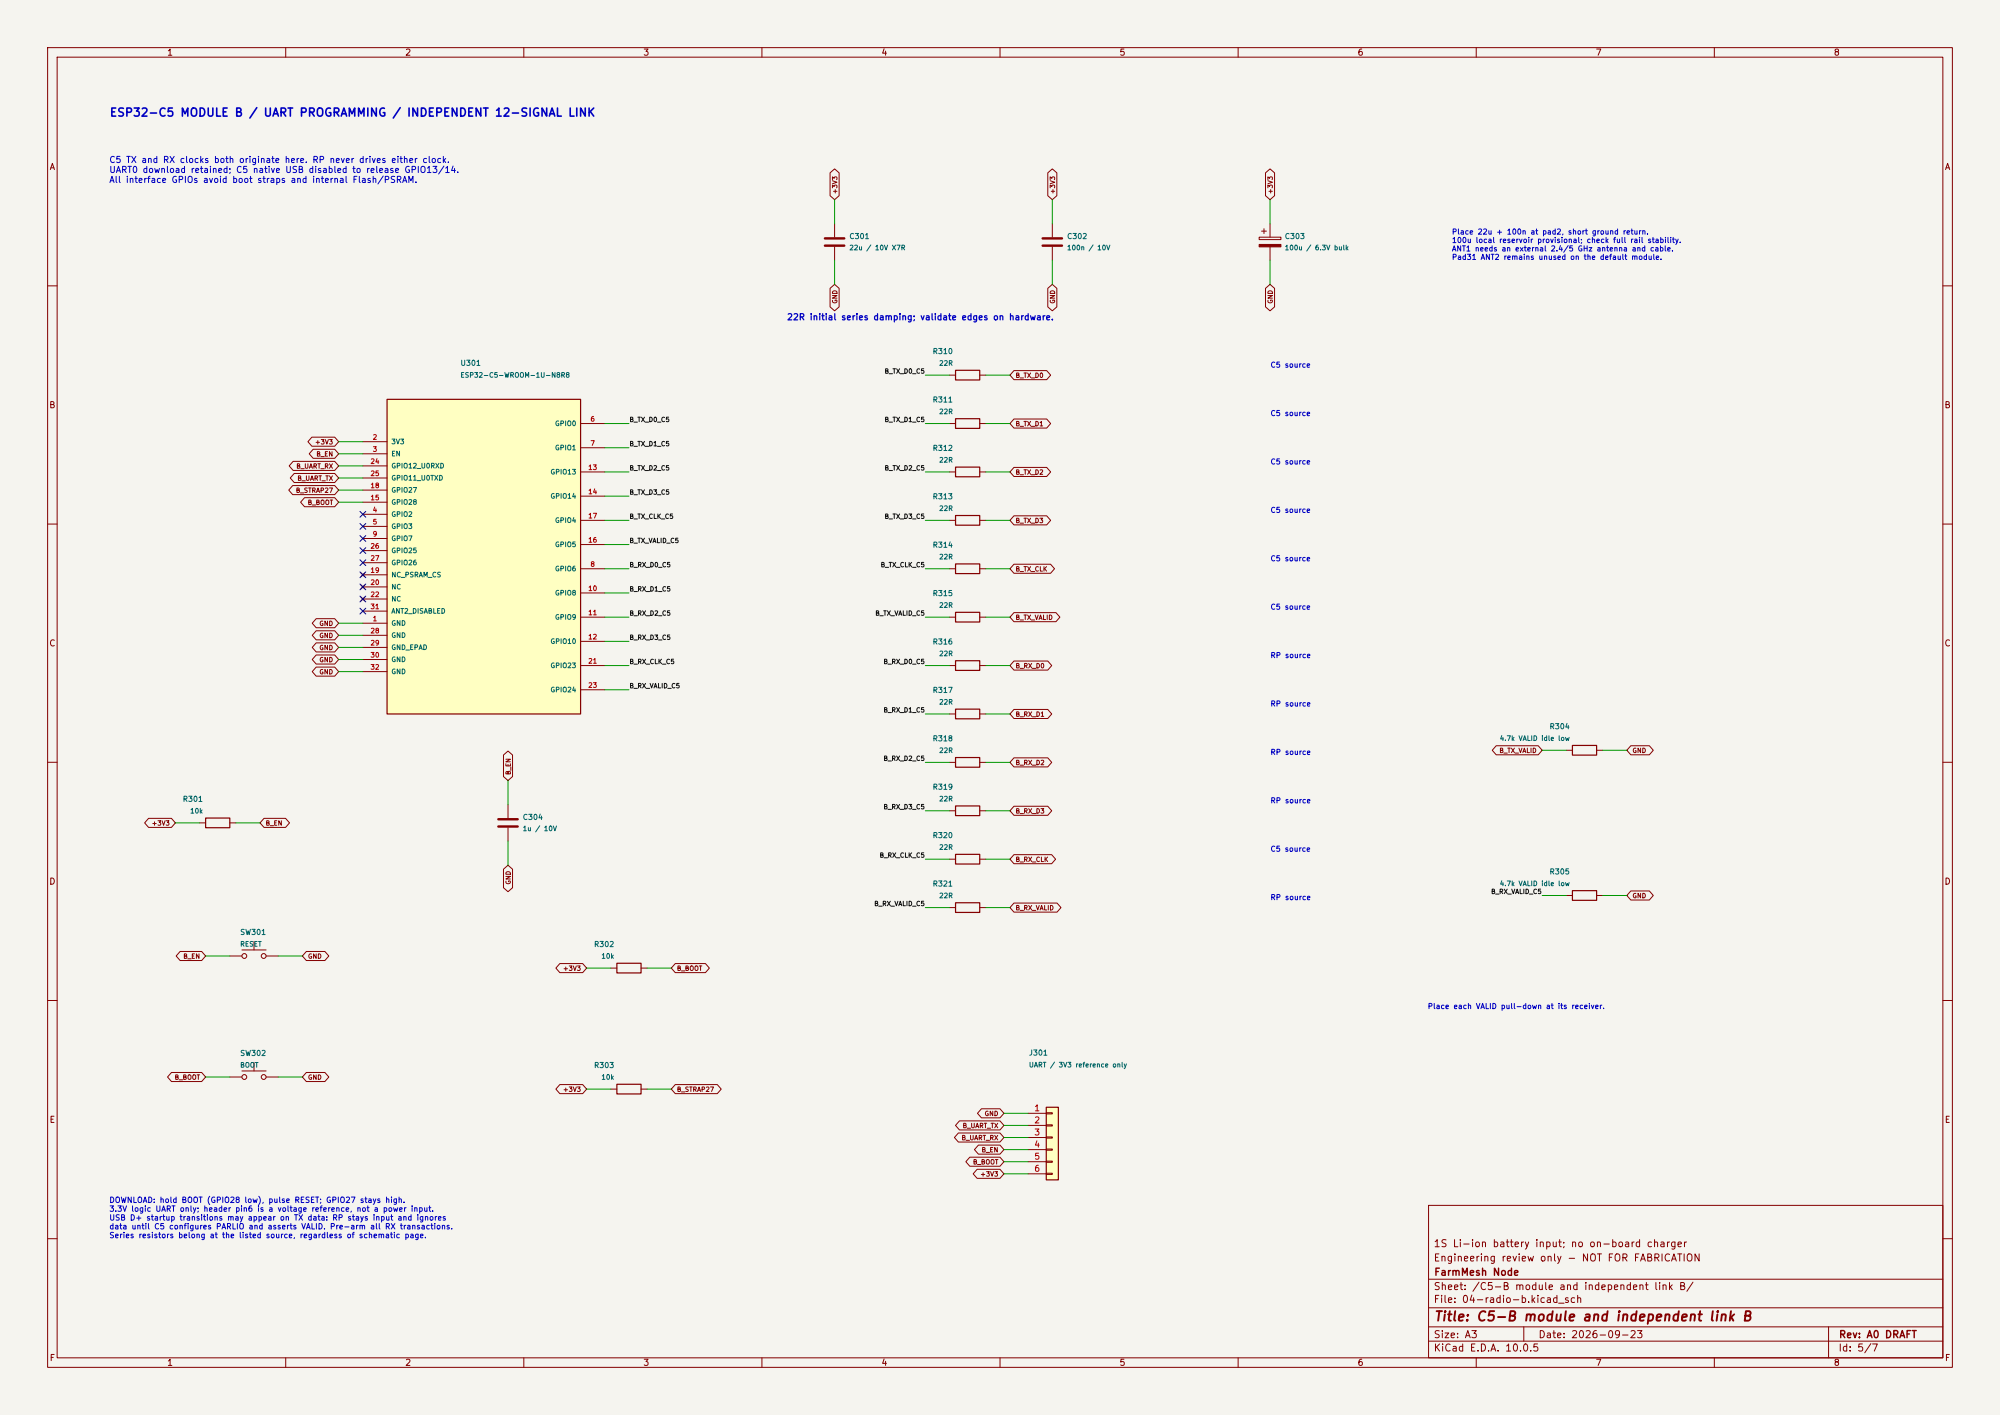
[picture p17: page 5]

ESP32-C5 MODULE B / UART PROGRAMMING / INDEPENDENT 12-SIGNAL LINK

C5 TX and RX clocks both originate here. RP never drives either clock. UART0 download retained; C5 native USB disabled to release GPIO13/14. All interface GPIOs avoid boot straps and internal Flash/PSRAM.

Place each VALID pull-down at its receiver. RP source RP source RP source C5 source

1S Li-ion battery input; no on-board charger R321

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

Engineering review only - NOT FOR FABRICATION
FarmMesh Node
Sheet: /C5-B module and independent link B/
File: 04-radio-b.kicad_sch
Title: C5-B module and independent link B

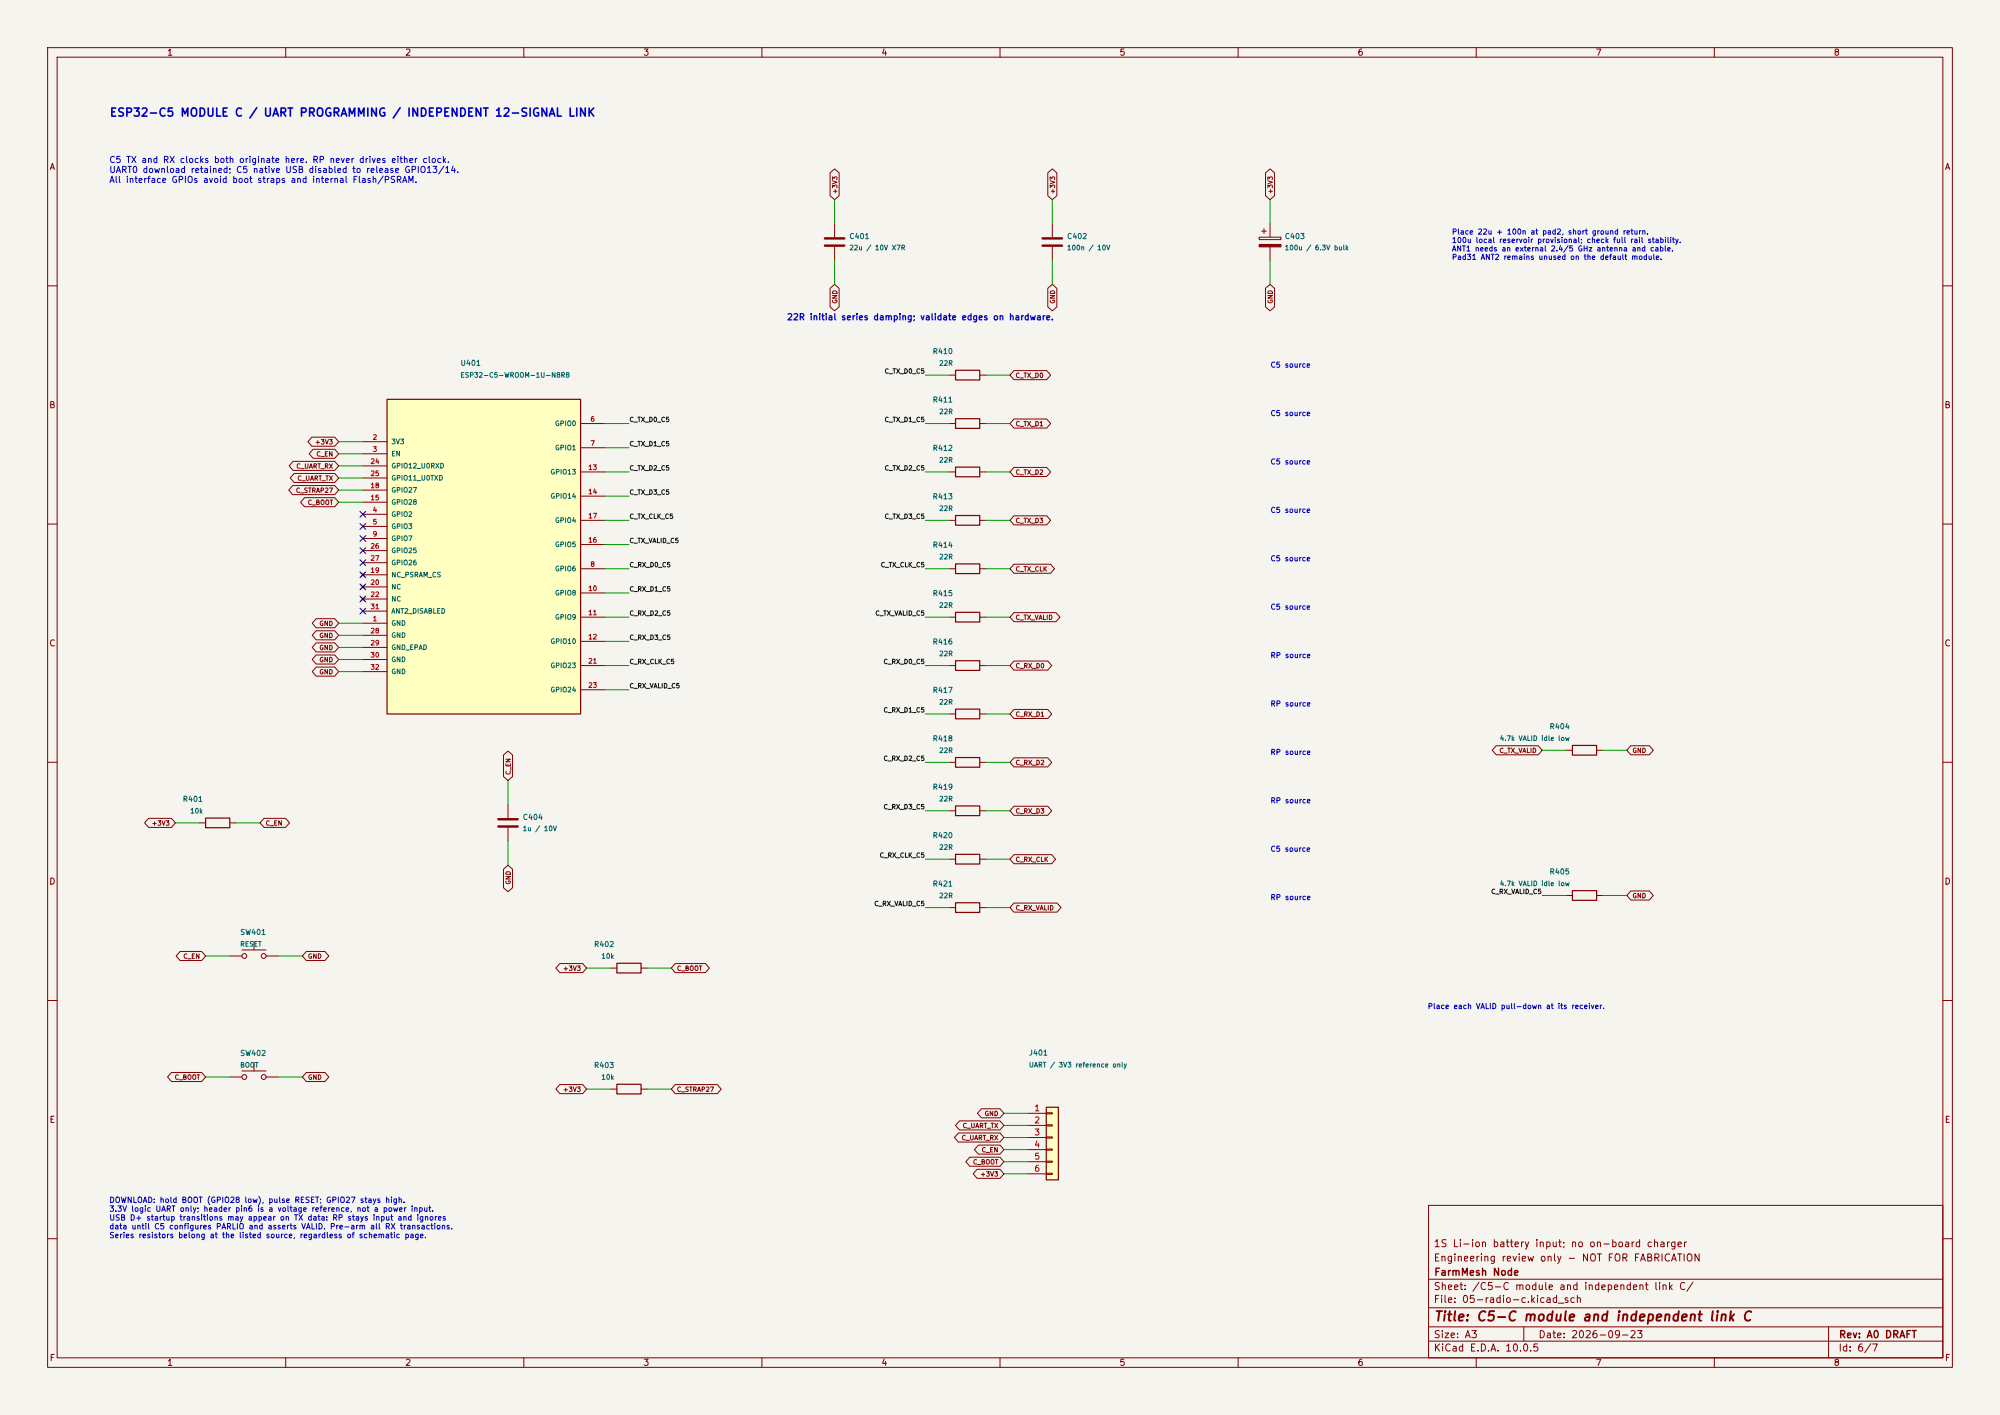
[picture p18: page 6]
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

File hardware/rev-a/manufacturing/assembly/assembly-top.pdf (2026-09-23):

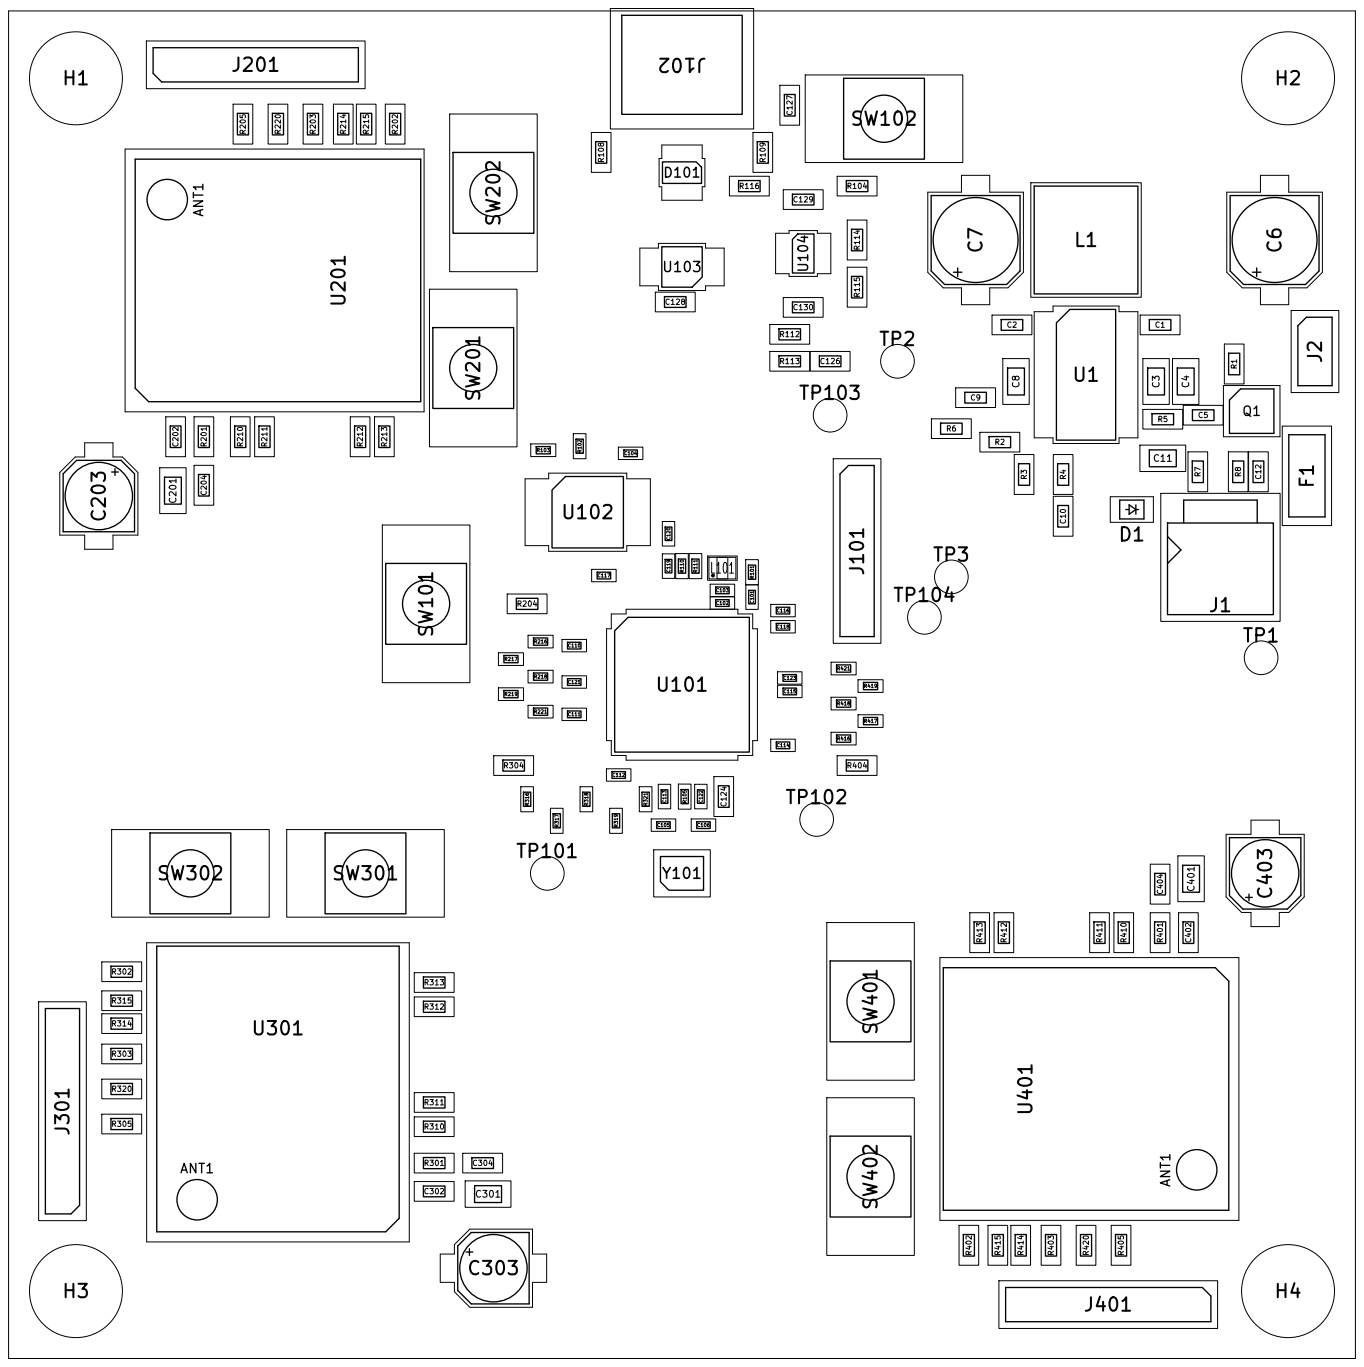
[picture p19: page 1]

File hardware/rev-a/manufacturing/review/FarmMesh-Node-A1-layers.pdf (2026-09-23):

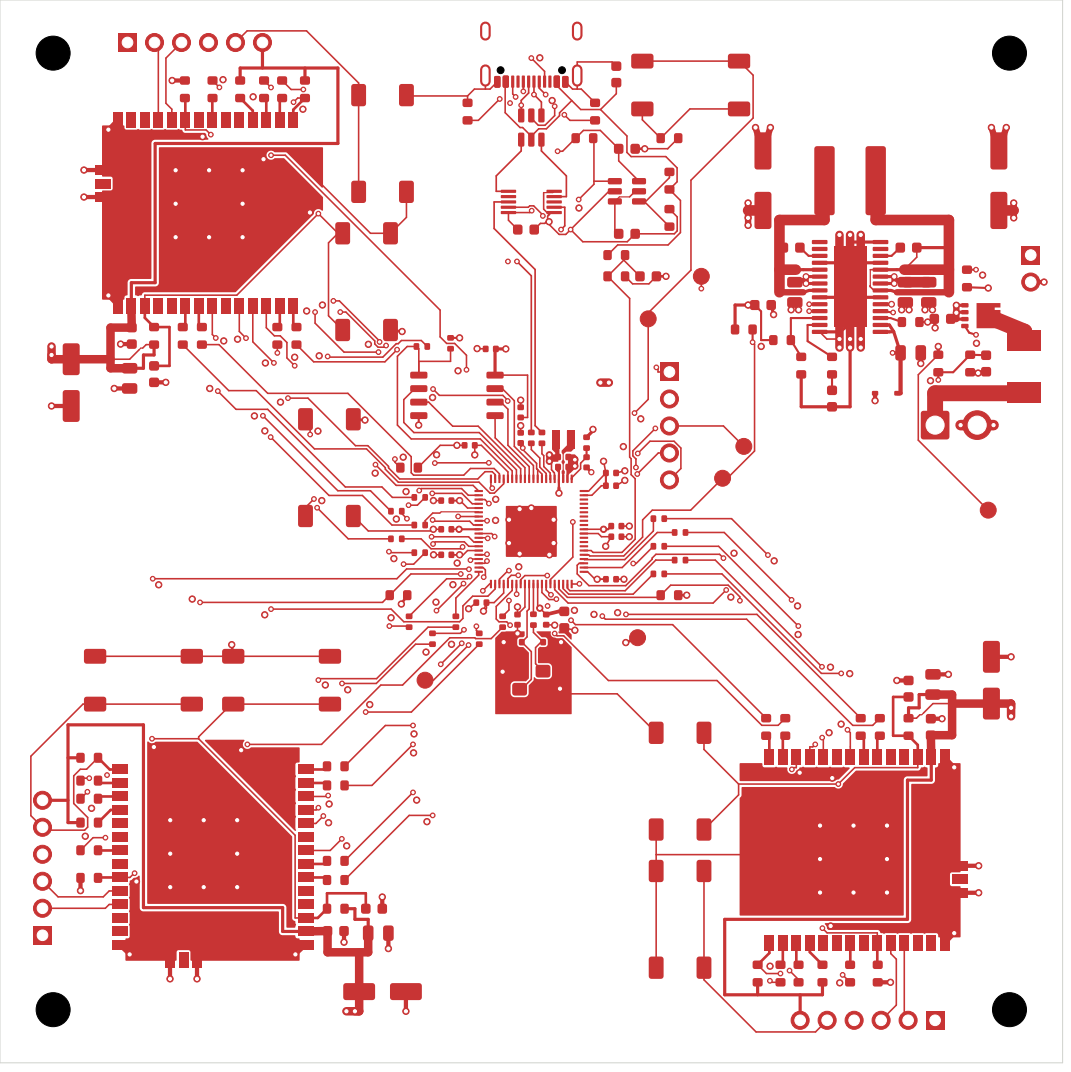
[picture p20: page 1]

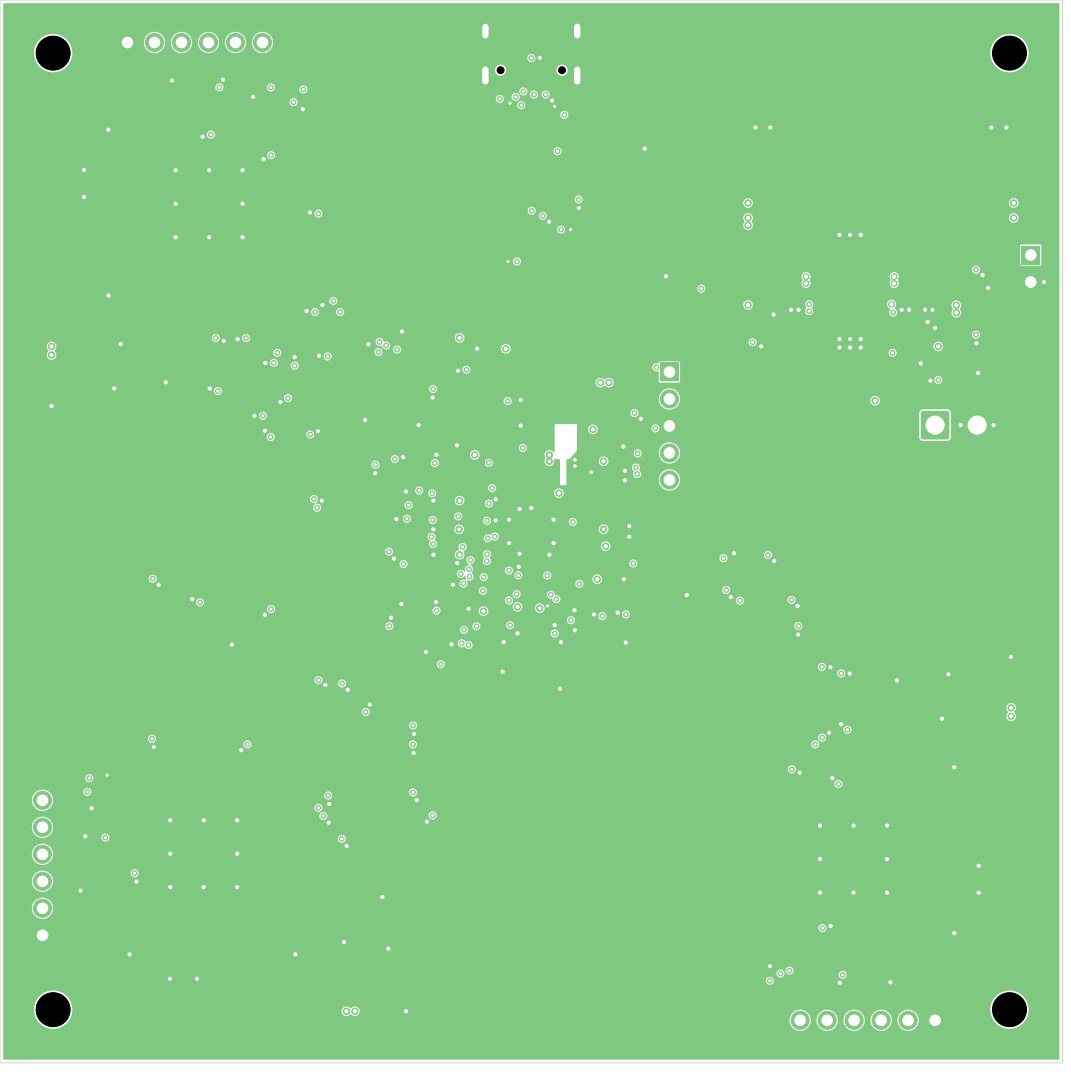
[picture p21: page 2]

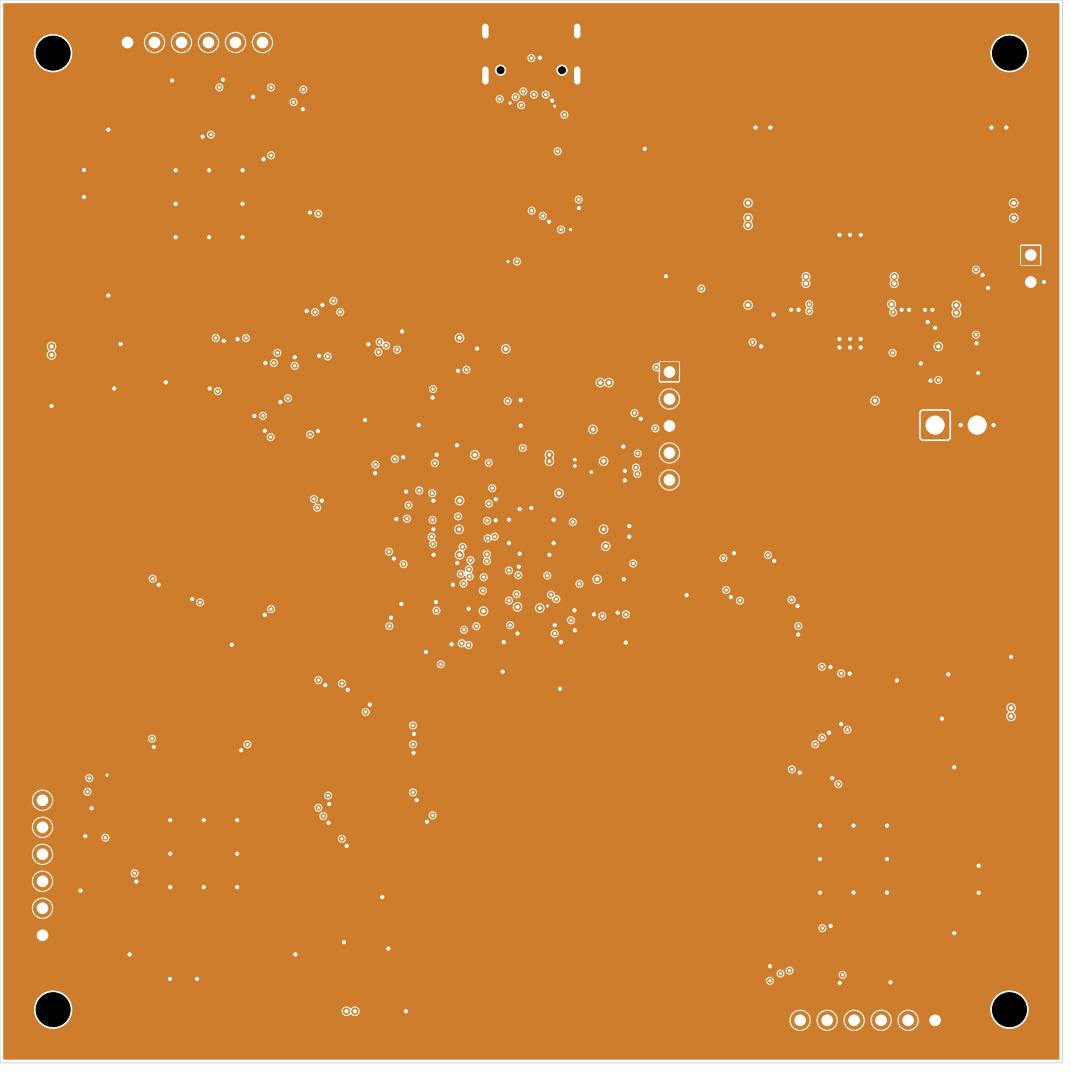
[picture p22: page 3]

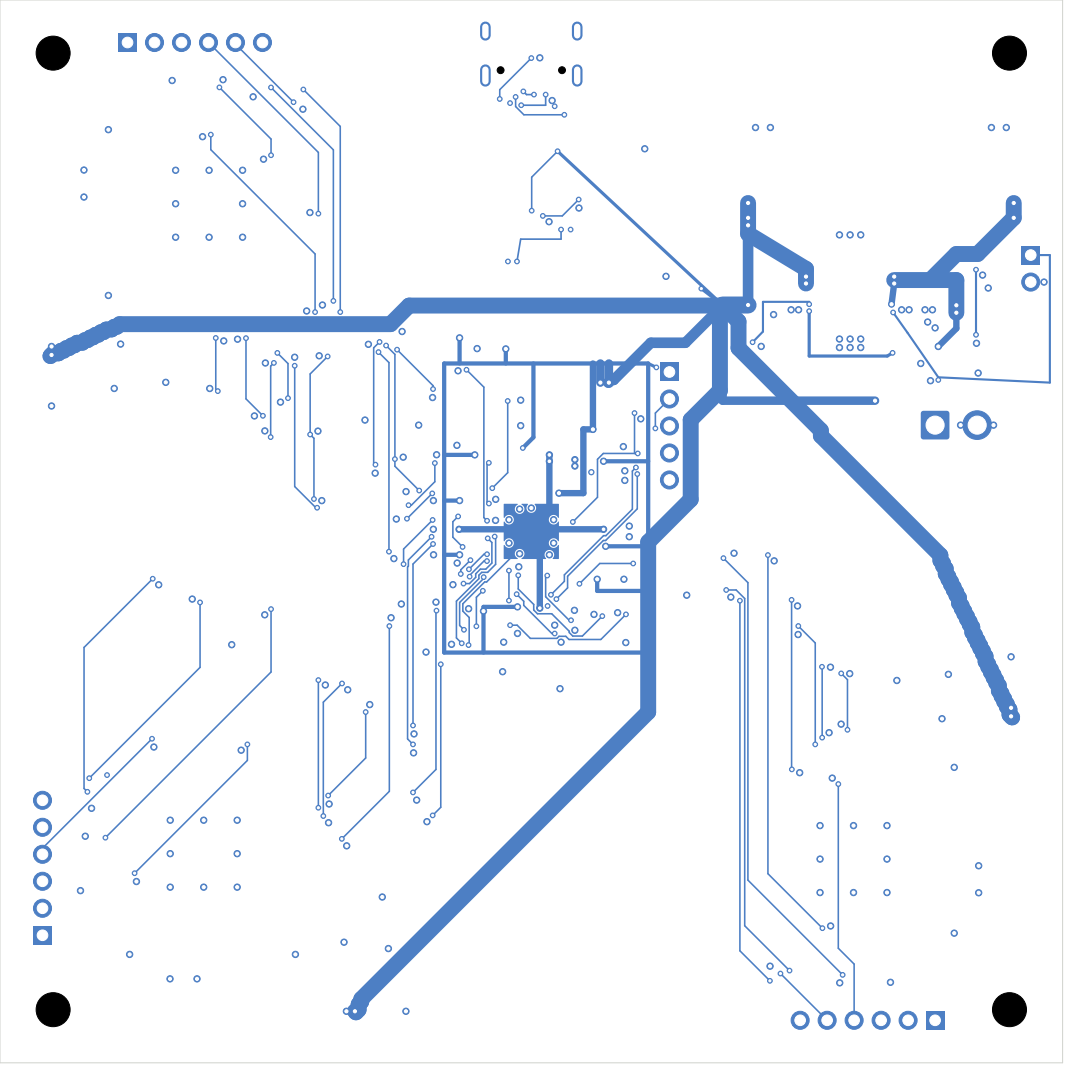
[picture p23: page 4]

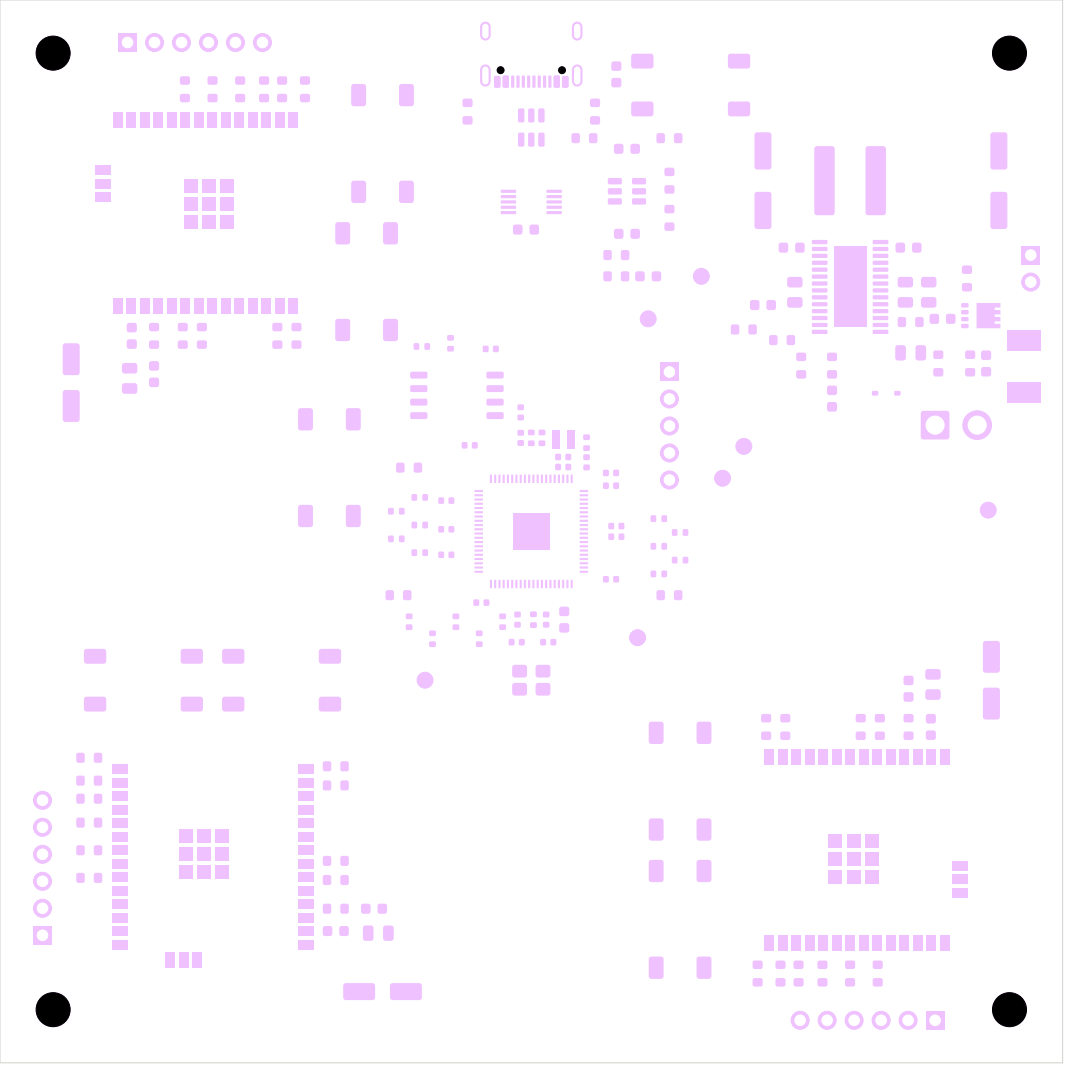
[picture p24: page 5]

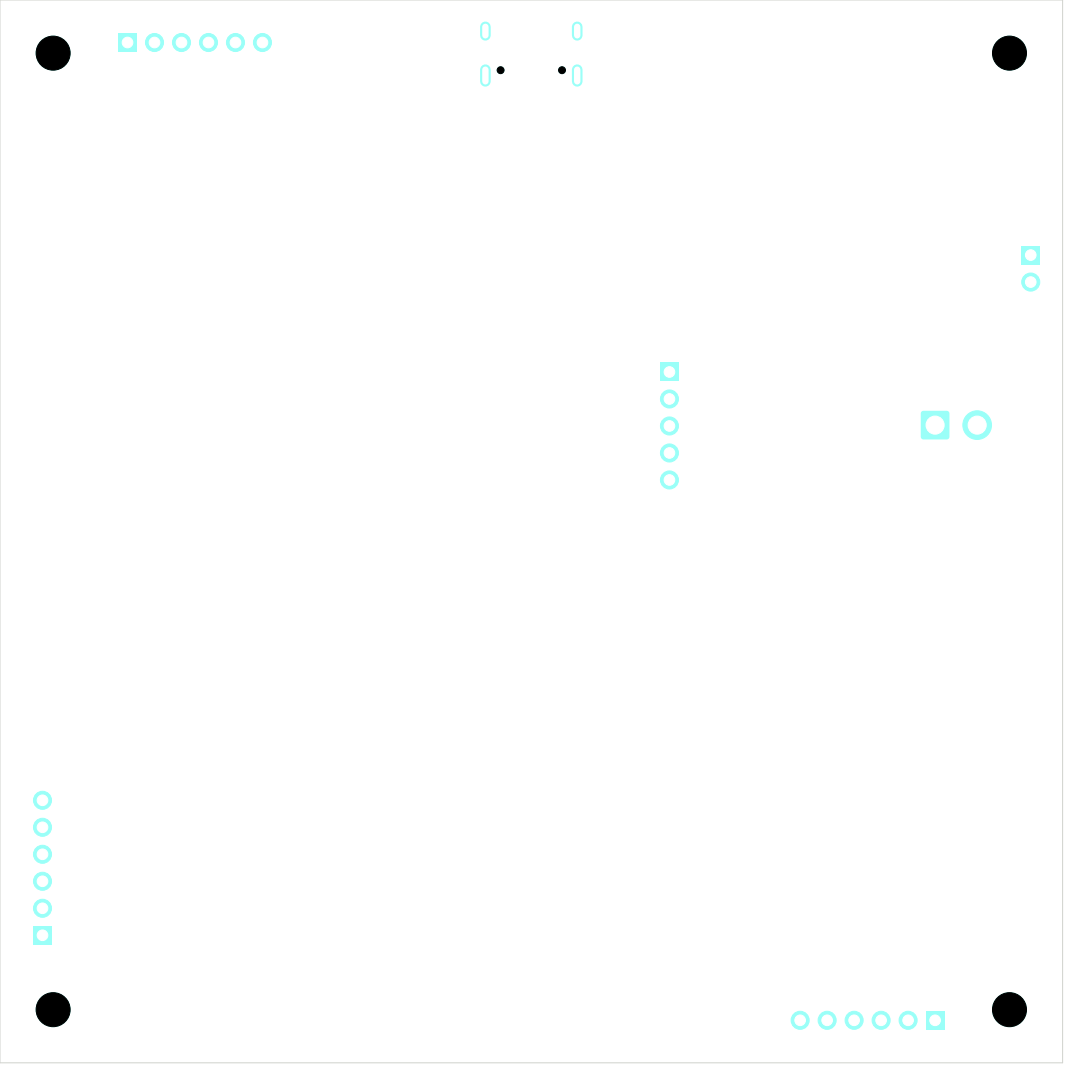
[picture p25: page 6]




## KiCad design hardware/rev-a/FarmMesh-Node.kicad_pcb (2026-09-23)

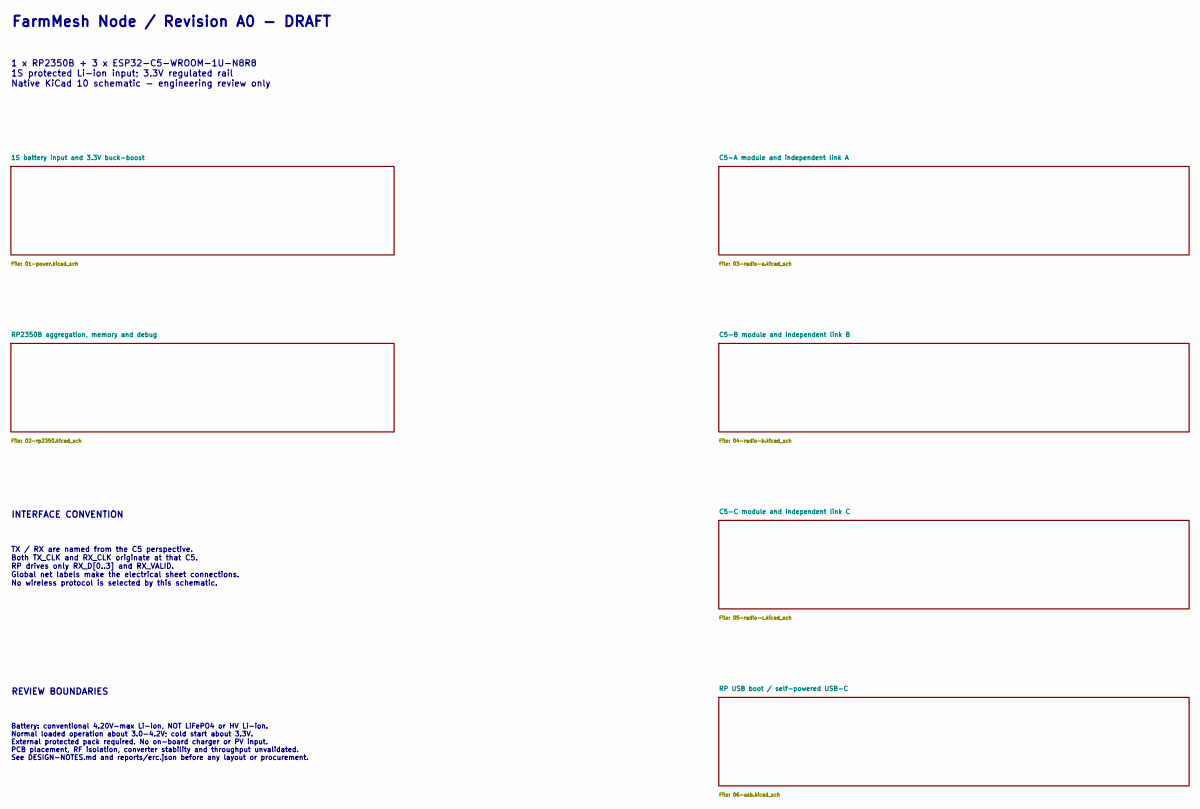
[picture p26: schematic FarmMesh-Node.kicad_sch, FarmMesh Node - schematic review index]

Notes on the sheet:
Battery: conventional 4.20V-max Li-ion, NOT LiFePO4 or HV Li-ion. Normal loaded operation about 3.0-4.2V; cold start about 3.3V. External protected pack required. No on-board charger or PV input. PCB placement, RF isolation, converter stability and throughput unvalidated. See DESIGN-NOTES.md and re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
INTERFACE CONVENTION
TX / RX are named from the C5 perspective. Both TX_CLK and RX_CLK originate at that C5. RP drives only RX_D[0..3] and RX_VALID. Global net labels make the electrical sheet connections. No wireless protocol is selected by this schematic.
REVIEW BOUNDARIES
1 x RP2350B + 3 x ESP32-C5-WROOM-1U-N8R8 1S protected Li-ion input; 3.3V regulated rail Native KiCad 10 schematic - engineering review only
FarmMesh Node / Revision A0 - DRAFT

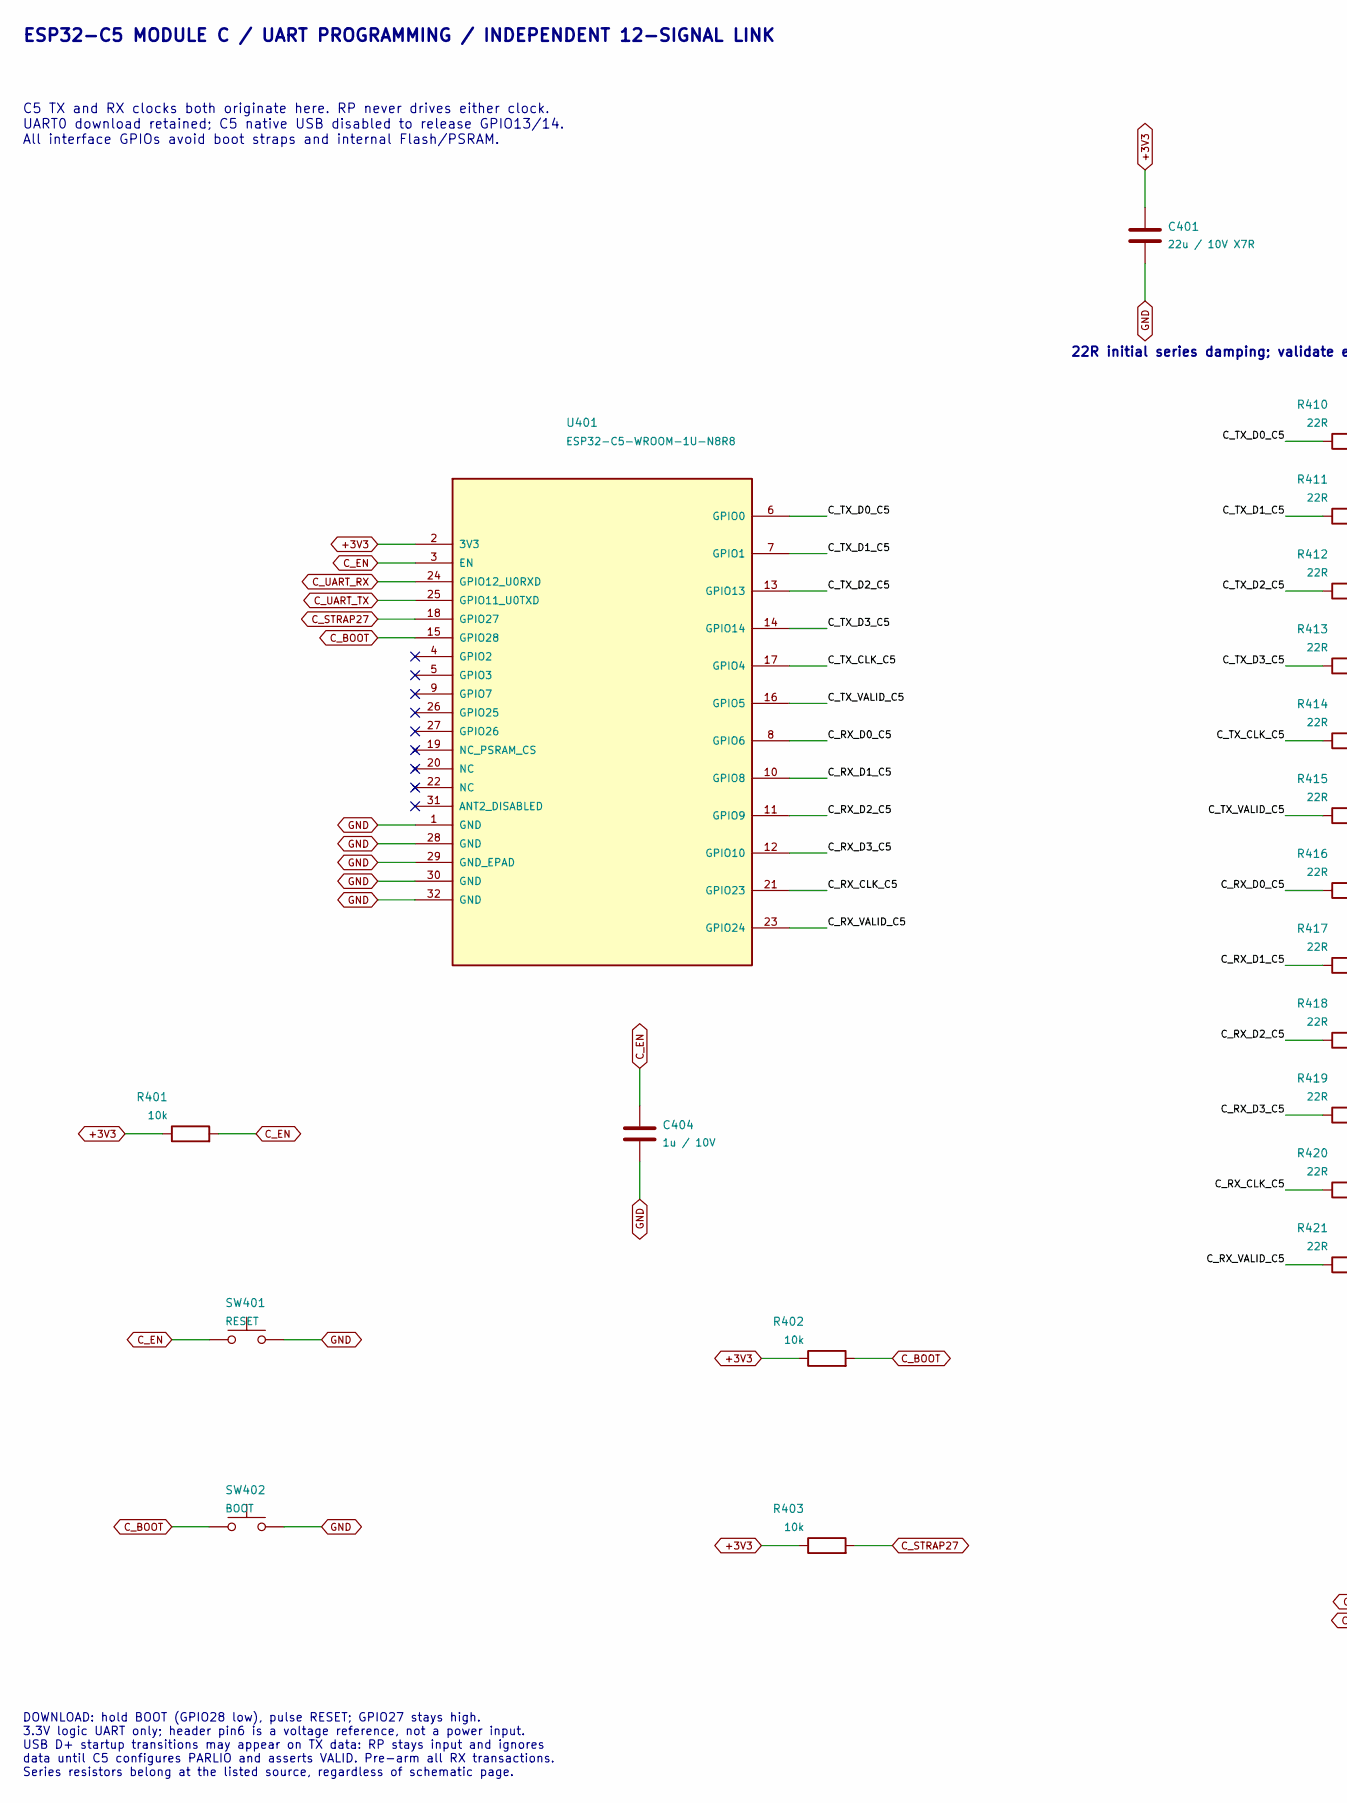
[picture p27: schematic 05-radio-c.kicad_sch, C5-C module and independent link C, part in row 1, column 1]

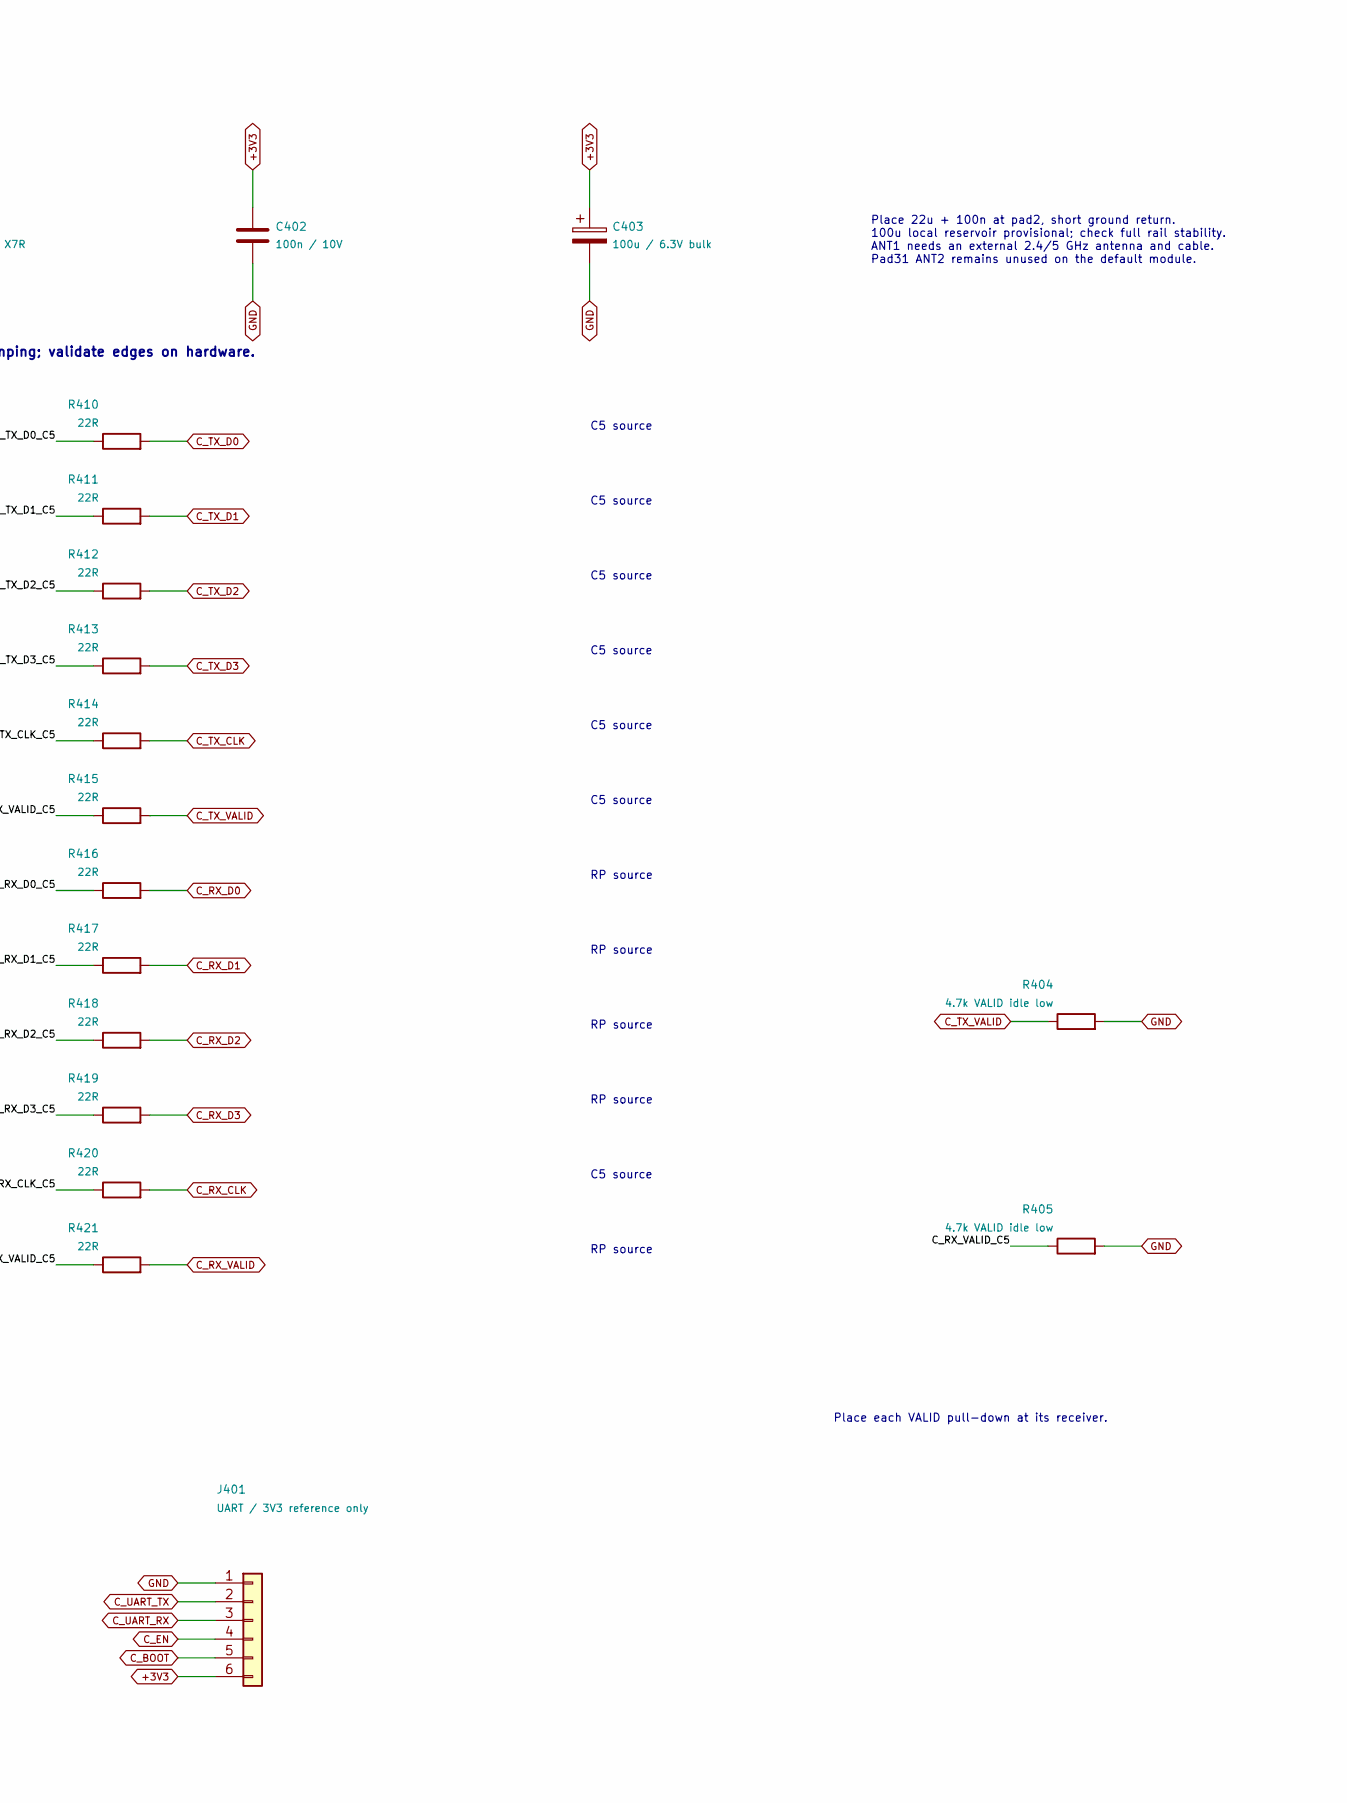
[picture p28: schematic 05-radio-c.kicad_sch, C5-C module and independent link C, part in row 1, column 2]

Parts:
C401: 22u / 10V X7R; C_0805_2012Metric
C402: 100n / 10V; C_0603_1608Metric
C403: 100u / 6.3V bulk; CP_Elec_6.3x5.8
C404: 1u / 10V; C_0603_1608Metric
J401: UART / 3V3 reference only; PinHeader_1x06_P2.54mm_Vertical
R401, R402, R403: 10k; R_0603_1608Metric
R404, R405: 4.7k VALID idle low; R_0603_1608Metric
R410, R411, R412, R413, R414, R415, R416, R417, R418, R419, R420, R421: 22R; R_0603_1608Metric
SW401: RESET; SW_Push_1P1T_NO_E-Switch_TL3301NxxxxxG
SW402: BOOT; SW_Push_1P1T_NO_E-Switch_TL3301NxxxxxG
U401: ESP32-C5-WROOM-1U-N8R8; ESP32-C5-WROOM-1U; MPN ESP32-C5-WROOM-1U-N8R8

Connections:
+3V3: C401.1, C402.1, C403.1, J401.6, R401.1, R402.1, R403.1, U401.2 (3V3); also elsewhere on the board
/C5-C module and independent link C/C_RX_CLK_C5: R420.1, U401.21 (GPIO23)
/C5-C module and independent link C/C_RX_D0_C5: R416.1, U401.8 (GPIO6)
/C5-C module and independent link C/C_RX_D1_C5: R417.1, U401.10 (GPIO8)
/C5-C module and independent link C/C_RX_D2_C5: R418.1, U401.11 (GPIO9)
/C5-C module and independent link C/C_RX_D3_C5: R419.1, U401.12 (GPIO10)
/C5-C module and independent link C/C_RX_VALID_C5: R405.1, R421.1, U401.23 (GPIO24)
/C5-C module and independent link C/C_TX_CLK_C5: R414.1, U401.17 (GPIO4)
/C5-C module and independent link C/C_TX_D0_C5: R410.1, U401.6 (GPIO0)
/C5-C module and independent link C/C_TX_D1_C5: R411.1, U401.7 (GPIO1)
/C5-C module and independent link C/C_TX_D2_C5: R412.1, U401.13 (GPIO13)
/C5-C module and independent link C/C_TX_D3_C5: R413.1, U401.14 (GPIO14)
/C5-C module and independent link C/C_TX_VALID_C5: R415.1, U401.16 (GPIO5)
C_BOOT: J401.5, R402.2, SW402.1, U401.15 (GPIO28)
C_EN: C404.1, J401.4, R401.2, SW401.1, U401.3 (EN)
C_RX_CLK: R420.2; also elsewhere on the board
C_RX_D0: R416.2; also elsewhere on the board
C_RX_D1: R417.2; also elsewhere on the board
C_RX_D2: R418.2; also elsewhere on the board
C_RX_D3: R419.2; also elsewhere on the board
C_RX_VALID: R421.2; also elsewhere on the board
C_STRAP27: R403.2, U401.18 (GPIO27)
C_TX_CLK: R414.2; also elsewhere on the board
C_TX_D0: R410.2; also elsewhere on the board
C_TX_D1: R411.2; also elsewhere on the board
C_TX_D2: R412.2; also elsewhere on the board
C_TX_D3: R413.2; also elsewhere on the board
C_TX_VALID: R404.1, R415.2; also elsewhere on the board
C_UART_RX: J401.3, U401.24 (GPIO12_U0RXD)
C_UART_TX: J401.2, U401.25 (GPIO11_U0TXD)
GND: C401.2, C402.2, C403.2, C404.2, J401.1, R404.2, R405.2, SW401.2, SW402.2, U401.1 (GND), U401.28 (GND), U401.29 (GND_EPAD), U401.30 (GND), U401.32 (GND); also elsewhere on the board

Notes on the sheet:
RP source
C5 source
C5 TX and RX clocks both originate here. RP never drives either clock. UART0 download retained; C5 native USB disabled to release GPIO13/14. All interface GPIOs avoid boot straps and internal Flash/PSRAM.
ESP32-C5 MODULE C / UART PROGRAMMING / INDEPENDENT 12-SIGNAL LINK
Place 22u + 100n at pad2, short ground return. 100u local reservoir provisional; check full rail stability. ANT1 needs an external 2.4/5 GHz antenna and cable. Pad31 ANT2 remains unused on the default module.
DOWNLOAD: hold BOOT (GPIO28 low), pulse RESET; GPIO27 stays high. 3.3V logic UART only; header pin6 is a voltage reference, not a power input. USB D+ startup transitions may appear on TX data: RP stays input and ignores data until C5 configures PARLIO and asserts VALID. Pre-arm all RX transactions.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
Place each VALID pull-down at its receiver.
22R initial series damping; validate edges on hardware.

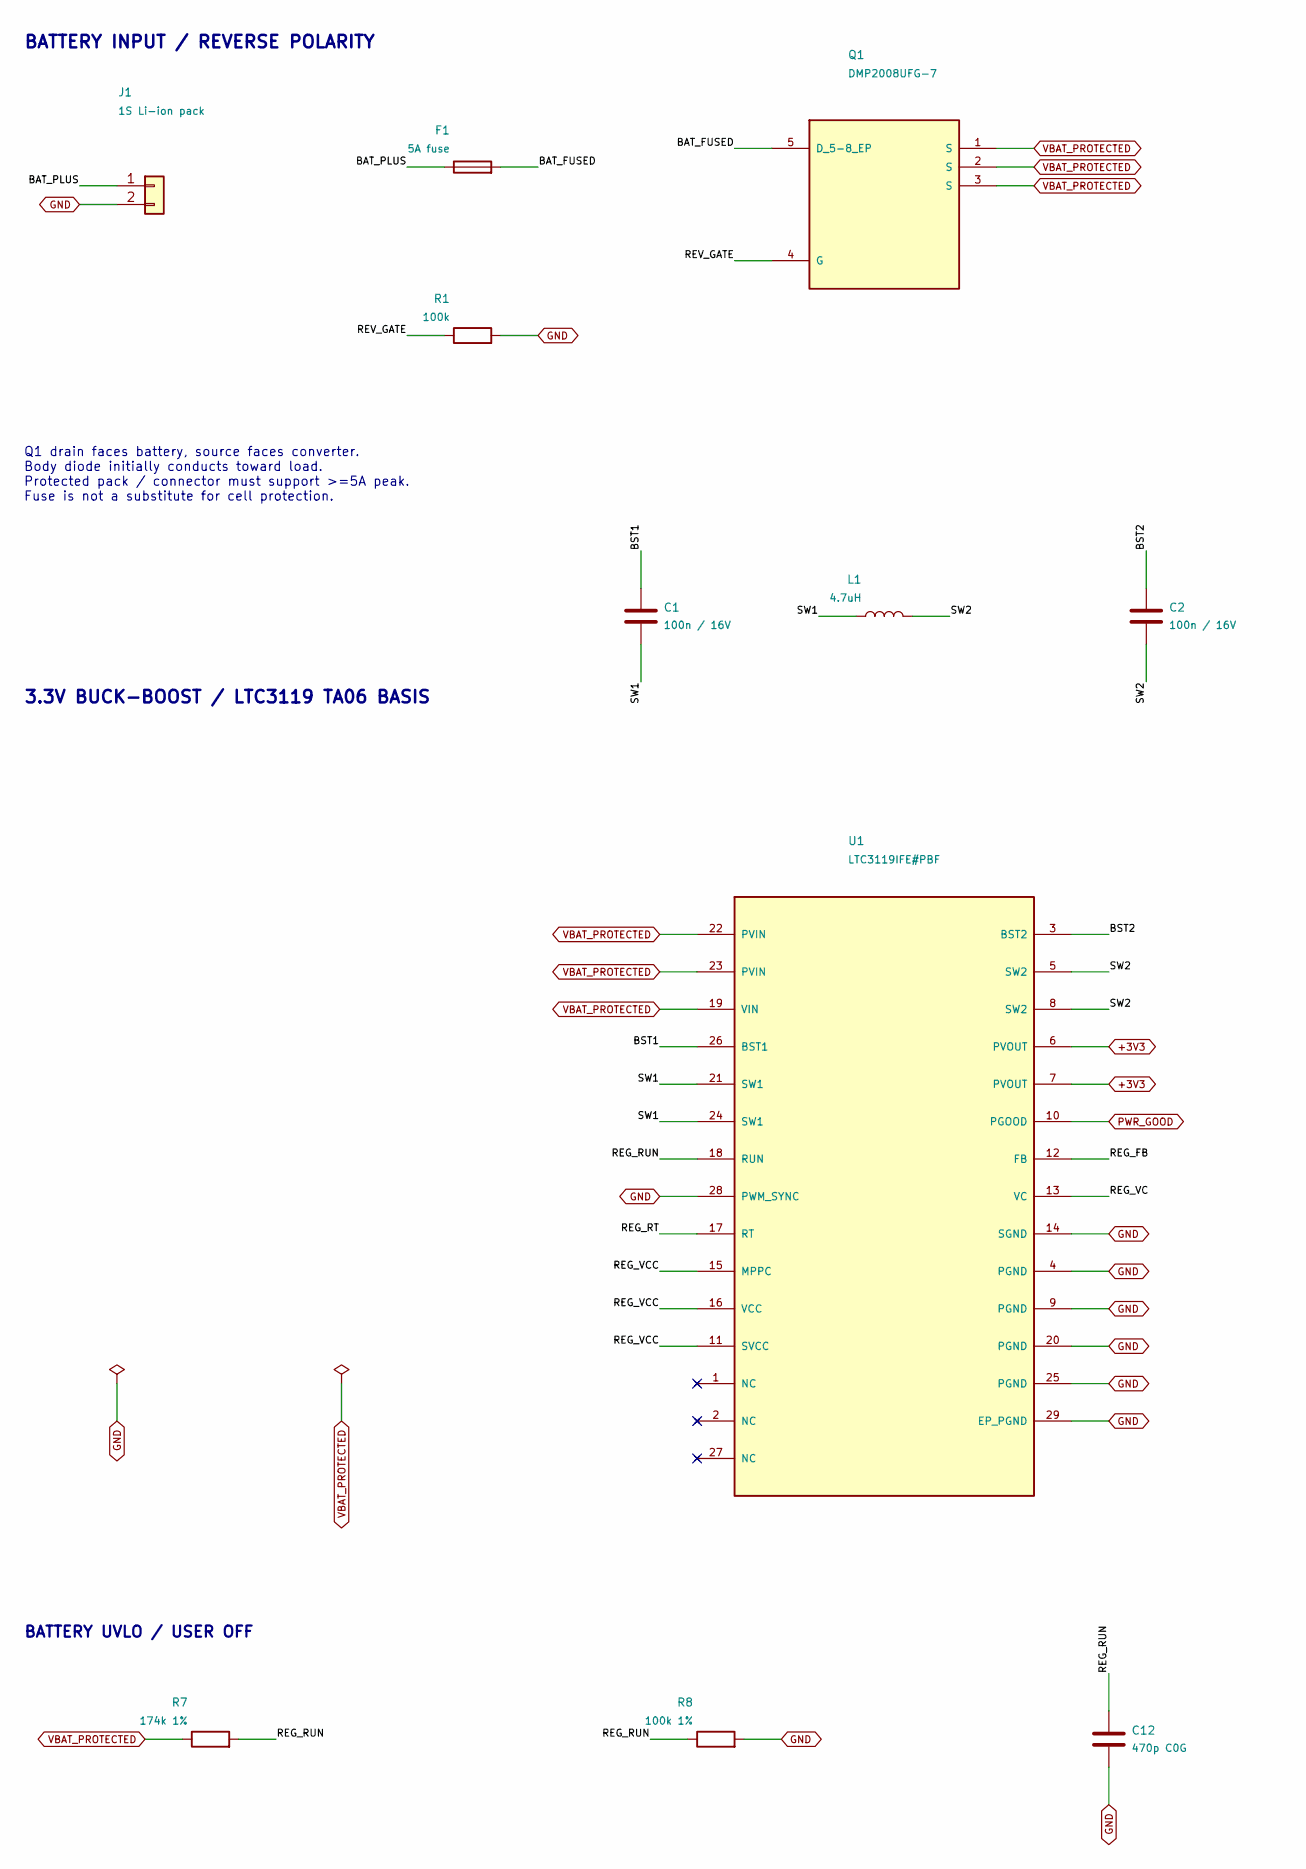
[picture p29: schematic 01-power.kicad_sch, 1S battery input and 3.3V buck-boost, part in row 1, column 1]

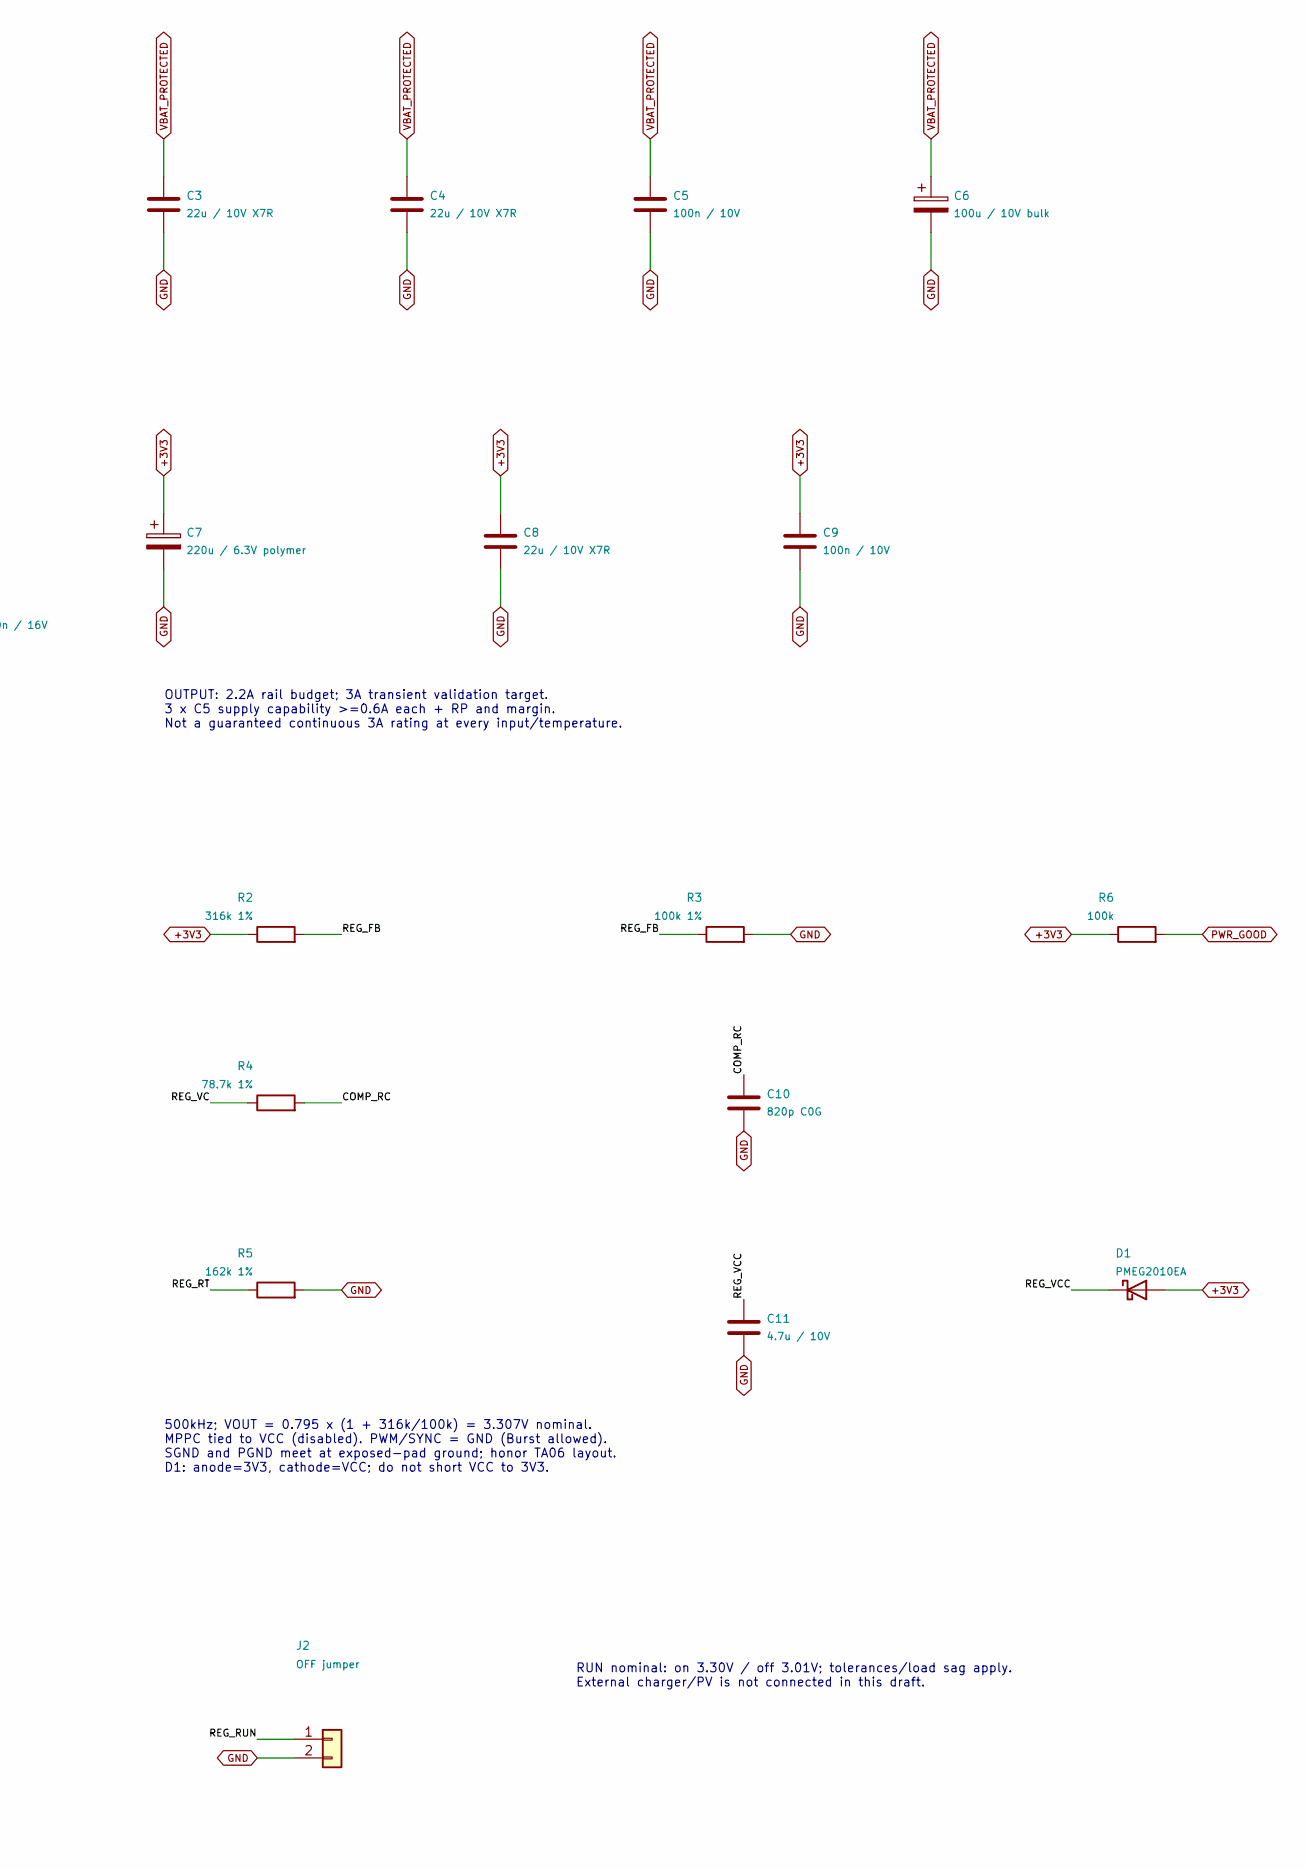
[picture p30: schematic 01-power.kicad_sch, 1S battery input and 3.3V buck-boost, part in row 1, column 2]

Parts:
C1, C2: 100n / 16V; C_0603_1608Metric
C3, C4, C8: 22u / 10V X7R; C_0805_2012Metric
C5, C9: 100n / 10V; C_0603_1608Metric
C6: 100u / 10V bulk; CP_Elec_6.3x5.8
C7: 220u / 6.3V polymer; CP_Elec_6.3x5.9; MPN 6SVPE220M
C10: 820p C0G; C_0603_1608Metric
C11: 4.7u / 10V; C_0805_2012Metric
C12: 470p C0G; C_0603_1608Metric
D1: PMEG2010EA; D_SOD-323; MPN PMEG2010EA,115
F1: 5A fuse; Fuse_Littelfuse-NANO2-451_453; MPN 0451005.MRL
J1: 1S Li-ion pack; JST_VH_B2P-VH_1x02_P3.96mm_Vertical; MPN B2P-VH(LF)(SN)
J2: OFF jumper; PinHeader_1x02_P2.54mm_Vertical
L1: 4.7uH; L_Coilcraft_XAL7070-XXX; MPN XAL7070-472MEC
Q1: DMP2008UFG-7; Diodes_PowerDI3333-8; MPN DMP2008UFG-7
R1, R6: 100k; R_0603_1608Metric
R2: 316k 1%; R_0603_1608Metric
R3, R8: 100k 1%; R_0603_1608Metric
R4: 78.7k 1%; R_0603_1608Metric
R5: 162k 1%; R_0603_1608Metric
R7: 174k 1%; R_0603_1608Metric
U1: LTC3119IFE#PBF; TSSOP-28-1EP_4.4x9.7mm_P0.65mm_EP3.05x7.56mm; MPN LTC3119IFE#PBF

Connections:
+3V3: C7.1, C8.1, C9.1, D1.2 (A), R2.1, R6.1, U1.6 (PVOUT), U1.7 (PVOUT); also elsewhere on the board
/1S battery input and 3.3V buck-boost/BAT_FUSED: F1.2, Q1.5 (D_5-8_EP)
/1S battery input and 3.3V buck-boost/BAT_PLUS: F1.1, J1.1
/1S battery input and 3.3V buck-boost/BST1: C1.1, U1.26 (BST1)
/1S battery input and 3.3V buck-boost/BST2: C2.1, U1.3 (BST2)
/1S battery input and 3.3V buck-boost/COMP_RC: C10.1, R4.2
/1S battery input and 3.3V buck-boost/REG_FB: R2.2, R3.1, U1.12 (FB)
/1S battery input and 3.3V buck-boost/REG_RT: R5.1, U1.17 (RT)
/1S battery input and 3.3V buck-boost/REG_RUN: C12.1, J2.1, R7.2, R8.1, U1.18 (RUN)
/1S battery input and 3.3V buck-boost/REG_VC: R4.1, U1.13 (VC)
/1S battery input and 3.3V buck-boost/REG_VCC: C11.1, D1.1 (K), U1.11 (SVCC), U1.15 (MPPC), U1.16 (VCC)
/1S battery input and 3.3V buck-boost/REV_GATE: Q1.4 (G), R1.1
/1S battery input and 3.3V buck-boost/SW1: C1.2, L1.1, U1.21 (SW1), U1.24 (SW1)
/1S battery input and 3.3V buck-boost/SW2: C2.2, L1.2, U1.5 (SW2), U1.8 (SW2)
GND: C3.2, C4.2, C5.2, C6.2, C7.2, C8.2, C9.2, C10.2, C11.2, C12.2, J1.2, J2.2, R1.2, R3.2, R5.2, R8.2, U1.4 (PGND), U1.9 (PGND), U1.14 (SGND), U1.20 (PGND), U1.25 (PGND), U1.28 (PWM_SYNC), U1.29 (EP_PGND); also elsewhere on the board
PWR_GOOD: R6.2, U1.10 (PGOOD); also elsewhere on the board
VBAT_PROTECTED: C3.1, C4.1, C5.1, C6.1, Q1.1 (S), Q1.2 (S), Q1.3 (S), R7.1, U1.19 (VIN), U1.22 (PVIN), U1.23 (PVIN); also elsewhere on the board

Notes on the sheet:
3.3V BUCK-BOOST / LTC3119 TA06 BASIS
BATTERY INPUT / REVERSE POLARITY
Q1 drain faces battery, source faces converter. Body diode initially conducts toward load. Protected pack / connector must support >=5A peak. Fuse is not a substitute for cell protection.
OUTPUT: 2.2A rail budget; 3A transient validation target. 3 x C5 supply capability >=0.6A each + RP and margin. Not a guaranteed continuous 3A rating at every input/temperature.
RUN nominal: on 3.30V / off 3.01V; tolerances/load sag apply. External charger/PV is not connected in this draft.
BATTERY UVLO / USER OFF
500kHz; VOUT = 0.795 x (1 + 316k/100k) = 3.307V nominal. MPPC tied to VCC (disabled). PWM/SYNC = GND (Burst allowed). SGND and PGND meet at exposed-pad ground; honor TA06 layout. D1: anode=3V3, cathode=VCC; do not short VCC to 3V3.

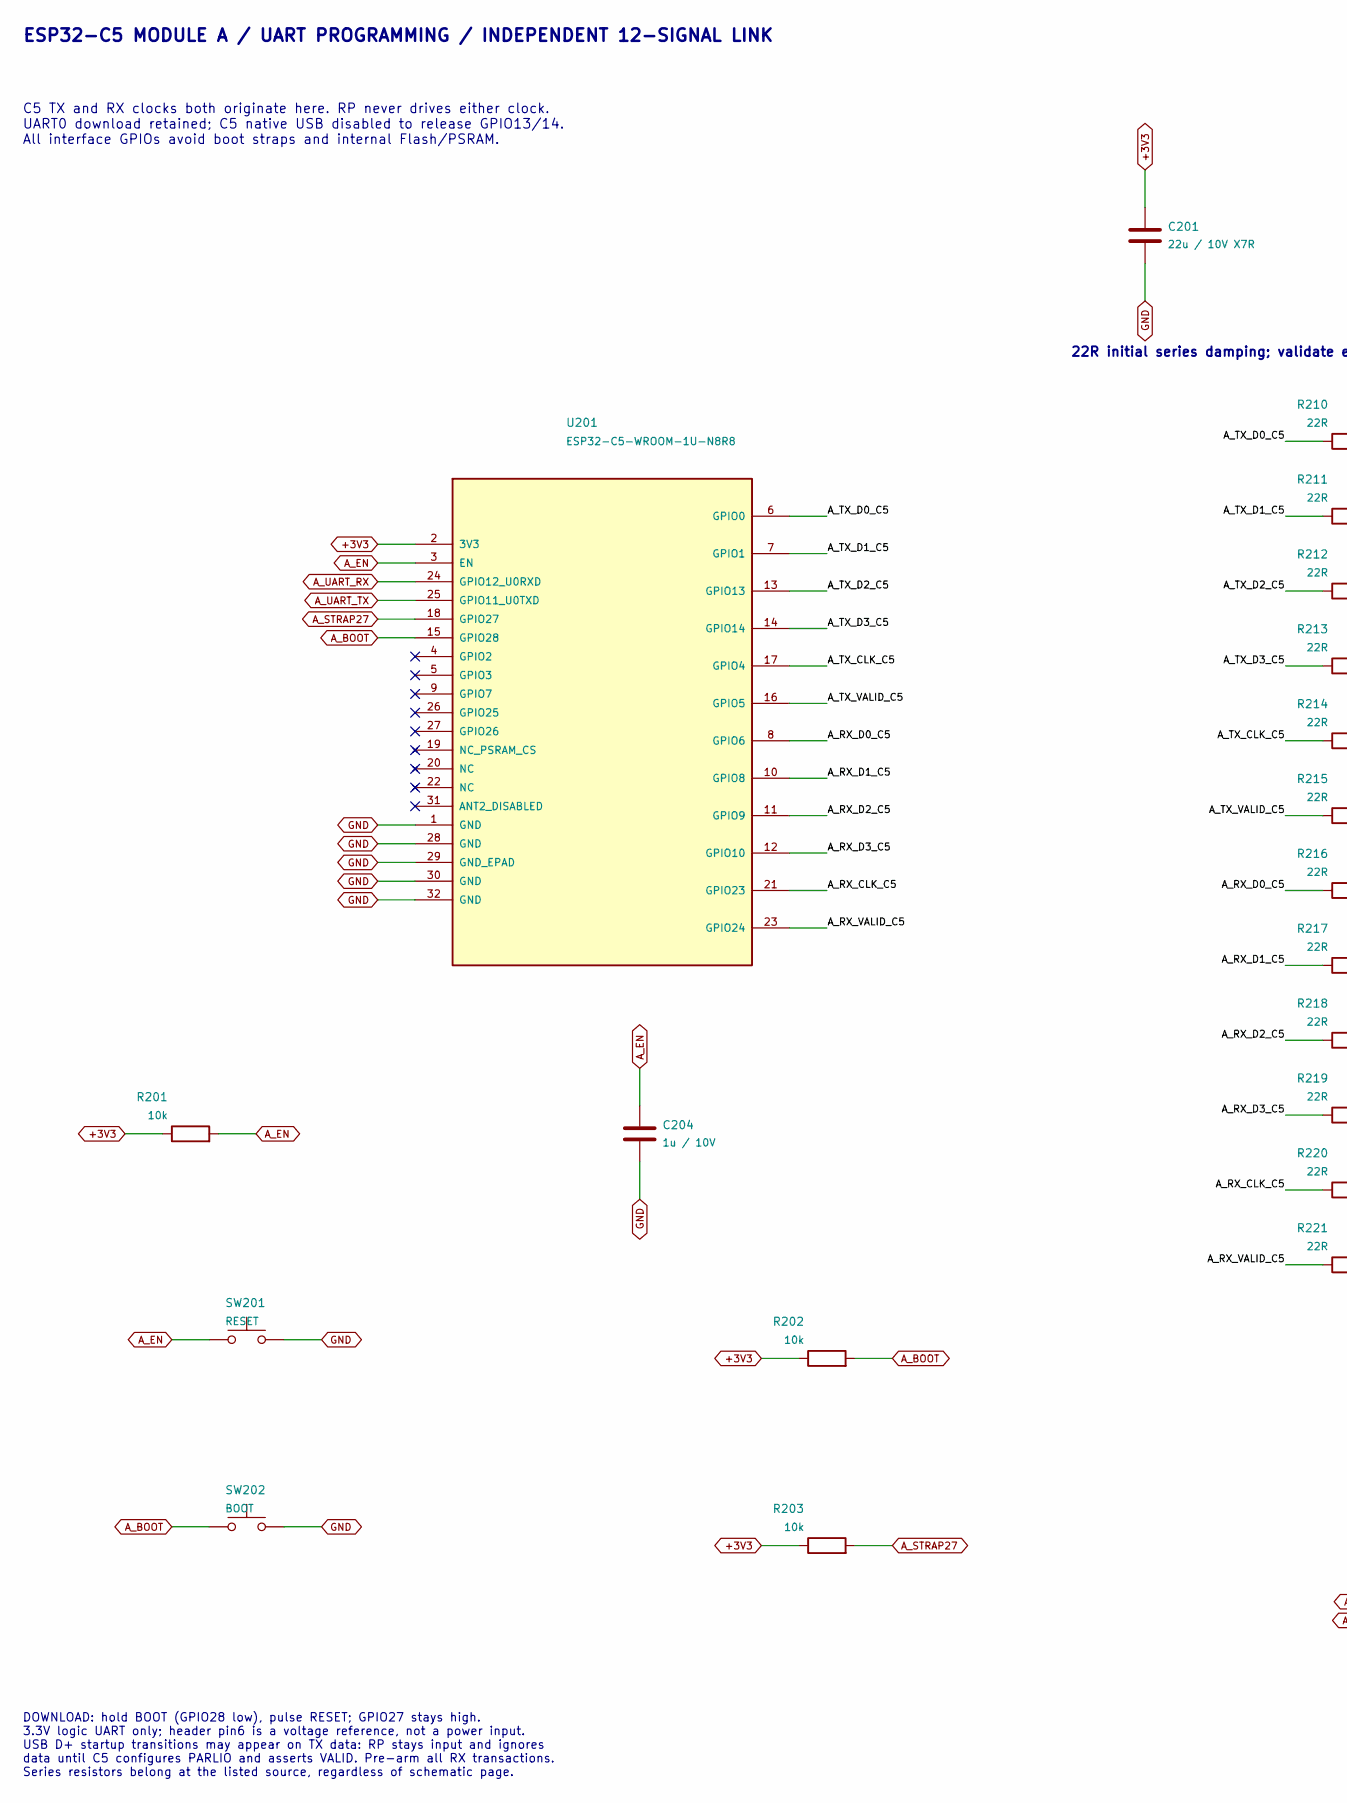
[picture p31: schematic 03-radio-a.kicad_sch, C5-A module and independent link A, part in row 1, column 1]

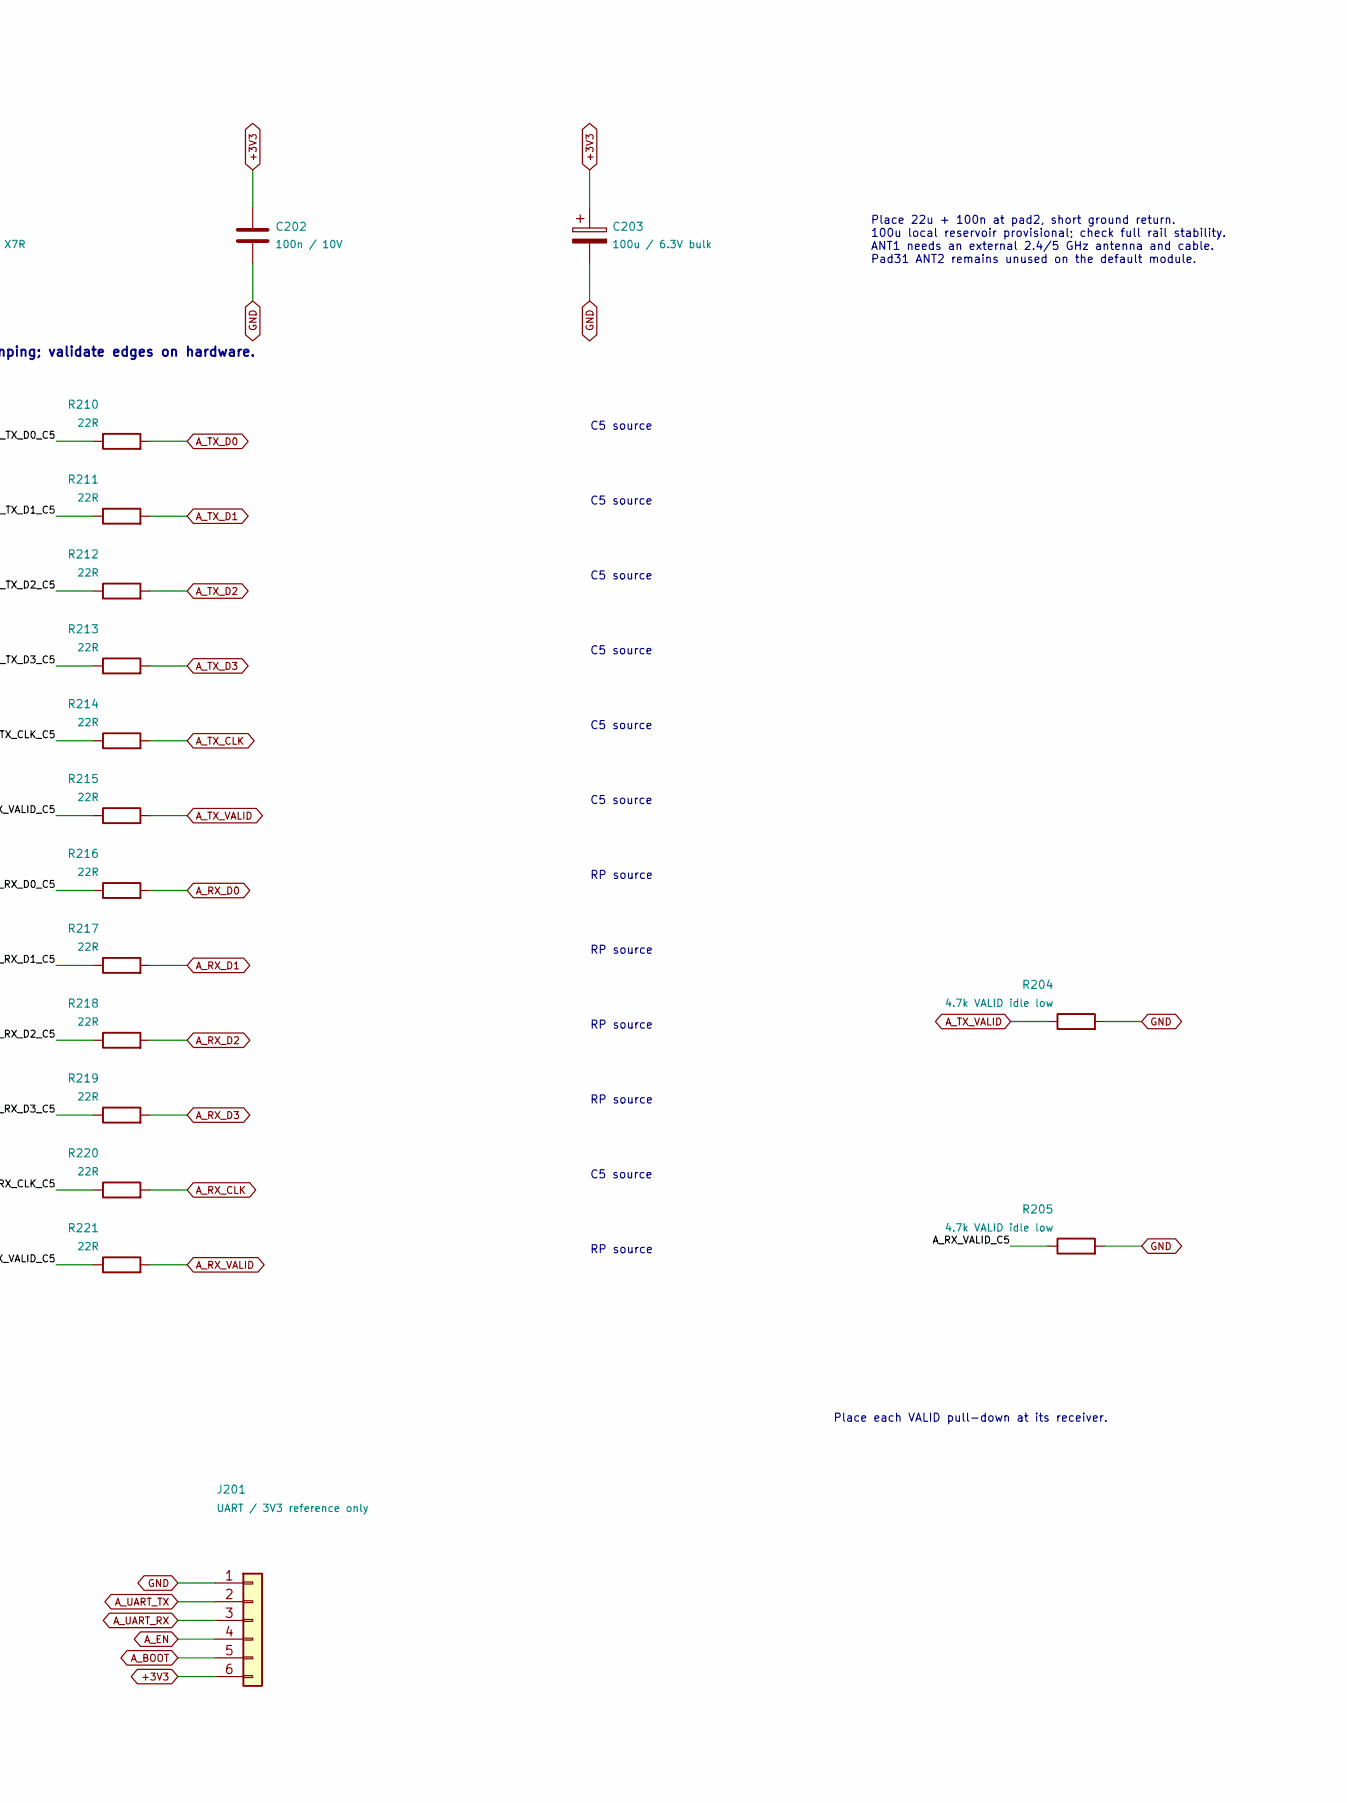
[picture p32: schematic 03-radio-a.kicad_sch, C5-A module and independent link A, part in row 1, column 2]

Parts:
C201: 22u / 10V X7R; C_0805_2012Metric
C202: 100n / 10V; C_0603_1608Metric
C203: 100u / 6.3V bulk; CP_Elec_6.3x5.8
C204: 1u / 10V; C_0603_1608Metric
J201: UART / 3V3 reference only; PinHeader_1x06_P2.54mm_Vertical
R201, R202, R203: 10k; R_0603_1608Metric
R204, R205: 4.7k VALID idle low; R_0603_1608Metric
R210, R211, R212, R213, R214, R215, R216, R217, R218, R219, R220, R221: 22R; R_0603_1608Metric
SW201: RESET; SW_Push_1P1T_NO_E-Switch_TL3301NxxxxxG
SW202: BOOT; SW_Push_1P1T_NO_E-Switch_TL3301NxxxxxG
U201: ESP32-C5-WROOM-1U-N8R8; ESP32-C5-WROOM-1U; MPN ESP32-C5-WROOM-1U-N8R8

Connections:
+3V3: C201.1, C202.1, C203.1, J201.6, R201.1, R202.1, R203.1, U201.2 (3V3); also elsewhere on the board
/C5-A module and independent link A/A_RX_CLK_C5: R220.1, U201.21 (GPIO23)
/C5-A module and independent link A/A_RX_D0_C5: R216.1, U201.8 (GPIO6)
/C5-A module and independent link A/A_RX_D1_C5: R217.1, U201.10 (GPIO8)
/C5-A module and independent link A/A_RX_D2_C5: R218.1, U201.11 (GPIO9)
/C5-A module and independent link A/A_RX_D3_C5: R219.1, U201.12 (GPIO10)
/C5-A module and independent link A/A_RX_VALID_C5: R205.1, R221.1, U201.23 (GPIO24)
/C5-A module and independent link A/A_TX_CLK_C5: R214.1, U201.17 (GPIO4)
/C5-A module and independent link A/A_TX_D0_C5: R210.1, U201.6 (GPIO0)
/C5-A module and independent link A/A_TX_D1_C5: R211.1, U201.7 (GPIO1)
/C5-A module and independent link A/A_TX_D2_C5: R212.1, U201.13 (GPIO13)
/C5-A module and independent link A/A_TX_D3_C5: R213.1, U201.14 (GPIO14)
/C5-A module and independent link A/A_TX_VALID_C5: R215.1, U201.16 (GPIO5)
A_BOOT: J201.5, R202.2, SW202.1, U201.15 (GPIO28)
A_EN: C204.1, J201.4, R201.2, SW201.1, U201.3 (EN)
A_RX_CLK: R220.2; also elsewhere on the board
A_RX_D0: R216.2; also elsewhere on the board
A_RX_D1: R217.2; also elsewhere on the board
A_RX_D2: R218.2; also elsewhere on the board
A_RX_D3: R219.2; also elsewhere on the board
A_RX_VALID: R221.2; also elsewhere on the board
A_STRAP27: R203.2, U201.18 (GPIO27)
A_TX_CLK: R214.2; also elsewhere on the board
A_TX_D0: R210.2; also elsewhere on the board
A_TX_D1: R211.2; also elsewhere on the board
A_TX_D2: R212.2; also elsewhere on the board
A_TX_D3: R213.2; also elsewhere on the board
A_TX_VALID: R204.1, R215.2; also elsewhere on the board
A_UART_RX: J201.3, U201.24 (GPIO12_U0RXD)
A_UART_TX: J201.2, U201.25 (GPIO11_U0TXD)
GND: C201.2, C202.2, C203.2, C204.2, J201.1, R204.2, R205.2, SW201.2, SW202.2, U201.1 (GND), U201.28 (GND), U201.29 (GND_EPAD), U201.30 (GND), U201.32 (GND); also elsewhere on the board

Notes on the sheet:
22R initial series damping; validate edges on hardware.
ESP32-C5 MODULE A / UART PROGRAMMING / INDEPENDENT 12-SIGNAL LINK
Place each VALID pull-down at its receiver.
C5 source
RP source
Place 22u + 100n at pad2, short ground return. 100u local reservoir provisional; check full rail stability. ANT1 needs an external 2.4/5 GHz antenna and cable. Pad31 ANT2 remains unused on the default module.
C5 TX and RX clocks both originate here. RP never drives either clock. UART0 download retained; C5 native USB disabled to release GPIO13/14. All interface GPIOs avoid boot straps and internal Flash/PSRAM.
DOWNLOAD: hold BOOT (GPIO28 low), pulse RESET; GPIO27 stays high. 3.3V logic UART only; header pin6 is a voltage reference, not a power input. USB D+ startup transitions may appear on TX data: RP stays input and ignores data until C5 configures PARLIO and asserts VALID. Pre-arm all RX transactions.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

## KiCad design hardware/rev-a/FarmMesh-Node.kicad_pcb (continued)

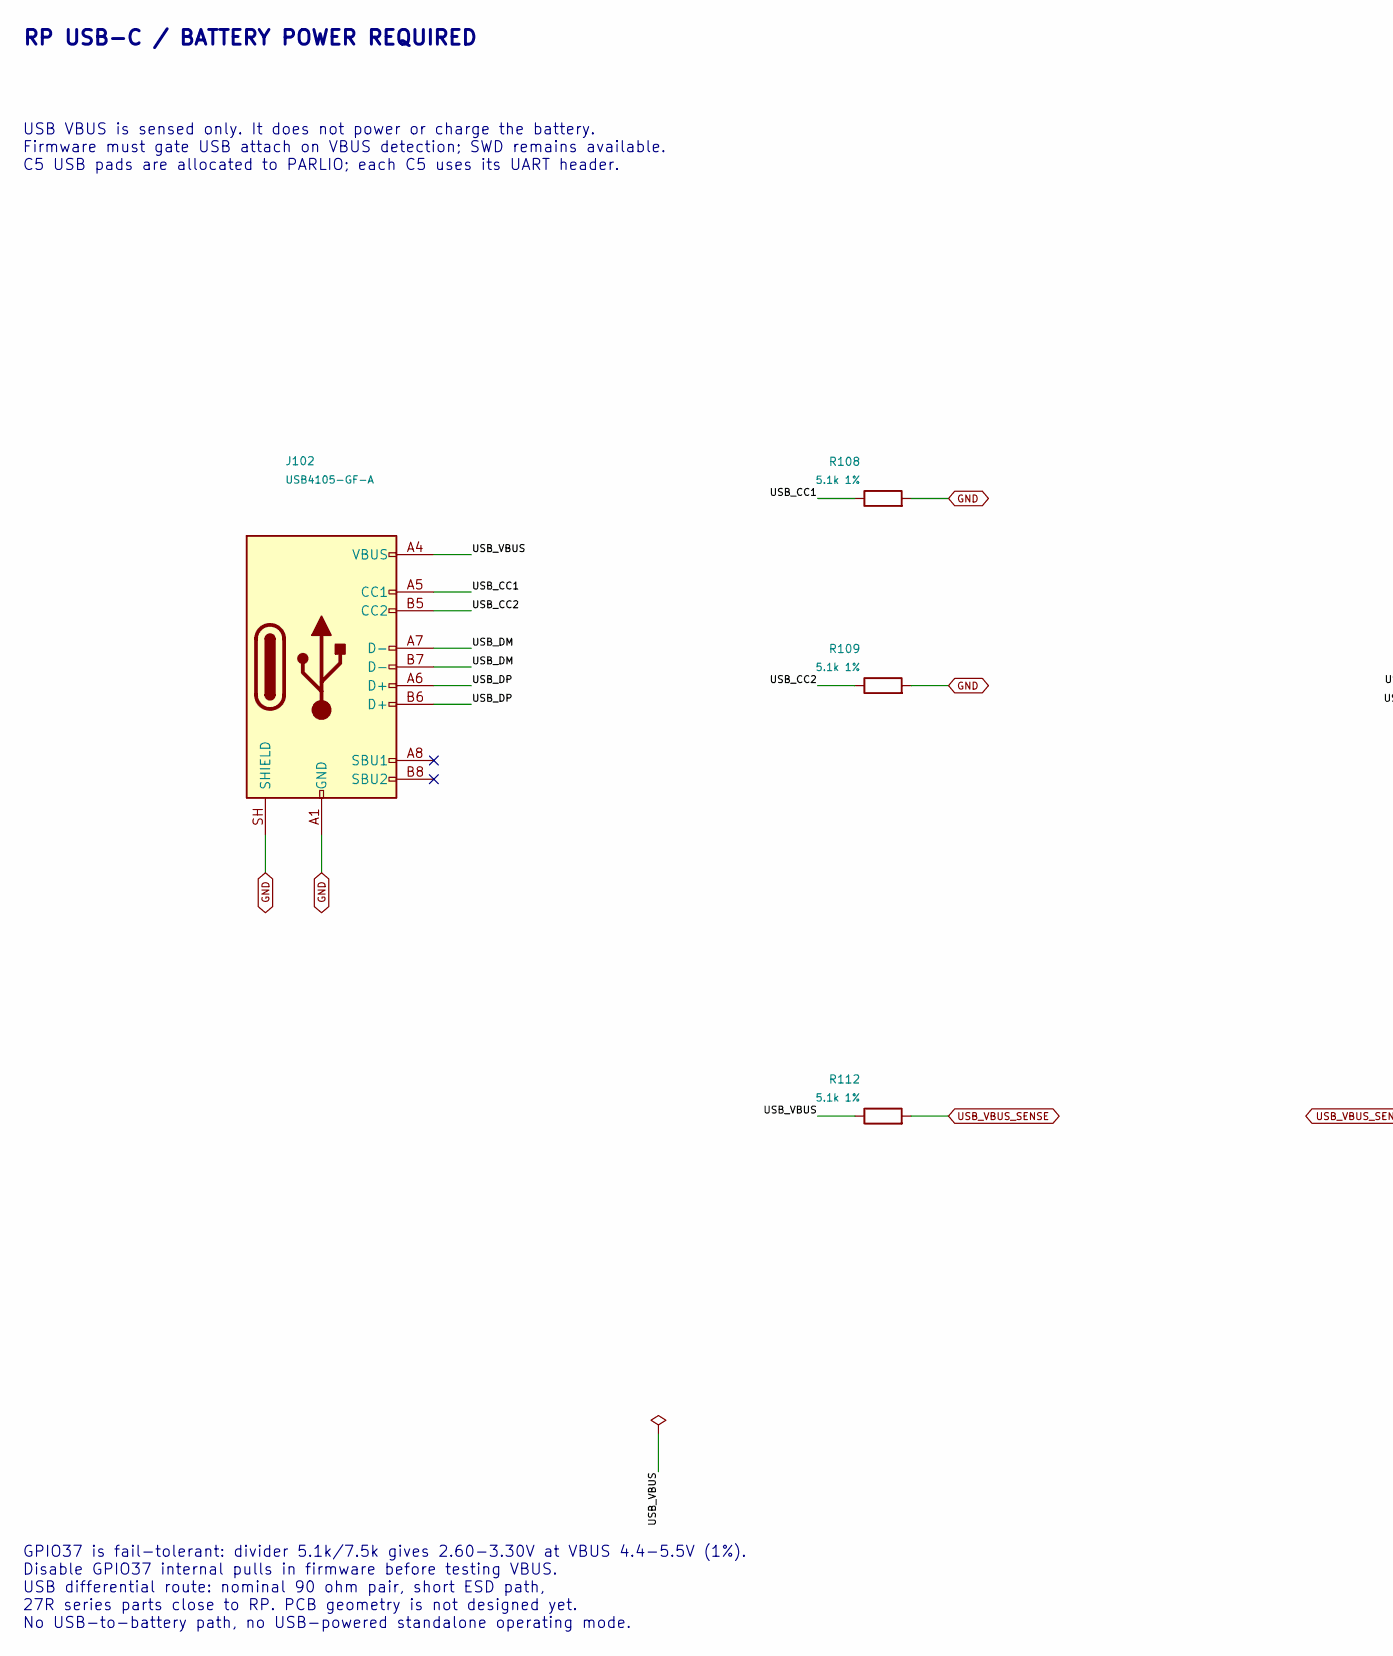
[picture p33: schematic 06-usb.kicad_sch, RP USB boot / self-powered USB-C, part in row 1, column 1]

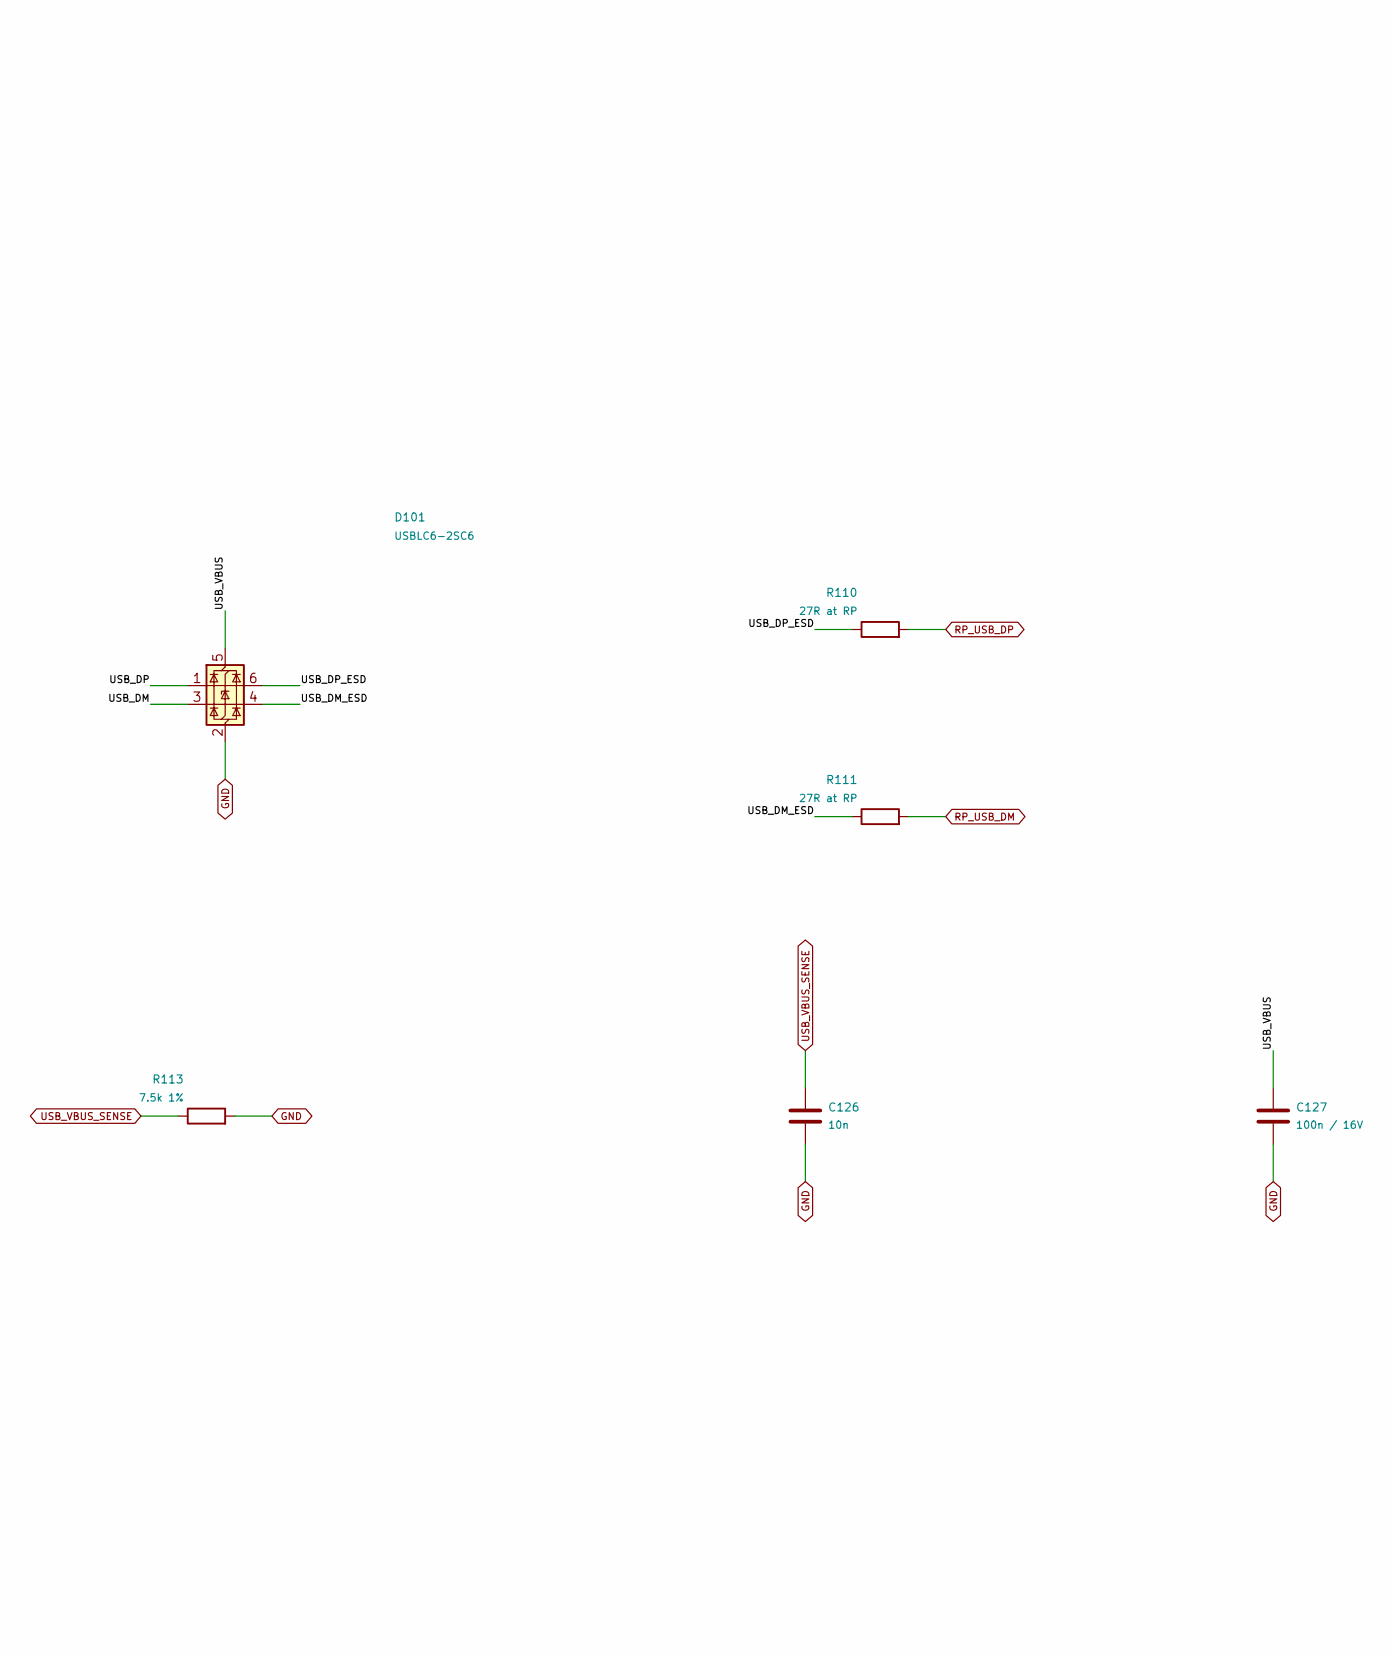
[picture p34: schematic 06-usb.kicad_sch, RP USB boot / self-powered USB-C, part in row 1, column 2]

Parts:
C126: 10n; C_0603_1608Metric
C127: 100n / 16V; C_0603_1608Metric
D101: USBLC6-2SC6; SOT-23-6; MPN USBLC6-2SC6
J102: USB4105-GF-A; USB_C_Receptacle_GCT_USB4105-xx-A_16P_TopMnt_Horizontal; MPN USB4105-GF-A
R108, R109, R112: 5.1k 1%; R_0603_1608Metric
R110, R111: 27R at RP; R_0603_1608Metric
R113: 7.5k 1%; R_0603_1608Metric

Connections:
/RP USB boot / self-powered USB-C/USB_CC1: J102.A5 (CC1), R108.1
/RP USB boot / self-powered USB-C/USB_CC2: J102.B5 (CC2), R109.1
/RP USB boot / self-powered USB-C/USB_DM: D101.3 (I/O2), J102.A7 (D-), J102.B7 (D-)
/RP USB boot / self-powered USB-C/USB_DP: D101.1 (I/O1), J102.A6 (D+), J102.B6 (D+)
/RP USB boot / self-powered USB-C/USB_VBUS: C127.1, D101.5 (VBUS), J102.A4 (VBUS), J102.A9 (VBUS), J102.B4 (VBUS), J102.B9 (VBUS), R112.1; also elsewhere on the board
GND: C126.2, C127.2, D101.2 (GND), J102.A1 (GND), J102.A12 (GND), J102.B1 (GND), J102.B12 (GND), J102.SH (SHIELD), R108.2, R109.2, R113.2; also elsewhere on the board
RP_USB_DM: R111.2; also elsewhere on the board
RP_USB_DP: R110.2; also elsewhere on the board
USB_VBUS_SENSE: C126.1, R112.2, R113.1; also elsewhere on the board

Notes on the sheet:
GPIO37 is fail-tolerant: divider 5.1k/7.5k gives 2.60-3.30V at VBUS 4.4-5.5V (1%). Disable GPIO37 internal pulls in firmware before testing VBUS. USB differential route: nominal 90 ohm pair, short ESD path, 27R series parts close to RP. PCB geometry is not designed yet. No USB-to-battery path, no U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
USB VBUS is sensed only. It does not power or charge the battery. Firmware must gate USB attach on VBUS detection; SWD remains available. C5 USB pads are allocated to PARLIO; each C5 uses its UART header.
RP USB-C / BATTERY POWER REQUIRED

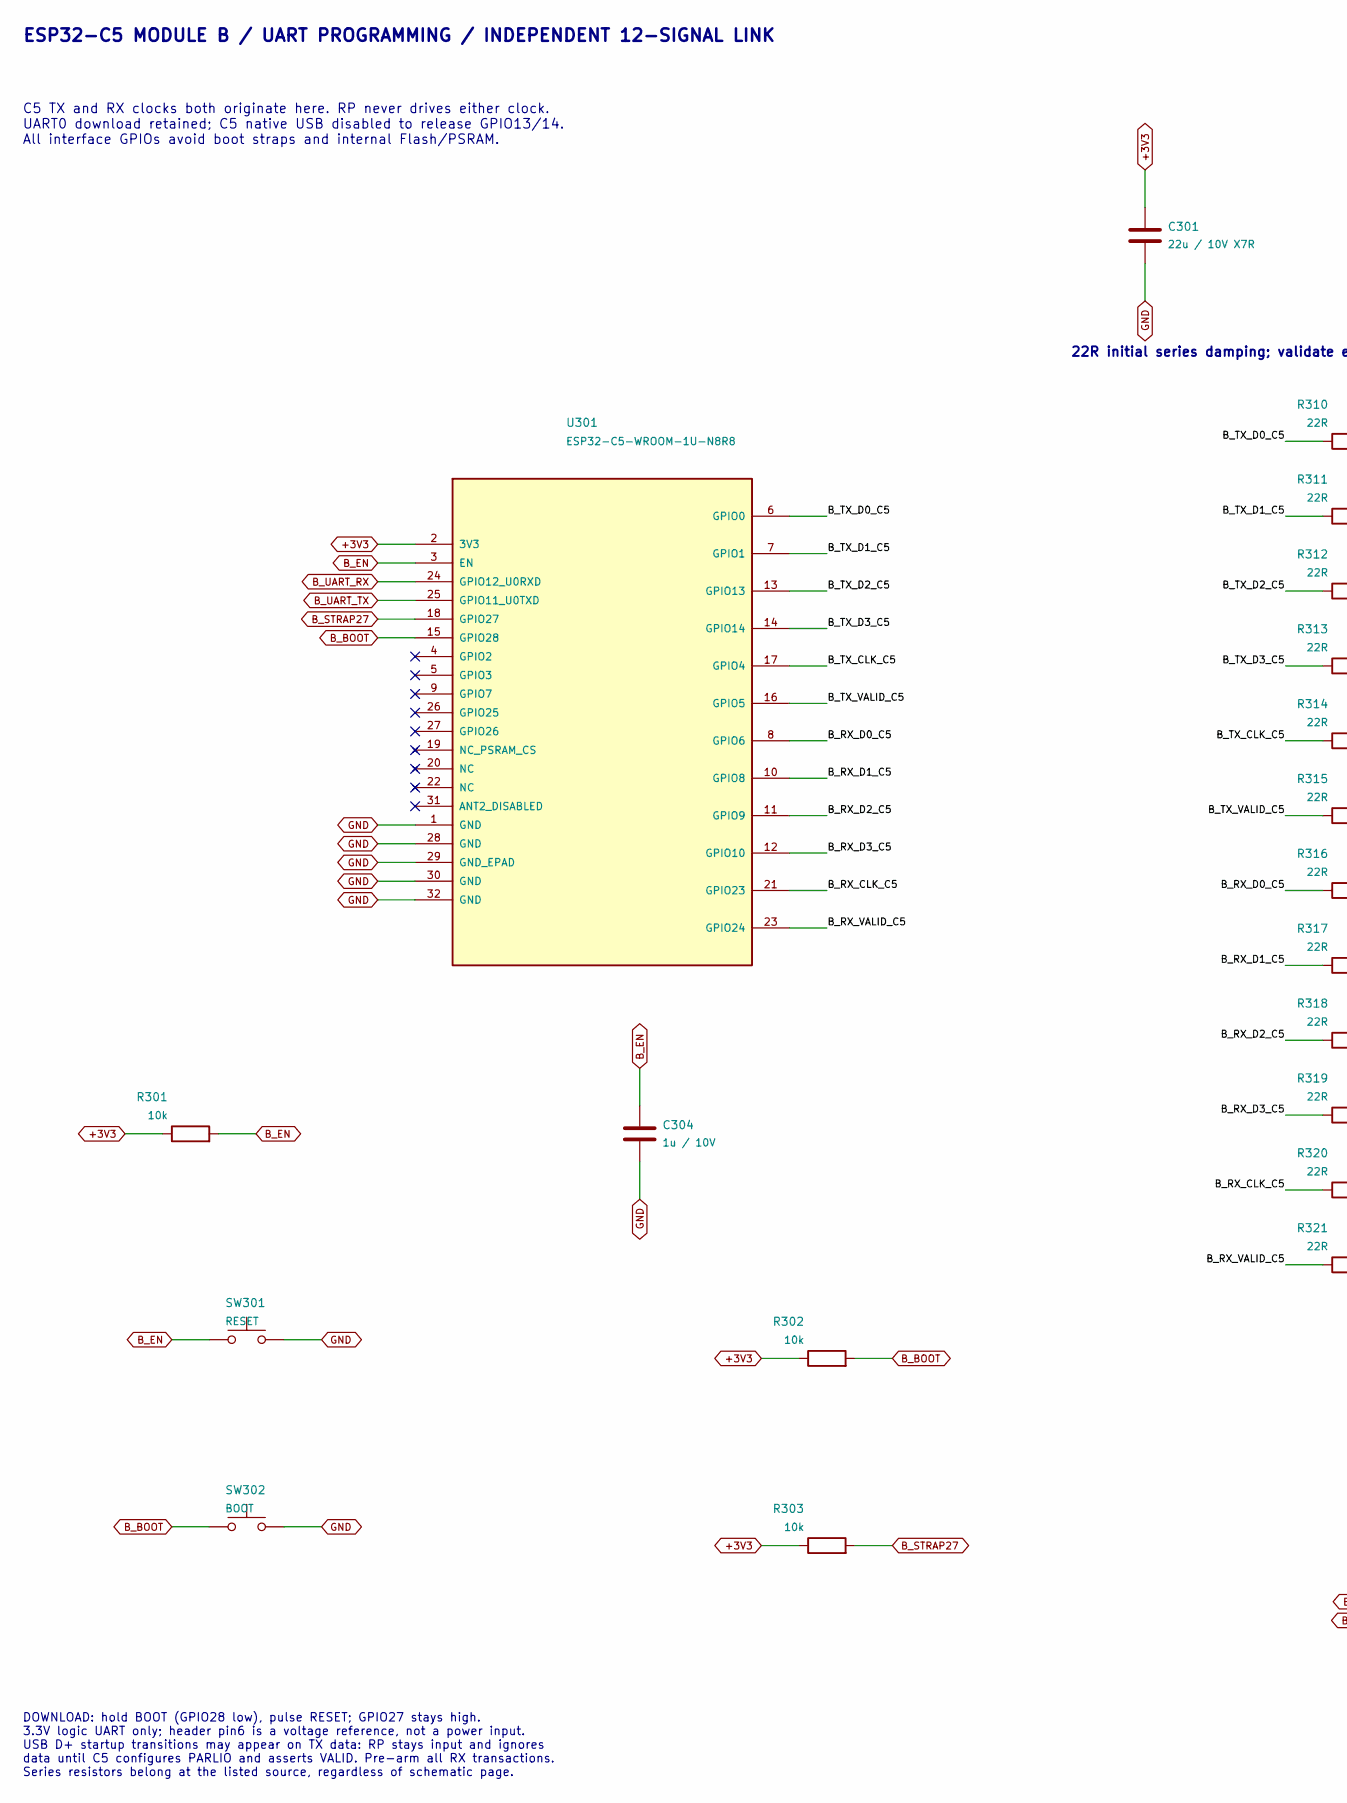
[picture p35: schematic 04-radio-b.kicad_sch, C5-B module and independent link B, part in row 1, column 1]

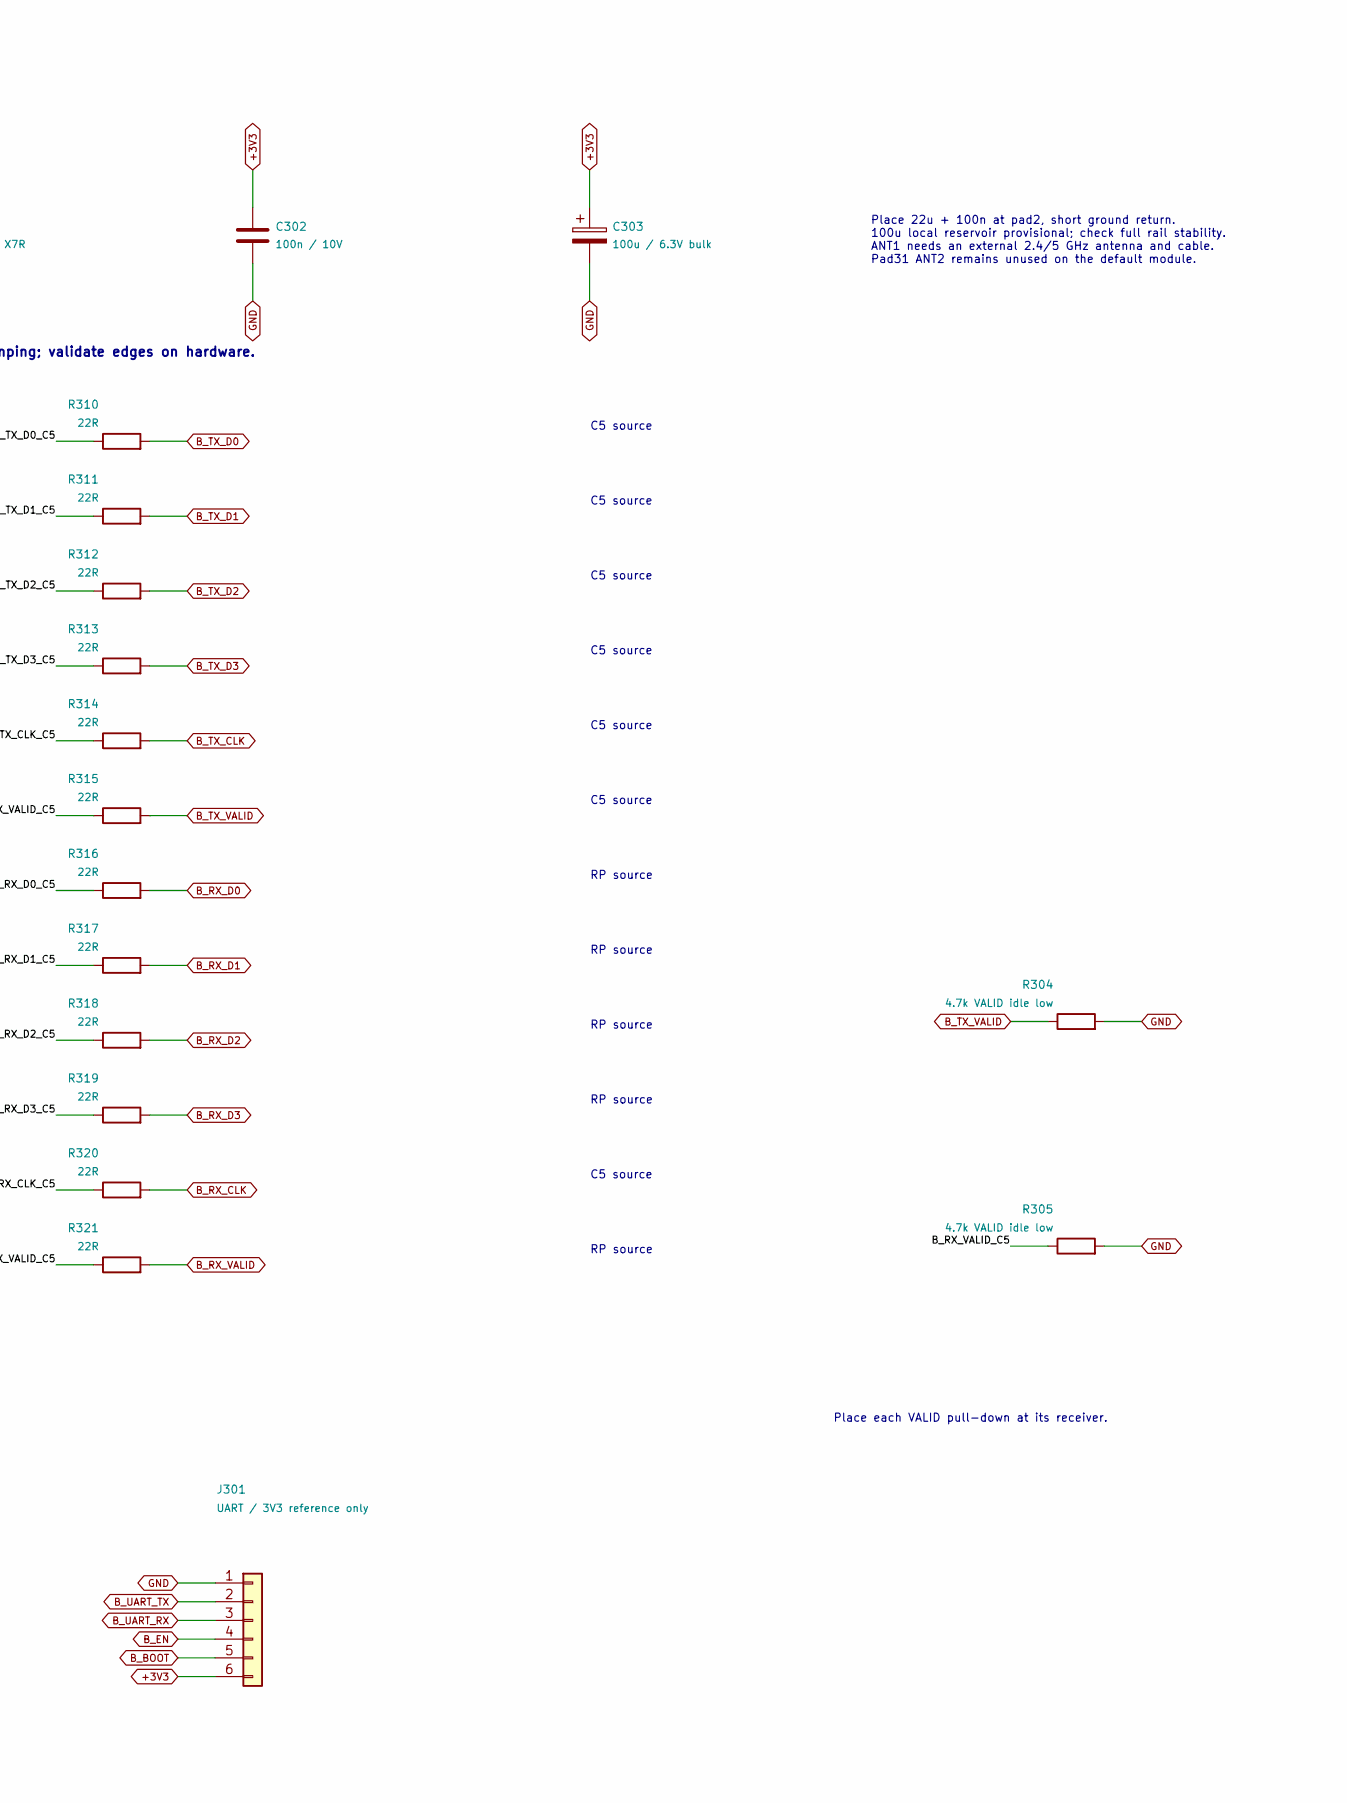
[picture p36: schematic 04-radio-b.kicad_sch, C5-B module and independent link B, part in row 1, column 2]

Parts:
C301: 22u / 10V X7R; C_0805_2012Metric
C302: 100n / 10V; C_0603_1608Metric
C303: 100u / 6.3V bulk; CP_Elec_6.3x5.8
C304: 1u / 10V; C_0603_1608Metric
J301: UART / 3V3 reference only; PinHeader_1x06_P2.54mm_Vertical
R301, R302, R303: 10k; R_0603_1608Metric
R304, R305: 4.7k VALID idle low; R_0603_1608Metric
R310, R311, R312, R313, R314, R315, R316, R317, R318, R319, R320, R321: 22R; R_0603_1608Metric
SW301: RESET; SW_Push_1P1T_NO_E-Switch_TL3301NxxxxxG
SW302: BOOT; SW_Push_1P1T_NO_E-Switch_TL3301NxxxxxG
U301: ESP32-C5-WROOM-1U-N8R8; ESP32-C5-WROOM-1U; MPN ESP32-C5-WROOM-1U-N8R8

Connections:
+3V3: C301.1, C302.1, C303.1, J301.6, R301.1, R302.1, R303.1, U301.2 (3V3); also elsewhere on the board
/C5-B module and independent link B/B_RX_CLK_C5: R320.1, U301.21 (GPIO23)
/C5-B module and independent link B/B_RX_D0_C5: R316.1, U301.8 (GPIO6)
/C5-B module and independent link B/B_RX_D1_C5: R317.1, U301.10 (GPIO8)
/C5-B module and independent link B/B_RX_D2_C5: R318.1, U301.11 (GPIO9)
/C5-B module and independent link B/B_RX_D3_C5: R319.1, U301.12 (GPIO10)
/C5-B module and independent link B/B_RX_VALID_C5: R305.1, R321.1, U301.23 (GPIO24)
/C5-B module and independent link B/B_TX_CLK_C5: R314.1, U301.17 (GPIO4)
/C5-B module and independent link B/B_TX_D0_C5: R310.1, U301.6 (GPIO0)
/C5-B module and independent link B/B_TX_D1_C5: R311.1, U301.7 (GPIO1)
/C5-B module and independent link B/B_TX_D2_C5: R312.1, U301.13 (GPIO13)
/C5-B module and independent link B/B_TX_D3_C5: R313.1, U301.14 (GPIO14)
/C5-B module and independent link B/B_TX_VALID_C5: R315.1, U301.16 (GPIO5)
B_BOOT: J301.5, R302.2, SW302.1, U301.15 (GPIO28)
B_EN: C304.1, J301.4, R301.2, SW301.1, U301.3 (EN)
B_RX_CLK: R320.2; also elsewhere on the board
B_RX_D0: R316.2; also elsewhere on the board
B_RX_D1: R317.2; also elsewhere on the board
B_RX_D2: R318.2; also elsewhere on the board
B_RX_D3: R319.2; also elsewhere on the board
B_RX_VALID: R321.2; also elsewhere on the board
B_STRAP27: R303.2, U301.18 (GPIO27)
B_TX_CLK: R314.2; also elsewhere on the board
B_TX_D0: R310.2; also elsewhere on the board
B_TX_D1: R311.2; also elsewhere on the board
B_TX_D2: R312.2; also elsewhere on the board
B_TX_D3: R313.2; also elsewhere on the board
B_TX_VALID: R304.1, R315.2; also elsewhere on the board
B_UART_RX: J301.3, U301.24 (GPIO12_U0RXD)
B_UART_TX: J301.2, U301.25 (GPIO11_U0TXD)
GND: C301.2, C302.2, C303.2, C304.2, J301.1, R304.2, R305.2, SW301.2, SW302.2, U301.1 (GND), U301.28 (GND), U301.29 (GND_EPAD), U301.30 (GND), U301.32 (GND); also elsewhere on the board

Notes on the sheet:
Place each VALID pull-down at its receiver.
C5 source
RP source
ESP32-C5 MODULE B / UART PROGRAMMING / INDEPENDENT 12-SIGNAL LINK
DOWNLOAD: hold BOOT (GPIO28 low), pulse RESET; GPIO27 stays high. 3.3V logic UART only; header pin6 is a voltage reference, not a power input. USB D+ startup transitions may appear on TX data: RP stays input and ignores data until C5 configures PARLIO and asserts VALID. Pre-arm all RX transactions.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
22R initial series damping; validate edges on hardware.
C5 TX and RX clocks both originate here. RP never drives either clock. UART0 download retained; C5 native USB disabled to release GPIO13/14. All interface GPIOs avoid boot straps and internal Flash/PSRAM.
Place 22u + 100n at pad2, short ground return. 100u local reservoir provisional; check full rail stability. ANT1 needs an external 2.4/5 GHz antenna and cable. Pad31 ANT2 remains unused on the default module.

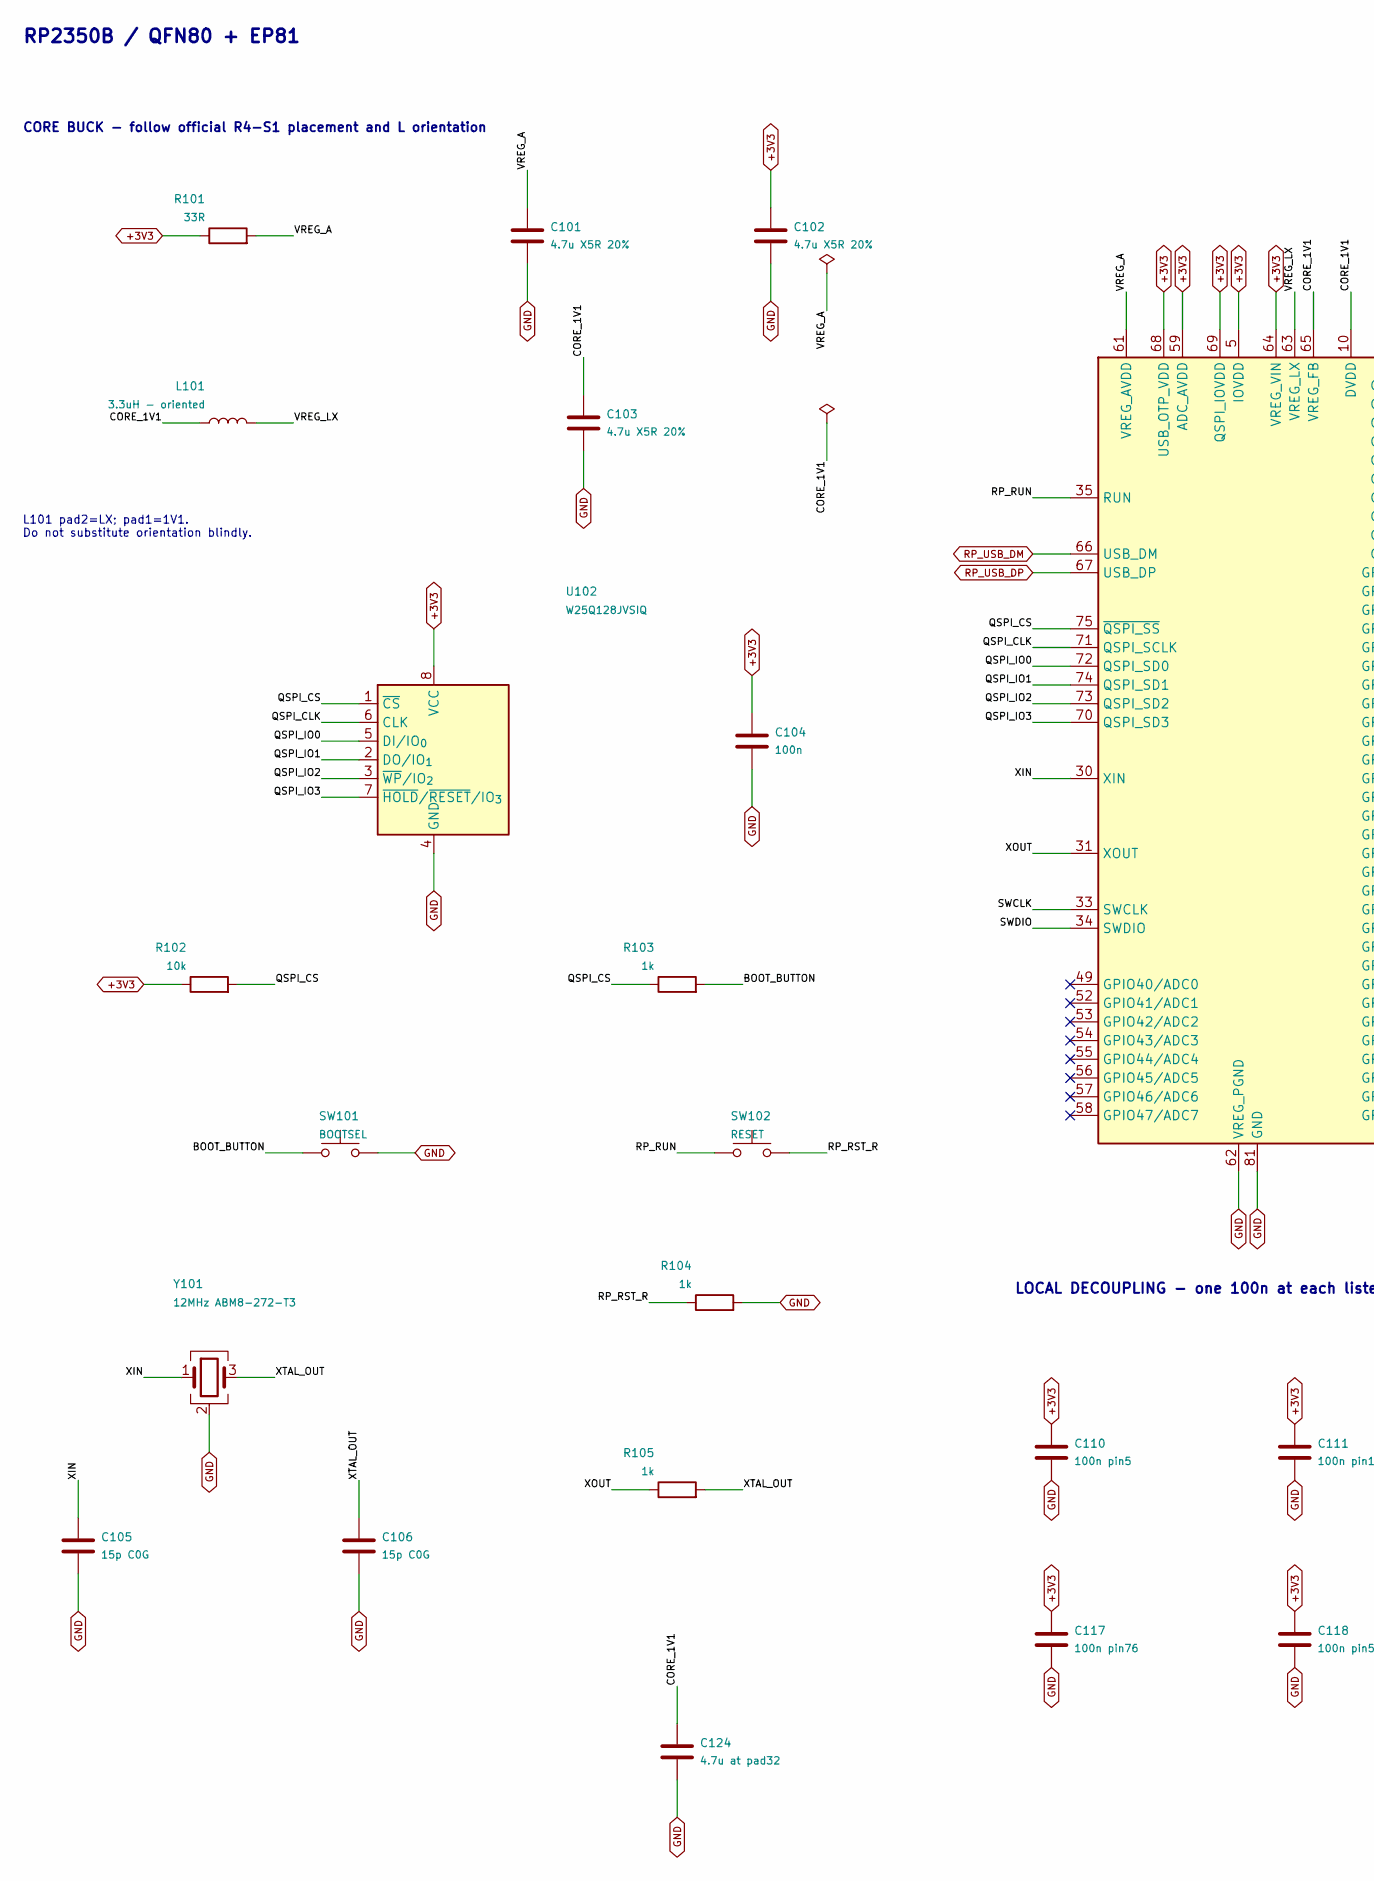
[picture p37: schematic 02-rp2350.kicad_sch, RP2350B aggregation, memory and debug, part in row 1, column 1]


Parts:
C101, C102, C103: 4.7u X5R 20%; C_0603_1608Metric
C104: 100n; C_0603_1608Metric
C105, C106: 15p C0G; C_0603_1608Metric
C110: 100n pin5; C_0603_1608Metric
C111: 100n pin15; C_0603_1608Metric
C112: 100n pin24; C_0603_1608Metric
C113: 100n pin29; C_0603_1608Metric
C114: 100n pin41; C_0603_1608Metric
C115: 100n pin50; C_0603_1608Metric
C116: 100n pin60; C_0603_1608Metric
C117: 100n pin76; C_0603_1608Metric
C118: 100n pin59; C_0603_1608Metric
C119: 100n pin68; C_0603_1608Metric
C120: 100n pin69; C_0603_1608Metric
C121: 100n pin10; C_0603_1608Metric
C122: 100n pin32; C_0603_1608Metric
C123: 100n pin51; C_0603_1608Metric
C124: 4.7u at pad32; C_0603_1608Metric
J101: SWD / 3V3 ref only; PinHeader_1x05_P2.54mm_Vertical
L101: 3.3uH - oriented; AOTA-B201610S3R3-101-T; MPN AOTA-B201610S3R3-101-T
R101: 33R; R_0603_1608Metric
R102: 10k; R_0603_1608Metric
R103, R104, R105: 1k; R_0603_1608Metric
SW101: BOOTSEL; SW_Push_1P1T_NO_E-Switch_TL3301NxxxxxG
SW102: RESET; SW_Push_1P1T_NO_E-Switch_TL3301NxxxxxG
U101: RP2350B; QFN-80-1EP_10x10mm_P0.4mm_EP3.4x3.4mm; MPN RP2350B
U102: W25Q128JVSIQ; SOIC-8_5.3x5.3mm_P1.27mm; MPN W25Q128JVSIQ
Y101: 12MHz ABM8-272-T3; Crystal_SMD_3225-4Pin_3.2x2.5mm; MPN ABM8-272-T3

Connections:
+3V3: C102.1, C104.1, C110.1, C111.1, C112.1, C113.1, C114.1, C115.1, C116.1, C117.1, C118.1, C119.1, C120.1, J101.1, R101.1, R102.1, U101.5 (IOVDD), U101.15 (IOVDD), U101.24 (IOVDD), U101.29 (IOVDD), U101.41 (IOVDD), U101.50 (IOVDD), U101.59 (ADC_AVDD), U101.60 (IOVDD), U101.64 (VREG_VIN), U101.68 (USB_OTP_VDD), U101.69 (QSPI_IOVDD), U101.76 (IOVDD), U102.8 (VCC); also elsewhere on the board
/RP2350B aggregation, memory and debug/BOOT_BUTTON: R103.2, SW101.1
/RP2350B aggregation, memory and debug/QSPI_CLK: U101.71 (QSPI_SCLK), U102.6 (CLK)
/RP2350B aggregation, memory and debug/QSPI_CS: R102.2, R103.1, U101.75 (~QSPI_SS), U102.1 (~CS)
/RP2350B aggregation, memory and debug/QSPI_IO0: U101.72 (QSPI_SD0), U102.5 (DI/IO_{0})
/RP2350B aggregation, memory and debug/QSPI_IO1: U101.74 (QSPI_SD1), U102.2 (DO/IO_{1})
/RP2350B aggregation, memory and debug/QSPI_IO2: U101.73 (QSPI_SD2), U102.3 (~WP/IO_{2})
/RP2350B aggregation, memory and debug/QSPI_IO3: U101.70 (QSPI_SD3), U102.7 (~HOLD/~RESET/IO_{3})
/RP2350B aggregation, memory and debug/RP_RST_R: R104.1, SW102.2
/RP2350B aggregation, memory and debug/SWCLK: J101.4, U101.33 (SWCLK)
/RP2350B aggregation, memory and debug/SWDIO: J101.2, U101.34 (SWDIO)
/RP2350B aggregation, memory and debug/VREG_A: C101.1, R101.2, U101.61 (VREG_AVDD)
/RP2350B aggregation, memory and debug/VREG_LX: L101.2, U101.63 (VREG_LX)
/RP2350B aggregation, memory and debug/XIN: C105.1, U101.30 (XIN), Y101.1
/RP2350B aggregation, memory and debug/XOUT: R105.1, U101.31 (XOUT)
/RP2350B aggregation, memory and debug/XTAL_OUT: C106.1, R105.2, Y101.3
A_RX_CLK: U101.8 (GPIO10); also elsewhere on the board
A_RX_D0: U101.3 (GPIO6); also elsewhere on the board
A_RX_D1: U101.4 (GPIO7); also elsewhere on the board
A_RX_D2: U101.6 (GPIO8); also elsewhere on the board
A_RX_D3: U101.7 (GPIO9); also elsewhere on the board
A_RX_VALID: U101.9 (GPIO11); also elsewhere on the board
A_TX_CLK: U101.1 (GPIO4); also elsewhere on the board
A_TX_D0: U101.77 (GPIO0); also elsewhere on the board
A_TX_D1: U101.78 (GPIO1); also elsewhere on the board
A_TX_D2: U101.79 (GPIO2); also elsewhere on the board
A_TX_D3: U101.80 (GPIO3); also elsewhere on the board
A_TX_VALID: U101.2 (GPIO5); also elsewhere on the board
B_RX_CLK: U101.22 (GPIO22); also elsewhere on the board
B_RX_D0: U101.18 (GPIO18); also elsewhere on the board
B_RX_D1: U101.19 (GPIO19); also elsewhere on the board
B_RX_D2: U101.20 (GPIO20); also elsewhere on the board
B_RX_D3: U101.21 (GPIO21); also elsewhere on the board
B_RX_VALID: U101.23 (GPIO23); also elsewhere on the board
B_TX_CLK: U101.16 (GPIO16); also elsewhere on the board
B_TX_D0: U101.11 (GPIO12); also elsewhere on the board
B_TX_D1: U101.12 (GPIO13); also elsewhere on the board
B_TX_D2: U101.13 (GPIO14); also elsewhere on the board
B_TX_D3: U101.14 (GPIO15); also elsewhere on the board
B_TX_VALID: U101.17 (GPIO17); also elsewhere on the board
CORE_1V1: C103.1, C121.1, C122.1, C123.1, C124.1, L101.1, U101.10 (DVDD), U101.32 (DVDD), U101.51 (DVDD), U101.65 (VREG_FB); also elsewhere on the board
C_RX_CLK: U101.43 (GPIO34); also elsewhere on the board
C_RX_D0: U101.38 (GPIO30); also elsewhere on the board
C_RX_D1: U101.39 (GPIO31); also elsewhere on the board
C_RX_D2: U101.40 (GPIO32); also elsewhere on the board
C_RX_D3: U101.42 (GPIO33); also elsewhere on the board
C_RX_VALID: U101.44 (GPIO35); also elsewhere on the board
C_TX_CLK: U101.36 (GPIO28); also elsewhere on the board
C_TX_D0: U101.25 (GPIO24); also elsewhere on the board
C_TX_D1: U101.26 (GPIO25); also elsewhere on the board
C_TX_D2: U101.27 (GPIO26); also elsewhere on the board
C_TX_D3: U101.28 (GPIO27); also elsewhere on the board
C_TX_VALID: U101.37 (GPIO29); also elsewhere on the board
GND: C101.2, C102.2, C103.2, C104.2, C105.2, C106.2, C110.2, C111.2, C112.2, C113.2, C114.2, C115.2, C116.2, C117.2, C118.2, C119.2, C120.2, C121.2, C122.2, C123.2, C124.2, J101.3, R104.2, SW101.2, U101.62 (VREG_PGND), U101.81 (GND), U102.4 (GND), Y101.2 (G), Y101.4 (G); also elsewhere on the board
PWR_GOOD: U101.45 (GPIO36); also elsewhere on the board
RP_RUN: J101.5, SW102.1, U101.35 (RUN); also elsewhere on the board
RP_USB_DM: U101.66 (USB_DM); also elsewhere on the board
RP_USB_DP: U101.67 (USB_DP); also elsewhere on the board
USB_VBUS_SENSE: U101.46 (GPIO37); also elsewhere on the board

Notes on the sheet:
LOCAL DECOUPLING - one 100n at each listed supply pad
CORE BUCK - follow official R4-S1 placement and L orientation
PIO0 BASE0: GPIO0..11 = A PIO1 BASE0: GPIO12..23 = B PIO2 BASE16: GPIO24..35 = C 36 = PGOOD; 37 = USB sense (FT pad) 38..47 reserved (NC); battery ADC deferred. PIO timing/programs NOT validated.
RP2350B / QFN80 + EP81
L101 pad2=LX; pad1=1V1. Do not substitute orientation blindly.
SWD DEBUG

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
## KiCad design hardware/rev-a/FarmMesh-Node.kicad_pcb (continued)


Board: 4 copper layers, 100.0 x 100.0 mm, 164 parts (0 on the bottom side), 136 nets.

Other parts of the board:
C128: 100n / 16V at U103; C_0603_1608Metric
C129: 100n / 16V at U104; C_0603_1608Metric
C130: 1n C0G REF; C_0603_1608Metric
H1, H2, H3, H4: M3 / 3.2mm NPTH; MountingHole_3.2mm_M3
R114: 237k 0.1%; R_0603_1608Metric
R115: 100k 0.1%; R_0603_1608Metric
R116: 10k OE pull-up; R_0603_1608Metric
TP1: VBAT_PROTECTED; TestPoint_Pad_D1.5mm
TP2: +3V3; TestPoint_Pad_D1.5mm
TP3, TP102: GND; TestPoint_Pad_D1.5mm
TP101: CORE_1V1; TestPoint_Pad_D1.5mm
TP103: RP_RUN; TestPoint_Pad_D1.5mm
TP104: PWR_GOOD; TestPoint_Pad_D1.5mm
U103: TS3USB30EDGSR; TSSOP-10_3x3mm_P0.5mm
U104: TLV3011BIDBVR; SOT-23-6

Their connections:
+3V3: C128.1, C129.1, R116.1, TP2.1, U103.10, U104.6; also elsewhere on the board
/RP USB boot / self-powered USB-C/USB_DISCONNECT: R116.2, U103.9, U104.1
/RP USB boot / self-powered USB-C/USB_REF: C130.1, U104.3, U104.5
/RP USB boot / self-powered USB-C/USB_VBUS: R114.1; also elsewhere on the board
/RP USB boot / self-powered USB-C/USB_VBUS_CMP: R114.2, R115.1, U104.4
CORE_1V1: TP101.1; also elsewhere on the board
GND: C128.2, C129.2, C130.2, R115.2, TP3.1, TP102.1, U103.1, U103.5, U104.2; also elsewhere on the board
PWR_GOOD: TP104.1; also elsewhere on the board
RP_RUN: TP103.1; also elsewhere on the board
VBAT_PROTECTED: TP1.1; also elsewhere on the board

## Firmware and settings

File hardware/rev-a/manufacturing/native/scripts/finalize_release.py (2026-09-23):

#!/usr/bin/env python3
"""Seal/verify the exact A1 package; never grant approval or edit RELEASE.md.

After export and visual/expert review, update RELEASE.md separately as authorized,
then run this script. It refreshes only the named release documents/review evidence,
rechecks frozen sources and all payload hashes, and writes a deterministic ZIP plus
an external ZIP SHA256. --check-only changes no files and checks an existing ZIP.
Any native/BOM/parts/script change requires a new verification and export.
"""
import argparse
import hashlib
import json
from pathlib import Path
import re
import shutil
import tempfile
import zipfile

from export_manufacturing import (BASE, OUT, DOCS, all_payload_files, copy_documents,
                                 require, require_same_sources, seal_manifest,
                                 sha, verify_closure)

ARCHIVE = BASE/'FarmMesh-Node-A1-manufacturing.zip'
PREFIX = 'FarmMesh-Node-A1/'


def release_status():
    text=(BASE/'RELEASE.md').read_text(encoding='utf-8')
    lines=[line for line in text.splitlines() if re.search(r'\bstatus\s*:',line,re.I)]
    require(bool(lines),'RELEASE.md must explicitly state its status')
    return lines[0]


def verify_zip(path, folder):
    expected={PREFIX+p.relative_to(folder).as_posix():sha(p) for p in all_payload_files(folder)}
    with zipfile.ZipFile(path) as z:
        names=z.namelist()
        require(len(names)==len(set(names)),'Duplicate ZIP members')
        require(set(names)==set(expected),'ZIP contents do not exactly match the sealed package')
        require(z.testzip() is None,'ZIP CRC check failed')
        for name,digest in expected.items():
            require(hashlib.sha256(z.read(name)).hexdigest()==digest,f'ZIP member hash mismatch: {name}')
    return expected


def main():
    parser=argparse.ArgumentParser(description=__doc__)
    parser.add_argument('--check-only',action='store_true',help='Read-only verification of tree, native sources, ZIP and external ZIP SHA')
    parser.add_argument('--review-file',action='append',default=[],type=Path,
                        help='Explicit current A1 review evidence under reports/ or review/; repeat as needed')
    args=parser.parse_args()
    require(not (args.check_only and args.review_file),'--check-only cannot add evidence')
    m=verify_closure(OUT);require_same_sources(m['frozen_source_sha256'])
    require(m.get('assembly_count')==153 and m.get('board_feature_count')==11 and m.get('smd_count')==147,'Unexpected A1 BOM coverage')
    checksum=Path(str(ARCHIVE)+'.sha256')
    if args.check_only:
        for rel in DOCS:
            require(sha(BASE/rel)==sha(OUT/'documentation'/rel)==sha(OUT/'native'/rel),f'Release documentation changed after sealing: {rel}')
        for rel,digest in m.get('review_evidence_source_sha256',{}).items():
            require(sha(BASE/rel)==digest,f'Review evidence changed after sealing: {rel}')
        require(ARCHIVE.is_file() and checksum.is_file(),'Archive or external checksum missing')
        verify_zip(ARCHIVE,OUT)
        require(checksum.read_text()==f'{sha(ARCHIVE)}  {ARCHIVE.name}\n','External ZIP checksum mismatch')
        print(json.dumps({'verified':str(ARCHIVE),'sha256':sha(ARCHIVE),'board_sha256':m['board_sha256'],'release_status_line':m.get('release_status_line')}))
        return
    document_hashes={rel:sha(BASE/rel) for rel in DOCS}
    evidence={}
    evidence_copies=[]
    for path in args.review_file:
        source=(BASE/path).resolve() if not path.is_absolute() else path.resolve()
        require(source.is_relative_to(BASE),'Review evidence must be inside rev-a')
        rel=source.relative_to(BASE)
        require(rel.parts[0] in ('reports','review') and source.is_file(),'Review evidence must be a file under reports/ or review/')
        require(source.suffix.lower() in {'.md','.json','.pdf','.png','.svg','.txt','.csv'},'Unsupported review-evidence format')
        require(not re.search(r'(^|[-_])A0([._-]|$)',source.name,re.I),'Old A0 review evidence is not allowed')
        dest=OUT/'review/evidence'/rel
        evidence[rel.as_posix()]=sha(source);evidence_copies.append((source,dest))
    copy_documents(OUT)
    for source,dest in evidence_copies:
        dest.parent.mkdir(parents=True,exist_ok=True);shutil.copy2(source,dest)
    m['status']='sealed_snapshot_release_authority_is_RELEASE_md'
    m['release_status_line']=release_status()
    m['release_document_sha256']=document_hashes['RELEASE.md']
    m['review_evidence_source_sha256']={**m.get('review_evidence_source_sha256',{}),**evidence}
    m['archive_policy']='Sorted entries; fixed ZIP timestamp 1980-01-01; UNIX 0644; deflate level 9. No absolute paths, symlinks, ZIPs or old output trees are imported.'
    seal_manifest(OUT,m);verify_closure(OUT)
    require_same_sources(m['frozen_source_sha256'])
    with tempfile.NamedTemporaryFile(prefix='.FarmMesh-Node-A1-',suffix='.zip',dir=BASE,delete=False) as f:
        temp=Path(f.name)
    try:
        with zipfile.ZipFile(temp,'w',compression=zipfile.ZIP_DEFLATED,compresslevel=9) as z:
            for p in all_payload_files(OUT):
                info=zipfile.ZipInfo(PREFIX+p.relative_to(OUT).as_posix(),date_time=(1980,1,1,0,0,0))
                info.create_system=3;info.external_attr=0o100644<<16
                info.compress_type=zipfile.ZIP_DEFLATED
                z.writestr(info,p.read_bytes(),compress_type=zipfile.ZIP_DEFLATED,compresslevel=9)
        verify_zip(temp,OUT);verify_closure(OUT);require_same_sources(m['frozen_source_sha256'])
        require(document_hashes=={rel:sha(BASE/rel) for rel in DOCS},'Release documentation changed while packaging')
        for rel,digest in m['review_evidence_source_sha256'].items():
            require(sha(BASE/rel)==digest,f'Review evidence changed while packaging: {rel}')
        temp.replace(ARCHIVE)
        checksum.write_text(f'{sha(ARCHIVE)}  {ARCHIVE.name}\n')
        print(json.dumps({'sealed_archive':str(ARCHIVE),'archive_sha256':sha(ARCHIVE),
                          'board_sha256':m['board_sha256'],'release_status_line':m['release_status_line'],
                          'approval_changed':False},ensure_ascii=False))
    finally:
        if temp.exists():temp.unlink()


if __name__=='__main__':
    try:main()
    except Exception as error:raise SystemExit(f'PACKAGE ABORTED: {error}')

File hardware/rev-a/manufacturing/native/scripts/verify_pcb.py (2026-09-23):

#!/usr/bin/env python3
"""Read-only independent PCB checks using KiCad's bundled Python.

The board is never saved or zone-filled. The JSON pins its input hashes and
separates automated geometric/net-assignment checks from expert/bench checks.
Run after final routing and zone fill:
  <KiCad Python> scripts/verify_pcb.py
Options: --board FILE --output FILE --share KICAD_SHARED_SUPPORT
This is not a replacement for KiCad DRC/ERC or manufacturing acceptance.
"""
import argparse
import collections
import datetime
import hashlib
import json
import math
import os
from pathlib import Path
import sys
import xml.etree.ElementTree as ET

BASE = Path(__file__).resolve().parents[1]
EXPECTED_COMPONENTS = 164
GLOBAL_NETS = {'GND', '+3V3', 'VBAT_PROTECTED', 'PWR_GOOD', 'BAT_SENSE',
              'RP_USB_DM', 'RP_USB_DP', 'USB_VBUS_SENSE', 'CORE_1V1', 'RP_RUN'}
SIGNALS = ['TX_D0', 'TX_D1', 'TX_D2', 'TX_D3', 'TX_CLK', 'TX_VALID',
           'RX_D0', 'RX_D1', 'RX_D2', 'RX_D3', 'RX_CLK', 'RX_VALID']
EP_PADS = {'U101': '81', 'U1': '29', 'U201': '29', 'U301': '29', 'U401': '29'}


def digest(path):
    return hashlib.sha256(Path(path).read_bytes()).hexdigest()


def clean_net(name):
    """The source export contains slash characters inside sheet/pin names."""
    name = name.replace(' / ', ' {slash} ')
    return name.replace('/ADC', '{slash}ADC') if name.startswith('unconnected-') else name


def result(errors, **details):
    return dict(status='fail' if errors else 'pass', errors=errors, **details)


def close(a, b, tolerance=.000003):
    if isinstance(a, (int, float)) and isinstance(b, (int, float)):
        return abs(a-b) <= tolerance
    if isinstance(a, (list, tuple)) and isinstance(b, (list, tuple)):
        return len(a) == len(b) and all(close(x, y, tolerance) for x, y in zip(a, b))
    return a == b


def adjusted_paste_pad(pad, layer):
    """Detached pad matching paste plotting dimensions; original is untouched.

    pcbnew GetEffectiveShape does NOT apply solder-paste margins. Mirror KiCad
    plot_board_layers.cpp for circle/oval/rectangle/roundrect aperture sizing,
    then query the resulting effective shape. Nonzero-margin custom/chamfered
    geometries fail explicitly until their plotting rules are implemented.
    Source: https://docs.kicad.org/doxygen/plot__board__layers_8cpp_source.html
    """
    import pcbnew as p
    margin=pad.GetSolderPasteMargin(layer)
    if not margin.x and not margin.y:return pad
    size=pad.GetSize(layer)
    plotted=p.VECTOR2I(size.x+2*margin.x,size.y+2*margin.y)
    if plotted.x<=0 or plotted.y<=0:return None
    shape=pad.GetShape(layer)
    supported=(p.PAD_SHAPE_CIRCLE,p.PAD_SHAPE_OVAL,p.PAD_SHAPE_RECT,p.PAD_SHAPE_ROUNDRECT)
    if shape not in supported:raise ValueError('Nonzero paste margin on unsupported pad shape '+str(shape))
    copy=pad.Duplicate()
    old_radius=pad.GetRoundRectCornerRadius(layer) if shape==p.PAD_SHAPE_ROUNDRECT else 0
    old_ratio=pad.GetRoundRectRadiusRatio(layer)
    copy.SetSize(layer,plotted)
    if shape==p.PAD_SHAPE_RECT and margin.x>0:
        copy.SetShape(layer,p.PAD_SHAPE_ROUNDRECT)
        copy.SetRoundRectRadiusRatio(layer,min(.5,margin.x/min(plotted.x,plotted.y)))
    elif shape==p.PAD_SHAPE_ROUNDRECT:
        ratio=min(.5,max(0,old_radius+margin.x)/min(plotted.x,plotted.y)) if margin.x==margin.y else old_ratio
        copy.SetRoundRectRadiusRatio(layer,ratio)
    return copy


def run(board_path, share):
    import pcbnew as p
    import wx
    app = wx.App(False)
    wx.Log.SetLogLevel(0)
    mm = p.FromMM
    to_mm = lambda value: round(p.ToMM(value), 9)
    xy = lambda point: [to_mm(point.x), to_mm(point.y)]
    vector = lambda point: p.VECTOR2I(mm(point[0]), mm(point[1]))
    board_path = board_path.resolve()
    input_paths = {'pcb': board_path, 'manifest': BASE/'design-manifest.json',
                   'xml_netlist': BASE/'reports/netlist.xml'}
    before_hashes = {name: digest(path) for name, path in input_paths.items()}
    manifest = json.loads(input_paths['manifest'].read_text())
    components = {c['reference']: c for c in manifest
                  if not c['reference'].startswith('#') and c.get('footprint')}
    xml = ET.parse(input_paths['xml_netlist']).getroot()
    b = p.LoadBoard(str(board_path))
    fps = list(b.GetFootprints())
    by_ref = {f.GetReference(): f for f in fps}
    report = {
        'schema_version': 1,
        'generated_utc': datetime.datetime.now(datetime.timezone.utc).isoformat(),
        'kicad_version': p.Version(),
        'board': board_path.name,
        'read_only': True,
        'input_sha256': before_hashes,
        'automated_checks': {},
        'expert_review_required': [
            'Complete KiCad DRC/ERC, including shorts, clearances, schematic parity and zero unrouted connections, is a separate release gate.',
            'Ground filled-polygon connectivity and area do not prove adequate return-path neck widths, stitching, EMI performance or every high-speed return path.',
            'USB trunk dimensions are geometric checks for the specified straight coupled span only; connector/switch/ESD/via/resistor escapes are not claimed to maintain the same impedance. Fabricator stackup/impedance acceptance and USB measurements remain required.',
            'Source-series distance is a placement measurement, not timing/SI sign-off. Confirm drive strengths, chosen clocks, crosstalk, skew and ringing on hardware; firmware remains unimplemented.',
            'EP checks prove no finished drill geometry intersects the defined paste apertures or EP bounding envelope. They do not certify solder-mask tenting, stencil/reflow yield, thermal resistance or fabricator process capability.',
            'Inspect buck switching-current loops, crystal/QSPI coupling, RP reset/boot behavior, connector/mechanical access and external dual-band antenna/coax assembly clearances.',
            'RF coexistence, antenna placement in the enclosure, output power, thermal rise and multi-radio performance require measurements; this report is not a fabrication-release authorization.'
        ],
    }
    checks = report['automated_checks']
    # Ref and footprint provenance: independent of the PCB-generation script.
    counts = collections.Counter(f.GetReference() for f in fps)
    errors = []
    if len(fps) != EXPECTED_COMPONENTS or len(components) != EXPECTED_COMPONENTS:
        errors.append({'expected_count': EXPECTED_COMPONENTS, 'pcb': len(fps), 'manifest': len(components)})
    if set(by_ref) != set(components):
        errors.append({'missing_references': sorted(set(components)-set(by_ref)),
                       'unexpected_references': sorted(set(by_ref)-set(components))})
    duplicates = sorted(ref for ref, n in counts.items() if n != 1)
    if duplicates: errors.append({'duplicate_references': duplicates})
    rear = sorted(f.GetReference() for f in fps if f.IsFlipped() or f.GetLayer() != p.F_Cu)
    if rear: errors.append({'non_front_footprints': rear})
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

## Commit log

2026-09-22 docs: record wireless transport research and evidence boundaries
2026-09-23 Add A0 hardware schematics and reviewed design artifacts
    [01-power.kicad_sch, 02-rp2350.kicad_sch, 03-radio-a.kicad_sch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]
2026-09-23 Complete A1 prototype PCB and verified manufacturing package
    [01-power.kicad_sch, 02-rp2350.kicad_sch, 03-radio-a.kicad_sch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]

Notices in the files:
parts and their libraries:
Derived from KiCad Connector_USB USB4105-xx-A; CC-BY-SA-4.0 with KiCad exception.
